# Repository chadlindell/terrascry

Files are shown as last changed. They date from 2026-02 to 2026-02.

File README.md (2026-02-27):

# TERRASCRY

**Multi-sensor geophysical survey platform** (*terra* + *scry* — "seeing what the earth hides")

TERRASCRY unifies three open-source geophysical instruments into a single platform for rapid site characterization: walk a field with Pathfinder, flag anomalies, deploy HIRT for 3D imaging, and validate with GeoSim physics simulations.

## Instruments

### Pathfinder — Handheld Multi-Sensor Gradiometer

Rapid reconnaissance instrument carried by a single operator. Seven sensor modalities in one pass: magnetic gradiometry (8x FG-3+ fluxgates), frequency-domain EMI conductivity, RTK GPS (ZED-F9P), 9-axis IMU (BNO055), IR thermal mapping, LiDAR micro-topography, and georeferenced camera. Covers >3,000 m²/hour at walking speed.

- **Path:** [`pathfinder/`](pathfinder/)
- **Firmware:** ESP32 + PlatformIO
- **BOM:** $1,052-1,262 **(Target)**

### HIRT — Crosshole Subsurface Tomography

Detailed 3D imaging of specific targets flagged by Pathfinder. Dual-channel system: MIT-3D (magnetic induction tomography, 2-50 kHz) for metal detection including aluminum, and ERT-Lite (electrical resistivity) for soil disturbance mapping. Probes inserted into boreholes for true crosshole geometry.

- **Path:** [`hirt/`](hirt/)
- **Documentation:** Quarto technical manual (30 sections)
- **BOM:** <$4,000 **(Target)**

### GeoSim — Physics Simulation Engine

Physics-realistic simulation engine for both instruments. Magnetic dipole forward modeling, FDEM analytical, ERT stubs, noise models, and a real-time MQTT streaming pipeline. Physics accuracy is non-negotiable. Includes Godot 4 interactive visualization frontend and ZeroMQ server for external clients.

- **Path:** [`geosim/`](geosim/)
- **Language:** Python 3.10+
- **Visualization:** PyVista + Godot 4

### Shared Components

Cross-instrument libraries, protocols, and hardware designs shared between Pathfinder and HIRT.

- **Path:** [`shared/`](shared/)
- **Contents:** Sensor pod firmware/hardware, MQTT protocol definitions, CSV schemas, edge deployment configs, field workflow documentation

## Architecture

```
Pathfinder (surface survey, 10 Hz)
     │ MQTT over WiFi
     ▼
NVIDIA Jetson (edge compute)  ◄── HIRT (crosshole, per-sequence)
     │ tilt correction, anomaly detection, data logging
     ▼
Workstation / HPC
     │ SimPEG joint inversion (magnetics + EMI + MIT + ERT)
     ▼
3D multi-physics subsurface model
```

**Shared sensor pod** (ZED-F9P + BNO055 + BMP390 + DS3231) moves between instruments, ensuring both operate in the same coordinate frame — no coordinate transformation errors.

**Joint inversion:** Pathfinder surface data provides boundary conditions for HIRT 3D inversion via cross-gradient regularization (Gallardo & Meju 2003).

## Quick Start

```bash
# Pathfinder firmware
cd pathfinder/firmware && pio run -e esp32dev

# HIRT documentation
cd hirt/docs && quarto render

# GeoSim simulation
cd geosim && pip install -e ".[dev]" && pytest tests/
```

## Licenses

- **Software/Firmware:** [MIT License](LICENSE-SOFTWARE.md)
- **Hardware Designs:** [CERN-OHL-S v2.0](LICENSE-HARDWARE.md)

## Repository Structure

```
terrascry/
├── pathfinder/          # Handheld multi-sensor gradiometer
├── hirt/                # Crosshole subsurface tomography
├── geosim/              # Physics simulation engine
├── shared/              # Cross-instrument shared components
│   ├── firmware/        # Sensor pod, MQTT, SD logger libraries
│   ├── protocols/       # MQTT topics, CSV schemas
│   ├── hardware/        # Sensor pod schematics, BOM, connectors
│   ├── edge/            # Jetson Docker deployment
│   └── workflow/        # Field handoff procedures
└── .github/workflows/   # Path-filtered CI/CD
```

## Links

- **Domain:** [terrascry.com](https://terrascry.com)
- **GitHub:** [chadlindell/terrascry](https://github.com/chadlindell/terrascry)

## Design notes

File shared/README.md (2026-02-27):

# TERRASCRY Shared Components

Cross-instrument libraries, protocols, hardware designs, and deployment configurations shared between Pathfinder and HIRT.

## Directory Structure

```
shared/
├── firmware/
│   ├── sensor_pod/     # I2C drivers for ZED-F9P, BNO055, BMP390, DS3231
│   ├── mqtt/           # MQTT client helpers, message schemas
│   └── sd_logger/      # Common SD card CSV logging
├── protocols/
│   ├── mqtt_topics.md  # Topic hierarchy: terrascry/{instrument}/{channel}
│   ├── csv_schemas.md  # Shared CSV column definitions
│   └── protobuf/       # Binary message definitions (future)
├── hardware/
│   ├── sensor_pod/     # Pod schematics, BOM, PCB files
│   └── connectors/     # M8 8-pin connector specs, pinouts
├── edge/
│   ├── docker-compose.yml  # Jetson edge deployment
│   ├── mosquitto.conf      # MQTT broker config
│   └── containers/         # Per-instrument processing containers
└── workflow/
    └── field_handoff.md    # Pathfinder → HIRT handoff procedure
```

## Sensor Pod

The sensor pod is the key shared hardware between Pathfinder and HIRT. It contains positioning and environmental sensors in an IP67 enclosure:

| Sensor | I2C Address | Function |
|---|---|---|
| ZED-F9P | 0x42 | RTK GPS (cm-accuracy positioning) |
| BNO055 | 0x29 | 9-axis IMU (orientation, tilt correction) |
| BMP390 | 0x77 | Barometric pressure (altitude) |
| DS3231 | 0x68 | Real-time clock (timestamp sync) |

**Connection:** M8 8-pin connector → PCA9615 differential I2C → Cat5 STP cable (1-2m) → instrument I2C Bus 1.

Both instruments use the same GPS receiver, eliminating coordinate transformation errors and enabling seamless data fusion in joint inversion.

## PlatformIO Integration

Both Pathfinder and HIRT firmware projects reference shared libraries:

```ini
# In pathfinder/firmware/platformio.ini or hirt/firmware/platformio.ini
lib_extra_dirs = ../../shared/firmware
```

## MQTT Topic Hierarchy

All instruments publish under `terrascry/`:

```
terrascry/pathfinder/data/raw          — 10 Hz raw sensor data
terrascry/pathfinder/data/corrected    — Tilt-corrected readings
terrascry/pathfinder/anomaly/detected  — Anomaly alerts
terrascry/hirt/data/mit/raw            — MIT measurements
terrascry/hirt/data/ert/raw            — ERT measurements
terrascry/hirt/model/update            — Inversion results
terrascry/status/{instrument}          — Health heartbeat (1 Hz)
```

See `protocols/mqtt_topics.md` for full specification.

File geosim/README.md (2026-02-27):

# GeoSim

Physics-realistic geophysical simulation engine for [HIRT](../HIRT/) (subsurface tomography) and [Pathfinder](../Pathfinder/) (magnetic gradiometry) instruments.

## Quick Start

```bash
# Install
python3 -m venv .venv
source .venv/bin/activate
pip install -e ".[dev]"

# Run tests
pytest tests/

# Run ZeroMQ server
geosim-server --scenario scenarios/single-ferrous-target.json
```

## What It Does

GeoSim simulates the complete data acquisition pipeline:

1. **Define a scenario** (JSON): terrain, buried objects, soil properties
2. **Run the physics engine**: magnetic dipole fields, EM induction, resistivity
3. **Simulate an instrument**: walk path, sensor geometry, noise
4. **Export sensor data**: CSV files matching real firmware formats

The exported CSV files can be loaded directly by existing tools like Pathfinder's `visualize_data.py`.

## Project Structure

```
geosim/              # Python physics engine
├── magnetics/       # Dipole models, gradiometer simulation
├── em/              # EM induction forward modeling (Phase 2)
├── resistivity/     # ERT forward modeling (Phase 2)
├── sensors/         # Instrument models (Pathfinder, HIRT)
├── scenarios/       # Scenario loader
├── noise/           # Realistic noise models
└── server.py        # ZeroMQ server for external clients

scenarios/           # JSON scenario files
notebooks/           # Jupyter notebooks (education + validation)
tests/               # Physics validation tests
godot/               # Godot 4 interactive frontend (Phase 3)
```

## Dependencies

**Core (Phase 1):** numpy, scipy, pyzmq

**Visualization:** pyvista, jupyter, matplotlib

**HIRT Physics (Phase 2):** SimPEG, pyGIMLi

## License

MIT

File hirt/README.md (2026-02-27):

# HIRT - Hybrid Inductive-Resistivity Tomography

A dual-channel subsurface imaging system combining electromagnetic induction (MIT-3D) and electrical resistivity (ERT-Lite) for true 3D tomographic imaging in archaeological and forensic investigations.

## What is HIRT?

HIRT uses insertable probes in crosshole geometry to image the subsurface with two complementary methods:

- **MIT-3D** (Magneto-Inductive Tomography): Detects metallic objects including aluminum at depths to 3m
- **ERT-Lite** (Electrical Resistivity): Maps soil disturbance patterns indicating burial or excavation

## Key Features

| Feature | Specification |
|---|---|
| Depth | 2-6 m investigation depth |
| Resolution | 0.5-1.5 m lateral resolution |
| Cost | $1,800-3,900 complete system |
| Probes | 16-24 modular 16mm OD probes |
| Output | 3D conductivity and resistivity models |

## Primary Applications

- Filled bomb crater investigation (UXO, human remains)
- Woodland burial detection (clandestine graves)
- Swamp/marsh crash site recovery

## Getting Started

### Read the Technical Manual
```bash
cd docs && quarto preview
```
The Technical Manual is the single source of truth for all technical documentation.

### Quick Links

| Resource | Location |
|---|---|
| Technical Manual | `docs/` |
| Bill of Materials | `hardware/bom/` |
| CAD Files (OpenSCAD) | `hardware/cad/` |
| Circuit Schematics | `hardware/schematics/` |
| Research Documents | `research/` |

## Project Structure

```
HIRT/
├── VISION.md          # Project goals and constraints
├── STATUS.md          # Current state and active work
├── OUTLINE.md         # Documentation section status
├── CLAUDE.md          # Style guide for documentation
│
├── docs/              # Technical Manual (Quarto)
│   ├── index.qmd              # Task map landing page
│   ├── getting-started/       # Onboarding (overview, quick-start, safety)
│   ├── field-guide/           # Operations (deployment, data, troubleshooting)
│   ├── build-guide/           # Construction (BOM, mechanical, electronics)
│   ├── theory/                # Technical depth (physics, inversion, sensors)
│   ├── developer/             # Contributors (firmware, data-formats, roadmap)
│   ├── appendices/            # Reference (glossary, checklists, regulations)
│   └── diagrams/              # Python diagram generators
│
├── research/          # Research by topic
│   ├── deployment/    # Probe insertion methods
│   ├── electronics/   # Modernization research
│   ├── regulatory/    # Legal/compliance
│   └── literature/    # Prior art and comparable projects
│
├── hardware/          # Hardware documentation
│   ├── bom/          # Bills of materials
│   ├── cad/          # OpenSCAD sources and STLs
│   ├── drawings/     # Assembly drawings
│   └── schematics/   # Circuit documentation
│
└── _archive/          # Legacy files (preserved)
```

## Building the Documentation

Requires [Quarto](https://quarto.org/) and Python 3.

```bash
# Install Python dependencies
pip install matplotlib numpy pillow

# Render Technical Manual to HTML and PDF
cd docs && quarto render

# Preview with live reload
cd docs && quarto preview

# Render HTML only
cd docs && quarto render --to html

# Render PDF only
cd docs && quarto render --to pdf
```

## Warnings

**UXO Risk:** WWII sites may contain live ordnance. Do not deploy until cleared by qualified EOD/UXO professionals.

**Legal Requirements:** Obtain all permits and permissions. Follow jurisdictional requirements for archaeological and forensic work.

**Human Remains:** Follow proper forensic/archaeological protocols when remains may be present.

## Project Status

| Component | Status |
|---|---|
| Technical Manual | Complete (30 sections, HTML + PDF) |
| Hardware Design | Complete (schematics, CAD, BOM) |
| Research | Ongoing (see `research/`) |
| Software | Future development |

## License

Open source - license to be determined.

## Contributing

Contributions, improvements, and field testing results are welcome. See `docs/developer/contributing.qmd` for contribution guidelines and `CLAUDE.md` for documentation style guide.

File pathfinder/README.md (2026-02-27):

# Pathfinder

**Handheld multi-sensor fluxgate gradiometer for rapid geophysical reconnaissance**

Pathfinder is an open-source, harness-supported magnetic gradiometer array designed for rapid pre-screening of survey areas before detailed investigation. Named for the WWII pathfinder aircraft that marked targets for following bomber formations, this tool identifies anomalies so that detailed systems like [HIRT](https://github.com/hirt-project/hirt) can be deployed efficiently.

## Purpose

Walking a site with Pathfinder in 5-10 minutes can identify magnetic anomalies that would take hours to find with detailed tomographic methods. This two-stage workflow (rapid screening → targeted investigation) dramatically reduces total survey time.

## Key Features

- **Harness-supported**: Weight carried on shoulders, hands only guide
- **Multi-channel**: 2-4 gradiometer pairs for wide swath coverage
- **Lightweight**: Target <1.5 kg total system weight
- **GPS-tagged**: Automatic position logging for anomaly mapping
- **Open hardware**: Full schematics, BOM, and firmware available
- **DIY-friendly**: ~$600-900 total build cost

## Applications

- Archaeological site reconnaissance
- UXO survey pre-screening
- Forensic search area prioritization
- Environmental assessment
- Geological mapping

## Status

**Early development** - Design phase, capturing requirements and prototyping.

## Related Projects

- [HIRT](https://github.com/hirt-project/hirt) - Hybrid Inductive-Resistivity Tomography (detailed follow-up imaging)
- [OhmPi](https://ohmpi.org/) - Open-source resistivity meter
- [FG Sensors](https://www.fgsensors.com/) - DIY fluxgate gradiometer kits

## Historical Note

The name "Pathfinder" honors the 15th Air Force crews who flew missions over Blechhammer (now Blachownia, Poland) during WWII. Pathfinder aircraft marked targets for the bomber formations that followed. This tool serves a similar purpose: marking targets for the detailed investigation systems that follow.

## License

Hardware: [CERN-OHL-S v2.0](https://ohwr.org/cern_ohl_s_v2.txt) | Firmware/Software: [MIT](LICENSE)

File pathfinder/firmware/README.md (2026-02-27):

# Pathfinder Gradiometer Firmware

Arduino firmware for the Pathfinder 4-pair fluxgate gradiometer system.

## Overview

This firmware runs on an Arduino Nano and manages:
- 8 fluxgate sensors (4 pairs) via 2x ADS1115 ADCs
- GPS positioning via NEO-6M module
- SD card data logging
- Pace beeper for walking cadence
- Status LED for system health

## Hardware Requirements

### Electronics
- **Microcontroller**: Arduino Nano (ATmega328P)
- **ADCs**: 2x ADS1115 16-bit I2C modules
- **GPS**: NEO-6M or compatible UART GPS module
- **Storage**: SD card module (SPI interface)
- **Audio**: Piezo buzzer or small speaker
- **Power**: 7.4V LiPo battery with 5V regulator for Arduino

### Sensors
- 8x Fluxgate sensors (e.g., FG Sensors DIY kit)
- Configured as 4 gradiometer pairs (top/bottom)

## Pin Connections

### Arduino Nano Pin Assignments

| Pin | Function | Connection |
|-----|---|---|
| **I2C Bus** |
| A4 | SDA | ADS1115 modules (both) |
| A5 | SCL | ADS1115 modules (both) |
| **SPI Bus (SD Card)** |
| 10 | CS | SD card module CS |
| 11 | MOSI | SD card module DI |
| 12 | MISO | SD card module DO |
| 13 | SCK | SD card module CLK |
| **GPS (Software Serial)** |
| 4 | RX | GPS TX pin |
| 3 | TX | GPS RX pin (not used) |
| **User Interface** |
| 9 | Beeper | Piezo buzzer (+) |
| 2 | Status LED | LED anode (+ resistor) |
| GND | Ground | Common ground for all modules |
| 5V | Power | Power for GPS, SD card, ADCs |

### ADS1115 ADC Connections

**Module 1 (Address 0x48)**: Gradiometer Pairs 1 and 2

| Channel | Sensor Connection |
|---|---|
| A0 | Pair 1 Top sensor output |
| A1 | Pair 1 Bottom sensor output |
| A2 | Pair 2 Top sensor output |
| A3 | Pair 2 Bottom sensor output |

**Module 2 (Address 0x49)**: Gradiometer Pairs 3 and 4

| Channel | Sensor Connection |
|---|---|
| A0 | Pair 3 Top sensor output |
| A1 | Pair 3 Bottom sensor output |
| A2 | Pair 4 Top sensor output |
| A3 | Pair 4 Bottom sensor output |

**I2C Address Configuration:**
- Module 1: Connect ADDR pin to GND (address 0x48)
- Module 2: Connect ADDR pin to VDD (address 0x49)

## Building and Uploading

### Prerequisites

1. **Install PlatformIO**
   - [Visual Studio Code](https://code.visualstudio.com/) with PlatformIO extension, OR
   - [PlatformIO Core CLI](https://docs.platformio.org/en/latest/core/installation.html)

2. **Required Libraries** (auto-installed by PlatformIO):
   - `Adafruit ADS1X15` - ADS1115 ADC driver
   - `TinyGPSPlus` - GPS NMEA parsing
   - `SdFat` - Fast SD card library

### Build and Upload

#### Using VS Code + PlatformIO Extension

1. Open the `firmware/` folder in VS Code
2. PlatformIO will detect the project automatically
3. Click the "Upload" button (→) in the bottom toolbar
4. Monitor serial output with the "Serial Monitor" button

#### Using PlatformIO CLI

```bash
# Navigate to firmware directory
cd /development/projects/active/Pathfinder/firmware/

# Build firmware
pio run

# Upload to Arduino Nano
pio run --target upload

# Open serial monitor
pio device monitor
```

### First-Time Upload

If upload fails with "programmer not responding":
1. Check USB connection
2. Verify correct port in `platformio.ini` (update `upload_port`)
3. Try holding RESET button while uploading
4. Some clones need `upload_speed = 57600` instead of 115200

## Configuration

All user-configurable parameters are in `include/config.h`:

### Key Settings

```cpp
// Sample rate (Hz)
#define SAMPLE_RATE_HZ  10      // Change to 20 for faster acquisition

// Pace beeper interval (ms)
#define BEEP_INTERVAL_MS 1000   // 1 beep per second = 1 m/s pace

// GPS baud rate
#define GPS_BAUD 9600           // NEO-6M default

// ADC gain setting
#define ADC_GAIN GAIN_ONE       // +/- 4.096V range

// Enable debug output
#define SERIAL_DEBUG 1          // Set to 0 to disable for battery savings
```

Edit these values and re-upload to customize behavior.

## Operation

### Startup Sequence

1. Power on system
2. **Status LED blinks rapidly** during initialization
3. Two quick beeps indicate startup complete
4. **Status LED pattern** indicates system state:
   - **Fast blink (100ms)**: Error (SD card failure)
   - **Medium blink (500ms)**: No GPS fix
   - **Slow blink (2s)**: Logging normally

### In the Field

1. Wait for **slow blink** (GPS locked)
2. Walk at steady pace (1 beep per second ≈ 1 m/s)
3. Maintain level orientation
4. Data logs automatically to SD card as `PATHXXXX.CSV`

### Data Retrieval

1. Power off system
2. Remove SD card
3. Copy CSV files to computer
4. Files increment automatically: `PATH0001.CSV`, `PATH0002.CSV`, etc.

## Data Format

### CSV Structure

```csv
timestamp,lat,lon,g1_top,g1_bot,g1_grad,g2_top,g2_bot,g2_grad,g3_top,g3_bot,g3_grad,g4_top,g4_bot,g4_grad
1234567,51.2345678,18.3456789,12450,12678,228,12401,12623,222,12389,12598,209,12434,12656,222
```

### Column Definitions

- **timestamp**: Milliseconds since Arduino boot
- **lat/lon**: GPS coordinates (decimal degrees, WGS84)
- **gN_top**: Top sensor raw ADC value (16-bit signed)
- **gN_bot**: Bottom sensor raw ADC value
- **gN_grad**: Gradient (bottom - top)

### Converting to Physical Units

Raw ADC values → Voltage:
```
voltage = (ADC_value / 32768) × 4.096V
```

Voltage → Magnetic field depends on your fluxgate sensor specifications.
Consult sensor datasheet for mV/µT conversion factor.

## Troubleshooting

### No SD Card Detected

- Check wiring to SD module (SPI pins)
- Verify SD card is formatted as FAT32
- Ensure CS pin is correct (`SD_CS_PIN = 10`)
- Try different SD card (some old cards not compatible)

### GPS Not Locking

- Ensure clear view of sky (no metal/trees blocking)
- Wait 30-60 seconds for cold start
- Check GPS RX pin connection (Arduino D4 → GPS TX)
- Verify GPS baud rate (default 9600)

### ADS1115 Not Found

- Check I2C wiring (SDA=A4, SCL=A5)
- Verify I2C addresses:
  - Module 1: ADDR pin → GND (0x48)
  - Module 2: ADDR pin → VDD (0x49)
- Run I2C scanner to detect devices
- Ensure 5V power to ADS1115

### Erratic Readings

- Check sensor power supply stability
- Ensure proper grounding (all grounds connected)
- Move sensors away from electronics noise
- Shield cables with grounded braid
- Lower ADC data rate for less noise (`ADC_DATA_RATE = 64`)

### Serial Monitor Shows Garbage

- Set baud rate to 115200 in monitor
- Check `SERIAL_BAUD` in `config.h` matches monitor

## Advanced Modifications

### Adding Calibration

Insert calibration coefficients in `readGradiometers()`:

```cpp
// After reading raw values
reading.g1_top = (reading.g1_top - offset1_top) * scale1_top;
reading.g1_bot = (reading.g1_bot - offset1_bot) * scale1_bot;
```

### Changing Sample Rate Dynamically

Add button to cycle through rates:

```cpp
const uint8_t rates[] = {10, 20, 50};
uint8_t currentRate = 0;

// In button interrupt:
currentRate = (currentRate + 1) % 3;
SAMPLE_RATE_HZ = rates[currentRate];
```

### Adding Real-Time Clock

Replace `millis()` timestamps with DS3231 RTC for absolute time:

```cpp
#include <RTClib.h>
RTC_DS3231 rtc;

// In setup():
rtc.begin();

// In logReading():
DateTime now = rtc.now();
logFile.print(now.timestamp());
```

## Performance Notes

### Memory Usage

- **Flash**: ~18 KB / 32 KB (56% used)
- **RAM**: ~1.2 KB / 2 KB (60% used)

Remaining RAM is tight. Avoid large arrays or String objects.

### Sample Rate Limits

- **10 Hz**: Rock solid, recommended
- **20 Hz**: Stable for most sensors
- **50 Hz**: Maximum practical (depends on ADC data rate)

Higher rates reduce per-sample noise averaging. Balance speed vs. quality.

### Battery Life Estimate

At 10 Hz sample rate (Modeled, MCU + peripherals only — excludes fluxgate sensors):
- Arduino Nano: ~60 mA
- ADS1115 (2x): ~2 mA
- GPS module: ~40 mA
- SD writes: ~20 mA average
- **MCU + peripherals**: ~120 mA
- **Full system with 8 fluxgates**: ~305 mA typical (see `hardware/schematics/main-board.md`)

With 2000 mAh LiPo @ 7.4V (80% regulator efficiency):
- MCU + peripherals only: ~13 hours
- Full system: ~5.2 hours

## License

MIT License. See [LICENSE](../LICENSE) in the project root.

## Contributing

Improvements welcome! Please document changes and test thoroughly before submitting.

## References

- [ADS1115 Datasheet](https://www.ti.com/lit/ds/symlink/ads1115.pdf)
- [NEO-6M GPS Manual](https://www.u-blox.com/sites/default/files/products/documents/NEO-6_DataSheet_(GPS.G6-HW-09005).pdf)
- [TinyGPS++ Documentation](http://arduiniana.org/libraries/tinygpsplus/)
- [SdFat Library](https://github.com/greiman/SdFat)

## Support

For hardware questions, see `/hardware/` directory.
For design rationale, see `/docs/design-concept.md`.

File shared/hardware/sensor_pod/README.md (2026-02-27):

# Shared Sensor Pod — Hardware Specification

The sensor pod is the primary shared hardware between Pathfinder and HIRT. It provides positioning, orientation, and environmental sensing in a ruggedized enclosure.

## Sensors

| Component | I2C Address | Function | Current Draw |
|---|---|---|---|
| u-blox ZED-F9P | 0x42 | RTK GPS (cm-accuracy) | ~70 mA (tracking) |
| Bosch BNO055 | 0x29 | 9-axis IMU (IMUPLUS mode) | ~12 mA |
| Bosch BMP390 | 0x77 | Barometric pressure + temperature | ~3 mA |
| Maxim DS3231 | 0x68 | Temperature-compensated RTC | ~0.2 mA |
| **Total** | | | **~85 mA typical** |

Peak draw (GPS acquisition): ~150-200 mA.

## Enclosure

- **Type:** IP67 ABS enclosure, approximately 60 x 60 x 25 mm
- **Connector:** M8 8-pin panel-mount (NOT 4-pin — PCA9615 requires 6 conductors minimum)
- **Antenna:** SMA panel-mount for external GPS antenna (patch or helix)
- **Vent:** IP67 membrane vent for BMP390 barometric accuracy

## M8 8-Pin Connector Pinout

| Pin | Signal | Color (Cat5) | Description |
|-----|---|---|---|
| 1 | VCC | Orange/White | 3.3V supply |
| 2 | GND | Orange | Ground |
| 3 | SDA_D+ | Green/White | PCA9615 differential SDA+ |
| 4 | SDA_D- | Green | PCA9615 differential SDA- |
| 5 | SCL_D+ | Blue/White | PCA9615 differential SCL+ |
| 6 | SCL_D- | Blue | PCA9615 differential SCL- |
| 7 | VBUS | Brown/White | 5V input (before pod's 3.3V LDO) |
| 8 | SHIELD | Brown | Cable shield / drain wire |

## PCA9615 Differential I2C

The PCA9615 converts standard I2C to differential signaling for reliable communication over 1-2m Cat5 STP cable. This eliminates I2C bus capacitance and noise issues at cable lengths beyond ~30 cm.

**Critical:** Both the pod side and instrument side need a PCA9615. The instrument-side PCA9615 connects to ESP32 I2C Bus 1 (GPIO 16 SDA, GPIO 17 SCL).

## ESD Protection

- TVS diodes (PESD5V0S2BT) on all I2C lines at the M8 connector
- ESD protection is critical for hot-plug scenarios (pod moved between instruments during field use)

## Power Architecture

- Input: 5V via VBUS (pin 7) from instrument
- LDO: AP2112K-3.3 (NOT LM78L05 — no 5V→3.3V dropout issue at this voltage)
- All sensors operate at 3.3V
- Cable voltage drop: ~0.05V at 200 mA over 2m Cat5 (negligible at 5V input)

## PCB Design Notes

- 4-layer PCB recommended (signal, ground, power, signal)
- ZED-F9P placed closest to SMA connector, ground plane unbroken beneath RF traces
- BNO055 placed away from GPS and PCA9615 (magnetic interference)
- Keep PCA9615 within 5 cm of M8 connector
- IP67 vent membrane directly above BMP390

See `pathfinder/research/multi-sensor-architecture/sensor-pod-pcb-requirements.md` for full consensus-validated PCB design requirements.

## BOM

| Component | Part Number | Qty | Est. Cost |
|---|---|-----|---|
| ZED-F9P RTK GPS module | u-blox ZED-F9P | 1 | $180 |
| BNO055 9-axis IMU | Bosch BNO055 | 1 | $10 |
| BMP390 barometer | Bosch BMP390 | 1 | $5 |
| DS3231 RTC | Maxim DS3231SN | 1 | $8 |
| PCA9615 diff I2C (pod side) | NXP PCA9615 | 1 | $3 |
| PCA9615 diff I2C (instrument side) | NXP PCA9615 | 1 | $3 |
| AP2112K-3.3 LDO | Diodes Inc | 1 | $0.50 |
| PESD5V0S2BT TVS diodes | Nexperia | 2 | $1 |
| TPD4E05U06 ESD protection | TI | 1 | $0.50 |
| M8 8-pin connector (panel) | Various | 1 | $8 |
| M8 8-pin connector (cable) | Various | 1 | $6 |
| Cat5 STP cable (2m) | Various | 1 | $3 |
| IP67 ABS enclosure | Hammond 1554B | 1 | $12 |
| IP67 vent membrane | Amphenol | 1 | $3 |
| SMA panel-mount connector | Various | 1 | $3 |
| GPS antenna (patch or helix) | Various | 1 | $30 |
| 4-layer PCB | JLCPCB | 1 | $15 |
| Passive components | Various | — | $5 |
| **Total** | | | **~$296** |

## Design References

- Sensor pod design: `pathfinder/research/multi-sensor-architecture/sensor-pod-design.md`
- PCB requirements: `pathfinder/research/multi-sensor-architecture/sensor-pod-pcb-requirements.md`
- Firmware consensus: `pathfinder/research/multi-sensor-architecture/sensor-pod-firmware-consensus.md`
- HIRT integration: `hirt/research/electronics/sensor-pod-integration.md`
- HIRT consensus: `hirt/research/electronics/sensor-pod-consensus.md`

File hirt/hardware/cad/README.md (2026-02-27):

# CAD Files for HIRT Micro-Probe System

## Overview

This directory contains CAD files for manufacturing HIRT **micro-probe** components (12mm OD design). Files are provided in multiple formats for different manufacturing methods:

**Design Philosophy:** Minimal intrusion, archaeology-friendly. Rod diameter: 10-16mm (target: 12mm).

- **OpenSCAD** (`.scad`) - Parametric CAD source files
- **STL** (`.stl`) - 3D printing format
- **STEP** (`.step`) - CNC machining format (to be exported from OpenSCAD)
- **Docs** (`docs/`) - Manufacturing guides, including `base-hub-breakout.md` for the centralized harness/backplane

## Directory Structure

```
cad/
├── openscad/          # OpenSCAD source files (.scad)
├── stl/              # 3D printable STL files
├── step/             # CNC-ready STEP files
└── docs/             # Manufacturing documentation
```

## Parts Available

### 1. Probe Tip (Nose Cone) - BOTTOM
- **File:** `openscad/micro_probe_tip.scad`
- **Output:** `stl/micro_probe_tip.stl`
- **Manufacturing:** 3D Print (PETG) or CNC (Delrin)
- **Dimensions:** 25mm long, 12mm base, 4mm point
- **Threading:** Internal M12×1.5 (screws onto rod bottom)
- **Features:** Tapered for easy insertion, points DOWN
- **Assembly:** Screws onto rod bottom (external M12×1.5 thread)

### 2. Micro-Rod Coupler - MIDDLE
- **File:** `openscad/micro_rod_coupler.scad`
- **Output:** `stl/micro_rod_coupler.stl`
- **Manufacturing:** CNC (Nylon/Delrin) preferred, or 3D Print + tap
- **Dimensions:** 45mm long × 18mm OD
- **Threading:** Internal M12×1.5 both ends (screws onto rod sections)
- **Features:** O-ring grooves, smooth center for grip
- **Assembly:** Joins rod sections (modular design)

### 3. ERT Ring Collar - MIDDLE
- **File:** `openscad/micro_ert_ring_collar.scad`
- **Output:** `stl/micro_ert_ring_collar.stl`
- **Manufacturing:** 3D Print (PETG)
- **Dimensions:** 5mm wide × 12mm ID
- **Threading:** None (slides onto rod, bonds with epoxy)
- **Features:** Narrow band for 3-5mm ERT rings, wire channel
- **Assembly:** Slides onto rod at 0.5m, 1.5m, 2.5m positions

### 4. Surface Junction Box - TOP
- **File:** `openscad/micro_probe_head.scad`
- **Output:** `stl/micro_probe_head.stl`
- **Manufacturing:** 3D Print (PETG) preferred
- **Dimensions:** Ø25mm × 35mm
- **Threading:** Internal M12×1.5 (screws onto rod top)
- **Features:** Terminal block mount, cable strain relief, weatherproof
- **Assembly:** Screws onto rod TOP (surface, not inserted)
- **Note:** Electronics stay at surface, probe is passive

### 5. Complete Assembly View
- **File:** `openscad/micro_probe_assembly.scad`
- **Purpose:** Visualization of complete modular assembly
- **Note:** Export individual parts separately for manufacturing

### Legacy Parts (25mm Design - Deprecated)
- `probe_head.scad` - Old 30mm design (not recommended)
- `rod_coupler.scad` - Old 30mm design (not recommended)
- `ert_ring_collar.scad` - Old design (not recommended)

## Manufacturing Methods

### 3D Printing

**Recommended Settings:**
- **Layer Height:** 0.2 mm for structural parts (0.15 mm for threaded features)
- **Infill:** 100% solid infill (critical for skinny load-bearing parts)
- **Wall Count:** 3-4 perimeters
- **Support:** Minimal (parts designed to print without supports)
- **Material:** PETG (preferred) or ABS
- **Bed Adhesion:** 6-10 mm brim or small sacrificial raft + glue stick/hairspray on PEI
- **Stabilization:** Enable Z-hop and slow first layers (15-20 mm/s) so tall slender sections stay anchored

**Post-Processing:**
- Remove support material
- Clean threads with tap if needed
- Test fit before final assembly
- Flood threads/tips with thin epoxy if additional abrasion resistance is needed

See `docs/manufacturing-notes.md` for part-by-part print/tap/epoxy instructions tailored to home printers.

### CNC Machining

**For couplers and precision parts:**
- Export STEP files from OpenSCAD
- Use CAM software to generate toolpaths
- Material: Nylon, Delrin, or aluminum
- Threads: Cut with appropriate tap/die

## Using OpenSCAD Files

1. **Install OpenSCAD:**
   - Download from: https://openscad.org/
   - Available for Windows, Mac, Linux

2. **Open File:**
   - Launch OpenSCAD
   - Open `.scad` file from `openscad/` directory

3. **Customize (if needed):**
   - Adjust parameters at top of file
   - Modify dimensions as needed

4. **Render:**
   - Press F5 (Preview) or F6 (Render)
   - Wait for rendering to complete

5. **Export:**
   - **STL:** File → Export → Export as STL
   - **STEP:** Requires additional plugin or FreeCAD conversion

## Converting to STEP (for CNC)

### Method 1: Using FreeCAD
1. Open FreeCAD
2. Import STL file
3. Convert mesh to solid
4. Export as STEP

### Method 2: Using OpenSCAD with STEP export plugin
1. Install STEP export plugin
2. Use `export_stl()` or export menu

## Dummy Prototype Parts

For testing and prototyping, simplified versions are available:
- `probe_head_dummy.scad` - Simplified probe head for fit testing
- `coupler_dummy.scad` - Basic coupler for thread testing

## Thread Specifications

**All Threads: M12×1.5 Metric**
- **Type:** Standard metric thread (M12×1.5)
- **Pitch:** 1.5mm
- **Engagement:** 12-15mm
- **Rod:** External threads on both ends (cut with M12×1.5 die)
- **Tip:** Internal thread (tapped M12×1.5)
- **Junction Box:** Internal thread (tapped M12×1.5)
- **Coupler:** Internal threads both ends (tapped M12×1.5)

**Note:** Threads must be precise for reliable connection. Use appropriate taps/dies. Test fit before production.

## Quality Control

Before using manufactured parts:
- [ ] Verify dimensions with calipers
- [ ] Test thread fit with actual rod
- [ ] Check O-ring groove dimensions
- [ ] Verify wall thickness
- [ ] Test waterproofing (for probe head)

## Modular Assembly

**Assembly Order (bottom to top):**
1. **Tip** - Screws onto rod bottom (pointing down for insertion)
2. **Rod Section 1** - 1.5m section with external threads
3. **ERT Collar + Ring** - Slides onto rod at 0.5m position
4. **Coupler** - Screws onto rod sections (if multi-section)
5. **Rod Section 2** - Additional 1.5m section
6. **ERT Collar + Ring** - At 1.5m from tip
7. **Junction Box** - Screws onto rod top (at surface)

**Key Points:**
- All parts screw together (modular design)
- Tip points DOWN for insertion
- Junction box at TOP (surface, not inserted)
- Rod sections join with couplers
- ERT collars slide on and bond with epoxy

## Manufacturing Methods

See [Manufacturing Notes](docs/manufacturing-notes.md) for detailed recommendations:
- **Tip:** 3D Print (PETG) or CNC (Delrin)
- **Coupler:** CNC (Nylon) preferred for precision threads
- **Junction Box:** 3D Print (PETG) for weatherproof enclosure
- **ERT Collar:** 3D Print (PETG) - simple part

## Notes

- All dimensions are in millimeters
- Threads are simplified in models - use taps/dies for actual threads
- Rod requires external M12×1.5 threads on both ends
- All threaded connections should use thread sealant
- Test print small parts first before full production
- See manufacturing notes for method recommendations

## Support

For issues or questions:
- Check OpenSCAD file comments for parameter descriptions
- Review manufacturing documentation in `docs/` directory
- Test with dummy parts first

---

*Last Updated: 2024-12-19*

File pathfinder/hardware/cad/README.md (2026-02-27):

# Pathfinder CAD Files

3D models and rendering tools for the Pathfinder gradiometer frame and harness system.

## Directory Structure

```
cad/
├── openscad/
│   └── pathfinder_frame.scad    # Parametric 3D model
├── scripts/
│   └── render_views.sh          # Batch PNG rendering
├── stl/                         # Generated STL files
└── frame-design.md              # Design specifications
```

## OpenSCAD Model

The parametric model in `openscad/pathfinder_frame.scad` includes:

- Carbon fiber crossbar (2000mm x 25mm)
- 4 PVC drop tubes (500mm x 21.3mm)
- 8 FG-3+ fluxgate sensors (4 pairs)
- Center mount D-ring for harness attachment

### Render Modes

Set the `part` variable to select a view:

| Mode | Description |
|---|---|
| `assembled` | Complete trapeze system |
| `exploded` | Components separated with gaps |
| `cross_section` | Half-section showing tube interiors |
| `deployment` | With operator silhouette for scale |
| `single_tube` | Single sensor pair detail |

### Parametric Variables

Key dimensions can be adjusted:

```scad
CROSSBAR_LENGTH = 2000;        // mm
CROSSBAR_OD = 25;              // mm
DROP_TUBE_LENGTH = 500;        // mm
BOTTOM_SENSOR_HEIGHT = 175;    // mm from ground
SENSOR_POSITIONS = [250, 750, 1250, 1750];  // mm from left
```

## Rendering

### Prerequisites

- OpenSCAD 2021.01+
- `xvfb-run` for headless rendering (Linux)

### Generate PNG Images

```bash
# Render all views
./scripts/render_views.sh all

# Render single view
./scripts/render_views.sh assembled
./scripts/render_views.sh exploded

# Export STL file
./scripts/render_views.sh --stl
```

Output files are saved to `docs/assets/images/assembly/`.

### Manual Rendering

```bash
# Open in OpenSCAD GUI
openscad openscad/pathfinder_frame.scad

# Command-line rendering
openscad -D 'part="assembled"' \
  --imgsize=1200,900 \
  --camera=0,0,0,55,25,25,4000 \
  -o pathfinder_assembled.png \
  openscad/pathfinder_frame.scad
```

## Python Diagrams

Annotated assembly diagrams using matplotlib are in `docs/diagrams/`:

```python
from docs.diagrams.assembly import create_exploded_view

fig = create_exploded_view()
fig.savefig('exploded.png', dpi=150)
```

Or render all diagrams:

```bash
python -m docs.diagrams.assembly
```

## Design Specifications

See `frame-design.md` for complete specifications including:

- Component selection (crossbar, tubes, harness)
- Parts list with costs
- Assembly instructions
- Safety notes

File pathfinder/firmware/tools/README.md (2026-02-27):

# Pathfinder Data Tools

Python utilities for processing and visualizing Pathfinder gradiometer data.

## Installation

Install required Python packages:

```bash
pip install pandas matplotlib
```

Or use the provided requirements file:

```bash
pip install -r requirements.txt
```

## Tools

### visualize_data.py

Quick field visualization of survey data. Useful for checking data quality immediately after collection.

**Basic usage:**

```bash
# View all pairs as time series
python visualize_data.py PATH0001.CSV

# View specific pair
python visualize_data.py PATH0001.CSV --pair 1

# Generate spatial map (requires GPS data)
python visualize_data.py PATH0001.CSV --map

# Show gradient distributions
python visualize_data.py PATH0001.CSV --hist

# Print statistics only (no plots)
python visualize_data.py PATH0001.CSV --stats-only
```

**Example output:**

```
Loaded 1234 samples from PATH0001.CSV

============================================================
PATHFINDER DATA STATISTICS
============================================================

GPS Lock: 1150/1234 samples (93.2%)
  Lat range: 51.234567 to 51.235678
  Lon range: 18.345678 to 18.346789

Gradient Statistics (ADC counts):
Pair     Mean       Std Dev    Min        Max
------------------------------------------------
1        225.3      45.2       -120       850
2        218.7      42.8       -105       780
3        210.5      40.1       -98        720
4        223.1      44.5       -115       810

Survey Duration: 15.2 minutes (912 seconds)
Sample Rate: 10.1 Hz (average)
============================================================
```

## Example Data

The `example_data.csv` file contains synthetic data for testing the visualization tools. Use it to verify your Python environment is set up correctly:

```bash
python visualize_data.py example_data.csv
```

## Custom Processing

For more advanced processing (filtering, calibration, export to GIS formats), see the templates in the `processing/` directory (coming soon).

### Basic Python Processing Example

```python
import pandas as pd

# Load data
df = pd.read_csv('PATH0001.CSV')

# Filter to GPS-locked samples only
df_gps = df[(df['lat'] != 0) & (df['lon'] != 0)]

# Apply calibration offset (example)
df_gps['g1_grad_cal'] = df_gps['g1_grad'] - df_gps['g1_grad'].mean()

# Export to GeoJSON for QGIS
import json
features = []
for _, row in df_gps.iterrows():
    features.append({
        'type': 'Feature',
        'geometry': {
            'type': 'Point',
            'coordinates': [row['lon'], row['lat']]
        },
        'properties': {
            'gradient': row['g1_grad_cal']
        }
    })

with open('survey.geojson', 'w') as f:
    json.dump({'type': 'FeatureCollection', 'features': features}, f)
```

## Contributing

Improvements and additional tools welcome! Submit pull requests or open issues on the project repository.

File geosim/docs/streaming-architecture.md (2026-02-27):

# GeoSim Real-Time Streaming Architecture

## Overview

This document describes the real-time data streaming and continuous analysis
pipeline for HIRT and Pathfinder geophysical instruments. The architecture
enables live sensor data to flow from instruments through edge processing to
cloud-based inversion, with sub-second anomaly detection at the edge.

---

## System Architecture

```
Instrument Hardware          Edge Compute              Cloud / Base Station
+------------------+      +-------------------+      +--------------------+
| Pathfinder       |      | NVIDIA Jetson     |      | Workstation / HPC  |
|  8x FG-3+       |      | AGX Orin 64GB     |      | Full inversion     |
|  EMI coil (FDEM) | WiFi |                   | Star |  SimPEG / pyGIMLi  |
|  ZED-F9P RTK GPS | MQTT | - TDM data ingest | link |  Joint inversion   |
|  BNO055 IMU      |----->| - Tilt correction |----->|  3D model update   |
|  MLX90614 IR     |      | - Anomaly detect  |      |  Visualization     |
|  RPLiDAR C1      | USB  | - MQTT broker     |      +--------------------+
|  ESP32-CAM       |----->| - LiDAR→DEM       |
+------------------+      | - Data logging    |      +--------------------+
                           |                   |      | MQTT Cloud Bridge  |
+------------------+      | Docker containers |      | AWS IoT Core or    |
| HIRT             |      | per instrument    |----->| self-hosted         |
|  MIT transmitter |----->|                   |      +--------------------+
|  ERT electrodes  | SPI  | Shared sensor pod |
|  Inclinometers   |      | provides GPS      |
+------------------+      | registration      |
                           +-------------------+
```

### Data Flow

1. **Pathfinder ESP32** produces TDM-synchronized sensor readings at 10 Hz:
   magnetic gradients (4 channels), EMI conductivity (I/Q), RTK GPS, orientation,
   IR temperature. Published via MQTT over WiFi to Jetson.
2. **RPLiDAR C1** streams 360° point clouds at 10 Hz directly to Jetson via USB
   (not through ESP32 — avoids bandwidth bottleneck and EMI).
3. **Edge compute** (Jetson) receives all data, applies tilt correction,
   runs anomaly detection (multi-physics: magnetics + conductivity + thermal),
   publishes corrected data to local MQTT broker.
4. **Local subscribers** (field laptop, tablet) receive corrected data and
   anomaly alerts via MQTT for live visualization.
5. **Cloud bridge** (when Starlink available) forwards data to cloud for
   full-physics inversion and long-term storage.

### TDM Timing and Data Flow

The ESP32 firmware uses a 100 ms Time-Division Multiplexed cycle to prevent
cross-sensor electromagnetic interference:

```
0 ms              50 ms           80 ms    100 ms
├── Phase 1 ──────┤── Phase 2 ────┤─ P3 ───┤
│ FLUXGATE READ   │  EMI TX/RX    │ SETTLE │
│                 │               │        │
│ 8× fluxgate ADC│  AD9833 DDS   │ WiFi TX│
│ BNO055 IMU     │  AD630 I/Q    │ MQTT   │
│ MLX90614 IR    │  Conductivity │ SD card│
│ GPS RX (pass.) │  calculation  │ NTRIP  │
│                 │               │        │
│ EMI TX: OFF    │  WiFi TX: OFF │ EMI:OFF│
│ WiFi TX: OFF   │               │        │
└─────────────────┴───────────────┴────────┘
```

Each MQTT message contains the complete TDM cycle result: gradients, conductivity,
position, orientation, temperature, and timestamp. See
`../Pathfinder/research/multi-sensor-architecture/tdm-firmware-design.md`.

### Updated Sensor Data Rates

| Sensor | Data Rate | Transport |
|---|---|---|
| Fluxgate gradients (4 ch) | 160 B/s | MQTT (ESP32 → Jetson) |
| EMI conductivity (I, Q, σ) | 120 B/s | MQTT |
| RTK GPS position | 240 B/s | MQTT |
| BNO055 orientation | 160 B/s | MQTT |
| MLX90614 IR temperature | 80 B/s | MQTT |
| **MQTT subtotal** | **~1 KB/s** | WiFi |
| RPLiDAR C1 point clouds | ~400 KB/s | USB direct to Jetson |
| ESP32-CAM images | ~50 KB/s | WiFi/SD |
| **Total** | **~451 KB/s** | |
| **Per hour** | **~1.6 GB** | ~180M data points |

See `docs/research/data-rates-analysis.md` for full breakdown.

---

## MQTT Topic Hierarchy

All topics are rooted under `geosim/`.

| Topic Pattern | Description | Rate |
|---|---|---|
| `geosim/pathfinder/data/raw` | Raw gradiometer + EMI + IMU + GPS + IR | 10 Hz |
| `geosim/pathfinder/data/corrected` | After tilt correction | 10 Hz |
| `geosim/pathfinder/data/emi` | EMI conductivity (I, Q, σ_a) | 10 Hz |
| `geosim/pathfinder/data/thermal` | IR temperature (object + ambient) | 10 Hz |
| `geosim/pathfinder/anomaly/detected` | Anomaly alerts (multi-physics) | Event-driven |
| `geosim/hirt/data/mit/raw` | MIT quadrature measurements | Per sequence |
| `geosim/hirt/data/ert/raw` | ERT four-electrode readings | Per sequence |
| `geosim/hirt/model/update` | Latest inversion result | ~1/min |
| `geosim/hirt/probe/orientation` | Inclinometer readings | 1 Hz |
| `geosim/hirt/probe/position` | GPS position of probe insertion points | Event-driven |
| `geosim/status/{instrument}` | System health / heartbeat | 1 Hz |

### Message Format

All messages are JSON-serialized Python dataclasses (see `geosim.streaming.messages`).
Timestamps are ISO 8601 UTC. Numeric values use SI-compatible units:
nanotesla (nT) for gradients, degrees for angles, meters for positions.

### QoS Levels

- **Raw data**: QoS 0 (at most once) -- high rate, loss tolerable
- **Corrected data**: QoS 1 (at least once) -- logged to disk
- **Anomaly alerts**: QoS 2 (exactly once) -- critical notifications
- **Status/health**: QoS 1

---

## Hardware Requirements

### Recommended Edge Platform: NVIDIA Jetson AGX Orin 64GB

| Spec | Value | Justification |
|---|---|---|
| GPU | 2048 CUDA cores, 64 Tensor cores | CuPy acceleration for inversion |
| CPU | 12-core Arm Cortex-A78AE | Concurrent MQTT + processing |
| RAM | 64 GB LPDDR5 | Full inversion mesh in memory |
| Storage | 64 GB eMMC + NVMe SSD (1 TB) | Survey data logging |
| Power | 15-60 W configurable | Battery/solar operation |
| I/O | USB 3.2, SPI, I2C, UART, Ethernet | Direct instrument connection |
| Size | 100 x 87 mm module | Field-deployable enclosure |

### Minimum Viable: Jetson Orin Nano 8GB

Suitable for Pathfinder-only deployment (tilt correction + anomaly detection).
Not sufficient for on-device HIRT inversion.

### Hardware Additions BOM

| Item | Qty | Est. Cost | Purpose |
|---|---|---|---|
| Jetson AGX Orin 64GB Developer Kit | 1 | $1,999 | Edge compute |
| Samsung 980 PRO 1TB NVMe SSD | 1 | $110 | Survey data logging |
| Starlink Mini | 1 | $599 + $50/mo | Cloud connectivity |
| Pelican 1150 case | 1 | $40 | Weatherproof enclosure |
| USB-C hub (industrial) | 1 | $60 | Instrument connections |
| LiPo battery pack 24V 20Ah | 1 | $300 | 8+ hr field operation |
| DC-DC converter (24V to 19V) | 1 | $25 | Jetson power supply |
| BNO055 IMU breakout (spare) | 2 | $30 ea | Pathfinder tilt sensing |
| Panel-mount Ethernet connector | 2 | $15 ea | Weatherproof I/O |
| **Total** | | **~$3,250** | |

---

## Software Stack

### Edge (Jetson)

| Component | Version | Purpose |
|---|---|---|
| JetPack | 6.0+ | Base OS with CUDA |
| Python | 3.10+ | Application runtime |
| Eclipse Mosquitto | 2.x | Local MQTT broker |
| NumPy | 1.24+ | Numeric computation |
| CuPy | 13.x | GPU-accelerated NumPy |
| ONNX Runtime | 1.17+ | Surrogate model inference |
| paho-mqtt | 2.x | MQTT client library |
| Docker | 24.x | Container isolation |

### Cloud / Base Station

| Component | Version | Purpose |
|---|---|---|
| SimPEG | 0.20+ | EM/ERT forward modeling and inversion |
| pyGIMLi | 1.4+ | ERT inversion (alternative) |
| PyVista | 0.42+ | 3D visualization |
| PostgreSQL + TimescaleDB | 16+ | Time-series data storage |
| Grafana | 10+ | Real-time dashboards |

---

## Two-Tier Compute Strategy

### Tier 1: Edge (Always Available)

Runs on the Jetson regardless of connectivity. Sub-second latency.

| Task | Latency Target | Method |
|---|---|---|
| Pathfinder tilt correction | < 1 ms | NumPy vectorized |
| Anomaly detection (running stats) | < 1 ms | Rolling mean/std |
| Anomaly detection (ONNX surrogate) | < 10 ms | ONNX Runtime on GPU |
| Data logging to NVMe | < 1 ms | Append-only Parquet |
| MQTT publish | < 2 ms | Local broker |

### Tier 2: Cloud (When Connected)

Full-physics inversion when Starlink is available.

| Task | Latency Target | Method |
|---|---|---|
| HIRT progressive inversion | 30-120 s | SimPEG on GPU workstation |
| Full survey reprocessing | 5-30 min | Batch on HPC |
| Model archival | async | TimescaleDB + S3 |

### Graceful Degradation

- **Full connectivity**: Edge correction + cloud inversion in real time.
- **Intermittent**: Edge queues data, cloud processes when link available.
- **No connectivity**: Full edge pipeline runs independently. Data syncs later.

---

## Deployment: Docker Containers on Jetson

```yaml
# docker-compose.yml (simplified)
version: "3.8"

services:
  mosquitto:
    image: eclipse-mosquitto:2
    ports:
      - "1883:1883"
    volumes:
      - ./mosquitto.conf:/mosquitto/config/mosquitto.conf
      - mosquitto-data:/mosquitto/data

  pathfinder-pipeline:
    build: ./containers/pathfinder
    depends_on: [mosquitto]
    devices:
      - /dev/ttyUSB0:/dev/ttyUSB0   # GPS
      - /dev/i2c-1:/dev/i2c-1       # IMU
    environment:
      MQTT_BROKER: mosquitto
      MQTT_PORT: 1883
    volumes:
      - survey-data:/data

  hirt-pipeline:
    build: ./containers/hirt
    depends_on: [mosquitto]
    runtime: nvidia                   # GPU access for CuPy
    environment:
      MQTT_BROKER: mosquitto
    volumes:
      - survey-data:/data

  cloud-bridge:
    build: ./containers/bridge
    depends_on: [mosquitto]
    environment:
      MQTT_LOCAL: mosquitto:1883
      MQTT_CLOUD: ${CLOUD_MQTT_ENDPOINT}

volumes:
  mosquitto-data:
  survey-data:
```

Each container is independently restartable. The MQTT broker provides
decoupling between producers and consumers.

---

## Performance Benchmarks

Target benchmarks for edge compute on Jetson AGX Orin:

| Operation | Target | Measured | Status |
|---|---|---|---|
| Tilt correction (single sample) | < 1 ms | -- | Pending |
| Tilt correction (batch, 1000 samples) | < 5 ms | -- | Pending |
| Anomaly detection (single sample) | < 1 ms | -- | Pending |
| MQTT publish latency | < 2 ms | -- | Pending |
| MQTT end-to-end (pub to sub) | < 5 ms | -- | Pending |
| Pathfinder full pipeline (raw to corrected) | < 10 ms | -- | Pending |
| HIRT progressive inversion (100 cells) | < 30 s | -- | Pending |
| ONNX surrogate inference | < 10 ms | -- | Pending |
| Data logging (Parquet append) | < 1 ms | -- | Pending |
| Memory usage (idle) | < 2 GB | -- | Pending |

---

## Progressive Inversion Strategy for HIRT

HIRT collects data sequentially (one electrode combination at a time).
Rather than waiting for a complete survey, we use progressive inversion:

1. **Bootstrap phase** (first 20 measurements): Use a homogeneous
   half-space starting model. Inversion is underdetermined but provides
   a first approximation.

2. **Incremental update** (each new measurement): Add the new datum to the
   existing dataset and re-invert using the previous model as starting model.
   This converges faster than starting from scratch.

3. **Periodic full re-inversion** (every 50 measurements or on demand):
   Full inversion from scratch to prevent error accumulation from
   incremental updates.

4. **Model publication**: After each update, publish the current model to
   `geosim/hirt/model/update` as a serialized mesh with resistivity values.

### Probe Tilt Compensation

HIRT probes in boreholes may not be perfectly vertical. Inclinometer
readings from each probe are published to `geosim/hirt/probe/orientation`
and used to correct the geometric factor in ERT apparent resistivity
calculations:

```
K_corrected = K_geometric * cos(tilt_magnitude)
```

This ensures that the inversion uses accurate electrode positions even
when probes deflect from vertical.

---

## Surrogate Model / PINN Future Roadmap

For Phase 2, we plan to replace or supplement physics-based inversion with
learned models for faster edge inference:

### ONNX Surrogate Models

1. **Training**: Run thousands of SimPEG forward models with varied
   subsurface configurations. Train a neural network to predict the
   forward response (or its Jacobian) from a resistivity model.

2. **Export**: Convert trained PyTorch/TensorFlow model to ONNX format.

3. **Inference**: Run on Jetson using ONNX Runtime with CUDA execution
   provider. Target < 10 ms per forward evaluation (vs. seconds for
   full physics).

4. **Use case**: Real-time "what-if" visualization in the field.
   Operator adjusts model, sees predicted data response instantly.

### Physics-Informed Neural Networks (PINNs)

Embed Maxwell's equations as loss terms during training so the network
respects physics even in regions with sparse data:

- **Advantage**: Generalizes better than pure data-driven surrogates.
- **Challenge**: Training is slower; inference speed is similar to standard NN.
- **Timeline**: Phase 3, after surrogate model validation.

### Hybrid Approach

Use surrogate for rapid approximate inversion at the edge, then refine
with full SimPEG inversion in the cloud. The surrogate provides an
excellent starting model, reducing cloud inversion iterations by 3-5x.

---

---

## Fiber Optic Alternative

WiFi (ESP32 built-in) is the primary data link between Pathfinder and the Jetson.
However, for applications requiring absolute minimum RF interference with fluxgate
measurements, a fiber optic alternative has been evaluated.

### Decision Framework

| WiFi Interference (after TDM) | Recommendation |
|---|---|
| < 0.1 nT | WiFi sufficient (current design) |
| 0.1 - 1.0 nT | Fiber recommended for high-precision |
| > 1.0 nT | Fiber required |

**Current estimate**: < 0.01 nT with TDM + shielding **(Modeled)**. WiFi is sufficient.

### Fiber Options (If Needed)

| Option | Cost | Data Rate | Cable |
|---|---|---|---|
| USB-to-fiber media converter | $80-150/pair | 480 Mbps | Glass multimode |
| SFP on Jetson Ethernet | $50-70 | 1 Gbps | Glass single-mode |
| Plastic Optical Fiber (POF) | $40-60 | 100 Mbps | PMMA 1mm (flexible) |

POF is recommended for field use: cheap, flexible, easy to terminate, adequate bandwidth.

### Hybrid Approach

Fiber for data, WiFi disabled entirely during survey. ESP32 sends all data over
fiber-to-USB converter. NTRIP corrections flow from Jetson via fiber to ESP32.
Zero RF emission from instrument.

**Operational downside**: Trailing 10-100m fiber cable requires reel, limits terrain flexibility.

See `docs/research/fiber-vs-wifi-analysis.md` for full analysis.

---

## EMI Conductivity Channel Data Flow

The EMI (FDEM) conductivity channel adds below-ground electrical conductivity
to the streaming pipeline. Data flow:

```
AD9833 DDS (15 kHz) → OPA549 → TX Coil
                                    ↓ (ground eddy currents)
                              RX Coil → AD8421 → AD630 → ADS1115
                                                   ↓
                                        I (in-phase) → susceptibility
                                        Q (quadrature) → conductivity
                                                   ↓
                        σ_a = (4/(ωμ₀s²)) × Q/primary
                                                   ↓
                        MQTT: geosim/pathfinder/data/emi
                                                   ↓
                        Jetson: conductivity map overlay
                                                   ↓
                        SimPEG: FDEM forward model validation
```

The conductivity data enables:
- Real-time conductivity mapping alongside magnetics
- Detection of soil disturbance invisible to magnetics (e.g., clay-filled features)
- Boundary condition for HIRT ERT inversion (surface conductivity constrains top layers)

---

## References

- Eclipse Mosquitto: https://mosquitto.org/
- NVIDIA Jetson AGX Orin: https://developer.nvidia.com/embedded/jetson-agx-orin
- SimPEG: https://simpeg.xyz/
- pyGIMLi: https://www.pygimli.org/
- ONNX Runtime: https://onnxruntime.ai/
- Paho MQTT: https://eclipse.dev/paho/
- CuPy: https://cupy.dev/
- Pathfinder TDM design: `../Pathfinder/research/multi-sensor-architecture/tdm-firmware-design.md`
- Data rates analysis: `docs/research/data-rates-analysis.md`
- Fiber vs WiFi: `docs/research/fiber-vs-wifi-analysis.md`

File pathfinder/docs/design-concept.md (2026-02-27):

# Pathfinder Design Concept

## Overview

Pathfinder is a harness-supported multi-channel fluxgate gradiometer for rapid magnetic reconnaissance. The design follows the proven "trapeze" configuration used by commercial systems like the Bartington Grad601, but extends it to 4 sensor pairs for wider swath coverage.

## Physical Configuration

```
                    PADDED HARNESS
                   (backpack straps)
                          |
              +-----------+-----------+
              |     bungee/elastic    |
              |      suspension       |
              +-----------+-----------+
                          |
    ======================+=======================
              CARBON FIBER OR ALUMINUM TUBE
                    (1.5 - 2.0 m)
        |         |         |         |
       +-+       +-+       +-+       +-+
       |T|       |T|       |T|       |T|    <- TOP sensors (reference)
       | |       | |       | |       | |       mounted on crossbar
       | |       | |       | |       | |    <- PVC drop tubes (50cm)
       |B|       |B|       |B|       |B|    <- BOTTOM sensors (signal)
       +-+       +-+       +-+       +-+       ~15-20 cm above ground

       <--50cm--><--50cm--><--50cm-->
                 1.5 m swath
```

## Gradiometer Principle

Each gradiometer pair consists of two vertically-separated fluxgate sensors:

- **Top sensor (reference)**: Measures background magnetic field (~50 cm above ground)
- **Bottom sensor (signal)**: Measures field including near-surface anomalies (~15-20 cm above ground)
- **Gradient**: Difference between sensors cancels regional field, isolates local anomalies

This configuration is insensitive to:
- Diurnal magnetic field variations
- Regional geological gradients
- Operator movement through Earth's field

## Why Multiple Pairs Work

Fluxgate sensors are **passive receivers** - they don't emit fields that could interfere with neighbors. Commercial systems routinely operate 8-10 pairs simultaneously:

| System | Channels | Spacing | Reference |
|---|---|---|---|
| Foerster 10-channel | 9-10 pairs | 25 cm | [ResearchGate](https://www.researchgate.net/figure/Magnetic-survey-with-motorized-10-channel-Foerster-gradiometer-array-mounted-with-25-cm_fig1_261061128) |
| tMag (Bartington) | 8 pairs | 50 cm | [Geoscientific Instrumentation](https://gi.copernicus.org/articles/10/313/2021/) |
| Bartington Grad601-2 | 2 pairs | 100 cm | [Bartington](https://www.bartington.com/products/grad601/) |

Crosstalk only becomes significant at <2 cm spacing (medical MEG applications). At 50 cm spacing, it's negligible.

## Harness System

Based on the [Bartington Grad601 trapeze design](https://arf.berkeley.edu/files/attachments/books/Bartington_Grad601_2_Setup_And_Operation_1.pdf):

### Key Features

1. **Shoulder straps**: Padded backpack-style straps distribute weight
2. **Waist belt**: Stabilizes load, prevents swinging
3. **Elastic suspension**: Bungee cords isolate sensor vibration from walking motion
4. **Quick-release**: Carabiners allow rapid don/doff
5. **Height adjustment**: Straps set sensor height to 15-20 cm above ground

### Ergonomics

- Operator walks at steady pace (~1 m/s)
- Hands rest lightly on crossbar for guidance only
- Arms never bear weight
- Audio beeper marks pace (one beep per meter)

## Multi-Sensor Electronics Architecture

The Pathfinder electronics architecture has been expanded from a single-modality magnetic gradiometer to a multi-sensor platform controlled by an ESP32 dual-core MCU with time-division multiplexed (TDM) measurement cycles.

```
                                    ┌─────────────────────┐
SENSOR POD (shared w/ HIRT)         │                     │
┌────────────────────┐   Cat5 STP   │      ESP32          │
│ ZED-F9P RTK GPS    │◄────────────►│   (Dual Core)       │
│ BNO055 IMU         │  PCA9615     │                     │
│ BMP390 Baro        │  diff I2C    │ Core 0: WiFi/MQTT   │
│ DS3231 RTC         │  (Bus 1)     │   NTRIP, SD, GPS    │
└────────────────────┘              │                     │
                                    │ Core 1: TDM engine  │
Fluxgate Pairs 1-4  ──► LM2917 ──► │   ADC, EMI, tilt    │
(8× FG-3+ sensors)      (F-to-V)   │                     │
                                    │ I2C Bus 0:          │
ADS1115 ×2 (0x48,0x49) ◄───────────│   Local sensors     │
MLX90614 IR (0x5A)  ◄──────────────│                     │
                                    └──────┬──────────────┘
                                           │
EMI TX Coil ◄── OPA549 ◄── AD9833 DDS     │ WiFi / MQTT
EMI RX Coil ──► AD8421 ──► AD630 (I/Q) ──►│
                                           ▼
RPLiDAR C1 ──── USB ──────────────► Jetson (edge compute)
ESP32-CAM  ──── GPIO trigger        MQTT broker + storage
                                    Anomaly detection
LiPo Battery 7.4V 2000mAh          LiDAR → DEM
├── LM2596 buck (5.5V)
│   ├── Ferrite+LC filter
│   │   ├── TPS7A49 LDO (5.0V analog rail)
│   │   └── AP2112K-5.0 ×8 (individual per FG-3+)
│   └── 3.3V LDO (ESP32, digital)
└── Direct to OPA549 (EMI TX power)
```

### Time-Division Multiplexing (TDM)

The TDM firmware prevents electromagnetic interference between sensors by ensuring only compatible sensors operate simultaneously. Each 100 ms cycle:

| Phase | Duration | Active Sensors | Disabled |
|---|---|---|---|
| Fluxgate | 50 ms | Fluxgates, ADC, IMU, IR, GPS RX | EMI TX, WiFi TX, SD card |
| EMI TX/RX | 30 ms | EMI coils, ADC (I/Q), lock-in | WiFi TX |
| Settling | 20 ms | WiFi TX, MQTT, SD write, NTRIP | EMI TX |

See `research/multi-sensor-architecture/tdm-firmware-design.md` for full implementation details.

### EMI Conductivity Channel

The EMI channel adds subsurface electrical conductivity mapping using the FDEM method:

- **TX**: AD9833 DDS generates 15 kHz sine → OPA549 drives TX coil (30 turns, 12 cm dia)
- **RX**: AD8421 preamp (gain 100) → AD630 phase detector → I and Q channels → ADS1115
- **Bucking coil**: Cancels primary field at RX location (>99% cancellation)
- **Output**: Apparent conductivity σ_a = (4/(ωμ₀s²)) × Q/primary

See `research/multi-sensor-architecture/emi-coil-design.md` for signal chain details.

### Physical Layout (Crossbar)

Sensor placement is optimized to minimize electromagnetic interference:

```
-100cm    -50cm     0cm      +15cm  +25cm +50cm +75cm +100cm
  │         │        │         │      │     │     │      │
LiDAR    EMI TX  Electronics  IR   FG-1  FG-2  FG-3   FG-4
              EMI RX (-10cm)  CAM
              GPS mast (above)
              Sensor pod
```

See `research/multi-sensor-architecture/crossbar-physical-layout.md` for detailed layout.

### Interference Mitigation

15 source-victim interference paths have been analyzed and mitigated:

- **CRITICAL**: EMI TX → fluxgate (2100 nT at 1m) → TDM + physical separation
- **CRITICAL**: LiDAR motor → fluxgate (100-300 nT) → 1.25-2.0m separation + gradiometer subtraction
- **HIGH**: Buck converter → ADC → 3-stage power supply (95-110 dB PSRR **(Modeled)**)
- See `research/multi-sensor-architecture/interference-matrix.md` for complete analysis.

### Consensus-Validated Design Corrections

Multi-model consensus validation (GPT-5.2, GPT-5.2-Pro, Grok 4.1 Fast) identified the following critical corrections to the initial design:

| Issue | Severity | Correction |
|---|---|---|
| LM78L05 dropout at 5.5V input (needs 6.7V+) | **CRITICAL** | Replace with AP2112K-5.0 (250mV dropout) — feeds from 5.5V post-LC rail |
| ADS1115 "DMA" claim over I2C impossible | **CRITICAL** | Use ALERT/RDY pin interrupt-driven continuous mode; 860 SPS for EMI phase |
| WiFi `esp_wifi_stop/start` too slow for 100ms TDM | **HIGH** | Use `esp_wifi_set_max_tx_power(0)` + application-level send blocking |
| M8 4-pin connector insufficient for PCA9615 | **CRITICAL** | Upgrade to M8 8-pin (PCA9615 needs 6 conductors: 2×SDA, 2×SCL, VCC, GND) |
| Solenoid inductance formula wrong for short coils | **HIGH** | Wheeler's approximation: L_TX = 150-180 μH (not 710 μH) |
| Single AD630 cannot produce simultaneous I/Q | **HIGH** | Need two AD630s or digital lock-in approach |
| 20ms settling insufficient (26% LM2917 residual) | **MODERATE** | Increase to 45ms (3τ) or use active discharge/discard strategy |
| GPIO 16/17 conflict (I2C Bus 1 vs UART2) | **HIGH** | Reassign GPS UART2 to GPIO 32/33 |
| BMP390 in sealed IP67 enclosure invalid | **HIGH** | Add IP67 vent membrane (Gore PolyVent or Amphenol) |

See `research/multi-sensor-architecture/` consensus files for detailed analysis and recommendations.

### ADC Requirements

- 8 channels for fluxgates (4 pairs × 2 sensors) via 2× ADS1115
- 2 additional channels for EMI I/Q (shared ADS1115 MUX or dedicated 3rd unit)
- 16-bit resolution adequate for gradiometry
- Sample rate: 10 Hz (TDM-limited, 128 SPS raw ADC rate)

## Bill of Materials (Estimated)

The multi-sensor upgrade adds 7× sensing capability for approximately 60% more cost. Full BOM details in `research/multi-sensor-architecture/updated-bom.md`.

| Category | Est. Cost | Key Components |
|---|---|---|
| **Fluxgate sensors** | $480-640 | 8× FG-3+ (4 gradiometer pairs) |
| **Frame + harness** | $85-115 | Carbon fiber tube, PVC drops, harness, bungee |
| **ESP32 + original electronics** | $57 | ESP32, 2× ADS1115, 8× LM2917, SD card, battery |
| **Power supply upgrade** | $18 | LM2596 + ferrite+LC + TPS7A49 + 8× AP2112K-5.0 |
| **EMI conductivity channel** | $71 | AD9833 + OPA549 + AD8421 + AD630 + coils |
| **IR temperature** | $15 | MLX90614xAC |
| **Camera** | $15 | ESP32-CAM standalone |
| **LiDAR** | $73-93 | RPLiDAR C1 |
| **Sensor pod (50% shared)** | $182 | ZED-F9P + BNO055 + BMP390 + DS3231 + PCA9615 |
| **EMI mitigation** | $22 | M8 8-pin connectors, shielded cable, bypass caps, vent membrane |
| **Total** | **$1,052-1,262** | |

## Weight Budget

| Component | Weight |
|---|---|
| 8 fluxgate sensors | ~400g |
| Carbon tube + PVC drops | ~300g |
| Electronics + battery | ~250g |
| Harness + suspension | ~200g |
| Cables | ~100g |
| **Total** | **~1.25 kg** |

Commercial comparison:
- Bartington Grad601: 1.6 kg (2 sensors)
- SENSYS MagWalk: 1.6 kg (2 sensors)

Pathfinder achieves **4x the sensors at similar weight**.

## Performance Estimates

### Coverage Rate

| Configuration | Swath | Speed | Area/Hour |
|---|---|---|---|
| 2-pair (1.0 m) | 0.5 m | 3.6 km/h | ~1,800 m² |
| 4-pair (1.5 m) | 1.5 m | 3.6 km/h | ~5,400 m² |

### Detection Capability

Based on fluxgate gradiometer physics:

| Target | Estimated Detection Depth |
|---|---|
| Small ferrous (nail, shell casing) | 20-40 cm |
| Medium ferrous (helmet, tool) | 50-100 cm |
| Large ferrous (engine block, UXO) | 1-2 m |
| Fired clay (kiln, hearth) | 30-60 cm |
| Disturbed soil (burial, pit) | 20-50 cm |

**Note**: These are estimates based on similar commercial systems. Actual performance requires field validation.

## Data Format

CSV output with columns:

```
timestamp,lat,lon,g1_top,g1_bot,g1_grad,g2_top,g2_bot,g2_grad,g3_top,g3_bot,g3_grad,g4_top,g4_bot,g4_grad
2024-01-15T10:23:45.123,51.234567,18.345678,48234,48456,222,48189,48401,212,...
```

- Timestamp: ISO 8601 with milliseconds
- Position: Decimal degrees (WGS84)
- Readings: Raw ADC counts (calibration applied in post-processing)
- Gradient: Bottom minus top (computed on-device for quick review)

## Post-Processing Workflow

1. **Download**: Transfer CSV from SD card
2. **Import**: Load into QGIS, Google Earth, or custom Python script
3. **Grid**: Interpolate point data to regular grid
4. **Visualize**: Generate gradient magnitude map
5. **Identify**: Mark anomalies for HIRT follow-up

## Joint Inversion with HIRT

Pathfinder's surface measurements serve as boundary conditions for HIRT's subsurface 3D tomographic inversion. The operational workflow:

1. **Pathfinder survey** (30-60 min): Walk site, collect magnetics + EMI + IR + LiDAR
2. **Anomaly flagging**: Jetson detects anomalies in real-time
3. **HIRT deployment** (2-4 hr per anomaly): Insert probes around flagged targets
4. **Joint inversion**: Combine Pathfinder surface data + HIRT crosshole data in SimPEG

The shared sensor pod ensures GPS coordinate registration between instruments. Cross-gradient regularization couples the magnetic susceptibility and conductivity models. See `GeoSim/docs/research/joint-inversion-concept.md`.

## Open Questions

1. ~~**Sensor selection**: FG Sensors fluxgates vs. alternatives~~ → Resolved: FG-3+ selected
2. **ADC noise floor**: Is ADS1115 adequate, or need 24-bit ADS1256? (see noise-analysis.md)
3. **Crossbar material**: Carbon fiber for fluxgate section, fiberglass elsewhere (aluminum causes eddy currents for EMI)
4. ~~**LM78L05 dropout**: 5.5V input marginal~~ → Resolved: Replace with AP2112K-5.0 (250mV dropout, feeds from 5.5V post-LC rail) (R5 consensus)
5. ~~**WiFi vs fiber**: TDM + shielding estimated < 0.01 nT interference~~ → Resolved: WiFi+TDM sufficient; realistic estimate 0.01-0.1 nT; fiber as optional upgrade (R1 consensus)
6. ~~**EMI coil bucking**: Precise turns/position calculation needed~~ → Resolved: Wheeler L_TX=150-180 μH, resonant C=625-750 nF, need two AD630s for I/Q (R3 consensus)
7. **LiDAR TDM gating**: Motor DC field at fluxgate — need bench characterization
8. **ADS1115 timing**: Cannot achieve 5 cycles/50ms at 128 SPS — need ALERT/RDY interrupt mode (R2 consensus)
9. **M8 connector upgrade**: 4-pin → 8-pin for PCA9615 differential I2C (R4 consensus)

## References

- [Bartington Grad601 Manual](https://www.bartingtondownloads.com/wp-content/uploads/OM1800.pdf)
- [Berkeley Grad601 Field Guide](https://arf.berkeley.edu/files/attachments/books/Bartington_Grad601_2_Setup_And_Operation_1.pdf)
- [tMag Array Paper](https://gi.copernicus.org/articles/10/313/2021/)
- [FG Sensors DIY Kit](https://www.fgsensors.com/diy-gradiometer-kit)
- [SENSYS MagWalk](https://sensysmagnetometer.com/products/magwalk-magnetometer-survey-kit/)

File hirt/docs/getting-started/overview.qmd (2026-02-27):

---
title: "Overview"
---

## What is HIRT? {#sec-what-is-hirt}

HIRT (Hybrid Inductive-Resistivity Tomography) is a **dual-channel subsurface imaging system** designed for archaeological and forensic investigations. By placing sensors inside the ground and measuring through the volume using **crosshole geometry**, HIRT obtains true tomographic coverage for 3D reconstruction of subsurface features.

```{python}
#| label: fig-system-overview
#| fig-cap: "HIRT dual-channel system overview. The system combines MIT-3D (Magneto-Inductive Tomography) for metal detection with ERT-Lite (Electrical Resistivity) for soil disturbance mapping. Probes are inserted into pre-drilled 18-20mm holes (Target), with ray paths traversing the target volume for true 3D tomographic imaging."
#| fig-width: 9
#| fig-height: 5

import sys; sys.path.insert(0, '..') if '..' not in sys.path else None
from diagrams.executive_summary import create_system_overview
import matplotlib.pyplot as plt
from PIL import Image

buf = create_system_overview()
img = Image.open(buf)
plt.figure(figsize=(9, 5))
plt.imshow(img)
plt.axis('off')
plt.tight_layout()
plt.show()
```

## Why the Name {#sec-why-the-name}

HIRT was created in a landscape shaped by war and unfinished consequences.

The Silesian basin of modern-day Poland was the target of one of the most intensive Allied bombing campaigns of World War II, centered on the Blechhammer industrial complex. Tens of thousands of bombs fell here. Many exploded. Thousands did not. Today, an estimated 4,000--6,000 unexploded bombs remain buried beneath forests, wetlands, and towns, still capable of detonation decades later. These UXOs continue to shape land use, infrastructure planning, and public safety across the region.

This same ground holds other histories. POW camps and forced labor sites. Jewish victims of the industrial death system tied to Blechhammer. Aircrews lost in the bombing campaigns. Civilians---families and children---killed not as targets, but by proximity. After the war came displacement, silence, and redevelopment layered over danger that was never fully removed.

My great-uncle, 1st Lt. Arthur Lindell, was shot down here. He and his crew are still missing, believed to lie in a filled bomb crater at the crash site. That search is personal---but it exists within a much larger, unresolved problem shared by communities across Europe and beyond.

HIRT takes its name from this history of hurt and pain, and from a commitment to address what remains beneath the surface. It was designed to see without excavation, to reduce risk where danger still exists, and to help bring clarity---whether the goal is safety, remembrance, or recovery.

## Dual-Channel Approach {#sec-dual-channel}

HIRT employs two complementary sensing modalities that together provide comprehensive subsurface characterization:

- **MIT-3D (Magneto-Inductive Tomography):** Low-frequency TX/RX coils (2-50 kHz) (Target) measure amplitude and phase changes caused by eddy currents. Maps conductive metal masses including aluminum, which magnetometry cannot detect.
- **ERT-Lite (Electrical Resistivity):** Small ring electrodes inject tiny currents (0.5-2 mA) (Target) and measure voltage distribution. Maps soil resistivity variations from moisture, disturbance patterns, voids, and grave shafts.

::: {.callout-note}
## Design Philosophy

- Make each probe dual-role (TX & RX for MIT) plus ERT pickup
- Identical probes simplify logistics and improve data quality
- Modular, interchangeable components for field serviceability
- Minimal site disturbance (~10x less than traditional methods)
:::

## Primary Use Cases {#sec-use-cases}

HIRT is optimized for three primary application scenarios, each with specific configuration recommendations:

| Use Case | Typical Parameters | Key Method | Target Types |
|---|---|---|---|
| Filled Bomb Crater | 10-15m dia, 0-4m depth; 3m probes, 1.5m spacing (Target) | MIT + ERT combined | Metal parts + remains |
| Woods Burials | 0.6-1.5m depth; 1.5m probes, 1m spacing (Target) | ERT patterns + MIT | Grave shafts, artifacts |
| Swamp/Marsh Crash | 5-8+m depth; 3.5m probes, 2-3m spacing (Target) | Low-freq MIT | Deep-buried aircraft |

: Primary HIRT use cases and configurations {#tbl-use-cases}

## System Capabilities {#sec-capabilities}

```{python}
#| label: fig-capabilities
#| fig-cap: "Key HIRT capabilities infographic. The crosshole geometry provides true 3D tomographic imaging with 2-5x better resolution than surface methods at investigation depths of 2-6 m (Modeled; see @sec-depth-investigation for configuration-specific depth claims). Cost savings of 95%+ (Target) make professional-grade subsurface imaging accessible to research institutions and humanitarian organizations."
#| fig-width: 10
#| fig-height: 4.5

import sys; sys.path.insert(0, '..') if '..' not in sys.path else None
from diagrams.executive_summary import create_capabilities_infographic

buf = create_capabilities_infographic()
img = Image.open(buf)
plt.figure(figsize=(10, 4.5))
plt.imshow(img)
plt.axis('off')
plt.tight_layout()
plt.show()
```

Surface GPR and magnetometry are excellent screening tools but can yield ambiguous results in complex conditions. HIRT's crosshole geometry provides superior performance through direct measurement paths:

- **True tomographic coverage** through the target volume (not surface extrapolation)
- **2-5x better resolution** than surface methods at depths of 2-6 m **(Modeled)**---see [Uncertainty: Depth of Investigation](../theory/uncertainty.qmd#sec-depth-investigation) for configuration-specific claims
- **Superior depth discrimination** - targets at 3m vs 4m are clearly distinguishable (Target)
- **Non-ferrous detection** - aluminum aircraft parts that magnetometry cannot sense
- **3D localization** with measured positions rather than estimated pseudo-depth

```{python}
#| label: fig-depth-investigation
#| fig-cap: "Depth of investigation ranges by HIRT configuration: 2-4 m typical with 1.5-3.0 m probes, up to 5-6 m in low-conductivity soils with 3.0 m probes and wide spacing (Modeled). The typical surface method limit (~1.5 m) is shown for comparison. See @tbl-depth-investigation for authoritative depth claims by configuration and confidence level."
#| fig-width: 9
#| fig-height: 4

import sys; sys.path.insert(0, '..') if '..' not in sys.path else None
from diagrams.executive_summary import create_depth_investigation

buf = create_depth_investigation()
img = Image.open(buf)
plt.figure(figsize=(9, 4))
plt.imshow(img)
plt.axis('off')
plt.tight_layout()
plt.show()
```

## Limitations and Non-Goals {#sec-limitations}

::: {.callout-warning}
## Non-Goals

- Producing final 3D visuals (software pipeline is a separate development phase)
- Replacing standard ethical/excavation practices or permits
- Replacing professional archaeological/forensic protocols
:::

**When Surface Methods Remain Superior:** Rapid large-area screening (10x faster) (Modeled), shallow targets (<1m) where GPR resolution excels, purely ferrous targets (magnetometry), and initial site characterization before targeted investigation.

**Technical Limitations:** Smaller coil area results in ~19 dB SNR loss compared to commercial systems (Modeled; compensated by longer integration times). Survey time increases 5-10x compared to commercial systems (Modeled). Requires post-processing software for 3D reconstruction. Limited depth performance in highly conductive soils.

## Optimal Workflow {#sec-workflow}

```{python}
#| label: fig-workflow
#| fig-cap: "Two-stage optimal workflow combining surface screening methods with HIRT crosshole follow-up. This approach leverages the speed of surface methods for initial anomaly identification, then applies HIRT's superior resolution for detailed characterization of identified targets."
#| fig-width: 10
#| fig-height: 3.5

import sys; sys.path.insert(0, '..') if '..' not in sys.path else None
from diagrams.executive_summary import create_workflow_diagram

buf = create_workflow_diagram()
img = Image.open(buf)
plt.figure(figsize=(10, 3.5))
plt.imshow(img)
plt.axis('off')
plt.tight_layout()
plt.show()
```

The physics supports a **two-stage approach** that leverages the strengths of both surface and crosshole methods:

1. **Surface screening** (magnetometry, GPR, EM31): Identify anomalies quickly over large areas with rapid coverage rates.
2. **HIRT crosshole follow-up**: Characterize identified anomalies with superior 3D resolution and depth discrimination.

## Target Audience {#sec-audience}

This documentation and the HIRT system are designed for:

- **Archaeologists** investigating WWII sites, burial locations, or crash sites
- **Forensic investigators** requiring non-destructive subsurface imaging
- **Geophysicists** interested in low-cost tomographic methods
- **DIY builders** seeking to construct field-deployable systems
- **Researchers** exploring crosshole electromagnetic/resistivity techniques

## Cost Overview {#sec-cost}

```{python}
#| label: fig-cost-comparison
#| fig-cap: "Cost comparison between HIRT and commercial crosshole systems. A complete HIRT starter kit costs $1,800-3,900 (Target) depending on component selection, representing 95%+ savings (Target) compared to commercial systems ($50,000-200,000+) (Manufacturer spec). The primary cost driver is the number of probes (20-24 for standard deployment at $70-150 each) (Target)."
#| fig-width: 10
#| fig-height: 4

import sys; sys.path.insert(0, '..') if '..' not in sys.path else None
from diagrams.executive_summary import create_cost_comparison

buf = create_cost_comparison()
img = Image.open(buf)
plt.figure(figsize=(10, 4))
plt.imshow(img)
plt.axis('off')
plt.tight_layout()
plt.show()
```

| Component | Low-End | High-End | Notes |
|---|---|---|---|
| Probes (20-24) | $1,400 (Target) | $3,600 (Target) | $70-150 per probe (Target) |
| Electronics Hub | $200 (Target) | $300 (Target) | DIY vs pre-built |
| Cables & Connectors | $50 (Target) | $50 (Target) | Standard components |
| Tools & Misc | $50 (Target) | $50 (Target) | Assembly tools |
| **Total** | **$1,800 (Target)** | **$3,900 (Target)** | **95%+ vs commercial (Target)** |

: HIRT system cost breakdown (2024 component pricing) {#tbl-cost-breakdown}

This cost structure places professional-grade subsurface imaging capabilities within reach of university research groups, non-profit humanitarian organizations, and archaeological teams that could not otherwise afford crosshole tomography.

## Related Work {#sec-related-work}

HIRT exists within a growing ecosystem of open-source geophysical instrumentation. While several excellent projects have democratized specific sensing modalities, HIRT fills a unique gap: no existing open-source project combines magneto-inductive tomography with electrical resistivity in an integrated crosshole system.

The table below positions HIRT relative to comparable open-hardware projects:

| Project | Modality | Open Hardware | Peer Review | Estimated Cost |
|---|---|---|---|---|
| **HIRT** | MIT + ERT crosshole | Yes | Target: HardwareX | <$3,000 (Target) |
| OhmPi | ERT (surface) | Yes | HardwareX 2020 | <$500 (Target) |
| OpenEIT | EIT (biomedical) | Yes | Partial | ~$300 (Target) |
| Cheap-G | Gravimetry | Yes | HardwareX 2021 | ~$1,000 (Target) |

: Comparison of open-source geophysical/tomographic hardware {#tbl-related-work}

HIRT's architecture and documentation structure draw inspiration from the OhmPi project, which demonstrated that rigorous open-source hardware documentation can meet peer-review standards while remaining accessible to diverse users. We acknowledge OhmPi's pioneering work in establishing patterns for open geophysical hardware that others can build upon.

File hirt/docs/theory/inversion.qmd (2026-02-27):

---
title: "Inversion and Reconstruction"
---

## Overview

This section covers the mathematical foundations and algorithms for tomographic reconstruction from HIRT measurements. For practical interpretation guidance, see [Field Guide: Interpretation](../field-guide/interpretation.qmd).

Tomographic inversion solves the "inverse problem": finding the subsurface property distribution that best explains the measured data.

## Data Processing Pipeline

HIRT data processing follows a systematic pipeline from raw field acquisition through final interpretation:

1. **Data Acquisition:** Raw ADC samples collected from probe pairs
2. **Filter and Average:** Noise reduction through digital filtering and stacking
3. **Background Removal:** Subtract homogeneous response to isolate anomalies
4. **Reciprocity Check:** Validate A-to-B equals B-to-A for quality assurance
5. **Tomographic Inversion:** Reconstruct 3D conductivity/resistivity distribution
6. **MIT/ERT Fusion:** Combine multi-modal data for comprehensive interpretation
7. **3D Model Generation:** Build voxel grid from inverted data
8. **Visualization:** Generate depth slices, isosurfaces, and reports

## Mathematical Basis of Reconstruction

### Forward Models

**MIT (Quasi-Static Maxwell's Equations):** The secondary magnetic field B_s generated by eddy currents in a conductive medium is governed by:

$$\nabla \times \mathbf{E} = -i \omega \mathbf{B}$$

$$\nabla \times \mathbf{H} = \sigma \mathbf{E} + \mathbf{J}_s$$

Where $\sigma$ is conductivity, $\omega$ is angular frequency, and $\mathbf{J}_s$ is the source current.

**ERT (Poisson's Equation):** The electric potential $\phi$ distribution due to a current source $I$ in a medium of conductivity $\sigma$ is governed by:

$$\nabla \cdot (\sigma \nabla \phi) = -I \delta(\mathbf{r} - \mathbf{r}_s)$$

### Inverse Problem Formulation

The reconstruction minimizes an objective function $\Phi$ comprising data mismatch and model roughness (regularization):

$$\Phi(\mathbf{m}) = \| \mathbf{d}_{obs} - F(\mathbf{m}) \|^2 + \lambda \| \mathbf{R} \mathbf{m} \|^2$$

Where $\mathbf{d}_{obs}$ is observed data, $F(\mathbf{m})$ is the forward model output for model $\mathbf{m}$, $\mathbf{R}$ is the roughness matrix, and $\lambda$ is the regularization parameter.

This is typically solved using a Gauss-Newton iterative update:

$$\mathbf{m}_{k+1} = \mathbf{m}_k - (\mathbf{J}^T \mathbf{J} + \lambda \mathbf{R}^T \mathbf{R})^{-1} \mathbf{J}^T (\mathbf{d}_{obs} - F(\mathbf{m}_k))$$

Where $\mathbf{J}$ is the Sensitivity Matrix (Jacobian) describing how data changes with model parameters.

## Inversion Best Practices

Based on established practices in SimPEG and pyGIMLi, the following guidelines optimize inversion results for HIRT data.

### Regularization Parameters

For crosshole/borehole geometries, anisotropic regularization improves results:

| Parameter | Surface Survey | Crosshole Survey | Notes |
|---|---|---|---|
| zWeight | 1.0 | 0.3-0.5 **(Modeled)** | Reduced vertical smoothing for crosshole |
| Lateral smoothing | Standard | Standard | Maintain lateral continuity |
| Alpha_s (smallness) | 0.001-0.01 **(Modeled)** | 0.001-0.01 **(Modeled)** | Model norm regularization |
| Alpha_x/y/z (smoothness) | 1.0 | 1.0/1.0/0.3 **(Modeled)** | Directional smoothness weights |

: Recommended regularization parameters (from SimPEG/pyGIMLi best practices) {#tbl-regularization}

The reduced zWeight (0.3-0.5) **(Modeled)** for crosshole surveys allows sharper vertical boundaries—appropriate when horizontal ray paths provide good vertical resolution.

### Starting Model Selection

The starting model significantly affects inversion convergence and final results:

- **Default starting model**: Use background resistivity estimate, typically ln(100 ohm·m) = ln(0.01 S/m) **(Modeled)**
- **Site-specific**: If prior information exists, use that as the starting model
- **Homogeneous half-space**: Appropriate when no prior information is available

::: {.callout-note}
## SimPEG Convention
SimPEG uses log-conductivity (ln σ) parameterization. A starting model of ln(0.01) corresponds to 100 ohm·m **(Modeled)** resistivity. This ensures positivity and improves numerical stability.
:::

### Mesh Design Guidelines

| Element | Guideline | Rationale |
|---|---|---|
| Cell size at electrodes | ~10% of electrode spacing **(Modeled)** | Resolves current injection |
| Cell size in target zone | ~25% of expected feature size **(Modeled)** | Adequate resolution |
| Padding cells | 3-5 layers, expanding **(Modeled)** | Boundary condition stability |
| Mesh type (ERT) | Tetrahedral or OcTree | Handles topography and refinement |

: Mesh design guidelines (from finite element best practices) {#tbl-mesh-guidelines}

For HIRT's ~0.5 m ring electrode spacing, cells near electrodes should be ~5 cm **(Modeled)**. For the target zone between probes, 10-25 cm cells **(Modeled)** typically provide adequate resolution.

## Data Uncertainty and Error Propagation

### Sources of Measurement Error

| Error Source | MIT Typical | ERT Typical | Mitigation |
|---|---|---|---|
| Instrument noise | 2-5% **(Target)** | 1-3% **(Target)** | Averaging, filtering |
| Electrode contact | N/A | 2-10% **(Modeled)** | Contact resistance check |
| Position uncertainty | 1-3% **(Modeled)** | 1-3% **(Modeled)** | Careful surveying |
| Temperature drift | 1-2% **(Modeled)** | 1-2% **(Modeled)** | Reference measurements |
| Reciprocity error | 2-5% **(Target)** | 2-5% **(Target)** | QC during acquisition |
| **Combined (RSS)** | **3-8% (Target)** | **3-12% (Target)** | All above measures |

: Typical measurement error sources {#tbl-error-sources}

### Assigning Data Weights

Data weights $w_i$ in the inversion are typically set as the inverse of estimated standard deviation:

$$w_i = \frac{1}{\sigma_i} = \frac{1}{\epsilon_r \cdot |d_i|}$$

Where $\epsilon_r$ is the relative error (typically 3-5% **(Target)** for HIRT) and $d_i$ is the measured datum.

### Model Resolution and Covariance

The relationship between data uncertainty and model uncertainty is governed by the model resolution matrix:

$$\mathbf{R} = (\mathbf{J}^T \mathbf{W} \mathbf{J} + \lambda \mathbf{R}_m^T \mathbf{R}_m)^{-1} \mathbf{J}^T \mathbf{W} \mathbf{J}$$

The diagonal elements indicate how well each model parameter is resolved by the data.

The model parameter covariance matrix is:

$$\mathbf{C}_m = (\mathbf{J}^T \mathbf{W} \mathbf{J} + \lambda \mathbf{R}_m^T \mathbf{R}_m)^{-1} \sigma_d^2$$

### Practical Uncertainty Assessment

**Step 1: Assign Data Weights**

- Start with uniform 5% **(Target)** relative error assumption
- Increase weights for measurements with poor reciprocity (>5%)
- Decrease weights for repeated measurements that show consistency

**Step 2: Run Multiple Inversions (Ensemble Approach)**

1. Add Gaussian noise to measured data: $d_i^{(k)} = d_i + N(0, \sigma_i)$
2. Invert each perturbed dataset independently
3. Compute mean and standard deviation across ensemble

Minimum recommended: 20 realizations **(Modeled)**; robust estimate: 50-100 realizations **(Modeled)**.

**Step 3: Calculate DOI Index**

The Depth of Investigation (DOI) index identifies regions where inversion results are constrained by data vs. dominated by regularization:

1. Run inversion with two different reference models (e.g., 10× and 0.1× background)
2. DOI = (m_1 - m_2) / (m_ref1 - m_ref2)
3. DOI < 0.1 **(Modeled)**: Well-constrained by data
4. DOI > 0.3 **(Modeled)**: Poorly constrained, regularization-dominated

**Step 4: Report Uncertainty with Results**

- Estimated parameter uncertainty (from ensemble or covariance analysis)
- DOI map showing sensitivity coverage
- Confidence level assignment:
  - HIGH: Feature in >90% of realizations, DOI < 0.1 **(Modeled)**
  - MEDIUM: Feature in 70-90% of realizations, DOI < 0.2 **(Modeled)**
  - LOW: Feature in 50-70% of realizations, or DOI > 0.2 **(Modeled)**

::: {.callout-important}
## Reporting Uncertainty is Mandatory

Tomographic images without uncertainty estimates can be misleading. A sharp-looking anomaly in a region with poor sensitivity (high DOI) may be an artifact. Always report uncertainty alongside interpretation.
:::

## Irregular Array Handling

### Key Principle: Inversion Uses Actual Positions

Modern inversion algorithms (SimPEG, pyGIMLi, EIDORS) construct the sensitivity matrix from **actual electrode positions**, not idealized grid coordinates:

- A probe offset by 30 cm **(Modeled)** is correctly incorporated if its position is accurately recorded
- Irregular spacing does not inherently degrade inversion quality
- **Accurate position documentation** is more important than perfect grid geometry

### Impact of Array Irregularities

| Condition | Impact on Coverage | Impact on Resolution | Mitigation |
|---|---|---|---|
| Probe offset <0.5 m **(Modeled)** | Minimal | Negligible | Record actual position |
| Probe offset 0.5-1.0 m **(Modeled)** | Minor asymmetry | Slight reduction | Document reason |
| Missing probe | Reduced ray coverage | Lower resolution in gap | Report reduced confidence |
| Partial depth (>50%) | Upper sensors valid | Normal for shallow | Exclude below-tip sensors |
| Partial depth (<50%) | Limited value | Significantly reduced | Consider omitting |
| Surface topography >0.5 m **(Modeled)** | Requires mesh adjustment | Minor if accounted for | Use actual Z coordinates |

: Impact of array irregularities (from sensitivity analysis) {#tbl-irregularity-impact}

### Handling Missing Probes

**Coverage Effects:**
- Ray paths through gap have reduced density
- Anomalies within gap may be under-resolved
- Edge effects extend ~1 spacing distance **(Modeled)** into covered area

**Mitigation Strategies:**
1. Add extra probes on opposite side of gap if possible
2. Extend adjacent survey sections for overlap
3. Supplement with surface methods (GPR, magnetometry) over gap

### Partial-Depth Probe Processing

1. **Record actual tip depth** in survey geometry file
2. **Identify valid sensors:** Only electrodes above tip contribute
3. **Configure inversion:** Exclude positions below z_tip
4. **Adjust sensitivity weights:** Partial probe provides reduced coverage

## Resolution Limits

### Lateral Resolution

Lateral resolution depends on probe spacing and measurement density. HIRT can resolve features with dimensions approximately 0.5 to 1.5 times **(Modeled)** the probe spacing.

| Probe Spacing | Minimum Feature (Modeled) | Practical Resolution (Modeled) |
|---|---|---|
| 1.0 m | 0.5 m | 0.75-1.0 m |
| 1.5 m | 0.75 m | 1.0-1.5 m |
| 2.0 m | 1.0 m | 1.5-2.0 m |

: Lateral resolution limits {#tbl-lateral-resolution}

### Depth Resolution

**MIT Depth Resolution:** Controlled by frequency. Approximately:

$$\Delta z_{MIT} \approx 0.5 \sqrt{\frac{2}{\omega \mu_0 \sigma}}$$

For 5 kHz in 10 mS/m soil, this yields approximately 0.5-0.8 m **(Modeled)** vertical resolution.

**ERT Depth Resolution:** Depends on electrode spacing. With 0.5 m vertical spacing, features separated by less than 0.25-0.5 m **(Modeled)** vertically will blur.

### Resolution Degradation with Depth

Below the probe tips, sensitivity falls approximately exponentially:

- **0-0.5 m below tip:** Resolution degrades by ~30% **(Modeled)**
- **0.5-1.0 m below tip:** Resolution degrades by ~60% **(Modeled)**
- **>1.0 m below tip:** Detection unreliable **(Modeled)**

::: {.callout-warning}
## Do Not Extend Inversions Beyond Probe Depth

While mathematically possible, results below the probe tips are highly uncertain and often artifacts. Report survey depth as probe insertion depth, not inversion mesh extent.
:::

## The Non-Uniqueness Problem

Geophysical inversion suffers from a fundamental limitation: multiple different subsurface models can produce nearly identical measured data.

### Why Results Are "Most Likely" Not "Certain"

The inverse problem is underdetermined. The number of model parameters (thousands of mesh cells) greatly exceeds the number of independent measurements (hundreds of probe pairs). Regularization forces preference for smooth models, introducing bias.

**Practical Implication:** A tomogram showing a high-conductivity anomaly at 2.5 m **(Modeled)** depth could represent:

- A single large metallic object
- Multiple smaller objects distributed over depth
- A conductive soil layer combined with smaller metal
- Any combination producing the same integrated response

### Mitigating Non-Uniqueness

- **Site history:** Expected target types constrain interpretation
- **Geological context:** Soil type informs background model
- **Multi-modal fusion:** MIT and ERT together reduce ambiguity
- **Depth constraints:** Targets below probe depth are highly uncertain

## MIT+ERT Data Fusion

### Fusion Approaches

**1. Sequential Interpretation (Recommended)**

1. Invert MIT data --> conductivity tomogram
2. Invert ERT data --> resistivity tomogram
3. Identify anomalies independently
4. Cross-reference anomaly locations
5. Classify based on combined signature

**2. Joint Inversion (Advanced)**

- Simultaneous inversion with structural coupling
- Shared mesh encourages consistent boundaries
- Requires careful data weighting

**3. Probability Fusion (Decision Support)**

1. Generate probability maps for each modality
2. Combine using Bayesian framework
3. Output: unified probability map for prioritization

### Fusion Artifacts

**Registration Errors:** Verify grid alignment before fusion.

**Resolution Mismatch:** A small metal object may appear tight in MIT but smeared in ERT.

**Depth Discrepancy:** Same target may appear at slightly different depths. Allow ±0.5 m **(Modeled)** tolerance.

## Forward Modeling Examples {#sec-forward-examples}

The following synthetic examples demonstrate expected HIRT responses for the four primary validation scenarios. These provide baseline expectations for field data interpretation and serve as test cases for inversion software development.

### Scenario 1: Aluminum Bomb Body (MIT Response)

A 500 lb bomb casing (aluminum, 0.36 m diameter, 1.2 m length) buried at 3.0 m depth in moderately conductive soil (σ = 20 mS/m).

**MIT forward model parameters:**
- TX coil: 50-turn, 10 mm dia, driven at 10 kHz, 50 mA
- Probe configuration: 8 probes at 1.5 m spacing, 3.0 m insertion depth
- Target conductivity: σ_Al = 3.77 × 10⁷ S/m
- Induced eddy current moment scales with σ × volume × ω × B_primary **(Modeled)**

**Expected responses:**
- TX-RX pairs straddling the target: amplitude perturbation ~0.1-1% of primary field **(Modeled)**
- Phase shift: 5-15° from purely reactive (indicates conductive target) **(Modeled)**
- Spatial pattern: maximum response for ray paths passing through target center
- The aluminum casing produces strong eddy currents detectable by MIT but invisible to magnetometry

### Scenario 2: Grave Shaft (ERT Response)

A 0.6 × 2.0 m grave shaft, 0.3-1.5 m depth, backfilled with disturbed soil (ρ = 30 Ω·m in host soil of ρ = 100 Ω·m).

**ERT forward model parameters:**
- 12 probes at 1.0 m spacing, 1.5 m insertion depth
- Ring electrodes at 0.5 m intervals (3 per probe)
- Wenner-alpha and dipole-dipole measurement sequences

**Expected responses:**
- Resistivity anomaly: -70% contrast (30 Ω·m vs 100 Ω·m) **(Modeled)**
- Detectable with crosshole geometry to 1.5 m depth with 1.5 m probes **(Modeled)**
- Surface ERT would show diffuse, poorly resolved anomaly at this depth
- Crosshole ERT resolves shaft dimensions to ±0.3 m lateral, ±0.2 m vertical **(Modeled)**

### Scenario 3: Scattered Metallic Debris (Combined MIT + ERT)

Multiple small metal fragments (0.05-0.2 m) scattered in a 5 m diameter zone at 1-3 m depth, typical of a bomb crater with fragmentation.

**Expected responses:**
- MIT: Multiple small anomalies, individually weak but clustered spatially **(Modeled)**
- ERT: Disturbed soil zone visible as resistivity anomaly; individual fragments too small to resolve **(Modeled)**
- Combined interpretation: MIT locates metal, ERT maps disturbance extent — together they reconstruct the crater fill pattern **(Modeled)**

### Scenario 4: Heterogeneous Crater Fill

A 10 m diameter bomb crater filled with mixed rubble, soil, water-saturated zones, and void spaces. Host soil: 80 Ω·m. Fill: 15-200 Ω·m (heterogeneous).

**Expected responses:**
- ERT: Complex resistivity pattern reflecting fill heterogeneity **(Modeled)**
- MIT: Metal fragments produce discrete anomalies within the broader fill **(Modeled)**
- This is the most challenging scenario — requires 3D joint inversion to interpret correctly
- Minimum recommended configuration: 16 probes, 2.0 m spacing, 3.0 m depth **(Modeled)**

::: {.callout-note}
## Validation Status
All forward modeling examples above are **(Modeled)** based on analytical approximations and published results for comparable geometries. Full numerical forward modeling using SimPEG or pyGIMLi is planned for Phase 2 development and will upgrade these claims to **(Modeled — Numerical)** with quantitative response values.
:::

## Software Compatibility

HIRT data can be processed with standard open-source inversion frameworks:

- **SimPEG (Python):** MIT and ERT inversion with flexible mesh handling
- **pyGIMLi (Python):** Excellent crosshole ERT support, joint inversion
- **EIDORS (Matlab/Octave):** MIT reconstruction, biomedical heritage
- **ResIPy (Python):** User-friendly ERT inversion wrapper
- **bh_tomo (MATLAB, GNU license):** Specifically designed for borehole/crosshole tomography. Provides ray-path computation (straight and curved), crosshole geometry handling, and constrained inversion with anisotropy support. Directly applicable to HIRT's crosshole ERT channel. [GitHub](https://github.com/groupeLIAMG/bh_tomo)

### Crosshole-Specific Software

For HIRT's crosshole geometry, **bh_tomo** from the LIAMG group (Ecole Polytechnique de Montreal) deserves special mention. Unlike general-purpose inversion packages that were designed primarily for surface arrays, bh_tomo was built from the ground up for borehole/crosshole tomography. Key features relevant to HIRT:

- **Ray-path computation:** Handles both straight-ray and curved-ray (refraction) geometries
- **Crosshole geometry:** Native support for the source-receiver configurations used in crosshole surveys
- **Tomographic inversion:** SIRT, LSQR, and constrained inversion methods
- **Anisotropy support:** Can model directional property variations
- **Data types:** Supports both traveltime (seismic/radar) and amplitude datasets

While bh_tomo was originally developed for georadar and seismic crosshole tomography, its algorithms for handling crosshole geometry and ray-based inversion are directly transferable to ERT data processing.

See [Developer: Data Formats](../developer/data-formats.qmd) for file format specifications.

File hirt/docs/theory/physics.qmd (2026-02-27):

---
title: "Physics Theory"
---

## Overview {#sec-physics-overview}

The HIRT system combines two complementary geophysical sensing modalities: Magneto-Inductive Tomography (MIT-3D) and Electrical Resistivity Tomography (ERT-Lite). Understanding the physics underlying each method is essential for proper system deployment, frequency selection, and data interpretation. This section provides a practical, field-level treatment of the relevant physics principles.

## MIT-3D (Low-Frequency Electromagnetic) {#sec-mit-physics}

### Operating Principle {#sec-mit-principle}

MIT-3D uses oscillating magnetic fields to detect conductive anomalies in the subsurface. A transmit (TX) coil drives a stable sinusoidal current at frequencies between 2-50 kHz, generating a primary magnetic field. When this field encounters conductive material---such as metal objects or high-conductivity soil zones---it induces eddy currents within the conductor.

These eddy currents generate a secondary magnetic field that opposes the primary field. Receive (RX) coils positioned at known distances from the TX coil measure the combined field. The presence of conductive targets manifests as measurable changes in both the **amplitude** and **phase** of the received signal relative to the transmitted waveform.

```{python}
#| label: fig-tx-rx-waveforms
#| fig-cap: "TX and RX waveform comparison at 10 kHz. The transmitted signal (top) induces a received signal (bottom) that is both attenuated and phase-shifted. The amplitude ratio and phase lag encode information about the conductivity and geometry of subsurface targets along the TX-RX path."
#| fig-width: 9
#| fig-height: 5

import sys; sys.path.insert(0, '..') if '..' not in sys.path else None
from diagrams.physics import create_tx_rx_waveforms
import matplotlib.pyplot as plt
from PIL import Image

buf = create_tx_rx_waveforms()
img = Image.open(buf)
plt.figure(figsize=(9, 5))
plt.imshow(img)
plt.axis('off')
plt.tight_layout()
plt.show()
```

### Frequency Selection {#sec-frequency-selection}

Operating frequency determines the trade-off between depth penetration and near-surface sensitivity:

- **Lower frequency (2-10 kHz)**: Deeper penetration, better for targets at 2.5-4+ meters
- **Higher frequency (20-50 kHz)**: Sharper sensitivity near probes, better for 0.5-1.5 meter targets
- **Multi-frequency sweep**: Recommended for unknown target depths; provides spectral discrimination

| Target Depth | Recommended Frequencies | Integration Time |
|---|---|---|
| 0.5-1.5 m (shallow) | 20-50 kHz | 1-3 sec |
| 1.5-2.5 m (mid-range) | 10-20 kHz | 3-5 sec |
| 2.5-4 m (deep) | 2-10 kHz | 5-15 sec |
| >4 m (very deep) | 2-5 kHz | 10-30 sec |

: Target-dependent frequency selection guidelines **(Target)**. Higher frequencies provide sharper near-surface resolution while lower frequencies enable deeper penetration. Integration times are design targets for achieving adequate SNR. {#tbl-frequency-selection}
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

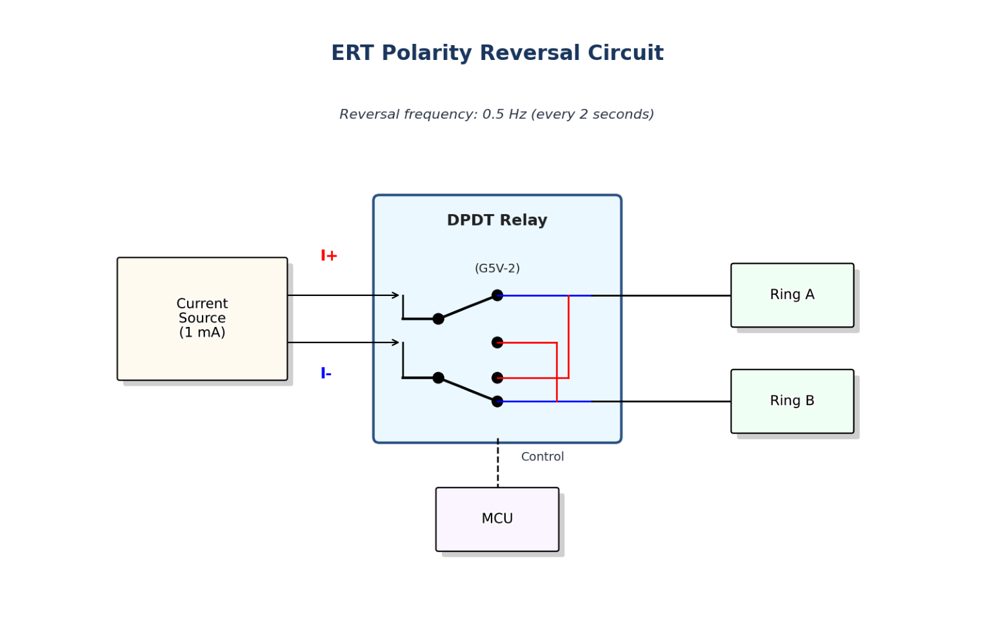
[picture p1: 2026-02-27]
hirt/docs/_freeze/build-guide/electronics/figure-pdf/fig-polarity-reversal-output-1.png

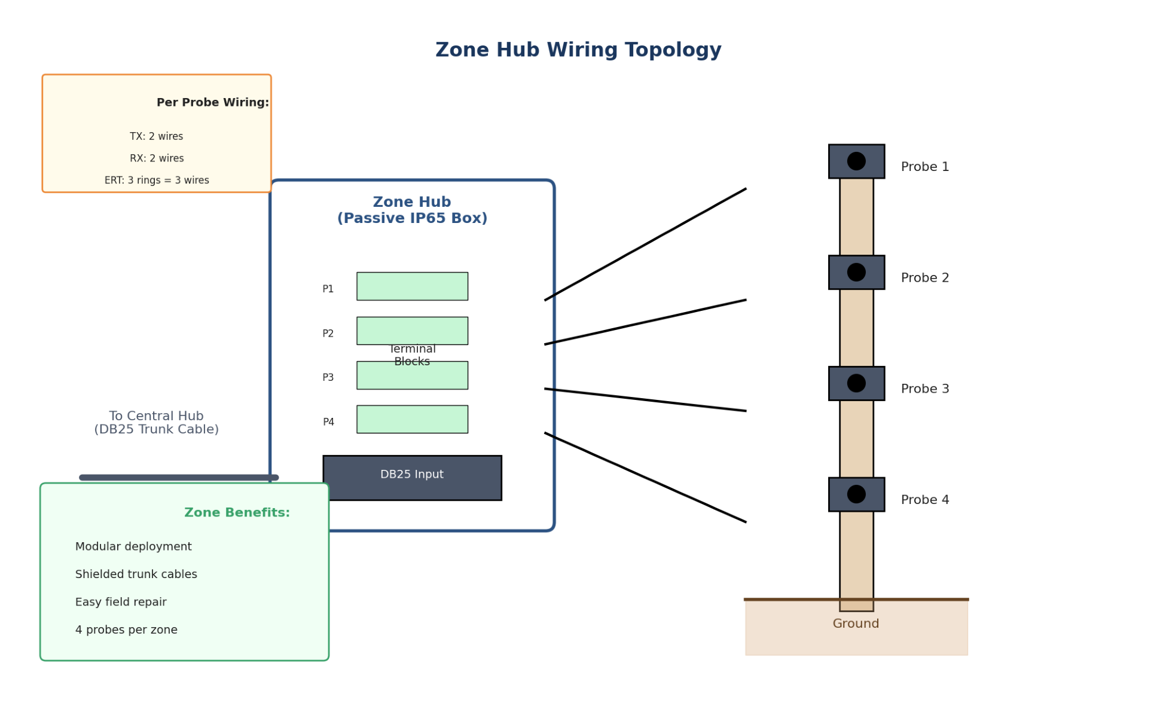
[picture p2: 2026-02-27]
hirt/docs/_freeze/theory/architecture/figure-pdf/fig-zone-topology-output-1.png

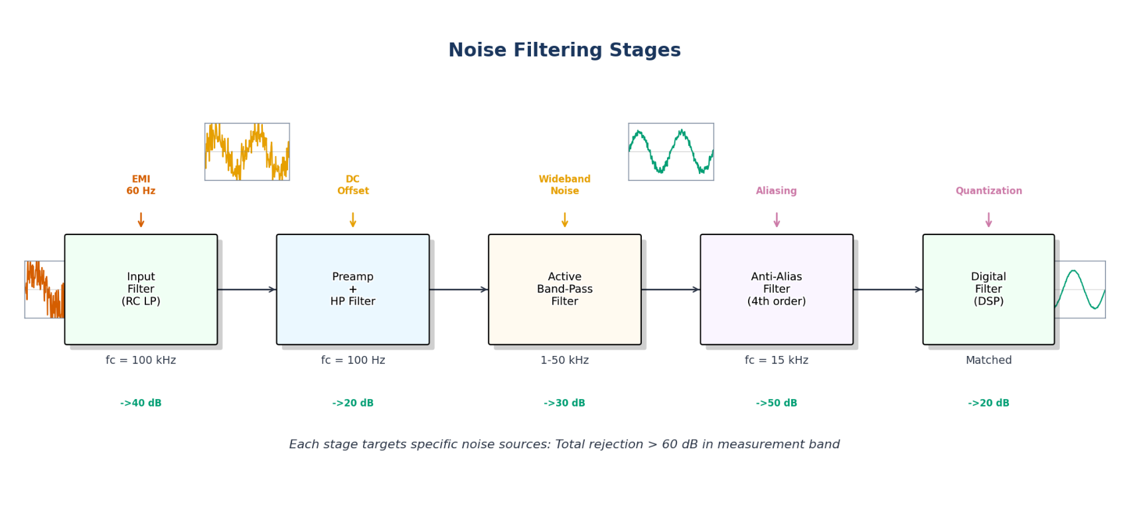
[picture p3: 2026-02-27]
hirt/docs/_freeze/build-guide/electronics/figure-html/fig-noise-filtering-output-1.png

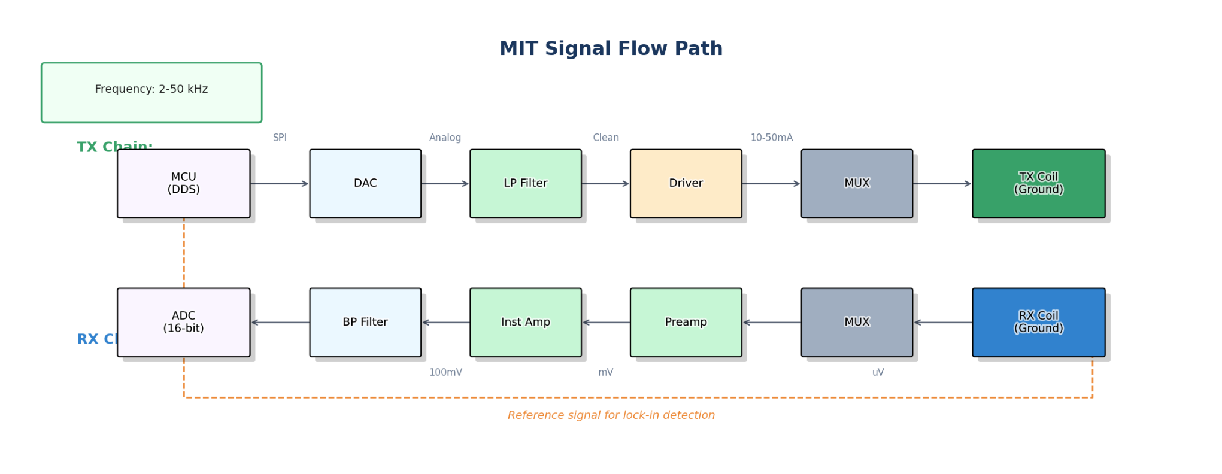
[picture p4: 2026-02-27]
hirt/docs/_freeze/theory/architecture/figure-html/fig-mit-signal-flow-output-1.png

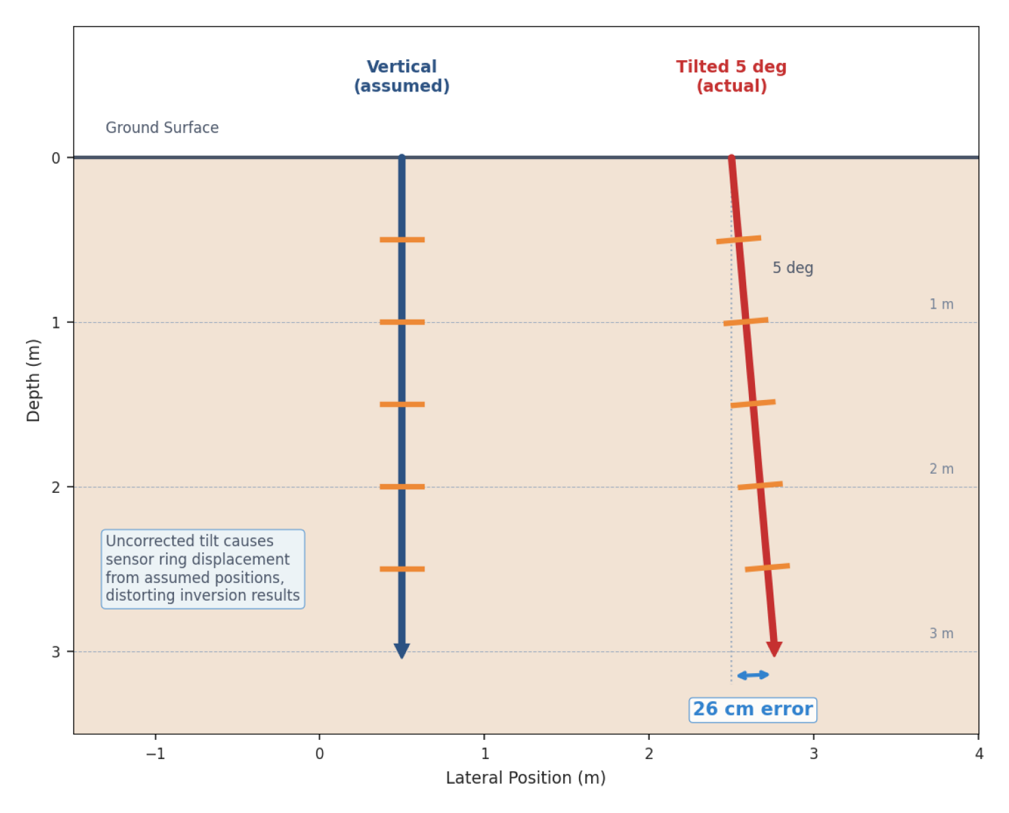
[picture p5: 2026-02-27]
hirt/docs/_freeze/theory/sensor-modalities/figure-html/fig-tilt-error-output-1.png

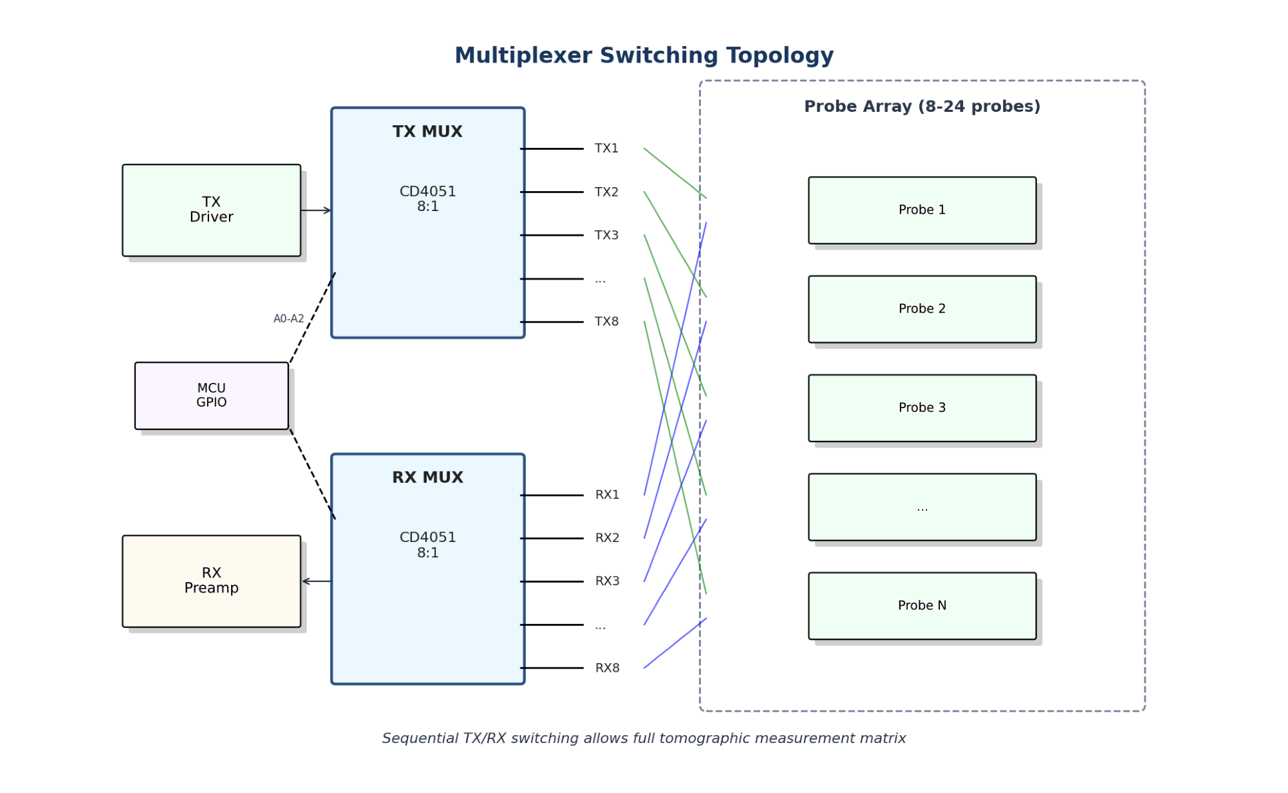
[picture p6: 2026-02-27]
hirt/docs/_freeze/build-guide/electronics/figure-html/fig-mux-switching-output-1.png

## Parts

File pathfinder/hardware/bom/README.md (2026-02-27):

# Pathfinder Bill of Materials

Complete parts list for building the Pathfinder 4-pair fluxgate gradiometer.
**Estimated total cost: $622 - $818**

*Generated from `pathfinder-bom.csv` by `generate_bom.py`.*

## Sensors ($436 - $464)

| Item | Spec | Qty | Unit Cost | Ext. Cost | Supplier | Notes |
|---|---|----:|---:|---:|---|---|
| Fluxgate sensor | FG Sensors FG-3+ (frequency output) | 8 | $52.00-54.00 | $416.00-432.00 | FG Sensors, SparkFun | Primary recommendation; requires LM2917 F-to-V conversion |
| LM2917 F-to-V converter | LM2917N-8 frequency-to-voltage IC | 8 | $2.00-3.00 | $16.00-24.00 | Mouser, DigiKey | Signal conditioning for FG-3+ frequency output |
| F-to-V support components | Resistors, capacitors per LM2917 datasheet | 8 | $0.50-1.00 | $4.00-8.00 | Mouser, DigiKey | Per-channel: timing R/C + output filter |

## Electronics ($33 - $76)

| Item | Spec | Qty | Unit Cost | Ext. Cost | Supplier | Notes |
|---|---|----:|---:|---:|---|---|
| Arduino Nano | ATmega328P 5V/16MHz | 1 | $5.00-25.00 | $5.00-25.00 | Arduino Store, AliExpress | Clone ~$5; genuine ~$25 |
| ADS1115 ADC module | 16-bit I2C ADC breakout | 2 | $4.00-6.00 | $8.00-12.00 | Adafruit, AliExpress | 4 channels each; 0x48 and 0x49 |
| NEO-6M GPS module | UART GPS with antenna | 1 | $10.00-18.00 | $10.00-18.00 | AliExpress, Amazon | Includes ceramic patch antenna |
| SD card module | SPI microSD breakout | 1 | $3.00-6.00 | $3.00-6.00 | Adafruit, AliExpress | FAT32 formatted card required |
| microSD card | Class 10 8-32 GB FAT32 | 1 | $5.00-10.00 | $5.00-10.00 | Any retailer |  |
| Piezo buzzer | Passive 5V piezo or magnetic buzzer | 1 | $1.00-3.00 | $1.00-3.00 | Mouser, AliExpress | Pace beeper |
| Status LED | 5mm red LED | 1 | $0.10-0.50 | $0.10-0.50 | Mouser, AliExpress |  |
| 220 ohm resistor | 1/4W through-hole | 1 | $0.05-0.10 | $0.05-0.10 | Mouser, DigiKey | LED current limiter |
| 2N7000 MOSFET | N-channel TO-92 | 1 | $0.30-0.60 | $0.30-0.60 | Mouser, DigiKey | Buzzer driver |
| 10k ohm resistor | 1/4W through-hole | 2 | $0.05-0.10 | $0.10-0.20 | Mouser, DigiKey | MOSFET gate pulldown + bias |
| 4.7k ohm resistor | 1/4W through-hole | 2 | $0.05-0.10 | $0.10-0.20 | Mouser, DigiKey | I2C pullups (if not on ADS1115 modules) |
| 0.1uF ceramic capacitor | Bypass caps | 4 | $0.05-0.10 | $0.20-0.40 | Mouser, DigiKey | One per ADS1115 + one per sensor power rail |

## Power ($20 - $43)

| Item | Spec | Qty | Unit Cost | Ext. Cost | Supplier | Notes |
|---|---|----:|---:|---:|---|---|
| LiPo battery | 7.4V 2S 2000-3000 mAh | 1 | $15.00-30.00 | $15.00-30.00 | HobbyKing, Amazon | Belt-mounted; use LiPo-safe bag |
| 5V buck converter | LM2596-based module >600mA | 1 | $3.00-8.00 | $3.00-8.00 | AliExpress, Amazon | Preferred over linear 7805 for efficiency |
| Power switch | SPST toggle or rocker | 1 | $1.00-3.00 | $1.00-3.00 | Hardware store | Panel-mount |
| XT60 or JST connector | Battery connector pair | 1 | $1.00-2.00 | $1.00-2.00 | HobbyKing, Amazon | Match battery connector |

## Frame ($67 - $109)

| Item | Spec | Qty | Unit Cost | Ext. Cost | Supplier | Notes |
|---|---|----:|---:|---:|---|---|
| Carbon fiber tube | 25mm OD x 2mm wall x 2m | 1 | $35.00-45.00 | $35.00-45.00 | DragonPlate, RockWest | Primary crossbar; aluminum EMT 1.25in is $15 budget alt |
| PVC conduit | 3/4in Schedule 40 x 50cm | 4 | $1.50-2.50 | $6.00-10.00 | Hardware store | Sensor drop tubes |
| 3D-printed sensor clips | PLA/PETG clip mounts | 8 | $1.50-3.00 | $12.00-24.00 | Self-printed or Shapeways | Top + bottom sensor mounts |
| End caps | 3D-printed crossbar end caps | 4 | $0.50-1.50 | $2.00-6.00 | Self-printed |  |
| M5 x 60mm bolts + locknuts | Stainless steel | 4 | $0.75-1.25 | $3.00-5.00 | Hardware store | Drop tube attachment |
| Nylon spacers | M5 ID x 10mm | 4 | $0.50-1.00 | $2.00-4.00 | Hardware store |  |
| Center mount D-ring | 25mm stainless | 1 | $2.00-4.00 | $2.00-4.00 | Hardware store | Harness attachment point |
| Pipe clamp collar | 25mm | 1 | $2.00-5.00 | $2.00-5.00 | Hardware store | Center reinforcement |
| Foam padding sheet | Self-adhesive 5mm EVA | 1 | $3.00-6.00 | $3.00-6.00 | Hardware store | Sensor cushioning |

## Harness ($12 - $36)

| Item | Spec | Qty | Unit Cost | Ext. Cost | Supplier | Notes |
|---|---|----:|---:|---:|---|---|
| Shoulder straps | Padded 50mm wide (salvaged from backpack) | 1 | $0.00-10.00 | $0.00-10.00 | Salvaged or outdoor store |  |
| Bungee cord | 6mm diameter x 1m | 1 | $2.00-4.00 | $2.00-4.00 | Hardware store | Vibration isolation |
| Carabiners | 5kN rated spring-gate | 4 | $2.00-4.00 | $8.00-16.00 | Hardware store | Quick-release connections |
| D-rings | 25mm stainless | 2 | $0.75-1.50 | $1.50-3.00 | Hardware store | Harness attachment |
| Spreader bar | 20cm aluminum rod | 1 | $1.00-3.00 | $1.00-3.00 | Hardware store |  |

## Enclosure ($21 - $36)

| Item | Spec | Qty | Unit Cost | Ext. Cost | Supplier | Notes |
|---|---|----:|---:|---:|---|---|
| IP65 enclosure | Hammond 1554K or equivalent ~150x100x50mm | 1 | $12.00-18.00 | $12.00-18.00 | Mouser, Amazon | Electronics housing |
| PG7 cable glands | Waterproof cable entry | 2 | $1.50-3.00 | $3.00-6.00 | Mouser, Amazon | Sensor cable + power entry |
| Gore-Tex vent | Pressure equalization | 1 | $2.00-4.00 | $2.00-4.00 | Mouser, Amazon | Prevents condensation |
| Velcro straps | 25mm x 30cm | 2 | $1.50-3.00 | $3.00-6.00 | Hardware store | Belt mounting |
| M3 standoffs | 10mm nylon M3 | 8 | $0.15-0.30 | $1.20-2.40 | Mouser, Amazon | PCB mounting |

## Cables ($32 - $54)

| Item | Spec | Qty | Unit Cost | Ext. Cost | Supplier | Notes |
|---|---|----:|---:|---:|---|---|
| 4-conductor shielded cable | 22-24 AWG shielded | 15 | $0.80-1.20 | $12.00-18.00 | Mouser (per meter) | Sensor connections |
| JST-XH 4-pin connector sets | Male + female pairs | 10 | $0.50-1.00 | $5.00-10.00 | Mouser, AliExpress | Sensor cable connectors |
| Spiral cable wrap | 10mm diameter | 2 | $2.00-3.00 | $4.00-6.00 | Hardware store | Per meter; cable management |
| Heat shrink tubing kit | Assorted sizes | 1 | $4.00-6.00 | $4.00-6.00 | Mouser, Amazon |  |
| Cable ties UV-resistant | 200mm nylon | 50 | $0.04-0.08 | $2.00-4.00 | Hardware store |  |
| Label tape | Self-laminating wire labels | 1 | $5.00-10.00 | $5.00-10.00 | Brady, Amazon | Sensor identification |

## Cost Summary

| Category | Low | High |
|---|----:|-----:|
| Sensors | $436 | $464 |
| Electronics | $33 | $76 |
| Power | $20 | $43 |
| Frame | $67 | $109 |
| Harness | $12 | $36 |
| Enclosure | $21 | $36 |
| Cables | $32 | $54 |
| **Total** | **$622** | **$818** |

## Substitution Notes

- **Crossbar**: Aluminum EMT conduit 1.25" (~$15) is a viable budget substitute for carbon fiber (~$40)
- **Arduino Nano**: Clones from AliExpress (~$5) work identically to genuine (~$25)
- **Shoulder straps**: Salvaging from an old backpack saves $10-15
- **3D-printed parts**: Can be ordered from Shapeways/JLCPCB if no printer available
- **Fluxgate sensors**: The FG-3+ is recommended; Magnetometer-Kit.com FGM-3 PRO is a compatible alternative at ~20% higher cost

## Source Data

This file was generated from `pathfinder-bom.csv`. To regenerate after editing the CSV:
```bash
python generate_bom.py -o README.md
```

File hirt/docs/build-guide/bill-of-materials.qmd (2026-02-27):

---
title: "Bill of Materials"
---

## Overview {#sec-bom-overview}

This section provides comprehensive bills of materials (BOMs) for building the HIRT system, including per-probe components, base hub components, and shared equipment. The micro-probe design (16mm OD, passive probes) minimizes cost while maintaining measurement quality.

The modular architecture allows builders to scale the system from a minimal single-probe test setup to full 25+ probe arrays. Component selection prioritizes availability, cost-effectiveness, and ease of assembly while meeting performance specifications.

::: {.callout-tip}
## Hardware Documentation Reference

Detailed, up-to-date BOMs with specific part numbers are maintained in the hardware documentation:

- **Probe BOM:** `/hardware/bom/probe-bom.md` - Per-probe components, costs, and procurement tips
- **Base Hub BOM:** `/hardware/bom/base-hub-bom.md` - Central electronics components with detailed specifications
- **Shared Components:** `/hardware/bom/shared-components-bom.md` - Common components used across multiple assemblies
- **Procurement Guide:** `/hardware/bom/PROCUREMENT.md` - Supplier recommendations and ordering strategies

The tables in this section summarize the BOMs; refer to the hardware documentation for exact part numbers and current pricing.
:::

## Cost Summary {#sec-cost-summary}

## System Cost Estimate (20-Probe Array)

The following table presents the estimated cost ranges for a complete 20-probe HIRT system based on 2026 manufacturing projections.

| Category | Cost Range | Notes |
|---|---|---|
| Probes (20 units) | $840-1,100 | CNC Delrin/Nylon mechanics |
| Electronics (Hubs) | $450-600 | 3x Hubs (active architecture) |
| Cabling | $300-400 | Trunk + Extensions |
| Assembly Labor | $600-800 | In-house @ $30/hr |
| Contingency | $300-400 | Buffer for price hikes |
| **Total** | **$2,150-2,850** | **~$125 per probe** |

: 20-Probe HIRT System Cost Estimate **(Target, 2026 projection)** {#tbl-system-cost}

::: {.callout-warning}
## 2026 Supply Chain Alert: Semiconductor Price Hike

**Critical:** Analog Devices (ADI) has announced a **10-30% price increase** effective February 1, 2026. This affects key components including the AD8421, AD9837, and AD7124. Builders are strongly advised to procure these silicon components immediately to lock in current pricing.
:::

```{python}
#| label: fig-cost-breakdown
#| fig-cap: "Cost distribution for a 25-probe HIRT system showing the relative investment in each component category. Probes represent the largest expense due to quantity."
#| code-fold: true

import matplotlib.pyplot as plt
import numpy as np

# Cost categories with mid-range estimates
categories = ['Probes\n(25 units)', 'Base Hub', 'Cables/\nConnectors',
              'Tools/\nEquipment', 'Consumables']
costs = [2000, 375, 500, 750, 150]
total = sum(costs)

# Colors
colors = ['#3182ce', '#38a169', '#ed8936', '#63b3ed', '#805ad5']

fig, ax = plt.subplots(figsize=(8, 5))

# Explode the largest segment slightly
explode = (0.05, 0, 0, 0, 0)

# Create pie chart
wedges, texts, autotexts = ax.pie(
    costs,
    explode=explode,
    labels=categories,
    colors=colors,
    autopct=lambda pct: f'${int(pct/100*total):,}\n({pct:.1f}%)',
    startangle=90,
    pctdistance=0.65,
    labeldistance=1.15
)

# Style the text
for text in texts:
    text.set_fontsize(9)
    text.set_fontweight('bold')
for autotext in autotexts:
    autotext.set_fontsize(8)
    autotext.set_color('white')
    autotext.set_fontweight('bold')

# Add center circle for donut effect
center_circle = plt.Circle((0, 0), 0.35, fc='white')
ax.add_patch(center_circle)

# Add total in center
ax.text(0, 0.05, 'Total', ha='center', va='center', fontsize=10, fontweight='bold')
ax.text(0, -0.12, '~$3,775', ha='center', va='center', fontsize=12, fontweight='bold')

ax.set_title('25-Probe HIRT System Cost Distribution', fontsize=12, fontweight='bold', pad=15)

plt.tight_layout()
plt.show()
```

## Cost Per Probe Breakdown

Each passive probe consists of mechanical, sensing, and interconnection components. The following breakdown shows typical costs for a single probe unit.

| Component | Cost |
|---|---|
| Mechanical (rod, tip, coupler) | $35-55 |
| ERT (rings, collars) | $5-10 |
| Coils (ferrite, wire) | $10-15 |
| Short Cable (1m) | $10-15 |
| Hardware (epoxy, o-rings) | $5-10 |
| **Total per probe** | **$70-120** |

: Per-Probe Cost Breakdown (Passive Design) **(Target)** {#tbl-probe-cost}

## Cost Reduction Options

- **Bulk ordering:** 20%+ savings on quantities >50 units
- **Local sourcing:** Reduce shipping costs for common components
- **Simpler design:** Passive probes vs active for significant savings
- **DIY coils:** Wind your own coils vs purchasing pre-wound
- **Generic parts:** Use non-branded components where precision is not critical

## Manufacturing Cost Analysis {#sec-manufacturing-costs}

Detailed cost modeling for a 20-probe system reveals that electronics and probe mechanics represent the primary cost drivers. Per-board PCBA costs for the Base Hub run $145-185 per board in low-volume (5-unit) production runs **(Target, 2026 projection)**, driven largely by high-value Analog Devices silicon (AD8421, AD7124-8, AD9837) which is subject to a 10-30% price increase announced for February 2026.

CNC-machined probe components (Delrin tips and Nylon couplers) cost $3.80-6.00 per unit at 100-unit quantities **(Target)**, with costs dominated by machine time rather than material. Increasing batch sizes to 500 units could reduce mechanical costs by 30-40% through better setup amortization.

::: {.callout-tip}
## Cost Optimization Opportunity

Shrinking the Base Hub PCB from 150x100mm to 100x100mm would qualify for promotional fabrication rates at services like JLCPCB, potentially reducing bare board costs from ~$12 to ~$2 per unit. This optimization is recommended for Rev C if layout constraints permit.
:::

```{python}
#| label: fig-component-categories
#| fig-cap: "HIRT component categories showing the relationship between per-probe components, base hub electronics, shared equipment, and optional active probe upgrades."
#| code-fold: true

import matplotlib.pyplot as plt
from matplotlib.patches import FancyBboxPatch, Rectangle

fig, ax = plt.subplots(figsize=(10, 6))
ax.set_xlim(0, 10)
ax.set_ylim(0, 8)
ax.set_aspect('equal')
ax.axis('off')

# Title
ax.text(5, 7.5, 'HIRT Component Categories', ha='center', va='center',
        fontsize=14, fontweight='bold', color='#2c5282')

# Define category boxes
categories = [
    {
        'name': 'Per-Probe\nComponents',
        'x': 1.5, 'y': 5.5, 'width': 3, 'height': 1.8,
        'color': '#3182ce',
        'items': ['Mechanical (rod, tip)', 'Coils (ferrite, wire)',
                 'ERT rings/collars', 'Cable/connector']
    },
    {
        'name': 'Base Hub\nComponents',
        'x': 5.5, 'y': 5.5, 'width': 3, 'height': 1.8,
        'color': '#38a169',
        'items': ['Power system', 'ERT current source',
                 'Sync/clock', 'Control MCU']
    },
    {
        'name': 'Shared\nEquipment',
        'x': 1.5, 'y': 2.5, 'width': 3, 'height': 1.8,
        'color': '#63b3ed',
        'items': ['Test equipment', 'Tools',
                 'Consumables', 'Bulk cables']
    },
    {
        'name': 'Optional\nActive Electronics',
        'x': 5.5, 'y': 2.5, 'width': 3, 'height': 1.8,
        'color': '#ed8936',
        'items': ['MCU (ESP32)', 'DDS signal gen',
                 'Preamp/ADC', 'Custom PCB']
    }
]

for cat in categories:
    box = FancyBboxPatch(
        (cat['x'], cat['y'] - cat['height']/2),
        cat['width'], cat['height'],
        boxstyle="round,pad=0.05,rounding_size=0.15",
        facecolor=cat['color'],
        edgecolor='white',
        linewidth=2,
        alpha=0.9
    )
    ax.add_patch(box)

    ax.text(cat['x'] + cat['width']/2, cat['y'] + 0.5,
            cat['name'], ha='center', va='center',
            fontsize=10, fontweight='bold', color='white')

    item_text = '\n'.join([f'  {item}' for item in cat['items']])
    ax.text(cat['x'] + 0.15, cat['y'] - 0.1, item_text,
            ha='left', va='top', fontsize=7, color='white',
            linespacing=1.3)

# Cost annotations
cost_info = [
    (1.5, 4.7, '$60-100\nper probe'),
    (5.5, 4.7, '$300-450\ntotal'),
    (1.5, 1.7, '$500-1,000\none-time'),
    (5.5, 1.7, '+$50-80\nper probe')
]

for x, y, text in cost_info:
    ax.text(x + 1.5, y, text, ha='center', va='top',
            fontsize=8, fontweight='bold', color='#2c5282',
            bbox=dict(boxstyle='round,pad=0.3', facecolor='white',
                     edgecolor='#a0aec0', alpha=0.9))

# Connection arrows
ax.annotate('', xy=(5.5, 5.5), xytext=(4.5, 5.5),
            arrowprops=dict(arrowstyle='<->', color='#4a5568', lw=2))
ax.text(5, 5.9, 'Connects via\ncables', ha='center', va='bottom', fontsize=7,
        color='#4a5568')

# Legend
ax.text(5, 0.5,
        'Passive probes: Lower cost, simpler assembly, recommended for most applications\n'
        'Active probes: Higher performance, more complex, for demanding applications',
        ha='center', va='center', fontsize=8, style='italic', color='#718096',
        bbox=dict(boxstyle='round,pad=0.5', facecolor='#f7fafc', edgecolor='none'))

plt.tight_layout()
plt.show()
```

## Per-Probe Bill of Materials {#sec-per-probe-bom}

## Mechanical Components

| Ref | Component | Description | Qty | Unit Cost (100 qty) |
|-----|---|---|-----|---|
| ROD1 | Fiberglass Tube | 16mm OD x 12mm ID x 1.5m | 1.5 | $10.00 |
| TIP1 | Probe Tip | CNC Delrin (Acetal) | 1 | $3.80-5.50 |
| CPL1 | Rod Coupler | CNC Nylon 6/6 | 1 | $4.20-6.00 |
| JB1 | Junction Box | 3D printed PETG / CNC | 1 | $3-5 |

: Per-Probe Mechanical Components. CNC unit costs reflect 100-unit production runs via on-demand services (Xometry/Protolabs). Probe tips: $3.80-5.50/unit **(Target)**; Couplers: $4.20-6.00/unit **(Target)**. Setup costs (~$100) amortized across the batch. {#tbl-mechanical}

## Coil Components

| Ref | Component | Description | Qty | Unit Cost |
|-----|---|---|-----|---|
| L1 | Ferrite Rod | 6-8mm x 40-80mm MnZn | 1-2 | $2-5 |
| W1 | Magnet Wire | 34-38 AWG, 50m | 1 | $3-5 |

: Per-Probe Coil Components {#tbl-coils}

## ERT Components

| Ref | Component | Description | Qty | Unit Cost |
|-----|---|---|-----|---|
| R1-R3 | ERT Rings | Stainless steel 3-5mm bands | 2-3 | $1-2 ea |
| C1-C3 | Ring Collars | 3D printed PETG | 2-3 | $0.50 ea |

: Per-Probe ERT Components {#tbl-ert}

## Hardware

| Ref | Component | Description | Qty | Unit Cost |
|-----|---|---|-----|---|
| HW1 | O-Rings | M12 size, nitrile | 4 | $0.50 ea |
| HW2 | Epoxy | 2-part structural | - | $5/probe |

: Per-Probe Hardware {#tbl-hardware}

## Cable and Connectors

| Ref | Component | Description | Qty | Unit Cost |
|-----|---|---|-----|---|
| CBL1 | Shielded Cable | 6-conductor, 3-5m | 1 | $10-15 |
| CON1 | Connector | 12-pin Phoenix | 1 | $5-8 |

: Per-Probe Cable and Connectors {#tbl-cables}

::: {.callout-note}
## Total Per Passive Probe

- Estimated cost: ~$60-100 per passive probe
- Assembly time: 2-4 hours per probe
- Required skills: Basic soldering, 3D printing, mechanical assembly
:::

## Active Probe Electronics (Optional)

For applications requiring higher performance, active probes with in-probe electronics can be built. These include signal generation, amplification, and digitization circuitry.

| Ref | Component | Part Number | Qty | Unit Cost |
|-----|---|---|-----|---|
| U1 | MCU | ESP32-WROOM-32 | 1 | $5-8 |
| U2 | DDS | AD9833BRMZ | 1 | $8-12 |
| U3 | TX Op-Amp | OPA454AIDDAR | 1 | $6-10 |
| U4 | RX Preamp | AD620ARZ | 1 | $6-10 |
| U5 | Inst Amp | INA128PAG4 | 1 | $6-10 |
| U6 | ADC | ADS1256IDBR | 1 | $10-15 |
| U7 | Mux | CD4051BE | 1 | $1-2 |
| U8 | LDO | AMS1117-3.3 | 1 | $0.50 |
| PCB | Custom PCB | - | 1 | $5-10 |
| - | Passives | Resistors, caps | - | $5 |

: Active Probe Electronics (Optional Add-on) {#tbl-active}

::: {.callout-note}
Additional cost per active probe: ~$50-80. Active probes provide improved signal-to-noise ratio and reduced cable effects but require more complex assembly.
:::

## Base Hub Bill of Materials {#sec-hub-bom}

The base hub provides power distribution, synchronization, and data collection for all connected probes. One hub supports up to 25 probes.

## Power System

| Ref | Component | Part Number | Qty | Unit Cost |
|-----|---|---|-----|---|
| BAT1 | Battery | 12V 12Ah LiFePO4 | 1 | $60-100 |
| F1 | Fuse Holder | 0287005.PXCN | 1 | $3 |
| F2 | Fuse | 5A fast-blow | 5 | $1 ea |
| REG1 | 5V Regulator | LM2596 Module | 1 | $3-5 |
| REG2 | 3.3V Regulator | AMS1117-3.3 | 1 | $0.50 |
| SW1 | Power Switch | DPST 10A | 1 | $3-5 |
| TB1 | Terminal Block | Multi-position | 1 | $10-15 |

: Base Hub Power System Components {#tbl-power}

## ERT Current Source

| Ref | Component | Part Number | Qty | Unit Cost |
|-----|---|---|-----|---|
| U1 | Voltage Ref | REF5025AIDGKR | 1 | $4-6 |
| U2 | Op-Amp | OPA277PAG4 | 1 | $4-6 |
| U3 | Inst Amp | INA128PAG4 | 1 | $6-10 |
| K1 | Relay | G5V-2-H1 | 1 | $3-5 |
| R1-R4 | Precision R | 0.1% various | 10 | $0.50 ea |
| R5 | Sense R | 10 ohm 0.1% | 1 | $1 |

: ERT Current Source Components {#tbl-ert-source}

## Sync/Clock Distribution

| Ref | Component | Part Number | Qty | Unit Cost |
|-----|---|---|-----|---|
| Y1 | Oscillator | ECS-100-10-30B-TR | 1 | $3-5 |
| U1-U3 | Buffer | SN74HC244N | 3 | $1 ea |

: Sync/Clock Distribution Components {#tbl-sync}

## Communication

| Ref | Component | Part Number | Qty | Unit Cost |
|-----|---|---|-----|---|
| U1 | RS485 | MAX485ESA+ | 1 | $2-4 |
| U2 | USB-Serial | CP2102 Module | 1 | $3-5 |
| J1 | RJ45 Jack | - | 1 | $2 |

: Communication Interface Components {#tbl-comm}

## Control

| Ref | Component | Part Number | Qty | Unit Cost | Rev |
|-----|---|---|-----|---|-----|
| U1 | MCU | ESP32 DevKit | 1 | $8-12 | A/B |
| U2 | ADC | **AD7124-8BRUZ** | 1 | $12-18 | **B** |
| U2 | ADC (Legacy) | ADS1256IDBR | 1 | $10-15 | A |
| SD1 | SD Card | Micro SD module | 1 | $3-5 | A/B |

: Control System Components (Rev B uses AD7124-8) {#tbl-control}

## Enclosure and Connectors

| Ref | Component | Description | Qty | Unit Cost | Rev |
|-----|---|---|-----|---|-----|
| ENC1 | Enclosure | IP65 200x150x100mm | 1 | $30-50 | A/B |
| PG1-PG20 | Cable Glands | PG11 or M20 | 20 | $1 ea | A/B |
| CON1-CON20 | Probe Connectors | 12-pin Phoenix | 20 | $5 ea | A/B |
| CON-HUB | Hub Connector | **Weipu SP29 (26-pin)** | 2 | $15-25 ea | **B** |
| CON-HUB | Hub Connector (Legacy) | DB25 | 2 | $5 ea | A |

: Enclosure and Connector Components (Rev B uses Weipu SP29 IP68) {#tbl-enclosure}

::: {.callout-note}
## Total Base Hub Cost (2026 Estimate)

- **PCBA:** ~$145-185 per board in 5-unit runs **(Target, 2026 projection)**
  - Bare PCB: ~$12
  - Active components (ADI silicon): ~$45
  - Passive components: ~$25
  - Assembly labor: ~$20
  - Component sourcing overhead: ~$15
- **Total Unit Cost:** ~$200-250 including enclosure
- **Note:** Boards larger than 100x100mm lose promotional pricing at many fabrication services
:::

## Shared Equipment Bill of Materials {#sec-shared-bom}

## Connectors and Cables

| Ref | Component | Description | Qty | Unit Cost |
|-----|---|---|-----|---|
| CBL1 | Probe Cable | Belden 3066A 12-pair, 5m | 20 | $15 ea |
| CBL2 | Power Cable | 14 AWG 2-conductor | 10m | $10 |
| CON1 | Phoenix Headers | 12-pos pluggable | 20 | $5 ea |
| CON2 | DC Jack | 5.5x2.1mm panel | 1 | $2 |

: Shared Cables and Connectors {#tbl-shared-cables}

## Test Equipment (Recommended)

| Item | Description | Est. Cost | Notes |
|---|---|---|---|
| DMM | Digital Multimeter | $50-100 | Fluke or equivalent |
| LCR | LCR Meter | $100-300 | For coil testing |
| Scope | Oscilloscope | $300-500 | 2-ch, 50MHz min |
| PS | Bench Power Supply | $50-100 | Adjustable, current limit |

: Recommended Test Equipment {#tbl-test-equip}

## Tools

| Item | Description | Est. Cost |
|---|---|---|
| Soldering | Iron + solder | $50-100 |
| Tap/Die | M12x1.75 set | $30-50 |
| Crimpers | For connectors | $30-50 |
| Heat Gun | For shrink tubing | $30-50 |
| Hand Tools | Screwdrivers, pliers | $50 |

: Required Tools {#tbl-tools}

## Consumables

| Item | Description | Est. Cost |
|---|---|---|
| Solder | 60/40 or lead-free | $15 |
| Flux | Rosin flux | $10 |
| Heat Shrink | Assorted sizes | $15 |
| Epoxy | 2-part structural | $20 |
| Cable Ties | Assorted | $10 |
| IPA | Isopropyl alcohol | $10 |

: Consumables {#tbl-consumables}

## Procurement Guide {#sec-procurement}

## Recommended Suppliers

### Electronics

- **DigiKey** (www.digikey.com) - Wide selection, fast shipping
- **Mouser** (www.mouser.com) - Good for precision components
- **Newark** (www.newark.com) - Alternative source

### Mechanical

- **McMaster-Carr** (www.mcmaster.com) - Hardware, tubing
- **Grainger** (www.grainger.com) - Industrial supplies
- **Amazon** - General supplies

### 3D Printing

- Local print shop
- **Shapeways** (www.shapeways.com) - Online service
- **JLCPCB** (www.jlcpcb.com) - Also offers 3D printing

### PCB Fabrication

- **JLCPCB** (www.jlcpcb.com) - Low cost, fast
- **PCBWay** (www.pcbway.com) - Good quality
- **OSH Park** (oshpark.com) - US-based, quality

## Key Part Numbers Reference

### Rev B Components (Recommended)

| Component | DigiKey PN | Mouser PN | Notes |
|---|---|---|---|
| AD9833BRMZ | AD9833BRMZ-REEL | 584-AD9833BRMZ | DDS |
| **AD7124-8BRUZ** | AD7124-8BRUZ-ND | 584-AD7124-8BRUZ | **Primary ADC (Rev B)** |
| AD8421BRZ | AD8421BRZ-ND | 584-AD8421BRZ | RX preamp |
| INA188ID | INA188ID-ND | 595-INA188ID | Zero-drift preamp (optional) |
| INA128PAG4 | INA128PAG4-ND | 595-INA128PAG4 | Gain stage |
| OPA454AIDDAR | OPA454AIDDAR-ND | 595-OPA454AIDDAR | TX driver |
| REF5025AIDGKR | REF5025AIDGKR-ND | 595-REF5025AIDGKR | Voltage reference |
| ESP32-WROOM-32 | 1904-1009-1-ND | 356-ESP32-WROOM-32 | MCU |
| Weipu SP29-26 | N/A | N/A | Order direct from Weipu or AliExpress |

: Key Part Numbers for Rev B Build {#tbl-part-numbers}

### Legacy Components (Rev A)

| Component | DigiKey PN | Mouser PN | Notes |
|---|---|---|---|
| ADS1256IDBR | ADS1256IDBR-ND | 595-ADS1256IDBR | Legacy ADC (Rev A) |
| AD620ARZ | AD620ARZ-ND | 584-AD620ARZ | Legacy preamp (Rev A) |
| DB25 Connector | Various | Various | Legacy hub connector |

: Legacy Part Numbers (Rev A - Not Recommended for New Builds) {#tbl-part-numbers-legacy}

::: {.callout-warning}
## Component Revision Notice

**New builds should use Rev B components.** The AD7124-8 and Weipu SP29 provide significant improvements in power efficiency, integration, and field reliability. Legacy components are documented for maintenance of existing systems only.
:::

## Procurement Tips

1. **Order extras:** Add 10-20% for spares and mistakes
2. **Check MOQ:** Some parts have minimum order quantities
3. **Lead times:** Check availability before ordering
4. **Substitutes:** Have backup part numbers identified
5. **Consolidate:** Combine orders to reduce shipping costs

## Alternative Components {#sec-alternatives}

The following tables provide alternative component options for situations where primary components are unavailable or when different performance characteristics are desired.

## Coil Alternatives

| Original | Alternative | Notes |
|---|---|---|
| 6-8mm ferrite rod | 10mm rod | Larger = more signal, larger diameter |
| 30 AWG magnet wire | 28-34 AWG | Trade-off: turns vs resistance |

: Coil Component Alternatives {#tbl-coil-alt}

## ERT Ring Alternatives

| Original | Alternative | Notes |
|---|---|---|
| Stainless steel band | Copper tape | Lower cost, easier to work with |
| 3D printed collar | Heat shrink tube | Simpler mounting |

: ERT Ring Alternatives {#tbl-ert-alt}

## Electronics Alternatives

| Original (Rev B) | Alternative | Notes |
|---|---|---|
| AD7124-8 ADC | ADS1261 | TI ecosystem, similar integration |
| AD7124-8 ADC | ADS1256 | Legacy option, requires more external components |
| AD8421 preamp | INA188 | Zero-drift, better DC stability, higher broadband noise |
| AD9833 DDS | AD9837 | Smaller footprint (LFCSP), lower power (8.5 mW) |
| AD9833 DDS | Si5351 | More outputs, different interface |
| Weipu SP29 | CNLINKO LP-24 | Snap-lock (faster), 24 pins only |

: Electronics Alternatives {#tbl-elec-alt}

::: {.callout-note}
For assembly procedures, see @sec-assembly-overview. For mechanical specifications, see @sec-mech-overview. For electronics schematics, see @sec-electronics-overview.
:::

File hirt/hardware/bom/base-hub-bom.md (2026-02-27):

# Base Hub BOM (Bill of Materials) - Central Electronics Hub

**Central Electronics Hub** - Estimated cost: $300–600 (serves all probes)

## Design Note

**Centralized Electronics:** All electronics are at surface in central hub. Probes are passive (see [Probe BOM](probe-bom.md)). One hub serves all probes (20–24 typical).

## MIT Driver/Receiver System (2026 Modernized)

| Component | Description | Quantity | Part Number | Supplier | Unit Cost | Total Cost | Notes |
|---|---|---|---|---|---|---|---|
| DDS generator | Low-power DDS | 1 | AD9837BCPZ-REEL7 | Digi-Key | $8.00 | $8.00 | 8.5mW low-power upgrade (LFCSP) |
| TX driver | Precision Op-amp | 1 | OPA2186 | Digi-Key | $2.50 | $2.50 | Zero-drift, 90uA power (90% reduction) |
| RX preamp | Low-noise In-Amp | 1 | AD8421ARZ | Digi-Key | $9.50 | $9.50 | 3 nV/sqrt(Hz) noise floor (3x better) |
| Instrumentation amp | INA128 | 1 | INA128PAG4 | Digi-Key | $7.50 | $7.50 | Precision instrumentation amp |
| Lock-in / ADC | Integrated 24-bit AFE | 1 | AD7124-8 | Digi-Key | $12.50 | $12.50 | Integrated PGA + Ref + ADC (low power) |
| Lock-in (Legacy) | Analog multiplier AD630 | 0 | AD630ANZ | Digi-Key | $12.00 | $0.00 | Deprecated in favor of digital lock-in |
| TX multiplexer | Analog mux for TX selection | 1 | CD4051BE | Digi-Key | $1.50 | $1.50 | Select which probe TX to drive |
| RX multiplexer | Analog mux for RX selection | 1 | CD4051BE | Digi-Key | $1.50 | $1.50 | Select which probe RX to read |
| Probe Connectors | IP68 Circular 26-pin | 20 | Weipu SP29-26 | AliExpress | $8.00 | $160.00 | Waterproof replacement for DB25 |
| **Subtotal MIT System** | | | | | | **$203.00** | Includes ruggedized connectors |

## ERT System

| Component | Description | Quantity | Part Number | Supplier | Unit Cost | Total Cost | Notes |
|---|---|---|---|---|---|---|---|
| Current source op-amp | Precision op-amp OPA177 | 1 | OPA177GP | Digi-Key | $4.50 | $4.50 | Current source amplifier |
| Voltage reference | REF5025 2.5V | 1 | REF5025AIDGKT | Digi-Key | $3.50 | $3.50 | Precision 2.5V reference |
| Current sense resistor | 1.25kΩ 0.1% precision | 1 | RN73R2BTTD1251B10 | Digi-Key | $1.50 | $1.50 | For 2mA full scale |
| Polarity switch | DPDT relay 5V | 1 | G5V-2-5DC | Digi-Key | $3.50 | $3.50 | Polarity reversal |
| Relay driver | Transistor/MOSFET | 1 | 2N7002 | Digi-Key | $0.25 | $0.25 | Drive relay coil |
| Differential voltmeter | INA128 precision | 1 | INA128PAG4 | Digi-Key | $7.50 | $7.50 | High-precision diff amp |
| ERT ADC | 24-bit ADS1256 | 1 | ADS1256IDBR | Digi-Key | $18.50 | $18.50 | High resolution ADC |
| ERT multiplexer | CD4051 8-channel | 2–3 | CD4051BE | Digi-Key | $1.50 | $3–4.50 | Channel selection (ring pairs) |
| **Subtotal ERT System** | | | | | | **$43.25–45.75** | |

## Control and Data Acquisition

| Component | Description | Quantity | Part Number | Supplier | Unit Cost | Total Cost | Notes |
|---|---|---|---|---|---|---|---|
| MCU | ESP32 DevKit | 1 | ESP32-DEVKITC-32E | Adafruit/SparkFun | $10.00 | $10.00 | WiFi/Bluetooth, or ESP32-WROOM-32 |
| Voltage regulator | 3.3V LDO AMS1117 | 2 | AMS1117-3.3 | Digi-Key | $0.50 | $1.00 | 3.3V regulator |
| Voltage regulator | 5V LDO AMS1117 | 2 | AMS1117-5.0 | Digi-Key | $0.50 | $1.00 | 5V regulator |
| PCB | Perfboard or custom | 1 | — | Custom | $5–15 | $5–15 | Larger board for all electronics |
| Connectors | Headers, sockets | 1 set | Various | Digi-Key | $5–10 | $5–10 | 2.54mm pitch headers |
| **Subtotal Control** | | | | | | **$22–36** | |

## Sync/Clock Distribution

| Component | Description | Quantity | Part Number | Supplier | Unit Cost | Total Cost | Notes |
|---|---|---|---|---|---|---|---|
| Crystal oscillator | 10 MHz oscillator | 1 | ECS-100-10-30B-TR | Digi-Key | $2.50 | $2.50 | Reference clock (or use DDS) |
| Clock buffer | 74HC244 octal buffer | 1–2 | SN74HC244N | Digi-Key | $1.50 | $1.50–3 | Drive multiple outputs |
| Sync cables | Thin shielded cable | 20–24 | Custom | Digi-Key/Mouser | $1–2 | $20–48 | Sync distribution to probes |
| Connectors | Small connectors | 20–24 | Various | Digi-Key | $0.50 | $10–12 | For sync cables |
| **Subtotal Sync** | | | | | | **$34–65.50** | |

## Power System

| Component | Description | Quantity | Part Number | Supplier | Unit Cost | Total Cost | Notes |
|---|---|---|---|---|---|---|---|
| Battery | 12V 12Ah SLA | 1 | UB12120 | Digi-Key/Amazon | $25–35 | $25–35 | Sealed lead-acid, or LiFePO4 |
| Battery charger | 12V SLA charger | 1 | Various | Amazon/Digi-Key | $15–25 | $15–25 | Automatic charger |
| Fuse holder | Panel mount fuse holder | 1 | 0287005.PXCN | Digi-Key | $2.00 | $2.00 | 5A fuse holder |
| Fuses | 5A fast-blow fuses | 5 | 0034.5002 | Digi-Key | $0.50 | $2.50 | Spare fuses |
| Distribution block | Terminal block | 1 | Various | Digi-Key | $3–5 | $3–5 | Power distribution |
| Voltage regulator | 12V to 5V buck | 1 | LM2596 module | Amazon | $3–5 | $3–5 | 5V regulator module |
| **Subtotal Power** | | | | | | **$50.50–74.50** | |

## Communications/Data Logging

| Component | Description | Quantity | Part Number | Supplier | Unit Cost | Total Cost | Notes |
|---|---|---|---|---|---|---|---|
| Data logger | Raspberry Pi 4 or tablet | 1 | Various | Various | $50–200 | $50–200 | RPi4 + SD card, or Android tablet |
| RS485 transceiver | MAX485 module | 1 | MAX485ESA+ | Digi-Key | $2.50 | $2.50 | RS485 interface (if used) |
| Data cables | CAT5 or custom cable | 20–24 | Custom | Digi-Key/Mouser | $2–4 | $40–96 | Data/power cables to probes |
| Connectors | RJ45 or custom | 20–24 | Various | Digi-Key | $0.50 | $10–12 | For data cables |
| Power connectors | DC power jacks | 20–24 | PJ-002A | Digi-Key | $0.50 | $10–12 | Power connectors |
| Wireless option | LoRa module (optional) | 1 | SX1278 module | Amazon | $8–12 | $8–12 | Optional LoRa |
| **Subtotal Comms** | | | | | | **$120.50–332.50** | |

## Enclosure and Mounting

| Component | Description | Quantity | Part Number | Supplier | Unit Cost | Total Cost | Notes |
|---|---|---|---|---|---|---|---|
| Enclosure | Weatherproof box | 1 | Various | Digi-Key/Amazon | $30–60 | $30–60 | IP65 rated, ~300×200×150mm (larger for all electronics) |
| Mounting hardware | Screws, brackets | 1 set | Various | McMaster/Digi-Key | $5–10 | $5–10 | M3 screws, brackets |
| Cable management | Strain reliefs, glands | 1 set | Various | Digi-Key | $10–15 | $10–15 | PG glands, strain reliefs (more needed) |
| Terminal blocks | For probe connections | 2–3 | Various | Digi-Key | $5–10 | $10–30 | Terminal blocks for probe wiring |
| **Subtotal Enclosure** | | | | | | **$55–115** | |

## Total Base Hub Cost

| Category | Cost Range |
|---|---|
| MIT System | $56.50–66.50 |
| ERT System | $43.25–45.75 |
| Control | $22–36 |
| Sync/Clock | $34–65.50 |
| Power System | $50.50–74.50 |
| Communications/Data Logging | $120.50–332.50 |
| Enclosure and Mounting | $55–115 |
| **Total** | **$381.75–736.75** |

**Typical cost:** ~$400–600 (depending on data logger choice - RPi4 vs tablet)

## Cost Comparison

**Old Design:** $250–450 per base hub (simpler, fewer functions)
**New Design:** $400–600 per base hub (includes all probe electronics)

**Note:** While hub cost is higher, total system cost is lower because:
- Old: $130–180 per probe × 20 = $2,600–3,600 + $250–450 hub = $2,850–4,050
- New: $40–60 per probe × 20 = $800–1,200 + $400–600 hub = $1,200–1,800

**Total System Savings:** ~$1,650–2,250 (significant reduction)

## Notes

- Data logger cost varies widely (tablet vs. dedicated logger)
- Wireless option adds cost but increases flexibility
- Power system can be simplified if using USB power banks
- Some components can be integrated into single PCB (recommended)
- Consider modular design for easier upgrades
- Larger enclosure needed for all electronics

## Simplified Option

For lower cost, consider:
- Use existing laptop/tablet instead of dedicated logger: **-$100–200**
- Use USB power banks instead of large battery: **-$20–50**
- Simplified sync (wired only): **-$10–20**
- **Reduced total:** ~$270–480

## Integration Notes

- All electronics in one location (easier maintenance)
- Can use single PCB for all electronics (recommended)
- Modular design allows upgrades
- Easier troubleshooting (all electronics accessible)
- Better power management (centralized)

---

*For passive probe components, see [Probe BOM](probe-bom.md)*

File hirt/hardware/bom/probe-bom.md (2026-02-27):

# Probe BOM (Bill of Materials) - Modular Micro-Probe Design

**Per-Probe Components** - Estimated cost: $30–55 per probe (passive design)

## Design Note

**Micro-Probe Architecture:** Probes are **passive** - no electronics downhole. Electronics are centralized at surface (see [Base Hub BOM](base-hub-bom.md)). This reduces per-probe cost and complexity.
**Modular Design:** Probes are assembled from 16mm OD fiberglass segments and 3D-printed sensor modules.

## Mechanical Components

| Component | Description | Quantity | Part Number | Supplier | Example Source (real-world) | Unit Cost | Total Cost | Notes |
|---|---|---|---|---|---|---|---|---|
| Rod sections | Fiberglass tube 0.5–1.0 m, Ø16 mm OD / 12 mm ID | 2–3 | Custom | Local/McMaster | McMaster 5/8" OD fiberglass tube (or similar 16mm metric) | $6–10 | $12–30 | Cut to 0.5m or 1.0m lengths |
| Male Insert Plugs | 3D printed threaded plug | 2–3 | Custom | 3D print | Printed per `hardware/cad/openscad/modular_flush_connector.scad` | $0.50 | $1.50 | Epoxied into rod ends. **Print with 100% Infill** |
| Sensor Modules | 3D printed sensor housing (Female thread) | 2–3 | Custom | 3D print | Printed per `hardware/cad/openscad/modular_flush_connector.scad` | $1–2 | $2–6 | Houses coils/electrodes. **Print with 100% Infill** |
| Probe tip | 3D-printed nose cone (Threaded) | 1 | Custom | 3D print | Custom SCAD | $1 | $1 | Screws into bottom rod |
| O-rings | Seals for threaded joints | 2–4 | AS568-014 | McMaster | Buna-N O-ring for 12mm thread seal | $0.10 | $0.40 | Weatherproofing joints |
| Epoxy | 2-part structural epoxy | 1 | Various | Hardware store | Loctite Marine Epoxy | $5 | $5 | For bonding inserts to rods |
| **Subtotal Mechanical** | | | | | | | **$21.90–43.90** | |

## Manufacturing Tools (One-time purchase)

| Tool | Description | Quantity | Supplier | Cost | Notes |
|---|---|---|---|---|---|
| Tap | M12×1.75 Plug Tap | 1 | Amazon/McMaster | $10–15 | **Recommended** to cut threads in female "Blanks" |
| Die | M12×1.75 Round Die | 1 | Amazon/McMaster | $10–15 | **Recommended** to cut threads on male "Blanks" |
| Die Stock / Tap Handle | Handle for tools | 1 set | Amazon | $15–20 | |

## MIT-3D Components (Integrated into Modules)

| Component | Description | Quantity | Part Number | Supplier | Unit Cost | Total Cost | Notes |
|---|---|---|---|---|---|---|---|
| Ferrite cores | NiZn Ø8 mm × 100 mm | 2 | 5961001801 | Fair-Rite/Mouser | $3 | $6 | Fair-Rite 61 material (μᵣ=125) for 2-50 kHz broadband |
| Magnet wire | 34 AWG enameled | 1 spool | 8081 | Remington Industries | $8 | $8 | ~300 turns per coil, single-layer bank wound |
| **Subtotal MIT** | | | | | | **$14** | |

**MIT Coil Specifications:**
- Inductance target: 1.5 mH ±10%
- Q Factor: ≥30 @ 10 kHz, ≥20 across 2-50 kHz
- DC Resistance: <8 Ω
- Self-Resonant Frequency: >200 kHz
- See `docs/field-guide/coil-winding-recipe.md` for complete winding procedure

## ERT Components (Integrated into Modules)

| Component | Description | Quantity | Part Number | Supplier | Unit Cost | Total Cost | Notes |
|---|---|---|---|---|---|---|---|
| Electrodes | Copper/SS tape or wire | 2–3 | Custom | McMaster | $1 | $2–3 | Wrapped in grooves on sensor module |
| Wire | Thin twisted pair | 3–5m | Custom | Digi-Key | $2 | $2 | Runs through center of rod |
| **Subtotal ERT** | | | | | | **$4–5** | |

## Total per Probe

| Category | Cost Range |
|---|---|
| Mechanical | $22–44 |
| MIT Components | $14 |
| ERT Components | $4–5 |
| **Total** | **$40–63** |

**Typical cost:** ~$50 per probe

## Procurement Tips
- **Rod Stock:** Buy standard 5/8" or 16mm fiberglass tubing in bulk lengths (e.g., 8ft or 2m) and cut to size.
- **3D Printing:** This design relies heavily on printed parts. Use PETG or ASA for strength and outdoor durability. **Set slicer to 100% Infill.**
- **O-rings:** Don't skip these. They keep groundwater out of the wiring channel.
- **Threads:** **STRONGLY RECOMMENDED:** Print the "Blanks" version (`modular_mixed_array_4x_BLANKS.stl`) and cut threads with Tap/Die for superior strength and fit.

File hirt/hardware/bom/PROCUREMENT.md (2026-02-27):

# Procurement Workflow Guide

## Overview

This guide provides step-by-step instructions for ordering components for the HIRT system using the BOM files and CSV order sheets.

## Prerequisites

- Review [Probe BOM](probe-bom.md) and [Base Hub BOM](base-hub-bom.md)
- Determine quantity needed (typically 20 probes + base hub)
- Set procurement budget
- Identify preferred suppliers

## Step 1: Review BOM Files

### 1.1 Understand Component Requirements

- **Probe Components:** See [probe-bom.md](probe-bom.md)
  - Mechanical: Rods, capsules, seals, etc.
  - MIT Electronics: DDS, amplifiers, ADC, MCU
  - ERT Components: Electrodes, mux, amplifiers

- **Base Hub Components:** See [base-hub-bom.md](base-hub-bom.md)
  - ERT current source
  - Differential voltmeter
  - Sync/clock distribution
  - Power system
  - Communications/data logging
  - Enclosure

### 1.2 Check for Alternatives

- Some components have alternatives listed in notes
- Consider cost vs. performance trade-offs
- Verify compatibility if substituting parts

## Step 2: Prepare Order Lists

### 2.1 Use CSV Order Sheets

The CSV files in [order-sheets/](order-sheets/) are ready for import:

- **probe-order-sheet.csv** - Components for probes
- **base-hub-order-sheet.csv** - Base hub components
- **complete-kit-order-sheet.csv** - Summary of all components

### 2.2 Calculate Quantities

**For 20 probes:**
- Multiply "Quantity per Probe" by 20
- Add 10-20% spares for critical components
- Order wire, connectors, etc. in bulk

**Example:**
- AD9833 DDS: 1 per probe × 20 = 20 units
- Add 2 spares = **22 total**
- ESP32: 1 per probe × 20 = 20 units
- Add 2 spares = **22 total**

### 2.3 Create Supplier-Specific Lists

Group components by supplier:
- **Digi-Key:** Most electronic components
- **Mouser:** Alternative for electronics
- **McMaster-Carr:** Mechanical components
- **Amazon:** Batteries, enclosures, common items
- **Local/3D Print:** Custom parts (capsules, couplers)

## Step 3: Supplier Selection

### 3.1 Major Distributors

**Digi-Key Electronics**
- **Website:** digikey.com
- **Best for:** ICs, passives, connectors, wire
- **Shipping:** Fast, reliable
- **Minimum order:** Usually none
- **Bulk discounts:** Available for large quantities

**Mouser Electronics**
- **Website:** mouser.com
- **Best for:** ICs, passives (alternative to Digi-Key)
- **Shipping:** Fast, reliable
- **Price comparison:** Compare with Digi-Key

**McMaster-Carr**
- **Website:** mcmaster.com
- **Best for:** Mechanical components, rods, hardware
- **Shipping:** Fast, reliable
- **No minimum:** Usually none

**Amazon**
- **Best for:** Batteries, enclosures, common items
- **Convenience:** Fast shipping, easy returns
- **Caution:** Verify part numbers match

### 3.2 Specialty Suppliers

- **Adafruit/SparkFun:** ESP32 modules, breakout boards
- **Local suppliers:** Fiberglass rods, custom machining
- **3D printing services:** Probe capsules, couplers

## Step 4: Ordering Process

### 4.1 Create Shopping Carts

**Digi-Key Process:**
1. Go to digikey.com
2. Search for part number (e.g., "AD9833BRMZ-REEL7")
3. Add to cart with correct quantity
4. Repeat for all components
5. Review cart for accuracy
6. Apply quantity discounts if available
7. Check shipping options and costs

**Mouser Process:**
1. Similar to Digi-Key
2. Compare prices if ordering from both
3. Consider consolidating to one supplier for simplicity

**McMaster-Carr Process:**
1. Search by part number or description
2. Select appropriate size/material
3. Add to cart
4. Note: May need to call for custom items

### 4.2 Verify Part Numbers

**Before ordering, verify:**
- Part number matches BOM exactly
- Package type (SOIC, DIP, etc.) is correct
- Quantity matches requirements
- Lead time is acceptable
- Stock availability

### 4.3 Check Alternatives

If a part is out of stock or expensive:
- Check notes in BOM for alternatives
- Search distributor websites for equivalents
- Verify pin compatibility
- Update BOM if substituting

## Step 5: Bulk Ordering Tips

### 5.1 Quantity Discounts

- Order all probes' components at once (20× quantities)
- Many distributors offer 10-20% discount at quantity breaks
- Check pricing tiers before ordering

### 5.2 Spare Components

**Recommended spares (10-20% extra):**
- Critical ICs (DDS, ADC, MCU): 2-4 spares
- Connectors, headers: 10-20% extra
- Fuses, small components: 20-30% extra
- Wire, cable: Order extra (useful for repairs)

### 5.3 Common Components

Order in larger quantities:
- Headers, sockets: Used throughout
- Resistors, capacitors: Common values
- Wire, cable: Useful for prototyping and repairs

## Step 6: Cost Tracking

### 6.1 Create Spreadsheet

Track orders with columns:
- Component name
- Part number
- Supplier
- Quantity ordered
- Unit cost
- Total cost
- Order date
- Expected delivery
- Actual delivery
- Notes

### 6.2 Budget Management

- Set budget limits for each category
- Track actual vs. estimated costs
- Note any significant cost differences
- Update BOM with actual costs for future reference

## Step 7: Ordering Checklist

### Pre-Order Checklist

- [ ] BOM files reviewed
- [ ] Quantities calculated (including spares)
- [ ] Part numbers verified
- [ ] Suppliers selected
- [ ] Budget approved
- [ ] Shopping carts prepared
- [ ] Shipping addresses confirmed
- [ ] Payment method ready

### Order Verification

- [ ] All part numbers correct
- [ ] Quantities match requirements
- [ ] Shipping addresses correct
- [ ] Payment processed
- [ ] Order confirmations received
- [ ] Expected delivery dates noted

### Post-Order

- [ ] Track shipments
- [ ] Verify received items match orders
- [ ] Check for damaged items
- [ ] Update inventory spreadsheet
- [ ] Store components properly
- [ ] Note any backorders or delays

## Step 8: Handling Issues

### 8.1 Out of Stock Items

- Check alternative suppliers
- Look for equivalent parts
- Consider backorder if acceptable
- Update BOM with substitutions

### 8.2 Wrong Parts Received

- Contact supplier immediately
- Request return/replacement
- Verify correct part number
- Update records

### 8.3 Cost Overruns

- Review actual vs. estimated costs
- Identify high-cost items
- Consider alternatives for future orders
- Update BOM with actual costs

## Step 9: Component Storage

### 9.1 Organization

- Organize by component type
- Use labeled bins/containers
- Keep ESD-sensitive parts in anti-static bags
- Store in dry, temperature-controlled area

### 9.2 Inventory Management

- Track what's been used
- Keep spares organized
- Label probe-specific components
- Maintain inventory spreadsheet

## Step 10: Future Orders

### 10.1 Learn from Experience

- Note which suppliers were best
- Record actual costs vs. estimates
- Identify components that needed alternatives
- Update BOM files with lessons learned

### 10.2 Refinement

- Update BOMs with verified part numbers
- Add notes about alternatives that worked
- Document any issues encountered
- Share updates with team

## Cost Tracking Template

```csv
Component,Part Number,Supplier,Quantity,Unit Cost,Total Cost,Order Date,Delivery Date,Status,Notes
AD9833 DDS,AD9833BRMZ-REEL7,Digi-Key,22,$8.50,$187.00,2024-03-15,2024-03-20,Received,
ESP32 DevKit,ESP32-DEVKITC-32E,Adafruit,22,$10.00,$220.00,2024-03-15,2024-03-18,Received,
...
```

## Supplier Contact Information

### Digi-Key Electronics
- **Website:** www.digikey.com
- **Phone:** 1-800-344-4539
- **Email:** support@digikey.com
- **Hours:** 24/7 online ordering

### Mouser Electronics
- **Website:** www.mouser.com
- **Phone:** 1-800-346-6873
- **Email:** support@mouser.com
- **Hours:** 24/7 online ordering

### McMaster-Carr
- **Website:** www.mcmaster.com
- **Phone:** 1-630-833-0300
- **Email:** Contact via website
- **Hours:** Business hours
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

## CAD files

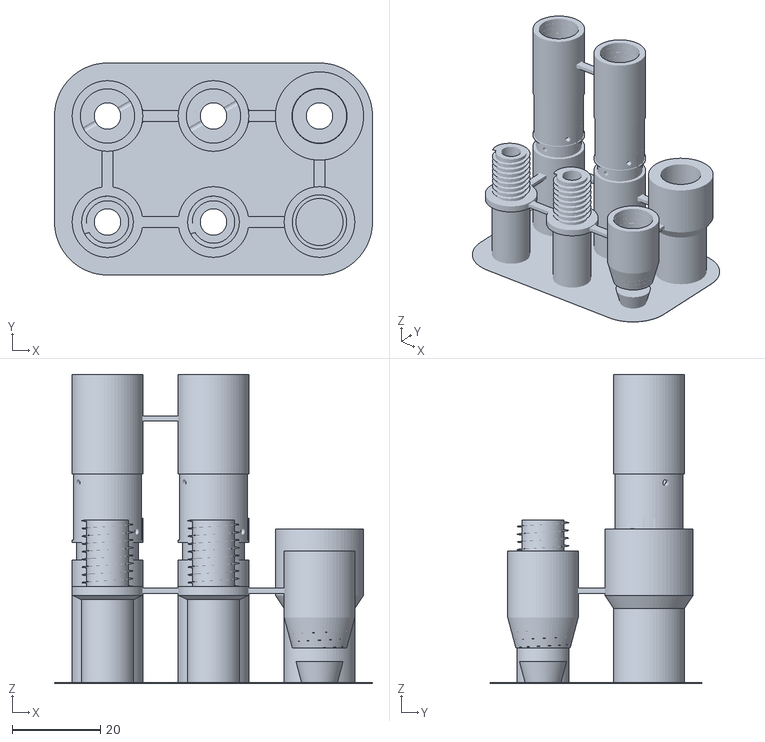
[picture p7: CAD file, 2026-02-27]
hirt/hardware/cad/stl/probe_system_complete.stl
72.0 x 48.0 x 70.0

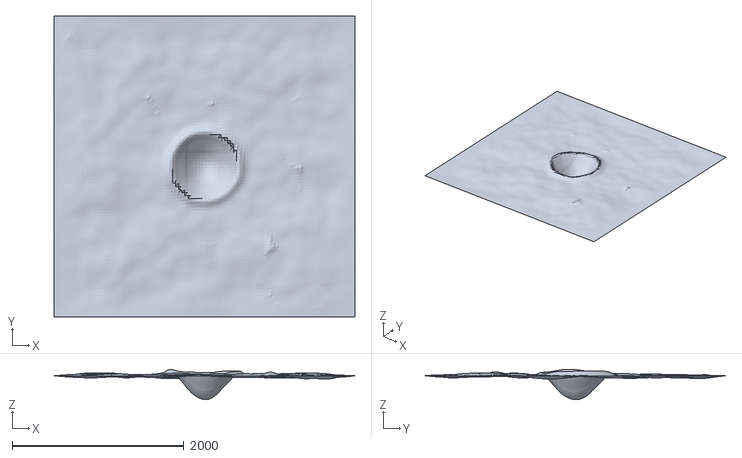
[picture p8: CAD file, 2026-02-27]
geosim/scenarios/bomb-crater-heterogeneous.obj
3500.0 x 3500.0 x 353.6

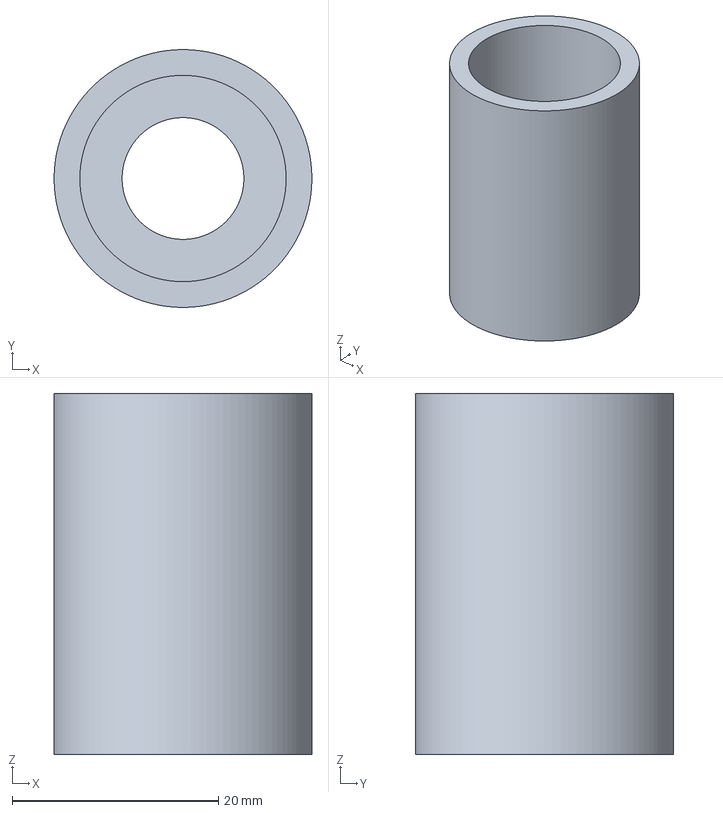
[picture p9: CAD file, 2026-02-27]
hirt/hardware/cad/openscad/micro_probe_head.3mf
25.0 x 25.0 x 35.0 mm

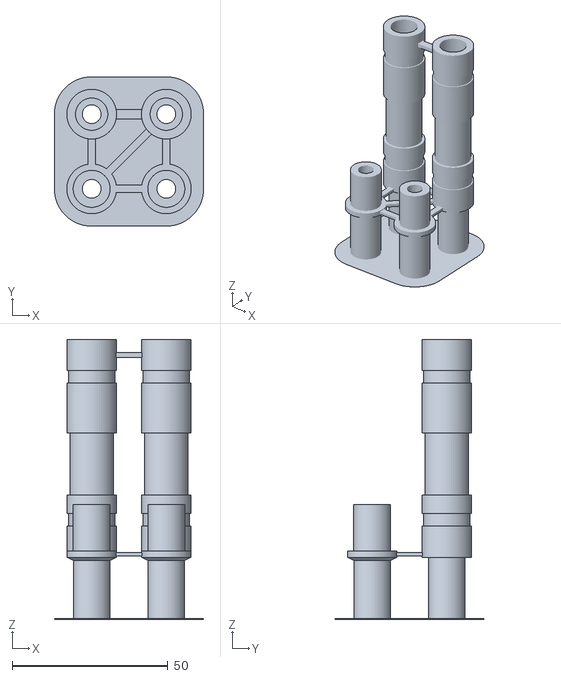
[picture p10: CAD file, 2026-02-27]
hirt/hardware/cad/stl/modular_mixed_array_4x_BLANKS.stl
48.0 x 48.0 x 90.0

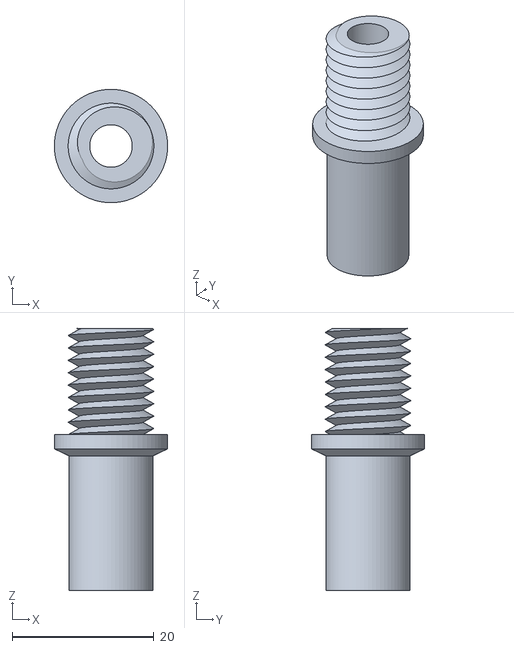
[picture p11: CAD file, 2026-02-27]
hirt/hardware/cad/openscad/male_rod_cap_threads_test.stl
16.0 x 16.0 x 37.0

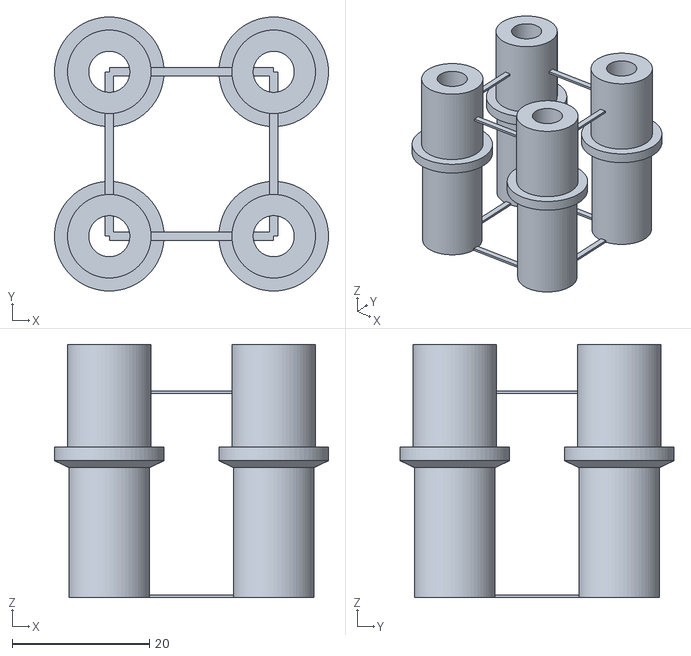
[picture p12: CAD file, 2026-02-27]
hirt/hardware/cad/stl/modular_male_insert_4x.stl
40.0 x 40.0 x 37.0

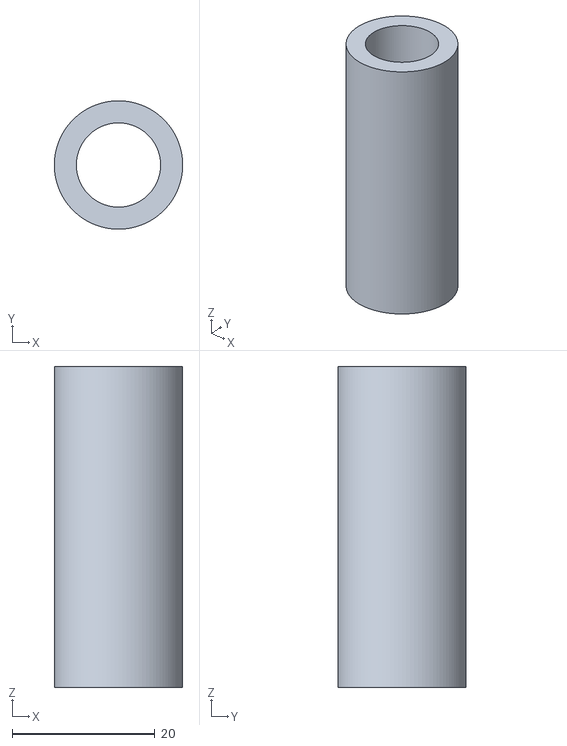
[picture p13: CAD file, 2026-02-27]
hirt/hardware/cad/stl/micro_rod_coupler.stl
18.0 x 18.0 x 45.0

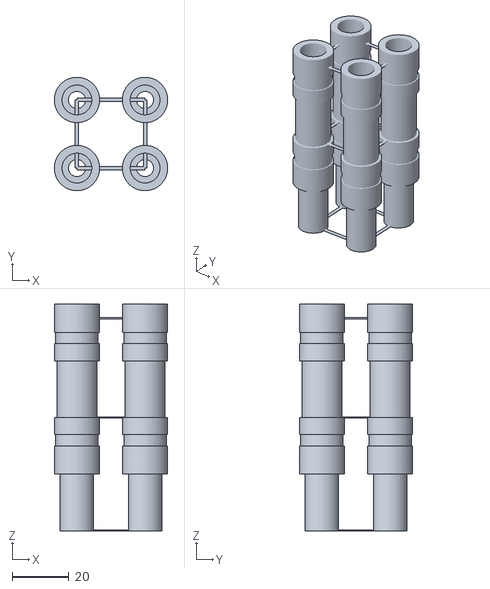
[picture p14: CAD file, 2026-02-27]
hirt/hardware/cad/stl/modular_female_sensor_4x.stl
40.0 x 40.0 x 80.0

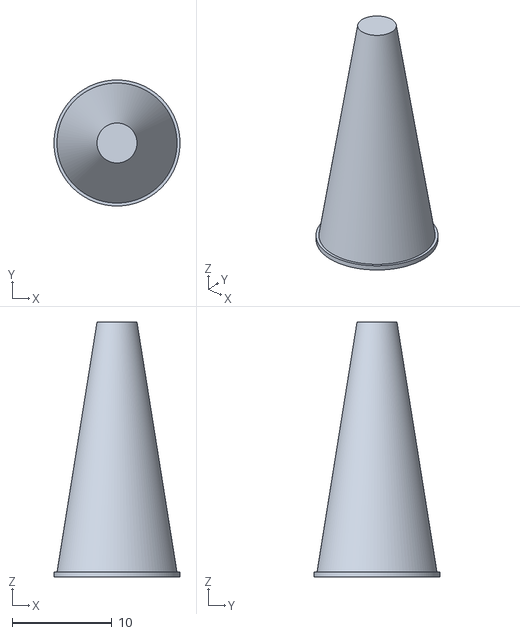
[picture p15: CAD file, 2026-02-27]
hirt/hardware/cad/stl/micro_probe_tip.stl
12.6 x 12.6 x 25.5

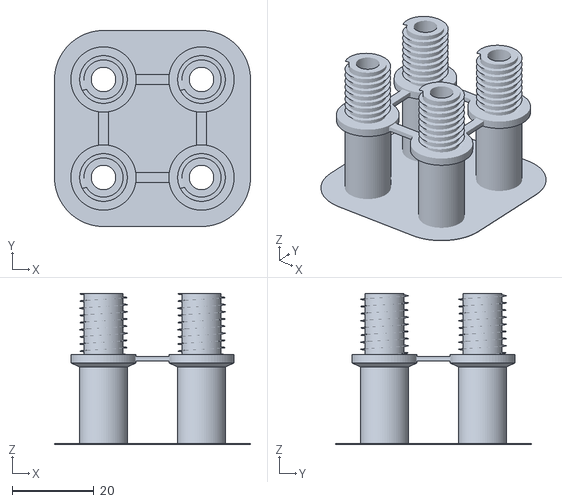
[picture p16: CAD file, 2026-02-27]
hirt/hardware/cad/stl/male_rod_cap_4x.stl
48.0 x 48.0 x 37.0

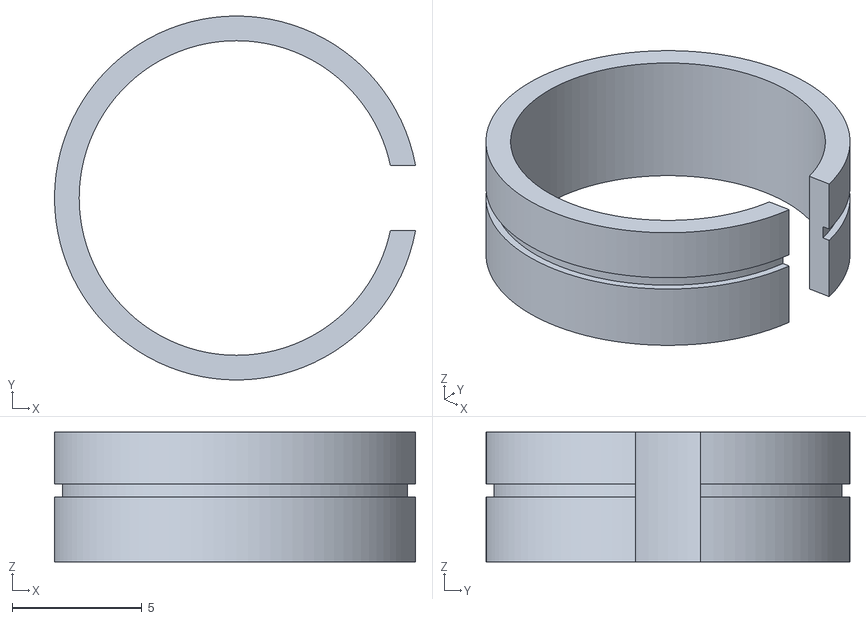
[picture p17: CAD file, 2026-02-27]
hirt/hardware/cad/stl/micro_ert_ring_collar.stl
13.9 x 14.0 x 5.00

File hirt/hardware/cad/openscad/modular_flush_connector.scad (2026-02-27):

/*
 * HIRT Modular Flush Connector System v2.0
 * Target Rod: 16mm OD x 12mm ID Fiberglass Tube
 *
 * Thread Library: Uses threads-scad by rcolyer for robust polyhedron mesh
 * https://github.com/rcolyer/threads-scad
 *
 * =============================================================================
 * ARCHITECTURE: Independent Sensor Bodies
 * =============================================================================
 *
 * This system separates sensors from fiberglass rod connectors for true modularity.
 *
 * Fiberglass Section:
 *     [Male Cap] ======== Fiberglass Tube ======== [Male Cap]
 *     (epoxied)           (50cm or 100cm)          (epoxied)
 *
 * Independent Sensor Body:
 *     [Female Socket] ==== Sensor Body ==== [Female Socket]
 *     (threaded)          (70mm, 16mm OD)    (threaded)
 *
 * Assembly Example (1.5m probe):
 *     [Junction Cap]
 *          |
 *     [Male Cap]----[50cm Fiberglass]----[Male Cap]
 *          |                                  |
 *     [Sensor Body - Dual Female]
 *          |                                  |
 *     [Male Cap]----[100cm Fiberglass]---[Male Cap]
 *          |
 *     [Sensor Body - Dual Female]
 *          |
 *     [Probe Tip]
 *
 * =============================================================================
 * COMPONENTS
 * =============================================================================
 *
 * | Component          | Description                    | Threads              |
 * |--------------------|--------------------------------|----------------------|
 * | male_rod_cap       | Epoxies into fiberglass end    | External M12 male    |
 * | sensor_body_dual   | Independent sensor unit        | Internal M12 (BOTH)  |
 * | probe_tip          | Bottom terminator              | Internal M12 (top)   |
 * | junction_cap       | Top terminator, cable exit     | Internal M12 (bottom)|
 *
 * =============================================================================
 * FEATURES
 * =============================================================================
 * - Flush 16mm OD match to fiberglass tube
 * - M12 threads (FULLY PRINTED) - "Chunky" Trapezoidal Profile
 * - Center 6mm pass-through for wiring
 * - O-ring seal grooves
 * - ERT ring groove and MIT coil zone on sensor bodies
 * - Radial wire entry holes for sensor connections
 * - Printing Optimizations: SUPER BRIM and rigid scaffolding
 */

// =============================================================================
// EXTERNAL LIBRARIES
// =============================================================================
use <threads/threads.scad>

// =============================================================================
// PARAMETERS
// =============================================================================

// --- Rod Dimensions ---
ROD_OD = 16.0;           // Fiberglass tube outer diameter
ROD_ID = 12.0;           // Fiberglass tube inner diameter
ROD_INSERT_DEPTH = 20.0; // How far male cap glues into tube

// --- Thread Parameters ---
THREAD_DIA_MAJOR = 11.8; // Slight undersize for male fit (clearance)
THREAD_DIA_MINOR = 10.4; // Female hole size (for blanks/tapping)
THREAD_PITCH = 1.75;     // M12 thread pitch
THREAD_LEN = 15.0;       // External thread length
THREAD_HOLE_DEPTH = 25.0; // Female socket depth

// --- General Dimensions ---
WIRE_HOLE_DIA = 6.0;     // Center wiring channel
FLANGE_THICKNESS = 2.0;  // Stop flange thickness

// --- Sensor Body Parameters ---
SENSOR_BODY_LEN = 70.0;      // Total sensor body length
SENSOR_WALL_THICK = 2.0;     // Minimum wall at thread area

// --- Sensor Feature Parameters ---
ERT_GROOVE_WIDTH = 4.0;      // Width of ERT ring groove
ERT_GROOVE_DEPTH = 1.0;      // Depth of ERT ring groove (into 16mm OD)
MIT_COIL_ZONE = 15.0;        // Length of coil winding area
WIRE_ENTRY_DIA = 1.5;        // Radial holes for coil/ring wires

// --- Probe Tip Parameters ---
TIP_LENGTH = 30.0;           // Total probe tip length
TIP_POINT_DIA = 8.0;         // Diameter at tip point
TIP_TAPER_LEN = 15.0;        // Length of tapered section

// --- Junction Cap Parameters ---
JUNCTION_CAP_LEN = 35.0;     // Total junction cap length
CABLE_GLAND_BOSS_DIA = 20.0; // Boss diameter for cable gland
CABLE_GLAND_THREAD_DIA = 12.5; // M12 or PG7 gland thread hole
CABLE_GLAND_BOSS_LEN = 15.0; // Length of cable gland boss

// --- Render Control ---
// Options: "all", "male_cap_array", "sensor_body_array", "mixed_system_array",
//          "male_cap_single", "sensor_body_single", "probe_tip_single",
//          "junction_cap_single", "complete_system", "blanks_array"
//          Add "_oversize" suffix for die/tap chasing version (e.g., "mixed_system_array_oversize")
//
// Visualization options (for documentation renders):
//          "exploded_view"      - Parts separated with 20mm gaps
//          "cross_section"      - Half-section showing internal wire channel
//          "isometric_assembled" - Tight assembly for "what you're building"
//          "deployment_array"   - 4 probes with ground plane and hub
//          "component_callout"  - Single sensor body with annotation markers
part = "all";

// Thread oversize for die/tap chasing (0 = print-ready, 0.3 = chase with die/tap)
THREAD_OVERSIZE = 0;

$fn = 64; // Resolution

// =============================================================================
// THREAD MODULES
// =============================================================================

module simple_thread(od, len, pitch, internal=false, oversize=0) {
    // Uses threads-scad library for robust polyhedron mesh generation
    // This avoids degenerate triangles that occur with linear_extrude + twist
    // oversize: extra material for tap/die chasing (use 0.3-0.5 for chase-ready)
    //
    // The threads-scad library generates threads as a single polyhedron using
    // list comprehensions, producing valid, smooth meshes for FDM slicers.

    // Base tolerance for threads-scad
    base_tolerance = 0.4;

    if (internal) {
        // Female thread (for subtraction via difference())
        // ScrewThread creates geometry to subtract - leaves internal threads in the part
        // Uses same approach as threads-scad ScrewHole: slightly oversized thread
        extra = 0.5;  // Extra length to extend beyond body surfaces

        // For print-ready: use standard clearance for FDM fit
        // For tap-ready (oversize>0): subtract less material, leaving more for tap
        thread_dia = 1.01*od + 1.25*base_tolerance - oversize;

        // Just the thread geometry - no core cylinder (would fill in thread valleys)
        translate([0, 0, -extra/2])
            ScrewThread(thread_dia, len + extra, pitch, tolerance=base_tolerance);
    } else {
        // Male thread (external)
        // For die-ready: ADD material (larger diameter) so die can cut to final size
        tolerance = base_tolerance - oversize;
        ScrewThread(od + oversize, len, pitch, tolerance=tolerance);
    }
}

module iso_thread_12(len, internal=false, oversize=0) {
    // M12x1.75 Optimized
    // oversize: 0 for print-ready, 0.3 for die/tap chasing
    simple_thread(12.0, len, 1.75, internal, oversize);
}


// =============================================================================
// UTILITY MODULES
// =============================================================================

module chamfer_cylinder(d, h, chamfer=1.0) {
    union() {
        translate([0,0,chamfer]) cylinder(d=d, h=h-2*chamfer);
        cylinder(d1=d-2*chamfer, d2=d, h=chamfer);
        translate([0,0,h-chamfer]) cylinder(d1=d, d2=d-2*chamfer, h=chamfer);
    }
}

module o_ring_groove(inner_dia, groove_width=2.0, groove_depth=1.5) {
    // O-ring groove for sealing
    difference() {
        cylinder(d=inner_dia + groove_depth*2, h=groove_width);
        translate([0,0,-0.1])
            cylinder(d=inner_dia, h=groove_width + 0.2);
    }
}


// =============================================================================
// MAIN COMPONENTS
// =============================================================================

// -----------------------------------------------------------------------------
// MALE ROD CAP (formerly male_insert)
// Epoxies into fiberglass tube end, external M12 male thread
// -----------------------------------------------------------------------------
module male_rod_cap() {
    difference() {
        union() {
            // 1. Insert Section (Goes inside fiberglass tube)
            cylinder(d=ROD_ID - 0.2, h=ROD_INSERT_DEPTH - 1);
            translate([0,0,ROD_INSERT_DEPTH-1])
                cylinder(d1=ROD_ID-0.2, d2=ROD_OD, h=1);

            // 2. Stop Flange (butts against tube end)
            translate([0,0,ROD_INSERT_DEPTH])
                cylinder(d=ROD_OD, h=FLANGE_THICKNESS);
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

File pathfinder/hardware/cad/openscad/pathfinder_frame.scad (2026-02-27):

// Pathfinder Gradiometer Frame - Parametric Model
// Trapeze-style 4-channel fluxgate gradiometer frame
//
// Usage:
//   openscad -D 'part="assembled"' pathfinder_frame.scad -o pathfinder.stl
//
// Render modes (set 'part' variable):
//   "assembled"     - Complete trapeze system
//   "exploded"      - Components separated with gaps
//   "cross_section" - Half-section showing tube interiors
//   "deployment"    - With operator silhouette
//   "single_tube"   - Single sensor pair detail

/* [Render Mode] */
part = "assembled"; // ["assembled", "exploded", "cross_section", "deployment", "single_tube"]

/* [Crossbar Parameters] */
CROSSBAR_LENGTH = 2000;        // mm - Total length
CROSSBAR_OD = 25;              // mm - Outer diameter (carbon fiber tube)
CROSSBAR_WALL = 2;             // mm - Wall thickness
CROSSBAR_ID = CROSSBAR_OD - 2 * CROSSBAR_WALL;  // Inner diameter

/* [Sensor Positions] */
// Positions from left end (50cm spacing)
SENSOR_POSITIONS = [250, 750, 1250, 1750];  // mm
CENTER_MOUNT = 1000;           // mm - Center harness attachment point

/* [Drop Tube Parameters] */
DROP_TUBE_LENGTH = 500;        // mm - PVC tube length
DROP_TUBE_OD = 21.3;           // mm - 3/4" Schedule 40 PVC
DROP_TUBE_WALL = 2.7;          // mm - Schedule 40 wall
DROP_TUBE_ID = DROP_TUBE_OD - 2 * DROP_TUBE_WALL;

/* [Sensor Parameters] */
BOTTOM_SENSOR_HEIGHT = 175;    // mm from ground (15-20cm range)
SENSOR_DIAMETER = 16;          // mm - FG-3+ approximate diameter
SENSOR_LENGTH = 80;            // mm - FG-3+ approximate length

/* [Harness Parameters] */
D_RING_OD = 30;                // mm
D_RING_THICKNESS = 4;          // mm
BUNGEE_LENGTH = 400;           // mm - Approximate bungee length
SPREADER_BAR_LENGTH = 200;     // mm

/* [Visualization] */
EXPLODE_GAP = 100;             // mm - Gap between exploded parts
$fn = 32;                      // Circle resolution

// Colors
COLOR_CARBON = [0.15, 0.15, 0.15];   // Dark gray for carbon fiber
COLOR_PVC = [0.9, 0.9, 0.9];         // Light gray for PVC
COLOR_SENSOR = [0.2, 0.4, 0.6];      // Steel blue for sensors
COLOR_HARNESS = [0.6, 0.3, 0.1];     // Brown for straps
COLOR_METAL = [0.7, 0.7, 0.75];      // Silver for hardware

// ============================================================
// COMPONENT MODULES
// ============================================================

// Carbon fiber crossbar with mounting holes
module crossbar() {
    color(COLOR_CARBON)
    difference() {
        // Main tube
        rotate([0, 90, 0])
        cylinder(d=CROSSBAR_OD, h=CROSSBAR_LENGTH, center=true);

        // Hollow interior
        rotate([0, 90, 0])
        cylinder(d=CROSSBAR_ID, h=CROSSBAR_LENGTH + 2, center=true);

        // Mounting holes for drop tubes
        for (pos = SENSOR_POSITIONS) {
            translate([pos - CROSSBAR_LENGTH/2, 0, 0])
            rotate([0, 0, 0])
            cylinder(d=5, h=CROSSBAR_OD + 2, center=true);
        }

        // Center mount hole
        translate([CENTER_MOUNT - CROSSBAR_LENGTH/2, 0, CROSSBAR_OD/2])
        cylinder(d=8, h=10, center=true);
    }
}

// End cap for crossbar
module end_cap() {
    color(COLOR_CARBON)
    difference() {
        union() {
            // Outer cap
            cylinder(d=CROSSBAR_OD, h=10);
            // Insert portion
            translate([0, 0, -15])
            cylinder(d=CROSSBAR_ID - 0.5, h=15);
        }
        // Hollow for lighter weight
        translate([0, 0, 3])
        cylinder(d=CROSSBAR_ID - 4, h=10);
    }
}

// PVC drop tube with sensor mounts
module drop_tube() {
    color(COLOR_PVC)
    difference() {
        // Main tube
        cylinder(d=DROP_TUBE_OD, h=DROP_TUBE_LENGTH, center=true);

        // Hollow interior
        cylinder(d=DROP_TUBE_ID, h=DROP_TUBE_LENGTH + 2, center=true);

        // Top mounting hole
        translate([0, 0, DROP_TUBE_LENGTH/2 - 20])
        rotate([90, 0, 0])
        cylinder(d=5, h=DROP_TUBE_OD + 2, center=true);

        // Bottom sensor slot
        translate([0, 0, -DROP_TUBE_LENGTH/2 + 20])
        cube([DROP_TUBE_ID + 2, 5, 40], center=true);
    }
}

// Simplified FG-3+ fluxgate sensor representation
module fluxgate_sensor() {
    color(COLOR_SENSOR)
    union() {
        // Main sensor body
        cylinder(d=SENSOR_DIAMETER, h=SENSOR_LENGTH, center=true);

        // End caps
        translate([0, 0, SENSOR_LENGTH/2])
        cylinder(d=SENSOR_DIAMETER + 2, h=5, center=true);
        translate([0, 0, -SENSOR_LENGTH/2])
        cylinder(d=SENSOR_DIAMETER + 2, h=5, center=true);

        // Cable exit
        translate([0, 0, -SENSOR_LENGTH/2 - 10])
        cylinder(d=4, h=20, center=true);
    }
}

// Single sensor pair (top + bottom with drop tube)
module sensor_pair(exploded=false) {
    explode_offset = exploded ? EXPLODE_GAP : 0;

    // Drop tube
    translate([0, 0, -DROP_TUBE_LENGTH/2 - CROSSBAR_OD/2 - explode_offset])
    drop_tube();

    // Top sensor (on crossbar)
    translate([0, 0, CROSSBAR_OD/2 + SENSOR_LENGTH/2 + (exploded ? EXPLODE_GAP : 5)])
    rotate([0, 0, 0])
    fluxgate_sensor();

    // Bottom sensor (at tube end)
    translate([0, 0, -DROP_TUBE_LENGTH - CROSSBAR_OD/2 + SENSOR_LENGTH/2 - (exploded ? EXPLODE_GAP*2 : 0)])
    fluxgate_sensor();
}

// Center mount D-ring for harness attachment
module center_mount() {
    color(COLOR_METAL) {
        // Base plate
        translate([0, 0, CROSSBAR_OD/2])
        difference() {
            cylinder(d=40, h=3);
            translate([0, 0, -1])
            cylinder(d=8, h=5);
        }

        // D-ring
        translate([0, 0, CROSSBAR_OD/2 + 3]) {
            difference() {
                union() {
                    // Straight part
                    translate([0, -D_RING_OD/2 + D_RING_THICKNESS, D_RING_OD/2])
                    rotate([0, 90, 0])
                    cylinder(d=D_RING_THICKNESS, h=D_RING_OD - D_RING_THICKNESS, center=true);

                    // Curved part
                    translate([0, D_RING_THICKNESS/2, D_RING_OD/2])
                    rotate([0, 90, 0])
                    rotate_extrude(angle=180)
                    translate([D_RING_OD/2 - D_RING_THICKNESS/2, 0, 0])
                    circle(d=D_RING_THICKNESS);
                }
            }
        }
    }
}

// Spreader bar for harness
module spreader_bar() {
    color(COLOR_METAL)
    rotate([0, 90, 0])
    cylinder(d=10, h=SPREADER_BAR_LENGTH, center=true);
}

// Bungee cord segment
module bungee_cord(length) {
    color([0.2, 0.2, 0.2])
    cylinder(d=6, h=length, center=true);
}

// Simplified harness shoulder straps
module harness_straps() {
    color(COLOR_HARNESS) {
        // Left strap
        translate([-100, 0, 0])
        cube([50, 5, 300], center=true);

        // Right strap
        translate([100, 0, 0])
        cube([50, 5, 300], center=true);

        // Back panel
        translate([0, 0, 100])
        cube([250, 5, 150], center=true);
    }
}

// Human operator silhouette for scale
module operator_silhouette() {
    color([0.3, 0.3, 0.3, 0.5]) {
        // Torso
        translate([0, 0, 1200])
        cylinder(d1=400, d2=350, h=500);

        // Head
        translate([0, 0, 1750])
        sphere(d=200);

        // Legs
        for (x = [-100, 100]) {
            translate([x, 0, 0])
            cylinder(d=150, h=900);
        }
    }
}

// Mounting bolt
module mounting_bolt() {
    color(COLOR_METAL) {
        // Head
        cylinder(d=10, h=4);
        // Shaft
        translate([0, 0, -56])
        cylinder(d=5, h=60);
    }
}

// Sensor clip (3D printed part)
module sensor_clip() {
    color([0.2, 0.6, 0.2])
    difference() {
        cube([25, 20, 15], center=true);
        // Sensor hole
        rotate([90, 0, 0])
        cylinder(d=SENSOR_DIAMETER + 1, h=25, center=true);
        // Mounting hole
        cylinder(d=5, h=20, center=true);
    }
}

// ============================================================
// ASSEMBLY MODULES
// ============================================================

// Complete assembled frame
module assembled_frame() {
    // Crossbar
    crossbar();

    // End caps
    translate([-CROSSBAR_LENGTH/2 - 5, 0, 0])
    rotate([0, -90, 0])
    end_cap();

    translate([CROSSBAR_LENGTH/2 + 5, 0, 0])
    rotate([0, 90, 0])
    end_cap();

    // Sensor pairs at each position
    for (pos = SENSOR_POSITIONS) {
        translate([pos - CROSSBAR_LENGTH/2, 0, 0])
        sensor_pair(exploded=false);
    }

    // Center mount
    translate([CENTER_MOUNT - CROSSBAR_LENGTH/2, 0, 0])
    center_mount();
}

// Exploded view with gaps between components
module exploded_frame() {
    // Crossbar (raised)
    translate([0, 0, EXPLODE_GAP * 2])
    crossbar();

    // End caps (offset further)
    translate([-CROSSBAR_LENGTH/2 - EXPLODE_GAP - 5, 0, EXPLODE_GAP * 2])
    rotate([0, -90, 0])
    end_cap();

    translate([CROSSBAR_LENGTH/2 + EXPLODE_GAP + 5, 0, EXPLODE_GAP * 2])
    rotate([0, 90, 0])
    end_cap();
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

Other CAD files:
hirt/hardware/cad/stl/micro_probe_head.stl

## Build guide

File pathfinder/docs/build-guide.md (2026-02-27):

# Pathfinder Build Guide

Complete step-by-step instructions for building the Pathfinder 4-pair fluxgate gradiometer from scratch. This guide consolidates information from the wiring guide, BOM, frame design, and schematics into a single build sequence.

**Document version**: 1.0 (2026-02-18)

---

## Overview

The Pathfinder is a harness-supported, multi-channel fluxgate gradiometer for rapid magnetic reconnaissance. It carries 4 gradiometer pairs (8 sensors total) on a horizontal crossbar, suspended from padded shoulder straps with bungee isolation. The electronics fit inside a belt-mounted IP65 enclosure and log georeferenced magnetic gradient data to an SD card.

### Build Summary

| Parameter | Value |
|---|---|
| **Total build time** | 6-10 hours (first build) |
| **Skill level** | Intermediate (basic soldering, 3D printing helpful but not required) |
| **Total cost** | $620-$820 (see BOM); up to $1,050 if purchasing premium components |
| **Tools needed** | Soldering iron, multimeter, wire strippers, heat gun, 3D printer (optional) |
| **Firmware** | PlatformIO on Arduino Nano (ATmega328P, 5V/16MHz) |

### What You Will Build

```
                    PADDED HARNESS
                   (backpack straps)
                          |
              +-----------+-----------+
              |   bungee suspension   |
              +-----------+-----------+
                          |
    ======================+=======================
         CARBON FIBER CROSSBAR (2.0m x 25mm)
        |         |         |         |
       +-+       +-+       +-+       +-+
       |T|       |T|       |T|       |T|    <- TOP sensors (reference)
       | |       | |       | |       | |
       | |       | |       | |       | |    <- PVC drop tubes (50cm)
       |B|       |B|       |B|       |B|    <- BOTTOM sensors (signal)
       +-+       +-+       +-+       +-+       15-20cm above ground

       <--50cm--><--50cm--><--50cm-->
                 1.5m swath
```

### Build Phases at a Glance

| Phase | Description | Time Estimate |
|---|---|---|
| 1. Procurement | Order components, print parts | 1-2 weeks |
| 2. Electronics Assembly | Solder and wire all modules | 3-4 hours |
| 3. Sensor Preparation | Test sensors, build F-to-V boards, make cables | 1-2 hours |
| 4. Frame Assembly | Cut crossbar, attach drop tubes, mount enclosure | 1-2 hours |
| 5. Harness System | Straps, bungees, fitting adjustments | 30-60 minutes |
| 6. Initial Testing | Flash firmware, bench test, first field walk | 30-60 minutes |

---

## Phase 1: Procurement (1-2 weeks)

### Full Bill of Materials

The complete BOM with pricing is maintained in `hardware/bom/pathfinder-bom.csv` and the formatted version in `hardware/bom/README.md`. The cost summary is:

| Category | Low Estimate | High Estimate |
|---|---|---|
| Sensors (FG-3+ x8 + LM2917 x8) | $436 | $464 |
| Electronics (Arduino, ADCs, GPS, SD, passives) | $33 | $76 |
| Power (LiPo, regulator, switch) | $20 | $43 |
| Frame (crossbar, PVC, mounts) | $67 | $109 |
| Harness (straps, bungees, carabiners) | $12 | $36 |
| Enclosure (IP65 box, glands, standoffs) | $21 | $36 |
| Cables (shielded wire, connectors, labels) | $32 | $54 |
| **Total** | **$622** | **$818** |

### Long Lead-Time Components

Order these first, as they may take 1-3 weeks to arrive:

1. **Fluxgate sensors (FG-3+)**: Order from FG Sensors directly. These are specialty items and typically ship in 5-10 business days. Quantity: 8.
2. **LM2917N-8 frequency-to-voltage ICs**: Available from Mouser or DigiKey. Usually in stock, but verify before ordering. Quantity: 8.
3. **Carbon fiber tube (25mm OD x 2mm wall x 2m)**: Order from DragonPlate or RockWest Composites. These are cut-to-order and may take 1-2 weeks. Quantity: 1.
4. **3D-printed sensor clips and end caps**: If you do not have a 3D printer, order from Shapeways or JLCPCB 3D printing service. STL files are in `hardware/cad/`. Allow 1-2 weeks for printing and shipping.

### Readily Available Components

These are available from common retailers (Amazon, AliExpress, hardware stores) and typically arrive in 2-5 days:

- Arduino Nano (clone or genuine)
- ADS1115 ADC breakout modules (x2)
- NEO-6M GPS module with antenna
- SD card module and microSD card
- LiPo battery (7.4V 2S, 2000-3000 mAh)
- LM2596 buck converter module
- PVC conduit from any hardware store
- All resistors, capacitors, connectors
- Hammond 1554K enclosure (or equivalent)

### Substitute Components

If specific parts are unavailable, these substitutes work:

| Original | Substitute | Trade-off |
|---|---|---|
| Carbon fiber tube 25mm OD | Aluminum EMT conduit 1.25" | Heavier (+130g), cheaper ($15 vs $40) |
| Genuine Arduino Nano | Clone Arduino Nano (CH340) | Same functionality, $5 vs $25 |
| FG-3+ sensors | Magnetometer-Kit.com FGM-3 PRO | ~20% higher cost, compatible pinout |
| 3D-printed clips | Cable ties + foam padding | Less secure, but functional |
| Hammond 1554K enclosure | Any IP65 box ~150x100x50mm | Verify internal dimensions fit components |
| 2N7000 MOSFET (buzzer driver) | BS170 N-channel MOSFET | Pin-compatible, equivalent specs |

### Tools Required

Gather these before starting assembly:

**Essential tools:**
- Soldering iron (temperature-controlled, chisel tip recommended)
- Solder (60/40 or 63/37 leaded, 0.8mm diameter for through-hole work)
- Multimeter (for voltage, continuity, and resistance checks)
- Wire strippers (22-24 AWG range)
- Flush cutters (for trimming leads)
- Heat gun or lighter (for heat shrink tubing)
- Small Phillips and flathead screwdrivers
- Hacksaw or pipe cutter (for PVC tubes)
- Drill with 5mm bit (for crossbar mounting holes)

**Helpful but not essential:**
- Third-hand or PCB holder
- Solder wick and/or solder sucker (for mistakes)
- 3D printer (PLA or PETG filament)
- Label maker or self-laminating wire labels
- Hot glue gun (for strain relief)

### Pre-Build Preparation

Before starting assembly:

1. **Verify all components received.** Check against BOM. Test that each module powers up if possible.
2. **Format the microSD card.** Use FAT32 format, card must be 32 GB or smaller. Class 10 recommended.
3. **Install PlatformIO.** Follow instructions at https://platformio.org/install. You will need this to flash firmware.
4. **Print 3D parts** (if printing yourself). Use PETG for outdoor durability or PLA for prototyping. See STL files in `hardware/cad/`.

---

## Phase 2: Electronics Assembly (3-4 hours)

This phase covers all electronics: from preparing individual modules to wiring the complete system inside the enclosure. Work through each step in order. Each step lists the components you need, the connections to make, and a verification test to confirm the step succeeded before moving on.

### Exploded Electronics Layout

When fully assembled, the electronics sit inside the Hammond enclosure in this arrangement:

```
+------------------------------------------+
|  [Power Switch]  [Battery Connector]     |
|                                          |
|  [Buck Converter]    [Arduino Nano]      |
|                                          |
|  [ADS1115 #1]        [ADS1115 #2]       |
|                                          |
|  [GPS Module]        [SD Card Module]    |
|                                          |
|  [Screw Terminals / JST Headers for     |
|   8 Sensor Cables]                       |
+------------------------------------------+

Approximate PCB/perfboard size: 100mm x 150mm
Mount on M3 nylon standoffs (10mm) inside enclosure.
```

All modules mount on a single perfboard or directly on standoffs within the enclosure. Wiring runs underneath or along the edges.

### Step 2.1: Arduino Nano Preparation

**Components needed:**
- 1x Arduino Nano (ATmega328P, 5V/16MHz)
- Header pins (if bare board -- most modules come with headers pre-soldered)
- USB Mini-B cable

**Procedure:**

1. If the Arduino Nano came without headers soldered, solder male header pins to both rows. Use a breadboard as a jig to keep the pins aligned while soldering.
2. Connect the Nano to your computer via USB.
3. Open a serial terminal (PlatformIO Serial Monitor or Arduino IDE Serial Monitor) at 115200 baud.
4. Upload the I2C scanner sketch to verify the board is working:
   ```cpp
   #include <Wire.h>
   void setup() {
     Wire.begin();
     Serial.begin(115200);
     Serial.println("I2C Scanner Ready");
   }
   void loop() {
     for (byte addr = 1; addr < 127; addr++) {
       Wire.beginTransmission(addr);
       if (Wire.endTransmission() == 0) {
         Serial.print("Found device at 0x");
         Serial.println(addr, HEX);
       }
     }
     Serial.println("Scan complete.");
     delay(5000);
   }
   ```
5. The scanner should report no devices found (nothing connected yet). This confirms the board programs and communicates correctly.

**Verification:** Serial output shows "I2C Scanner Ready" and "Scan complete." with no errors.

**Soldering tips for headers:**
- Apply flux to pads before soldering if your solder does not contain flux.
- Heat the pad and pin simultaneously for 2-3 seconds, then touch solder to the junction (not the iron tip).
- A good joint is shiny and concave (volcano-shaped). A cold joint is dull and blobby.
- If you bridge two pins, use solder wick to remove the excess.

### Step 2.2: ADS1115 ADC Modules

**Components needed:**
- 2x ADS1115 16-bit ADC breakout modules
- Header pins (if not pre-soldered)
- 2x 4.7k ohm resistors (if your ADS1115 modules lack onboard I2C pullups)
- 4x 0.1 uF ceramic capacitors (bypass caps)

**Procedure:**

1. Solder headers onto both ADS1115 modules if needed. The standard breakout has pins for VDD, GND, SCL, SDA, ADDR, ALRT, A0, A1, A2, A3.

2. **Set I2C addresses.** This is critical -- the two modules must have different addresses:
   - **Module 1 (0x48):** Connect the ADDR pin to GND. On most breakout boards, this is the default (ADDR is pulled to GND via onboard resistor). Verify with your multimeter: ADDR pin should read 0V.
   - **Module 2 (0x49):** Connect the ADDR pin to VDD (5V). Solder a wire jumper from ADDR to VDD, or bridge the address solder jumper if your board has one.

3. **Check for onboard pullups.** Most ADS1115 breakout boards from Adafruit and similar include 10k pullup resistors on SDA and SCL. Look for two small resistors near the I2C pins. If your boards do not have them, you will add external 4.7k pullups in Step 2.4.

4. Solder a 0.1 uF ceramic capacitor across the VDD and GND pins of each module, as close to the chip as possible. These bypass capacitors reduce noise.

**Verification:** Do not connect yet. Set aside. We will test after wiring the I2C bus in Step 2.4.

### Step 2.3: Power Distribution

**Components needed:**
- 1x 7.4V 2S LiPo battery (2000-3000 mAh)
- 1x 5V buck converter module (LM2596-based, rated >600 mA)
- 1x SPST power switch (toggle or rocker, panel-mount)
- 1x XT60 or JST battery connector pair (match your battery)
- 22 AWG stranded wire (red and black, ~50 cm each)

**Procedure:**

1. **Wire the battery connector.** Solder red wire to the positive terminal and black wire to the negative terminal of the female battery connector. Apply heat shrink tubing to each solder joint.

2. **Wire the power switch.** Connect the red (positive) wire from the battery connector to one terminal of the SPST switch. Solder a second red wire from the other terminal of the switch to the input positive (VIN+) of the buck converter.

3. **Wire the buck converter input.** Connect the black (negative) wire from the battery connector directly to the input negative (VIN-) of the buck converter.

4. **Adjust the buck converter output.** Before connecting any loads:
   - Connect the battery.
   - Turn the power switch on.
   - Measure the output voltage with your multimeter on the VOUT+ and VOUT- terminals.
   - Turn the adjustment potentiometer on the buck converter until the output reads **5.0V** (acceptable range: 4.9V-5.1V).
   - Turn the power switch off.

5. **Create a power bus.** You need to distribute 5V and GND to all modules. Options:
   - **Perfboard approach:** Solder two copper bus strips on your perfboard -- one for 5V, one for GND. Connect the buck converter output to these buses.
   - **Terminal block approach:** Use 5mm screw terminal blocks. One row for 5V distribution, one for GND.

   The following modules will connect to the 5V/GND bus:
   - Arduino Nano (5V pin and GND pin)
   - ADS1115 Module 1 (VDD and GND)
   - ADS1115 Module 2 (VDD and GND)
   - GPS module (VCC and GND)
   - SD card module (VCC and GND)
   - Sensor power (8x fluxgate sensors)

6. **Add a power indicator (optional but recommended).** Wire a spare LED with a 1k ohm resistor between the 5V bus and GND. This gives you a quick visual check that power is reaching the bus.

**Power distribution wiring diagram:**

```
[7.4V LiPo Battery]
       |
   [XT60 Connector]
       |
       +--[Power Switch]--[Buck Converter IN+]
       |                        |
       +--[Buck Converter IN-]  [Buck Converter OUT+]---+--- 5V BUS
                                |                       |
                        [Buck Converter OUT-]---+--- GND BUS
```

**Verification:**
- Turn on the power switch. Measure 5.0V (+/- 0.1V) on the 5V bus with your multimeter.
- Measure continuity between all GND points on the bus.
- Turn off the switch. Voltage should drop to 0V.
- Current draw with no modules connected should be near zero (just the buck converter quiescent current, typically <5 mA).

### Step 2.4: I2C Bus Wiring

**Components needed:**
- Arduino Nano (from Step 2.1)
- 2x ADS1115 modules (from Step 2.2, with addresses configured)
- 2x 4.7k ohm resistors (if modules lack onboard pullups)
- 24 AWG stranded wire (2 colors: e.g., blue for SDA, yellow for SCL)

**Procedure:**

1. **Connect power to all three boards.** Wire VDD/5V and GND from the power bus (Step 2.3) to:
   - Arduino Nano 5V pin and GND pin
   - ADS1115 Module 1 VDD and GND
   - ADS1115 Module 2 VDD and GND

2. **Wire SDA (data line).** Connect:
   - Arduino Nano pin A4 (SDA) --> ADS1115 Module 1 SDA --> ADS1115 Module 2 SDA
   - This is a bus topology: all three SDA pins share a single wire.

3. **Wire SCL (clock line).** Connect:
   - Arduino Nano pin A5 (SCL) --> ADS1115 Module 1 SCL --> ADS1115 Module 2 SCL
   - Same bus topology as SDA.

4. **Add pullup resistors (if needed).** If neither ADS1115 module has onboard pullup resistors:
   - Solder a 4.7k ohm resistor from SDA to 5V.
   - Solder a 4.7k ohm resistor from SCL to 5V.
   - If both modules already have 10k onboard pullups, the effective parallel resistance is 5k, which is fine. Do NOT add external pullups in this case (too-strong pullups waste power and can cause signal issues).

5. **Verify ADDR pins:**
   - Module 1: ADDR pin connected to GND (address 0x48).
   - Module 2: ADDR pin connected to VDD (address 0x49).

**I2C bus wiring diagram:**

```
                    5V
                    |
              [4.7k] [4.7k]     <-- only if no onboard pullups
                |       |
Arduino A4 ----+--------)---------- ADS1 SDA -------- ADS2 SDA
               |        |
Arduino A5 ----+--------+---------- ADS1 SCL -------- ADS2 SCL
```

**Keep I2C wires short** -- under 30 cm total bus length. Use twisted pair if possible (twist SDA and SCL together) to reduce noise pickup.

**Verification:**
1. Power on the system.
2. Upload the I2C scanner sketch from Step 2.1 to the Arduino Nano.
3. Open the serial monitor at 115200 baud.
4. You should see two devices reported:
   ```
   Found device at 0x48
   Found device at 0x49
   Scan complete.
   ```
5. If only one device appears, check the ADDR pin wiring on the missing module. If neither appears, check SDA/SCL wiring and power connections.

### Step 2.5: GPS Module

**Components needed:**
- 1x NEO-6M GPS module (with ceramic patch antenna)
- 24 AWG stranded wire

**Procedure:**

1. **Check voltage compatibility.** Most NEO-6M breakout modules accept 5V on the VCC pin (they have an onboard 3.3V regulator). Verify with your module's documentation. If your module requires 3.3V, use the Arduino Nano 3V3 pin instead of 5V -- but note the 3V3 pin has limited current (50 mA).

2. **Wire power:** Connect GPS VCC to the 5V bus and GPS GND to the GND bus.

3. **Wire serial data:**
   - GPS TX pin --> Arduino Nano D4 (this is the Arduino's receive line in software serial)
   - GPS RX pin --> Arduino Nano D3 (not used by default firmware, but wire it for future use)

   **Important: cross-connect.** The GPS TX goes to the Arduino RX pin, and vice versa. This is the most common wiring mistake with serial connections.

4. **Mount the GPS antenna.** The ceramic patch antenna should face upward with clear sky view. If the antenna is attached via a u.FL connector, keep the coaxial cable short and avoid sharp bends.

5. **GPS placement considerations:**
   - Mount the GPS module or its antenna on the outside of the enclosure lid if possible, or near a window/opening.
   - Keep the antenna at least 10 cm from metal objects and electronics.
   - The antenna can be mounted on the crossbar for better sky view, with a cable running to the enclosure.

**Verification:**
1. Power on the system.
2. Upload a simple GPS test sketch or use the serial monitor to observe raw data:
   ```cpp
   #include <SoftwareSerial.h>
   SoftwareSerial gpsSerial(4, 3); // RX=D4, TX=D3
   void setup() {
     Serial.begin(115200);
     gpsSerial.begin(9600);
     Serial.println("GPS Test");
   }
   void loop() {
     while (gpsSerial.available()) {
       Serial.write(gpsSerial.read());
     }
   }
   ```
3. You should see NMEA sentences scrolling on the serial monitor. They look like:
   ```
   $GPGGA,123519,4807.038,N,01131.000,E,1,08,0.9,545.4,M,47.0,M,,*47
   $GPRMC,123519,A,4807.038,N,01131.000,E,022.4,084.4,230394,003.1,W*6A
   ```
4. **Indoors, the GPS will not get a fix** (latitude/longitude will be 0 or empty). That is normal. If you see NMEA sentences at all, the wiring is correct.
5. If no data appears: check that TX goes to D4 (not D3), verify baud rate is 9600, and confirm power is reaching the GPS module.

### Step 2.6: SD Card Module

**Components needed:**
- 1x SPI microSD breakout module
- 1x microSD card (Class 10, 8-32 GB, formatted FAT32)
- 24 AWG stranded wire

**Procedure:**

1. **Wire power:** Connect SD module VCC to the 5V bus and GND to the GND bus.

2. **Wire SPI connections.** These use hardware SPI pins on the Arduino Nano, which are fixed:

   | SD Module Pin | Arduino Nano Pin | SPI Signal |
   |---------------|------------------|------------|
   | CS | D10 | Chip Select |
   | MOSI (DI) | D11 | Master Out Slave In |
   | MISO (DO) | D12 | Master In Slave Out |
   | SCK (CLK) | D13 | Serial Clock |

3. **Insert the microSD card.** Ensure it is formatted as FAT32.

**Voltage note:** Some SD card modules are 3.3V only and do not have onboard level shifters. If your module has both a 3.3V regulator and level shifters (most common breakout boards do), then 5V is fine. If the module has only a raw SD card socket with no regulator, you must power it from 3.3V and add level shifters. The Adafruit MicroSD breakout and most AliExpress modules include the necessary circuitry for 5V operation.

**Verification:**
1. Upload an SD card test sketch:
   ```cpp
   #include <SPI.h>
   #include <SD.h>
   void setup() {
     Serial.begin(115200);
     Serial.print("Initializing SD card...");
     if (!SD.begin(10)) { // CS on pin 10
       Serial.println("FAILED!");
       return;
     }
     Serial.println("OK");
     File f = SD.open("TEST.TXT", FILE_WRITE);
     if (f) {
       f.println("Hello from Pathfinder");
       f.close();
       Serial.println("Write successful");
     }
   }
   void loop() {}
   ```
2. The serial monitor should show "Initializing SD card...OK" and "Write successful".
3. Remove the SD card, insert it in a computer, and verify `TEST.TXT` exists and contains "Hello from Pathfinder".
4. If initialization fails: try a different SD card, verify CS is on D10, check SPI wiring, and ensure the card is FAT32.

### Step 2.7: Beeper and Status LED

**Components needed:**
- 1x Piezo buzzer (passive) or magnetic buzzer
- 1x 2N7000 N-channel MOSFET (TO-92 package)
- 2x 10k ohm resistors
- 1x 5mm red LED
- 1x 220 ohm resistor
- 24 AWG stranded wire

**Procedure:**

#### Status LED

1. Connect the LED anode (longer leg, +) to Arduino pin D2 through a 220 ohm resistor.
2. Connect the LED cathode (shorter leg, flat side, -) to GND.

```
Arduino D2 ----[220 ohm]---->(+LED-)---->GND
```

Current calculation: (5V - 2V forward drop) / 220 ohm = 13.6 mA. This is within safe limits for both the LED and the Arduino pin.

#### Pace Beeper

For a louder buzzer (recommended for field use), use the MOSFET driver circuit:

1. Connect Arduino pin D9 to a 10k ohm resistor. Connect the other end of this resistor to the gate of the 2N7000 MOSFET.
2. Connect a second 10k ohm resistor from the MOSFET gate to GND (this is a pulldown to ensure the MOSFET stays off when the Arduino pin is floating during boot).
3. Connect the MOSFET drain to the buzzer negative terminal.
4. Connect the buzzer positive terminal to 5V.
5. Connect the MOSFET source to GND.

```
           5V
            |
        [Buzzer+]
        [Buzzer-]
            |
    MOSFET Drain
            |
    MOSFET Source --- GND
            |
    MOSFET Gate ----[10k]---- Arduino D9
            |
          [10k]
            |
           GND
```

**MOSFET pin identification (2N7000, TO-92 package, flat side facing you, pins down):**
- Left pin: Source
- Center pin: Gate
- Right pin: Drain

**Alternative for passive buzzer (simpler, quieter):** Connect the buzzer directly between D9 and GND, without the MOSFET. This works but produces a quieter sound since the Arduino pin can only source ~20 mA.

**Verification:**
1. Upload a quick test:
   ```cpp
   void setup() {
     pinMode(2, OUTPUT);
     pinMode(9, OUTPUT);
   }
   void loop() {
     digitalWrite(2, HIGH); // LED on
     tone(9, 2000, 50);    // 2kHz beep for 50ms
     delay(1000);
     digitalWrite(2, LOW);  // LED off
     delay(1000);
   }
   ```
2. The LED should blink on/off every second. The buzzer should beep once per second.
3. If the LED does not light: check polarity (swap the legs). If the buzzer does not sound: verify MOSFET pinout and gate resistor wiring.

### Step 2.8: Sensor Cable Connectors

**Components needed:**
- 10x JST-XH 4-pin connector sets (male + female pairs; 8 needed, 2 spares)
- 24 AWG stranded wire

**Procedure:**

1. **Install JST-XH male headers on the perfboard/enclosure.** These are the connectors where sensor cables plug in. Install 8 headers -- one per sensor. Label them clearly:
   - P1_TOP, P1_BOT (Pair 1 top and bottom)
   - P2_TOP, P2_BOT (Pair 2)
   - P3_TOP, P3_BOT (Pair 3)
   - P4_TOP, P4_BOT (Pair 4)

2. **Wire each JST header to the corresponding ADS1115 input and power:**

   **Standard sensor cable pinout (JST-XH 4-pin):**

   | Pin | Signal | Wire Color | Connection |
   |-----|--------|------------|------------|
   | 1 | +5V | Red | 5V bus |
   | 2 | GND | Black | GND bus |
   | 3 | Signal | White/Yellow | ADS1115 analog input |
   | 4 | Shield | Bare/Green | GND bus (controller end only) |

3. **Wire the signal pins to the correct ADS1115 analog inputs:**

   | Sensor | ADS Module | Channel | Notes |
   |--------|------------|---------|-------|
   | P1_TOP | ADS1 (0x48) | A0 | Left-most pair, reference |
   | P1_BOT | ADS1 (0x48) | A1 | Left-most pair, signal |
   | P2_TOP | ADS1 (0x48) | A2 | Center-left pair, reference |
   | P2_BOT | ADS1 (0x48) | A3 | Center-left pair, signal |
   | P3_TOP | ADS2 (0x49) | A0 | Center-right pair, reference |
   | P3_BOT | ADS2 (0x49) | A1 | Center-right pair, signal |
   | P4_TOP | ADS2 (0x49) | A2 | Right-most pair, reference |
   | P4_BOT | ADS2 (0x49) | A3 | Right-most pair, signal |

4. **Double-check every connection.** A miswired sensor channel produces incorrect gradient data that may not be obvious until you try to interpret survey results.

**Verification:**
1. With no sensors connected, power on and read ADC values via a test sketch. Each channel should read near 0V (floating input will show some random noise).
2. Touch a wire from the 5V bus to each analog input pin, one at a time. The ADC reading should jump to near full-scale (~32767 at GAIN_ONE). This confirms each channel is wired correctly.

### Complete Wiring Reference

After completing all steps above, your wiring should match this diagram:

```
                           +5V BUS
                              |
        +---------------------+---------------------+
        |          |          |          |          |
    [Arduino]  [ADS1]    [ADS2]     [GPS]       [SD]
        |          |          |          |          |
        +---------------------+---------------------+
                          GND BUS

ARDUINO NANO PIN ASSIGNMENTS:
  A4 (SDA) ---------- ADS1 SDA -------- ADS2 SDA
  A5 (SCL) ---------- ADS1 SCL -------- ADS2 SCL
  D4 (GPS RX) ------- GPS TX
  D3 (GPS TX) ------- GPS RX
  D9 (Beeper) ------- MOSFET Gate (via 10k)
  D2 (LED) ---------- LED Anode (via 220 ohm)
  D10 (SD CS) ------- SD Card CS
  D11 (MOSI) -------- SD Card MOSI
  D12 (MISO) -------- SD Card MISO
  D13 (SCK) --------- SD Card SCK

ADS1115 #1 (ADDR=GND, address 0x48):
  A0 <-- Sensor P1_TOP
  A1 <-- Sensor P1_BOT
  A2 <-- Sensor P2_TOP
  A3 <-- Sensor P2_BOT

ADS1115 #2 (ADDR=VDD, address 0x49):
  A0 <-- Sensor P3_TOP
  A1 <-- Sensor P3_BOT
  A2 <-- Sensor P4_TOP
  A3 <-- Sensor P4_BOT
```

### Electronics Assembly Checklist

Before moving on, verify:

- [ ] 5V bus reads 5.0V +/- 0.1V with multimeter
- [ ] I2C scanner finds both ADS1115 modules (0x48 and 0x49)
- [ ] GPS outputs NMEA sentences on serial monitor
- [ ] SD card initializes and writes a test file successfully
- [ ] Status LED lights on D2
- [ ] Beeper sounds on D9
- [ ] All sensor JST headers wired to correct ADS1115 channels
- [ ] All solder joints inspected (no cold joints, no bridges)
- [ ] Total current draw with no sensors: ~120-150 mA (Modeled)

---

## Phase 3: Sensor Preparation (1-2 hours)

This phase covers preparing the FG-3+ fluxgate sensors and their signal conditioning circuitry. Each sensor outputs a frequency proportional to the magnetic field; the LM2917 converts this frequency to a voltage that the ADS1115 can read.

### Step 3.1: Fluxgate Sensor Testing

**Components needed:**
- 8x FG-3+ fluxgate sensors
- Power supply (5V regulated -- use the buck converter from Phase 2)
- Multimeter with frequency measurement, or oscilloscope

**Procedure:**

1. **Test each sensor individually** before building the full system. Power one sensor at a time.
2. Connect the sensor to 5V and GND.
3. The FG-3+ outputs a frequency signal (typically 49-120 kHz range depending on the ambient magnetic field).
4. Measure the output frequency with an oscilloscope or frequency counter. If using a multimeter with frequency mode, verify it can measure frequencies in the 50-120 kHz range.
5. The exact frequency does not matter at this point -- you are confirming that each sensor produces a stable frequency output when powered.
6. **Label each sensor** with a unique identifier (1T, 1B, 2T, 2B, 3T, 3B, 4T, 4B). Use the self-laminating wire labels.
7. **Check for defective sensors.** A sensor is defective if:
   - It draws no current (open circuit internally)
   - It draws excessive current (>40 mA)
   - Its output is stuck at 0V or 5V (no frequency output)
   - Its output frequency is unstable or jittery (>1% variation in a static field)

**Verification:** All 8 sensors produce a stable frequency output when individually powered.

### Step 3.2: LM2917 Frequency-to-Voltage Boards

**Components needed (per channel, x8 total):**
- 1x LM2917N-8 IC (8-pin DIP)
- Timing resistor and capacitor (values per LM2917 datasheet, chosen for the FG-3+ frequency range)
- Output filter capacitor
- 8-pin DIP socket (recommended -- do not solder the IC directly)

The LM2917 converts the frequency output of each FG-3+ sensor into a proportional DC voltage that the ADS1115 ADC can read.

**Procedure:**

1. **Determine component values.** The LM2917 output voltage is: V_out = f_in x C_t x R_t x V_cc, where:
   - f_in = sensor output frequency
   - C_t = timing capacitor
   - R_t = timing resistor
   - V_cc = supply voltage

   Choose R_t and C_t so that the output voltage spans 0.5V-4.0V over the expected frequency range. Consult the LM2917 datasheet application notes for recommended values for your specific FG-3+ frequency range.

2. **Build 8 identical frequency-to-voltage circuits.** You can build these on small perfboard sections, or order a simple PCB if building multiples. Each circuit is small (about 20mm x 15mm).

3. **If using pre-built F-to-V modules**, verify that the timing components are appropriate for the FG-3+ frequency range. Generic modules may need component swaps.

4. **Install DIP sockets first**, then insert the LM2917 ICs. This protects the ICs from soldering heat and allows easy replacement.

5. **Wire each F-to-V circuit:**
   - Input: from the FG-3+ frequency output
   - Output: to the corresponding JST connector / ADS1115 input
   - Power: from the 5V/GND bus

**Verification:**
1. Power one F-to-V circuit with a sensor connected.
2. Measure the DC output voltage with your multimeter. It should be a stable voltage in the 0.5-4.0V range.
3. Move a magnet near the sensor. The output voltage should change smoothly.
4. Repeat for all 8 channels.

### Step 3.3: Sensor Cable Fabrication

**Components needed:**
- 15 meters of 4-conductor shielded cable (22-24 AWG)
- 8x JST-XH 4-pin female connectors (with crimp terminals)
- JST crimp tool or small needle-nose pliers
- Heat shrink tubing
- Self-laminating wire labels

**Procedure:**

1. **Cut cables to length.** Each sensor cable runs from the sensor position on the frame to the electronics enclosure. Measure based on your frame layout:
   - For sensors near the center of the crossbar: ~60 cm
   - For sensors at the ends of the crossbar: ~120 cm
   - Add 15 cm of slack to each cable for strain relief and routing

   Typical cable lengths for a 2m crossbar with belt-mounted enclosure:
   | Sensor | Cable Length |
   |--------|-------------|
   | P1_TOP, P1_BOT (left end) | 120 cm |
   | P2_TOP, P2_BOT (center-left) | 80 cm |
   | P3_TOP, P3_BOT (center-right) | 80 cm |
   | P4_TOP, P4_BOT (right end) | 120 cm |

2. **Strip and terminate each cable.**
   - Strip the outer jacket back 25 mm at each end.
   - Separate the 4 conductors and the shield braid.
   - Strip each conductor 3 mm.
   - Crimp JST-XH female terminals onto each conductor.
   - Insert terminals into the JST-XH 4-pin housing in the correct order (Pin 1: 5V red, Pin 2: GND black, Pin 3: Signal white/yellow, Pin 4: Shield bare/green).

3. **Shield grounding (critical for noise performance):**
   - At the **enclosure end**: connect the cable shield to the GND bus.
   - At the **sensor end**: leave the shield wire disconnected (floating). Fold it back and cover with heat shrink.
   - Grounding the shield at only one end prevents ground loop currents that cause noise.

4. **Label both ends of each cable** with the sensor identifier (P1_TOP, P1_BOT, etc.).

5. **Continuity test every cable.** Use your multimeter on continuity mode to verify:
   - Pin 1 at one end connects to Pin 1 at the other end (not to any other pin).
   - No shorts between any pair of pins.
   - Shield is continuous from end to end.

**Verification:** All 8 cables pass continuity test with no shorts and correct pin-to-pin mapping.

### Step 3.4: Sensor Mounting Hardware

**Components needed:**
- 8x 3D-printed sensor clips (or cable ties + foam padding)
- EVA foam padding sheet (5mm, self-adhesive)

**Procedure:**

1. **If using 3D-printed clips:** Print from STL files in `hardware/cad/`. Use PETG filament for outdoor durability. Each clip friction-fits around the sensor body and snaps onto the PVC drop tube or crossbar.

2. **If using cable ties:** Wrap each sensor in a small piece of EVA foam padding (to prevent rattling and protect the sensor body), then secure to the drop tube or crossbar with two UV-resistant cable ties per sensor.

3. **Sensor orientation.** All sensors in a pair must be oriented the same way (same axis aligned with Earth's field). Mark the sensing axis on each sensor housing. When mounting, ensure all 8 sensors point in the same direction.

**Verification:** Each sensor sits snugly in its mount with no wobble. Mounts grip the drop tube securely without cracking.

---

## Phase 4: Frame Assembly (1-2 hours)

### Step 4.1: Carbon Fiber Crossbar Preparation

**Components needed:**
- 1x Carbon fiber tube (25mm OD x 2mm wall x 2m) or aluminum EMT conduit (1.25" x 2m)
- Drill with 5mm bit
- Tape measure
- Marker or pencil
- Fine-grit sandpaper (220 grit)
- Masking tape

**Procedure:**

1. **Measure and mark sensor positions.** From the left end of the crossbar, mark the following positions for the 4 sensor pairs:

   | Position | Distance from Left End | Pair |
   |----------|------------------------|------|
   | Pair 1 center | 25 cm | Left-most |
   | Pair 2 center | 75 cm | Center-left |
   | Pair 3 center | 125 cm | Center-right |
   | Pair 4 center | 175 cm | Right-most |
   | Center (D-ring) | 100 cm | Harness attachment |

   This produces 50 cm center-to-center spacing between pairs, with the total sensor span being 1.5 m.

2. **Drill mounting holes.** At each of the 4 sensor positions, drill a 5mm hole through both walls of the tube (the bolt will pass through the tube and the drop tube clamp).

   **Carbon fiber drilling tips:**
   - Wrap the tube with masking tape at the drill location to prevent splintering.
   - Use a sharp 5mm bit. Drill slowly with moderate pressure.
   - Support the tube from below to prevent cracking.
   - Clean up any fraying with fine sandpaper.

   **Aluminum drilling tips:**
   - Use a center punch to mark the hole before drilling.
   - Deburr the holes with a countersink or round file.

3. **Sand the ends** of the crossbar lightly with 220-grit sandpaper to remove sharp edges. If carbon fiber, seal the cut ends with CA glue (superglue) or clear nail polish to prevent fiber fraying.

4. **Install end caps.** Press-fit the 3D-printed end caps onto both ends of the crossbar. If they are loose, apply a drop of CA glue. End caps prevent water and debris from entering the tube.

5. **Install the center D-ring.** At the 100 cm mark (center of crossbar):
   - Place the pipe clamp collar around the tube and tighten.
   - Attach the 25mm D-ring to the clamp collar.
   - This is the main harness attachment point.

**Safety note:** Carbon fiber dust is an irritant. Wear a dust mask and eye protection when cutting or drilling carbon fiber. Work outdoors or in a well-ventilated area.

**Verification:**
- Crossbar is 2.0 m long with clean, capped ends.
- 4 mounting holes drilled at 25, 75, 125, and 175 cm from the left end.
- Center D-ring installed securely at 100 cm.
- No cracks, splits, or excessive fraying.

### Step 4.2: Sensor Drop Tubes

**Components needed:**
- 4x PVC conduit (3/4" Schedule 40, cut to 50 cm each)
- 4x M5 x 60mm stainless steel bolts with locknuts
- 4x Nylon spacers (M5 ID x 10mm)
- Pipe cutter or hacksaw
- Sandpaper (to deburr)

**Procedure:**

1. **Cut 4 PVC tubes to 50 cm length.** Deburr the cut ends with sandpaper.

2. **Drill a 5mm mounting hole** in each tube, centered 2 cm from the top end. This hole aligns with the crossbar mounting hole.

3. **Attach each drop tube to the crossbar.**
   - Insert the M5 bolt through: the crossbar hole, a nylon spacer, the PVC tube hole, a second nylon spacer (if needed for alignment), and secure with a locknut.
   - The nylon spacers prevent metal-on-composite contact and allow slight angular adjustment.
   - Tighten until snug but not so tight that the PVC tube cracks.

4. **Install sensor mounts.** For each drop tube:
   - **Bottom sensor:** Mount the bottom sensor at the bottom end of the PVC tube using a 3D-printed clip or cable tie. The sensor should be recessed about 2 cm inside the tube end, with the sensing element pointing downward.
   - **Top sensor:** Mount the top sensor on the crossbar, directly above the drop tube, using a 3D-printed clip or cable tie. The sensor sits at crossbar height.
   - The vertical separation between top and bottom sensors is approximately 48 cm (crossbar to bottom of drop tube minus sensor recesses).

5. **Route sensor cables.** Run each bottom sensor's cable up through the inside of the PVC drop tube, then along the crossbar toward the center. Top sensor cables route directly along the crossbar.

**Exploded view of a single drop tube assembly:**

```
                [Crossbar]
                    |
    [Top sensor]----+----[3D clip or cable tie]
                    |
         [M5 bolt + nylon spacer]
                    |
              [PVC tube 50cm]
                    |
                    |    <-- sensor cable routed inside tube
                    |
    [Bottom sensor]-+----[3D clip or cable tie]
                    |
              ~15-20 cm above ground (when worn)
```

**Verification:**
- All 4 drop tubes are securely bolted to the crossbar with no wobble.
- Sensors mount firmly in clips at top and bottom positions.
- Cables route cleanly through the tubes without pinching or kinking.
- The assembly is symmetric: all drop tubes hang vertically when the crossbar is held level.

### Step 4.3: Electronics Enclosure Mounting

**Components needed:**
- 1x Hammond 1554K IP65 enclosure (or equivalent, ~150x100x50mm)
- 2x PG7 cable glands
- 1x Gore-Tex pressure vent
- 8x M3 nylon standoffs (10mm)
- 2x Velcro straps (25mm x 30cm)
- Drill with step bit or appropriate hole saw

**Procedure:**

1. **Drill cable entry holes** in the enclosure:
   - Drill 2 holes for PG7 cable glands (12mm diameter each) on the bottom face of the enclosure.
   - One gland is for sensor cables (bundle all 8 through one gland, or use two glands -- one per side of the crossbar).
   - One gland is for the battery power cable.

2. **Drill the vent hole.** Drill one small hole (per vent specs) on the side of the enclosure for the Gore-Tex pressure vent. This prevents condensation buildup inside the sealed box.

3. **Install the cable glands and vent.** Thread them into the drilled holes and tighten the lockrings from inside.

4. **Mount nylon standoffs inside the enclosure.** Use M3 screws to secure 4-8 standoffs to the base of the enclosure. These support the perfboard or directly mount the Arduino Nano and modules.

5. **Install the electronics assembly** (from Phase 2) inside the enclosure:
   - Secure the perfboard to the standoffs with M3 screws.
   - Route sensor cables through the cable glands, leaving enough slack inside to reach the JST connectors.
   - Route the battery power cable through its cable gland.
   - Tighten the cable glands to create a water-resistant seal around the cables.

6. **Verify enclosure fit.** Close the lid and confirm:
   - The lid closes fully without pinching any wires.
   - All cables exit cleanly through cable glands.
   - The SD card can be accessed. Ideally, position the SD card module near the enclosure edge so you can swap cards without full disassembly. Alternatively, cut a small slot in the enclosure wall for card access (seal with tape during operation).
   - The status LED is visible through the enclosure wall. If not, drill a small hole and insert a clear LED light pipe, or mount the LED externally.

7. **Mount the enclosure for carrying.** Two options:
   - **Belt mount (recommended):** Use the Velcro straps to attach the enclosure to a belt or waist strap. This keeps weight on the hips and allows easy access.
   - **Crossbar mount:** Attach the enclosure to the center of the crossbar using Velcro straps or cable ties. This simplifies cable routing but adds weight to the crossbar.

**Verification:**
- Enclosure lid closes and seals properly.
- Cable glands grip all cables firmly.
- All connectors are accessible for plugging/unplugging sensors.
- SD card is accessible for data retrieval.
- Status LED visible from outside.
- Enclosure mounts securely in the chosen carry position.

### Step 4.4: Cable Routing and Management

**Components needed:**
- 2 meters of 10mm spiral cable wrap
- 50x UV-resistant cable ties (200mm)
- Self-laminating wire labels

**Procedure:**

1. **Bundle sensor cables along the crossbar.** Route all cables from the sensor positions toward the enclosure. Use spiral cable wrap or cable ties every 15-20 cm to keep cables neat and prevent snagging.

2. **Create a drip loop.** Where cables enter the enclosure (through the cable glands), form a small downward loop in each cable before it enters the gland. This prevents water from running along the cable and into the enclosure.

3. **Separate sensor cables from power cables.** Keep signal-carrying sensor cables at least 5 cm from power wires (battery leads, 5V bus wires) to minimize electrical noise pickup.

4. **Verify cable labels.** Each cable should be labeled at both the sensor end and the enclosure end with its identifier (P1_TOP, P1_BOT, etc.). This is essential for troubleshooting in the field.

5. **Secure cables to prevent mechanical stress on solder joints.** Use cable ties or hot glue to create strain relief points where cables connect to the enclosure and at each sensor mount.

**Verification:**
- All cables neatly routed and secured.
- No cables hanging loose that could snag on vegetation.
- All cables labeled at both ends.
- Drip loops formed at enclosure entry points.

---

## Phase 5: Harness System (30-60 minutes)

### Step 5.1: Shoulder Straps

**Components needed:**
- 1 set of padded shoulder straps (50mm wide -- salvaged from an old backpack is ideal)
- Alternatively, purchase padded camera strap or backpack replacement straps

**Procedure:**

1. **If salvaging from a backpack:** Remove the shoulder straps, keeping the upper attachment points and lower adjustment buckles intact. You need straps that can be adjusted for length and have some form of upper attachment loop or ring.

2. **If purchasing new:** Look for padded replacement backpack straps or dual camera straps with adjustable length. They should have D-ring or loop attachment points at the top.

3. **Attach the straps** to a common point at the back (a triangular plate, a webbing junction, or a salvaged backpack frame clip). The straps should meet at a point approximately at shoulder-blade height on the operator's back.

### Step 5.2: Bungee Isolation System

**Components needed:**
- 1m of 6mm bungee cord
- 4x spring-gate carabiners (5kN rated)
- 2x 25mm stainless steel D-rings
- 1x 20cm aluminum rod (spreader bar)

**Procedure:**

The bungee isolation system absorbs the vertical motion of walking so that sensor vibrations are damped rather than transmitted directly into the data. This is one of the most important features of the Pathfinder design.

1. **Attach D-rings to the bottom of the shoulder straps.** Sew or bolt a D-ring to each strap, at approximately waist level on the operator. These are the upper attachment points for the bungee system.

2. **Cut two bungee cord sections.** Each should be approximately 40 cm long (adjust based on operator height -- see fitting guide below).

3. **Attach the spreader bar.** The aluminum rod acts as a spreader to prevent the bungee cords from converging to a single point, which would allow the crossbar to swing side-to-side:
   - Drill a small hole near each end of the 20cm rod.
   - Thread a carabiner through each hole.
   - Clip the top carabiners to the D-rings on the shoulder straps.

4. **Connect the bungees.**
   - Tie one end of each bungee cord to the ends of the spreader bar (or to the carabiners).
   - Tie the other ends of the bungee cords to a central carabiner.
   - Clip the central carabiner to the D-ring on the center of the crossbar.

5. **Assembly order (top to bottom):**
   ```
   Shoulder straps
        |
   D-rings (sewn to straps)
        |
   Carabiners
        |
   Spreader bar (20cm aluminum rod)
        |
   Bungee cords (40cm each, one per side)
        |
   Central carabiner
        |
   Crossbar center D-ring
   ```

### Step 5.3: Fitting Guide

Proper harness fit is critical for data quality. If the sensors bounce excessively or drag on the ground, the data will be degraded.

**Target:** Bottom sensors 15-20 cm above ground during normal walking.

#### Fitting Procedure

1. **Don the harness** with the crossbar attached via the bungee system.
2. Stand upright on flat, level ground.
3. Have an assistant measure the height of the bottom sensors above the ground.
4. Adjust the shoulder strap length:
   - **Tighten straps** to raise the crossbar (increase ground clearance).
   - **Loosen straps** to lower the crossbar (decrease ground clearance).
5. Walk 10 paces at survey speed (~1 m/s). The sensors should gently bob up and down no more than 5 cm. If they bounce more than that, shorten the bungee cords.
6. Mark the final strap position with a permanent marker so you can reproduce the setting.

#### Height Adjustments by Operator

| Operator Height | Bungee Length | Strap Setting | Expected Ground Clearance |
|---|---|---|---|
| 160-170 cm | 35 cm | Shorter (tighter) | 15-20 cm |
| 170-180 cm | 40 cm | Medium | 15-20 cm |
| 180-190 cm | 45 cm | Medium-long | 15-20 cm |
| 190-200 cm | 50 cm | Longer (looser) | 15-20 cm |

The target is the same for all operators (15-20 cm). Taller operators need longer bungee cords and more strap length to achieve the same sensor height.

#### Terrain Adaptation

- **Tall grass or rough ground:** Raise sensors to 25-30 cm to prevent snagging. This reduces near-surface sensitivity slightly but prevents damage.
- **Smooth, mown ground:** Lower sensors to 10-15 cm for maximum sensitivity.
- **Slopes:** Walk across-slope (contour lines) rather than up/down when possible. The bungee system compensates for moderate slopes.

#### Fit Verification Checklist

- [ ] Weight is on shoulders and hips, not on arms
- [ ] Hands rest lightly on crossbar for guidance only (no gripping)
- [ ] Bottom sensors 15-20 cm above ground on level surface
- [ ] Walking at 1 m/s, sensor bounce is less than 5 cm
- [ ] Crossbar is level (not tilted left or right)
- [ ] Operator can don and doff the harness in under 30 seconds using carabiners

---

## Phase 6: Initial Testing (30-60 minutes)

### Step 6.1: Flash Firmware

**Prerequisites:**
- PlatformIO installed (VS Code with PlatformIO extension, or PlatformIO CLI)
- Arduino Nano connected via USB
- All wiring from Phase 2 complete

**Procedure:**

1. Connect the Arduino Nano to your computer via USB.
2. Navigate to the firmware directory and build/upload:
   ```bash
   cd firmware && pio run -t upload
   ```
3. Wait for the upload to complete. PlatformIO will auto-detect the serial port in most cases.
4. If the upload fails with a serial port error, specify the port manually:
   ```bash
   pio run -t upload --upload-port /dev/ttyUSB0   # Linux
   pio run -t upload --upload-port COM3            # Windows
   ```

### Step 6.2: Power-On Verification

1. Disconnect USB (you will now run on battery power).
2. Connect the LiPo battery.
3. Turn on the power switch.
4. **Observe the status LED sequence:**

   | LED Pattern | Meaning | Duration |
   |-------------|---------|----------|
   | Fast blink (100ms) | Startup / initialization | 2-3 seconds |
   | Medium blink (500ms) | Waiting for GPS lock | Until GPS locks (may be minutes) |
   | Slow blink (2000ms) | Normal logging | Continuous during operation |
   | Fast blink (100ms) | Error condition | Continuous until resolved |

5. If the LED shows fast blink after startup and does not transition to medium blink, there is an initialization error. Connect via USB and check the serial debug output.

### Step 6.3: Serial Debug Output

1. Connect the Arduino Nano via USB (you can run on USB power or battery simultaneously).
2. Open a serial monitor at **115200 baud**.
3. You should see initialization messages:
   ```
   Pathfinder Gradiometer v1.4.0
   Initializing...
   ADS1115 #1 (0x48): OK
   ADS1115 #2 (0x49): OK
   SD card: OK
   GPS: Waiting for fix...
   Logging to PATH0001.CSV
   ```
4. Verify all modules report OK. Any module that reports FAIL needs its wiring checked (refer to Troubleshooting section).

### Step 6.4: Sensor Readings Check

1. With all 8 sensors connected and the system powered on, observe the serial debug output.
2. Every 10 samples (approximately once per second at 10 Hz), the firmware prints current readings:
   ```
   P1: T=16234 B=16890 G=656
   P2: T=16180 B=16802 G=622
   P3: T=16301 B=16945 G=644
   P4: T=16155 B=16778 G=623
   ```
   - T = top sensor raw ADC value
   - B = bottom sensor raw ADC value
   - G = gradient (bottom minus top)

3. **What to look for:**
   - All 8 channels should show non-zero readings.
   - Gradient values should be roughly similar across all 4 pairs (within ~20% of each other in a uniform field).
   - Readings should be stable (not jumping wildly between samples).
   - No channel should be at 0 or 32767 (saturation).

4. **Move a ferrous object (screwdriver, key) near one sensor pair.** The gradient for that pair should change noticeably while the others remain stable. This confirms the channels are independent and correctly mapped.

### Step 6.5: First Field Walk

1. Take the fully assembled Pathfinder outdoors to an open area with GPS sky view.
2. Power on and wait for GPS lock (LED transitions from medium to slow blink). This may take 1-2 minutes for a cold start.
3. Walk a short test line (20-30 meters) at a steady pace (~1 m/s). The beeper should sound once per second to help maintain pace.
4. After the walk, turn off the system.
5. Remove the SD card and insert it in your computer.
6. Look for the CSV data file (e.g., `PATH0001.CSV`).
7. Visualize the test data:
   ```bash
   python firmware/tools/visualize_data.py PATH0001.CSV
   ```
   This produces a time-series plot of all 4 gradients. You should see smooth traces with some variation where you walked over buried objects or changes in soil.

8. For a spatial map (requires GPS fix):
   ```bash
   python firmware/tools/visualize_data.py PATH0001.CSV --map
   ```

### Step 6.6: Calibration

After verifying that the system collects data correctly, perform the calibration procedure. Calibration ensures that all 4 sensor pairs produce consistent gradient readings for the same magnetic anomaly.

**Note:** A dedicated calibration document is under development. In the meantime, the basic calibration procedure is:

1. Find a location with known or no magnetic anomalies (open field, away from buildings and metal fences).
2. Collect data while walking a straight line at constant pace.
3. Compute the mean and standard deviation of each pair's gradient in the quiet zone.
4. Apply offset corrections so all pairs read approximately zero gradient in the quiet zone.
5. Walk over a known ferrous target (e.g., a buried nail at 20 cm depth) and verify all pairs produce similar gradient magnitudes when passing directly over it.

---

## Troubleshooting Build Issues

### ADS1115 ADC Not Found on I2C Bus

**Symptom:** I2C scanner does not find 0x48 or 0x49. Serial output shows "ADS1115 not found."

**Solutions (check in order):**
1. Verify power: measure 5V on the ADS1115 VDD pin with a multimeter.
2. Verify ground: confirm continuity between ADS1115 GND and Arduino GND.
3. Check SDA/SCL wiring: confirm A4 connects to all SDA pins and A5 connects to all SCL pins.
4. Verify ADDR pin: Module 1 ADDR should measure 0V (GND). Module 2 ADDR should measure 5V (VDD).
5. Check for solder bridges on the ADS1115 module.
6. Try each ADS1115 module individually (disconnect one, scan for the other).
7. Upload the I2C scanner sketch and check all detected addresses. If the module appears at an unexpected address, the ADDR wiring is wrong.

### GPS Not Receiving Data

**Symptom:** No NMEA sentences on serial monitor. GPS power LED may or may not be lit.

**Solutions:**
1. Verify power: GPS VCC should measure 5V (or 3.3V if using the 3V3 pin).
2. Check TX/RX wiring: GPS TX must connect to Arduino D4 (RX). This is the most common mistake -- people connect TX to TX.
3. Verify baud rate: the NEO-6M default is 9600. The firmware uses `GPS_BAUD` defined in `config.h` (default 9600). If your GPS module uses a different baud rate, update the config.
4. Try powering the GPS module on its own with just VCC and GND, and probe the TX pin with an oscilloscope or multimeter on AC mode. You should see activity.
5. Ensure the GPS antenna has a clear view of the sky. It will not get a fix indoors, and the first cold-start fix can take 1-2 minutes.

### SD Card Not Initializing

**Symptom:** Serial output shows "SD card failed" or similar.

**Solutions:**
1. Verify the CS pin is connected to D10 (not another pin).
2. Check all SPI wiring: MOSI (D11), MISO (D12), SCK (D13).
3. Verify power to the SD module.
4. Try a different SD card. Some cards are incompatible with certain modules.
5. Ensure the card is formatted as FAT32. Cards larger than 32 GB often come formatted as exFAT, which the Arduino SD library cannot read. Use a formatting tool to reformat as FAT32.
6. Check that the card is fully seated in the module's socket.
7. Try a Class 10 card if you are using a slower card.

### No Gradient Readings (All Zeros or Static Values)

**Symptom:** ADC values are stuck at 0, 32767, or a constant value that does not change when moving a magnet near the sensors.

**Solutions:**
1. Check sensor power: each fluxgate sensor should be receiving 5V and GND.
2. Verify the LM2917 frequency-to-voltage converter is working: measure the DC output voltage with a multimeter. It should be between 0.5V and 4.0V and should change when you move a magnet near the sensor.
3. Check the signal path from the LM2917 output through the cable to the ADS1115 analog input.
4. If the ADC reads 32767 (full scale), the input voltage is above the ADC range. Check the LM2917 output voltage and adjust timing components if needed.
5. If the ADC reads 0, the signal wire may be disconnected or shorted to GND.
6. Check the channel mapping: verify that each sensor cable goes to the correct ADS1115 input (see the table in Step 2.8).

### Inconsistent Readings Between Pairs

**Symptom:** One or two pairs show much noisier or offset readings compared to others, even in a uniform magnetic field.

**Solutions:**
1. **Cable routing:** If a sensor cable runs close to the power cable or buck converter, it will pick up switching noise. Re-route sensor cables at least 5 cm from power wires.
2. **Sensor alignment:** Verify that all sensors in a pair are oriented with the same axis. A rotated sensor will read a different component of the magnetic field.
3. **Loose connections:** Wiggle each connector and cable while observing serial output. If readings jump when you move a cable, there is a bad connection.
4. **Shield grounding:** Verify that each cable shield is grounded at the enclosure end only, not at the sensor end.
5. **Bypass capacitors:** Ensure 0.1 uF caps are installed on each ADS1115 VDD pin and on the sensor power rail.
6. **LM2917 component variation:** If using hand-selected timing components, slight differences in resistor/capacitor values between channels will produce offset differences. This is corrected during calibration.

### Beeper Not Sounding

**Symptom:** No audible tone during operation.

**Solutions:**
1. Check that `ENABLE_BEEPER` is set to 1 in `config.h`.
2. Verify the MOSFET is correctly oriented (check pinout: Source, Gate, Drain for TO-92).
3. Measure the gate voltage with a multimeter while the beeper should be active. It should pulse between 0V and ~5V.
4. Check the buzzer polarity (positive terminal to 5V, negative to MOSFET drain).
5. Try connecting the buzzer directly between D9 and GND temporarily to rule out MOSFET issues.

### Status LED Not Working

**Symptom:** LED never illuminates.

**Solutions:**
1. Check LED polarity (anode to D2 via resistor, cathode to GND).
2. Verify the 220 ohm resistor is correct (red-red-brown-gold).
3. Measure voltage on D2 with a multimeter when the LED should be on. It should read ~5V.
4. Try a different LED.

### System Resets or Freezes

**Symptom:** The system restarts unexpectedly or stops logging data.

**Solutions:**
1. **Insufficient power:** The buck converter may not supply enough current when all sensors are active. Measure the 5V rail under full load. If it droops below 4.5V, you need a higher-rated regulator (>600 mA output).
2. **Loose battery connection:** Vibration during walking can cause intermittent power drops. Secure the battery connector with tape or a cable tie.
3. **SD card write failures:** If the SD card is slow or failing, the system may stall. Try a different Class 10 card.
4. **Memory issues:** The Arduino Nano has only 2 KB of SRAM. If the firmware is modified with large strings or arrays, it may run out of memory. Check the build output for SRAM usage -- it should be below 75%.

---

## Safety Notes

### Battery Safety

- Use a proper LiPo balance charger (not a generic power adapter).
- Never charge the battery unattended.
- Store the battery in a LiPo-safe bag when not in use.
- Inspect the battery before each use: do not use if swollen, dented, or showing damaged insulation.
- Disconnect the battery from the system when not in use.
- Operating temperature range: 0 to 45 degrees C. Do not charge below 0 degrees C.

### Electrical Safety

- Double-check polarity before connecting the battery for the first time. Reverse polarity will destroy the buck converter and potentially other modules.
- Use a fuse or polyfuse on the battery positive lead (1A recommended) to protect against short circuits.
- Cover all exposed connections with heat shrink tubing or electrical tape.
- Work on a non-conductive surface when soldering or wiring.

### Field Safety

- Use quick-release carabiners so the operator can doff the harness quickly in an emergency.
- Do not survey during thunderstorms. The carbon fiber crossbar can attract lightning.
- Take 10-minute rest breaks every hour to prevent back and shoulder fatigue.
- Verify proper harness fit before each survey session to prevent strain injuries.
- Stay aware of terrain hazards (holes, roots, fences) since your attention will be partly on the instrument.

### Carbon Fiber Safety

- Wear a dust mask and safety glasses when cutting or drilling carbon fiber.
- Carbon fiber splinters are extremely fine and difficult to remove from skin. Handle cut edges carefully.
- Work in a well-ventilated area or outdoors.
- Clean up all carbon fiber dust and debris after cutting.

---

## Pre-Survey Checklist

Run through this list before every survey session:

### Hardware Checks
- [ ] All crossbar bolts tight (drop tubes do not wobble)
- [ ] Bungee cords show no fraying or wear
- [ ] All carabiners close and lock properly
- [ ] Power switch functions (LED responds)
- [ ] Battery charged (>7.0V measured at connector)
- [ ] SD card inserted with free space (>100 MB)
- [ ] All sensor cables securely connected
- [ ] All sensor cables labeled correctly
- [ ] Sensors aligned (same orientation)
- [ ] Cable glands tight on enclosure

### Software Checks
- [ ] GPS acquires fix (LED slow blink)
- [ ] Serial debug shows all modules OK
- [ ] ADC readings from all 8 channels are reasonable
- [ ] Beeper sounds at correct interval
- [ ] New log file created on SD card

### Fit Checks
- [ ] Harness adjusted for operator
- [ ] Bottom sensors at 15-20 cm height
- [ ] Crossbar level
- [ ] Can walk at 1 m/s without sensors dragging

---

## Field Repair Kit

Carry these items in a belt pouch during surveys:

| Item | Quantity | Purpose |
|---|---|---|
| Multi-tool | 1 | General repairs |
| Spare carabiners | 2 | Replace failed clip |
| Cable ties (200mm) | 10 | Emergency cable/sensor mounting |
| Duct tape | 1 small roll | Temporary fixes |
| Spare bungee cord (1m) | 1 | Replace snapped bungee |
| Spare JST connectors | 2 sets | Replace damaged sensor cables |
| Electrical tape | 1 small roll | Insulate exposed wires |
| Spare SD card (formatted FAT32) | 1 | Replace failed card |
| Spare LiPo battery | 1 | Extended survey sessions |
| Spare fuse (1A) | 2 | Replace blown fuse |
| Small screwdriver set | 1 | Tighten terminal blocks |

---

## Appendix A: Firmware Configuration Reference

Key settings in `firmware/include/config.h` that you may want to adjust:

| Setting | Default | Description |
|---|---|---|
| `NUM_SENSOR_PAIRS` | 4 | Number of active sensor pairs (1-4) |
| `SAMPLE_RATE_HZ` | 10 | Readings per second |
| `GPS_BAUD` | 9600 | GPS module baud rate |
| `ADC_GAIN` | GAIN_ONE | ADS1115 gain (+/- 4.096V range) |
| `ADC_DATA_RATE` | 128 | ADS1115 samples per second per channel |
| `ENABLE_BEEPER` | 1 | Enable/disable pace beeper |
| `BEEP_INTERVAL_MS` | 1000 | Milliseconds between beeps |
| `SERIAL_DEBUG` | 1 | Enable serial debug output (disable to save power) |
| `SD_FLUSH_INTERVAL` | 10 | Flush SD buffer every N samples |
| `ENABLE_WATCHDOG` | 0 | Hardware watchdog timer (test before enabling) |
| `ENABLE_RTC` | 0 | DS3231 real-time clock for absolute timestamps |

---

## Appendix B: Pin Reference Card

Print this and tape it inside the enclosure lid for field reference.

```
PATHFINDER PIN REFERENCE - Arduino Nano
=======================================
DIGITAL PINS:
  D2  = Status LED (via 220R)
  D3  = GPS TX (to GPS RX, unused by default)
  D4  = GPS RX (from GPS TX)
  D9  = Beeper (via MOSFET)
  D10 = SD Card CS
  D11 = SD Card MOSI (fixed HW SPI)
  D12 = SD Card MISO (fixed HW SPI)
  D13 = SD Card SCK  (fixed HW SPI)

ANALOG PINS:
  A4  = I2C SDA (to both ADS1115)
  A5  = I2C SCL (to both ADS1115)

I2C ADDRESSES:
  0x48 = ADS1115 #1 (ADDR=GND) - Pairs 1-2
  0x49 = ADS1115 #2 (ADDR=VDD) - Pairs 3-4

ADC CHANNEL MAP:
  ADS1 A0 = Pair 1 Top    ADS2 A0 = Pair 3 Top
  ADS1 A1 = Pair 1 Bot    ADS2 A1 = Pair 3 Bot
  ADS1 A2 = Pair 2 Top    ADS2 A2 = Pair 4 Top
  ADS1 A3 = Pair 2 Bot    ADS2 A3 = Pair 4 Bot

POWER:
  7.4V LiPo -> Switch -> Buck -> 5V bus
  Serial Debug: 115200 baud
```

---

## Appendix C: Related Documentation

| Document | Location | Contents |
|---|---|---|
| Wiring Guide | `firmware/WIRING.md` | Detailed pin-by-pin wiring reference |
| Bill of Materials | `hardware/bom/README.md` | Full priced BOM with suppliers |
| BOM Source Data | `hardware/bom/pathfinder-bom.csv` | Raw BOM data (CSV) |
| Frame Design | `hardware/cad/frame-design.md` | Frame dimensions, materials, parts |
| Main Board Schematic | `hardware/schematics/main-board.md` | Circuit diagrams, power budget |
| Design Concept | `docs/design-concept.md` | System architecture, performance targets |
| Firmware Config | `firmware/include/config.h` | All configurable parameters |
| Data Visualization | `firmware/tools/visualize_data.py` | Python tool for plotting survey data |
| Platform Variants | `docs/platform-variants.md` | Backpack and drone configurations |

---

## Revision History

| Version | Date | Changes |
|---|---|---|
| 1.0 | 2026-02-18 | Initial comprehensive build guide |

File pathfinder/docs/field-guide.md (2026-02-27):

# Pathfinder Field Operations Guide

A comprehensive guide for planning, executing, and interpreting magnetic gradiometer surveys with the Pathfinder system. Read this before your first field deployment. Print the Survey Log Template (Section 7) and the Troubleshooting table (Section 6) as pocket references.

---

## 1. Pre-Survey Planning

A successful survey starts the day before you go to the field. Rushing setup leads to missed anomalies, wasted time, and data that cannot be interpreted.

### 1.1 Site Assessment

Visit the site or study it on satellite imagery before survey day. Evaluate:

- **Terrain**: Flat, sloped, wooded, overgrown? Pathfinder works on any walkable terrain, but dense brush slows traverse pace and may snag the crossbar.
- **Access**: Where will you park? How far is the walk-in? Plan your route to avoid carrying the assembled trapeze through narrow gates or dense vegetation.
- **Known hazards**: Livestock, unstable ground, live utilities, restricted areas. Obtain landowner permission and any required permits before arrival.
- **Expected targets**: What are you looking for? The answer determines traverse spacing, coverage area, and how aggressively you interpret weak anomalies.
  - Ferrous debris (nails, shell casings): Strong signal, small footprint -- tight spacing helps.
  - Archaeological features (kilns, hearths): Moderate signal, broader footprint -- standard spacing works.
  - Disturbed soil (graves, pits): Very weak signal at Pathfinder's detection limit -- consider whether HIRT or a commercial gradiometer is more appropriate for this target class.
- **Magnetic environment**: Note proximity to power lines, fences, buildings with steel frames, railway lines, or buried utilities. These produce interference that can mask real targets or generate false positives.

### 1.2 Coverage Planning

Pathfinder's coverage rate depends on three factors: swath width, walking pace, and traverse spacing.

**Key numbers for the standard 4-pair configuration:**

| Parameter | Value | Notes |
|---|---|---|
| Sensor pairs | 4 | 50 cm horizontal spacing |
| Swath width | 2.0 m | Outer sensor to outer sensor |
| Effective swath | ~1.5 m | With recommended overlap |
| Walking pace | ~1 m/s | Beeper at 1 Hz guides cadence |
| Sample spacing | ~1 m along-track | At 10 Hz sample rate and 1 m/s pace |
| GPS sample rate | 1 Hz | NEO-6M default |

**Estimating survey time for a rectangular area:**

1. Determine the number of traverse lines: divide the cross-track dimension by the line spacing (typically 1.0 m for 50% swath overlap, or 1.5 m for minimal overlap).
2. Multiply the number of lines by the along-track length to get total traverse distance.
3. Divide total distance by walking speed (1 m/s) and add ~15 seconds per line for turns.
4. Add setup time (10-15 minutes) and a buffer for GPS issues or re-walks.

**Example: 50 x 50 m area with 50% overlap (1.0 m line spacing)**

| Step | Calculation | Result |
|---|---|---|
| Traverse lines | 50 m / 1.0 m | 50 lines |
| Total distance | 50 lines x 50 m | 2,500 m |
| Walking time | 2,500 m / 1 m/s | ~42 minutes |
| Turns | 50 x 15 s | ~12 minutes |
| Setup | -- | ~15 minutes |
| **Total** | | **~70 minutes** |

For initial reconnaissance where you want to cover ground quickly, increase line spacing to 2.0 m (no overlap). This cuts survey time roughly in half at the cost of leaving gaps between swaths. Any anomaly detected during the fast pass can be re-surveyed at tighter spacing.

### 1.3 Equipment Checklist

Pack the following before leaving for the field:

**Essential:**

- [ ] Pathfinder instrument (crossbar, drop tubes, sensors, electronics enclosure)
- [ ] Harness with bungee suspension
- [ ] Charged battery (check voltage >7.0 V)
- [ ] Spare battery
- [ ] SD card (FAT32 formatted, Class 10, capacity verified)
- [ ] Spare SD card
- [ ] Field notebook and pencil (not pen -- pens fail in rain and cold)
- [ ] Measuring tape (30 m minimum)
- [ ] Survey stakes or flags (for marking traverse start/end)

**Recommended:**

- [ ] Handheld GPS or phone with GPS for recording site reference point
- [ ] Multi-tool or small screwdriver set
- [ ] Spare carabiners (2x)
- [ ] Zip ties (10x)
- [ ] Duct tape
- [ ] Electrical tape
- [ ] Spare bungee cord (1 m)
- [ ] Laptop with Python and `visualize_data.py` (for on-site data QC)
- [ ] USB SD card reader
- [ ] Sunscreen, water, snacks

**Optional (for extended or high-precision surveys):**

- [ ] RTK GPS module (ZED-F9P) for sub-centimeter positioning
- [ ] Serial/USB cable for real-time debug monitoring
- [ ] Weather station or thermometer
- [ ] Camera for site documentation

### 1.4 Weather Considerations

Pathfinder is designed for all-weather operation (IP65 electronics enclosure), but environmental conditions affect both the operator and the data.

| Condition | Effect | Mitigation |
|---|---|---|
| Rain | Water ingress risk at cable glands; wet sensor cables can introduce noise | Verify cable gland seals before survey; use drip loops; dry equipment after survey |
| Cold (<5 C) | Battery capacity drops 20-40%; GPS may be slower to lock; fluxgate sensor offset drifts | Keep battery warm (insulate or body-heat pocket); allow extra warm-up time; take baseline reading at field temperature |
| Heat (>35 C) | Electronics may overheat in direct sun; operator fatigue increases | Shade the electronics enclosure; take frequent breaks; carry extra water |
| Wind | Crossbar sways, introducing tilt error; bungee suspension amplifies oscillation | Brace crossbar lightly with hands; shorten bungee cords; avoid survey in strong gusts |
| Thunderstorms | **Do not survey.** The carbon fiber crossbar and open terrain create a lightning risk. | Abort and seek shelter immediately. |

---

## 2. Site Setup

### 2.1 Establish the Site Grid

Even though GPS provides absolute coordinates, a physical grid on the ground keeps traverse lines parallel, ensures complete coverage, and provides a backup reference if GPS data has gaps.

1. **Choose a reference point.** Pick a permanent or semi-permanent feature (fence post, large rock, building corner) and record its GPS coordinates and a written description in your field notebook.
2. **Lay out the baseline.** Stretch a measuring tape along one edge of the survey area. This becomes your primary axis. Secure both ends with stakes.
3. **Mark traverse start and end points.** Place stakes or flags at your chosen line spacing (1.0 m or 2.0 m) along the baseline. If the area is large, mark every 5th stake with a different color for easy counting.
4. **Establish the cross-axis** at each end of the baseline so you know where to turn. A second tape or line of stakes perpendicular to the baseline defines the survey boundary.

For rough reconnaissance on open ground, you may skip the full grid and rely on GPS track logging alone. In this case, walk parallel lines by sighting on a distant landmark, and accept that line spacing will be approximate.

### 2.2 Power-On Sequence

Follow this sequence every time. Rushing past GPS lock is the most common cause of data without position.

1. **Insert the SD card** (FAT32, confirmed space available).
2. **Power on.** The status LED starts fast blinking (100 ms) during initialization.
3. **Watch the LED transition:**
   - Fast blink (100 ms) = Error. Check SD card. If the LED stays fast, the SD card is not detected. Remove, reinsert, try a different card.
   - Medium blink (500 ms) = Waiting for GPS lock. Normal on cold start; wait up to 2 minutes.
   - **Slow blink (2 s) = GPS locked and logging.** The system is ready.
4. **Listen for the beeper.** One beep per second confirms the pace timer is running (handheld/backpack platforms only; the drone platform disables the beeper).
5. **Check serial debug output** (optional). Connect a laptop via USB and open a serial terminal at 115200 baud. You should see:
   ```
   Pathfinder Gradiometer v1.4.0 (2026-02-18)
   Platform: HANDHELD
   Sensor pairs: 4
   ADS1115 #1 (0x48) OK
   ADS1115 #2 (0x49) OK
   GPS initialized at 9600 baud
   SD card ready
   Created log file: PATH0001.CSV
   Initialization complete. Starting acquisition...
   Sample rate: 10 Hz
   ```
   Verify both ADCs report OK and the log file was created.

### 2.3 Test Sample Acquisition

Before committing to the full survey, walk a short test line (20-30 m) and verify that data is being collected:

1. Walk a straight line at beeper pace.
2. Stop. Power off. Remove SD card.
3. Insert card into laptop. Open the newest `PATHXXXX.CSV` file.
4. Verify it contains data rows (not just the header).
5. Check that `lat` and `lon` columns contain non-zero values (GPS was locked).
6. Optionally, run `python visualize_data.py PATHXXXX.CSV --stats-only` for a quick summary.
7. Reinsert the SD card, power on, wait for slow blink, and begin the survey.

This takes 5 minutes and can save an entire day of surveying with a bad SD card or loose cable.

---

## 3. Survey Execution

### 3.1 Walking Technique

Data quality depends more on consistent operator technique than on instrument specifications. Practice these habits until they become automatic.

**Pace:** Match the beeper cadence. One beep per second produces approximately one meter per stride. Resist the urge to walk faster -- rushing creates irregular sample spacing and increases crossbar tilt.

**Crossbar level:** Tilt introduces error proportional to Earth's field multiplied by sin(tilt angle). At typical mid-latitude field strengths (~50,000 nT), a 5-degree tilt produces ~4,400 nT of apparent field change, which is enormous relative to the anomalies we are trying to detect. The gradiometer configuration cancels most of this (both sensors tilt together), but any difference in the sensors' orientation sensitivity creates a residual. Keep the crossbar as level as possible. The bungee suspension helps, but you must avoid sudden lateral movements.

**Consistent height:** The harness sets the bottom sensors at 15-20 cm above ground (Target). Adjust the shoulder straps on level ground before beginning. If terrain varies significantly (e.g., crossing a ditch), note the location in your field notebook rather than trying to adjust mid-traverse.

**Avoid metal on the operator:** Before your first traverse, remove or relocate:

- Belt buckles (move to pocket or use a plastic buckle)
- Keys (leave in vehicle or bag at edge of survey area)
- Mobile phone (leave at baseline or carry in a rear pocket, not hip pocket near sensors)
- Watch (especially steel case or band)
- Steel-toe boots (if possible, wear non-ferrous footwear)

Test by standing still and rotating slowly. If the gradient values on the serial debug output shift as you rotate, you are carrying something magnetic. Remove items until the values stabilize.

**Walking direction:** Walk in a consistent direction (all lines north-to-south, for example) for simplest data processing. Bidirectional (zigzag) surveying is more time-efficient because you eliminate the walk-back between lines, but you must record which lines were walked in which direction so that heading-dependent errors can be corrected in post-processing. Note direction changes in your field notebook or mark them with flags.

### 3.2 Traverse Patterns

Choose a pattern based on survey objectives and site geometry.

**Parallel lines (standard)**

The default pattern for systematic area coverage. Walk parallel lines with consistent spacing.

```
Start -->-->-->-->-->-->-->--> End
       |
       v  (step over by line spacing)
       |
      <--<--<--<--<--<--<--<-- Turn
       |
       v
       |
      -->-->-->-->-->-->-->--> Continue
```

- **50% swath overlap (1.0 m line spacing):** Every point on the ground is covered by at least one sensor pair. Provides redundancy and the best spatial resolution. Use for detailed surveys.
- **Minimal overlap (1.5-2.0 m line spacing):** Faster coverage. Some narrow gaps between swaths. Acceptable for initial reconnaissance where you plan to re-survey anomalies.

**Zigzag (bidirectional)**

Walk alternating directions to eliminate the dead walk-back. More efficient for large areas. Record direction changes in field notes or toggle a flag at each turn.

**Radial pattern**

For investigating a known point anomaly (e.g., a feature detected during reconnaissance). Walk lines radiating outward from the anomaly center, like spokes of a wheel. This gives high sample density near the target and sparser coverage at the edges.

### 3.3 Data Quality Monitoring

Check data quality periodically during the survey rather than discovering problems after you leave the site.

**Serial debug output** (if connected): Every 10 samples, the firmware prints a summary line:

```
S:1230 GPS:51.234567,18.345678 G1:225 G2:218 G3:210 G4:223
```

Watch for:

| Indicator | Normal | Problem | Action |
|---|---|---|---|
| GPS coordinates | Non-zero, changing as you walk | `GPS:--` or coordinates stuck | Wait for lock; check sky view |
| Gradient values (G1-G4) | Baseline near zero (after calibration), spikes at anomalies | All near zero constantly | Check sensor cables; verify ADC addresses |
| Gradient values | Reasonable range (-500 to +500 typical) | Values hitting 32000 or -32000 | ADC saturated -- too close to large metal; move away |
| `SD_ERR:` | Absent | Count increasing | SD card issue; finish current line, then swap card |
| `SAT:` | Absent or low | Count climbing rapidly | Near large ferrous source; note location and move on |

**Beeper cadence:** If the beeper stops or becomes erratic, the system may have frozen. Power cycle and check the SD card.

**Physical checks:** Every 10-15 lines, verify that sensor cables have not snagged or pulled loose from the crossbar, that the SD card LED (if visible) blinks during writes, and that the battery voltage remains above 7.0 V.

---

## 4. Data Download and Verification

Do not leave the site until you have verified that usable data was collected. An extra 10 minutes of checking in the field can save a return trip.

### 4.1 Download Procedure

1. Power off the Pathfinder.
2. Remove the SD card carefully (do not force -- it uses a push-to-release mechanism on most modules).
3. Insert into a laptop via USB card reader.
4. Copy **all** `PATHXXXX.CSV` files from the card to your laptop. Each power cycle creates a new file (PATH0001, PATH0002, etc.).
5. Do not delete files from the SD card until you have verified the copies.

### 4.2 Quick Verification

Run the visualization tool on each file:

```bash
python visualize_data.py PATH0001.CSV
```

This produces three plots. Check each one:

**Time series plot:**
- Gradient traces should show a stable baseline with distinct spikes at anomaly locations.
- Look for large gaps in the timeline (= missed samples, possible SD write stalls).
- Look for sudden jumps in all channels simultaneously (= operator bumped the system or walked past a large metal object like a fence).

**GPS track plot (requires `--map` flag):**
- The track should match the pattern you walked (parallel lines, zigzag, etc.).
- Missing track segments indicate GPS dropouts.
- If the entire track is at (0, 0), GPS was never locked.

**Statistics output:**
- GPS lock percentage should be >90%. Below 80% means significant position data is missing.
- Gradient mean should be near zero for each pair (if your calibration offsets are applied).
- Gradient standard deviation indicates the noise level and signal strength.

### 4.3 Backup

Before leaving the site:

1. Verify the laptop copy opens and contains data.
2. Copy to a second medium (USB drive, cloud upload via phone hotspot, or email a compressed archive to yourself).
3. Reinsert the SD card into the Pathfinder (or store separately in a labeled bag).
4. Record in your field notebook which files correspond to which survey areas.

---

## 5. Data Interpretation Guide

This section provides practical guidance for interpreting Pathfinder gradient data. Pathfinder is a screening tool -- it identifies areas of interest for follow-up with detailed systems like HIRT, GPR, or commercial gradiometers. Interpretation at the screening stage is about classification and prioritization, not definitive identification.

### 5.1 What Gradient Anomalies Look Like

The gradiometer measures the vertical gradient of the magnetic field -- the difference between the bottom sensor (closer to the ground and the target) and the top sensor (farther away, measuring background). Anomalies appear as departures from the baseline gradient.

| Target Type | Gradient Strength | Signature Shape | Detection Depth (Modeled) |
|---|---|---|---|
| **Ferrous metal** (iron, steel -- nails, tools, ordnance, pipes) | Strong: 100-1,000+ nT | Sharp, dipolar (positive and negative lobes) | 20-100 cm for small objects; 1-2 m for large objects |
| **Fired clay** (kilns, hearths, brick) | Moderate: 20-100 nT | Broader anomaly, less sharp than metal | 30-60 cm |
| **Disturbed soil** (graves, pits, ditches) | Very weak: 5-20 nT | Broad, diffuse | 20-50 cm; **at Pathfinder's detection limit** |
| **Geological features** (igneous intrusions, mineralisation) | Variable: 10-500 nT | Very broad, regional trends across multiple traverse lines | Extends to depth |
| **Modern interference** (fences, utilities, vehicles) | Strong: 100-10,000+ nT | Linear (fences, pipes) or very strong point (vehicles, manholes) | Surface or shallow |

**Note:** Gradient strength values above are approximate and depend on target size, depth, magnetic susceptibility, and soil conditions. All detection depths are **(Modeled)** based on published fluxgate gradiometer performance for similar sensor configurations.

### 5.2 Anomaly Classification Quick Reference

Use this table to make initial field classifications. These are starting points for prioritization, not definitive identifications.

| Gradient (nT) | Spatial Extent | Shape | Likely Source | Priority |
|---|---|---|---|---|
| >500 | Point-like (<2 m) | Sharp dipole | Ferrous metal near surface | HIGH -- investigate or avoid (UXO context) |
| 100-500 | Point to small area | Dipolar | Buried metal, fired feature | HIGH -- mark for follow-up |
| 20-100 | Small area (2-5 m) | Broad, asymmetric | Fired clay, large pit fill, deep metal | MEDIUM -- characterize with detailed survey |
| 5-20 | Area (>3 m) | Diffuse | Disturbed soil, subtle archaeology | LOW -- may be at detection limit; consider confirmation with HIRT or GPR |
| <5 | Regional | Gradual trend | Geological variation, instrument drift | BACKGROUND -- usually not actionable |

### 5.3 Depth Estimation

For isolated dipole sources (small metal objects, discrete archaeological features), a rough depth estimate can be made from the anomaly width:

**Rule of thumb: Anomaly half-width is approximately equal to source depth.**

The "half-width" is the horizontal distance from the anomaly peak to the point where the signal drops to half its peak value. For a compact magnetic dipole source, this distance roughly equals the depth below the sensor. Since the bottom sensor is 15-20 cm above ground (Target), add the sensor height to get depth below the ground surface.

**Example:** An anomaly peaks at traverse position 25.0 m and drops to half its peak value at positions 24.5 m and 25.5 m. The half-width is 0.5 m. Estimated depth below sensor: ~0.5 m. Estimated depth below ground: ~0.5 m + 0.15 m (sensor height) = ~0.65 m.

**Limitations:**
- This rule applies only to compact, isolated dipole sources. Extended features (ditches, walls) do not follow this relationship.
- Multiple overlapping anomalies invalidate the half-width measurement.
- The rule provides order-of-magnitude guidance, not precision. Expect errors of 30-50%.
- For precise depth estimation, use HIRT or another system with tomographic capability.

### 5.4 False Positives

Not every anomaly indicates a buried target of interest. Common false positive sources:

| Source | How to Recognize | Prevention |
|---|---|---|
| Surface debris (nails, wire, cans) | Very strong, very narrow spike; only on one traverse line | Walk the survey area first and remove visible surface metal |
| Nearby vehicles | Extremely strong anomaly (>10,000 nT) that appears on multiple lines near the same location; decreases as you walk away | Park vehicles at least 20 m from survey area (farther for trucks) |
| Operator metal | Consistent offset or drift correlated with operator position; changes if operator rotates | Remove all metal before surveying; test by rotating in place |
| Fences | Linear anomaly aligned with known fence line; repeating pattern at post intervals | Map known fences on your site plan; exclude data within 3-5 m of fences |
| Underground utilities | Linear anomaly, often strong, following a straight line | Consult utility maps; mark known utility corridors on site plan |
| Geology | Broad, gentle gradients spanning the entire survey area | Usually removed by regional trend subtraction in post-processing |

---

## 6. Troubleshooting

### 6.1 Quick Reference Table

Consult this table first when something goes wrong in the field.

| Symptom | Likely Cause | Solution |
|---|---|---|
| LED stays fast blink (100 ms) after startup | SD card not detected | Remove SD card, reinsert firmly. Verify FAT32 format. Try a different card. |
| LED stays medium blink (500 ms) for >5 minutes | No GPS satellite lock | Move to open area with clear sky view. Check GPS antenna connection. Wait -- cold starts can take 2-3 minutes. If still no lock after 5 minutes, try a different location (buildings and trees block satellite signals). |
| No LED activity at all | No power | Check battery voltage (should be >7.0 V). Check power switch. Check regulator output (should be 5.0 V +/- 0.1 V). |
| SD write errors increasing (`SD_ERR:` in serial output) | SD card full, failing, or loose | Check remaining card space. Try a different card. Reseat the SD card connection. Power cycle. |
| All gradient values near zero | Sensor cables disconnected or ADC not communicating | Check all sensor cable connections at the crossbar and at the electronics enclosure. Verify both ADS1115 modules detected at startup (check serial output). Run an I2C scanner sketch if needed. |
| Gradient values very noisy (large random fluctuations) | Electromagnetic interference or poor shielding | Move away from power lines, vehicles, radio transmitters. Check that sensor cable shields are grounded at the enclosure end only. Verify battery voltage (low voltage increases ADC noise). |
| One pair reads differently from the others | Cable fault, sensor alignment, or ADC channel issue | Swap the suspect pair's cable with a known-good cable. Check that the sensor pair is vertically aligned (top and bottom sensors parallel). Check the ADC channel wiring. |
| Beeper not sounding | Beeper disabled in firmware, wiring issue, or buzzer failure | Verify `ENABLE_BEEPER` is set to 1 in `config.h`. Check buzzer wiring (pin D9 to buzzer positive, buzzer negative to GND). Test buzzer with a multimeter or direct 5 V. |
| Serial output garbled or unreadable | Baud rate mismatch | Set your terminal to 115200 baud, 8N1. Verify `SERIAL_BAUD` in `config.h` matches. |
| GPS coordinates present but track looks wrong | GPS multipath or position jumps | Common near buildings and under tree canopy. Filter in post-processing by removing samples with HDOP >5 (requires `GPS_LOG_QUALITY=1` in config). |
| Gradients spike at every step | Operator carrying magnetic material | Remove belt buckle, keys, phone, watch, steel-toe boots. Test by standing still. |
| Firmware version or pair count mismatch | Wrong build uploaded | Rebuild with correct `NUM_SENSOR_PAIRS` and platform flags. Verify with serial output at startup. |

### 6.2 Detailed Procedures

#### No GPS Lock After 5 Minutes

GPS modules require clear line-of-sight to at least 4 satellites. The NEO-6M typically acquires a fix in 30-60 seconds with good sky view (cold start), but can take longer in challenging conditions.

**Step-by-step diagnosis:**

1. Confirm the GPS module power LED is on (visible through the enclosure vent or cable gland window).
2. Move to the most open area available -- away from buildings, vehicles, dense tree canopy, and cliff faces.
3. Orient the GPS antenna toward the sky (it should face upward, not be shadowed by the crossbar or enclosure).
4. Wait 3 full minutes without moving.
5. If still no lock, check the serial debug output for NMEA sentences. If you see `$GPGGA` sentences with all zeros in the position fields, the GPS is receiving data but cannot compute a fix -- this is a sky-view problem. If you see no NMEA data at all, the GPS module is not communicating -- check wiring (GPS TX to Arduino pin D4) and baud rate (default 9600 for NEO-6M).
6. As a last resort, power cycle the entire system. Some GPS modules enter a bad state on rare occasions.

**Note:** Pathfinder logs data even without GPS lock -- timestamps and gradient values are still recorded. You can survey without GPS if you maintain a careful physical grid and record your position from field notes. The data will lack automatic georeferencing but remains scientifically usable.

#### SD Card Problems

The firmware automatically increments file numbers (PATH0001.CSV, PATH0002.CSV, etc.) and attempts to reopen the file after 5 consecutive write errors.

- **Card full:** The system creates files until the card runs out of space. A 2 GB card holds approximately 100 hours of survey data at 10 Hz with 4 pairs. Check free space before each survey day.
- **Card failing:** Repeated `SD_ERR` counts that do not reset after file reopen suggest a hardware fault. Swap to a new card immediately. Cheap SD cards have higher failure rates -- use name-brand Class 10 cards.
- **Card formatting:** Pathfinder requires FAT32. Cards larger than 32 GB are often pre-formatted as exFAT, which the SdFat library does not support. Reformat as FAT32 using your computer's disk utility.

#### High Noise

If gradient values fluctuate by more than 50 ADC counts when the system is stationary in a quiet location, investigate:

1. Battery voltage -- below 7.0 V, the regulator may drop out of regulation, increasing ADC noise.
2. Cable shielding -- sensor cable shields must be connected to ground at the electronics enclosure end only. Double-grounding creates a ground loop that injects 50/60 Hz noise.
3. I2C cable length -- keep the wires between the Arduino and the ADS1115 modules short (<30 cm). Long I2C runs pick up interference.
4. Nearby EMI sources -- power lines, cell towers, and running vehicle engines all generate magnetic noise. Survey at least 20 m from these sources.

---

## 7. Survey Log Template

Print this template and fill out one copy per survey session. Keep it with your SD card and field notebook.

```
================================================================================
PATHFINDER SURVEY LOG
================================================================================

Date: _______________     Operator: _________________________________

Site name: __________________________________________________________________

Site description / address: _________________________________________________

____________________________________________________________________________

GPS reference point:  Lat: _________________  Lon: _________________

Description of reference point: _____________________________________________

____________________________________________________________________________

Weather:  ☐ Clear  ☐ Overcast  ☐ Light rain  ☐ Windy  ☐ Cold (<5 C)  ☐ Hot (>35 C)

Temperature: _________ C (approx.)

================================================================================
EQUIPMENT
================================================================================

Instrument:    Pathfinder v_______     Platform: ☐ Handheld  ☐ Backpack  ☐ Drone

Sensor pairs:  _______                Sample rate: _______ Hz

GPS module:    ☐ NEO-6M (standard)    ☐ NEO-M9N    ☐ ZED-F9P (RTK)

Battery voltage at start: _______ V   Battery voltage at end: _______ V

SD card label/ID: _______________

================================================================================
SURVEY PARAMETERS
================================================================================

Survey area dimensions: _______ m x _______ m

Traverse direction: ☐ N-S  ☐ E-W  ☐ Other: ___________

Traverse line spacing: _______ m

Walking direction: ☐ Unidirectional  ☐ Bidirectional (zigzag)

Total number of traverse lines: _______

================================================================================
TIMING
================================================================================

Time start: _______________     Time end: _______________

GPS lock achieved at: _______________

Survey start time: _______________     Survey end time: _______________

SD files created: PATH________ to PATH________

================================================================================
CALIBRATION
================================================================================

Baseline reading taken:  ☐ Yes  ☐ No

Gradient baseline values (static, from test line or calibration):

  Pair 1: _______   Pair 2: _______   Pair 3: _______   Pair 4: _______

Last full calibration date: _______________

================================================================================
FIELD OBSERVATIONS
================================================================================

Known metal/interference near survey area:

____________________________________________________________________________

____________________________________________________________________________

Anomalies noted during survey (location, strength, description):

____________________________________________________________________________

____________________________________________________________________________

____________________________________________________________________________

____________________________________________________________________________

Equipment issues or unusual behavior:

____________________________________________________________________________

____________________________________________________________________________

General notes:

____________________________________________________________________________

____________________________________________________________________________

____________________________________________________________________________

____________________________________________________________________________

================================================================================
POST-SURVEY CHECKLIST
================================================================================

☐ Data downloaded from SD card
☐ Data verified (visualize_data.py or manual CSV check)
☐ Data backed up to second medium
☐ SD card relabeled and stored
☐ Equipment powered off and packed
☐ Site restored (stakes removed if required)
☐ This log form completed

Signature: __________________________     Date: _______________

================================================================================
```

---

## 8. Post-Processing Workflow Summary

This section provides a brief overview of what to do with your data after the survey. For detailed post-processing instructions, see the `firmware/tools/README.md` and `firmware/CALIBRATION.md` documents.

### 8.1 Basic Processing Steps

1. **Transfer** all CSV files from the SD card to your working directory.
2. **Visualize** each file:
   ```bash
   python visualize_data.py PATH0001.CSV          # Time series
   python visualize_data.py PATH0001.CSV --map     # Spatial map
   python visualize_data.py PATH0001.CSV --hist    # Gradient distributions
   python visualize_data.py PATH0001.CSV --stats-only  # Statistics only
   ```
3. **Apply calibration offsets** from your most recent calibration record (see `CALIBRATION.md`).
4. **Filter** GPS dropouts: remove rows where `lat` and `lon` are both zero.
5. **Grid** the point data to a regular grid using kriging or inverse-distance weighting. Standard GIS tools (QGIS, ArcGIS) and Python libraries (scipy, verde) can do this.
6. **Visualize** the gridded gradient map. Color-scale the gradient values to highlight anomalies.
7. **Mark anomalies** on a site plan with GPS coordinates and estimated gradient strength.
8. **Plan follow-up** using HIRT, GPR, or a commercial gradiometer for anomalies requiring detailed characterization.

### 8.2 Export to GIS

Pathfinder CSV data can be imported directly into QGIS or ArcGIS as delimited text with X=lon, Y=lat fields. For programmatic export, see the GeoJSON example in `firmware/tools/README.md`.

---

## 9. Reference Information

### 9.1 CSV Data Format

Each power cycle creates a new file: `PATH0001.CSV`, `PATH0002.CSV`, etc. The file begins with metadata comments and a header row.

**Standard format (4 pairs, no GPS quality logging):**

```csv
# Pathfinder v1.4.0 (2026-02-18) pairs=4
# epoch_offset=0 (relative ms, no RTC)
timestamp,lat,lon,g1_top,g1_bot,g1_grad,g2_top,g2_bot,g2_grad,g3_top,g3_bot,g3_grad,g4_top,g4_bot,g4_grad
12345,51.2345670,18.3456780,15234,15456,222,15189,15401,212,15150,15380,230,15210,15440,230
```

| Column | Description | Units |
|---|---|---|
| `timestamp` | Milliseconds since boot (or ISO 8601 UTC if RTC enabled) | ms or ISO string |
| `lat`, `lon` | GPS coordinates (0 if no fix) | Decimal degrees, WGS84 |
| `gN_top` | Top sensor raw ADC reading | 16-bit signed ADC counts |
| `gN_bot` | Bottom sensor raw ADC reading | 16-bit signed ADC counts |
| `gN_grad` | Gradient = bottom minus top | ADC counts |

With `GPS_LOG_QUALITY=1` (recommended for RTK or drone platforms), three additional columns appear after `lon`: `fix_quality`, `hdop`, and `altitude`.

### 9.2 Status LED Quick Reference

| LED Pattern | Meaning | System State |
|---|---|---|
| Very fast blink (50 ms) | Critical error: no ADCs found | ADC-only diagnostics |
| Fast blink (100 ms) | SD card error | Not logging; fix SD card |
| Medium blink (500 ms) | No GPS fix | Logging data without position |
| **Slow blink (2 s)** | **Normal operation** | **GPS locked, logging to SD** |

### 9.3 Firmware Configuration Quick Reference

Key parameters in `firmware/include/config.h`:

| Parameter | Default | Description |
|---|---|---|
| `NUM_SENSOR_PAIRS` | 4 (handheld), 2 (drone) | Number of gradiometer pairs |
| `SAMPLE_RATE_HZ` | 10 (handheld), 20 (drone) | Samples per second |
| `ENABLE_BEEPER` | 1 (handheld), 0 (drone) | Pace beeper on/off |
| `GPS_BAUD` | 9600 | GPS serial baud rate (115200 for ZED-F9P) |
| `GPS_LOG_QUALITY` | 0 (handheld), 1 (drone) | Log fix quality, HDOP, altitude |
| `SERIAL_DEBUG` | 1 | Serial debug output on/off |
| `SERIAL_BAUD` | 115200 | Debug serial baud rate |
| `SD_FLUSH_INTERVAL` | 10 | Flush SD every N samples |
| `ADC_SATURATION_THRESHOLD` | 32000 | ADC saturation warning level |
| `ENABLE_WATCHDOG` | 0 | Hardware watchdog (test first) |
| `ENABLE_RTC` | 0 | DS3231 real-time clock support |

### 9.4 Related Documentation

| Document | Location | Content |
|---|---|---|
| Quick Start | `firmware/QUICK_START.md` | Pre-flight checklist and basic operation |
| Calibration | `firmware/CALIBRATION.md` | 5-level calibration procedures |
| Wiring | `firmware/WIRING.md` | Complete hardware assembly guide |
| Firmware README | `firmware/README.md` | Build, upload, and library information |
| Design Concept | `docs/design-concept.md` | System architecture and physics |
| Platform Variants | `docs/platform-variants.md` | Handheld, backpack, and drone configurations |
| Frame Design | `hardware/cad/frame-design.md` | Physical harness and crossbar construction |
| Data Tools | `firmware/tools/README.md` | Python visualization and export utilities |

---

*Pathfinder Field Operations Guide -- v1.0*
*For firmware version 1.4.0 and later*
*All detection depths and coverage rates are **(Target)** or **(Modeled)** unless noted otherwise.*

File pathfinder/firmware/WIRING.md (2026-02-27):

# Pathfinder Wiring Guide

Complete wiring instructions for assembling the Pathfinder gradiometer electronics.

## Overview

The system consists of:
- 1x Arduino Nano (microcontroller)
- 2x ADS1115 ADC modules (16-bit, I2C)
- 1x NEO-6M GPS module (UART)
- 1x SD card module (SPI)
- 1x Piezo buzzer (pace beeper)
- 1x LED (status indicator)
- 8x Fluxgate sensors (gradiometer pairs)
- 1x 7.4V LiPo battery with 5V regulator

## Power Distribution

### Power Supply Requirements

- **System voltage**: 5V regulated
- **Total current**: ~150 mA typical, 200 mA peak (Modeled, electronics only — excludes fluxgate sensors)
- **Battery**: 7.4V 2S LiPo (2000+ mAh recommended)
- **Regulator**: 5V buck converter or 7805 linear regulator

### Power Wiring

```
[7.4V LiPo Battery]
       |
       +--[Power Switch]--[5V Regulator]--+
                                          |
          +-------------------------------+
          |               |               |               |
    [Arduino Nano]    [ADS1115 #1]   [ADS1115 #2]    [GPS Module]
          |               |               |               |
          +---------------+---------------+---------------+
                              |
                         [Common GND]
```

**Important**: All grounds must be connected together (common ground).

## I2C Bus (ADS1115 ADC Modules)

### ADS1115 Address Configuration

The two ADS1115 modules must have different I2C addresses:

**Module 1 (Address 0x48)**: ADDR pin → GND
**Module 2 (Address 0x49)**: ADDR pin → VDD

| Pin | Module 1 | Module 2 | Arduino Nano |
|-----|---|---|---|
| VDD | 5V | 5V | 5V |
| GND | GND | GND | GND |
| SCL | → | → | A5 (SCL) |
| SDA | → | → | A4 (SDA) |
| ADDR | GND | VDD | - |
| ALRT | (not used) | (not used) | - |

### I2C Bus Notes

- Add 4.7k pull-up resistors on SDA and SCL if not already on modules
- Keep I2C wires short (<30 cm) to reduce noise
- Use twisted pair for SDA/SCL if possible
- Maximum bus length: ~1 meter for reliable operation

## Sensor Connections (Fluxgate Channels)

### Gradiometer Pair Assignments

| Pair | Top Sensor | Bottom Sensor | ADS Module | Channels |
|---|---|---|---|---|
| 1 | Sensor 1T | Sensor 1B | ADS1 (0x48) | A0, A1 |
| 2 | Sensor 2T | Sensor 2B | ADS1 (0x48) | A2, A3 |
| 3 | Sensor 3T | Sensor 3B | ADS2 (0x49) | A0, A1 |
| 4 | Sensor 4T | Sensor 4B | ADS2 (0x49) | A2, A3 |

### ADS1115 Module 1 (0x48) - Pairs 1 and 2

```
ADS1115 Module 1
   A0 ← Pair 1 Top sensor output
   A1 ← Pair 1 Bottom sensor output
   A2 ← Pair 2 Top sensor output
   A3 ← Pair 2 Bottom sensor output
  GND ← Common ground to all sensors
```

### ADS1115 Module 2 (0x49) - Pairs 3 and 4

```
ADS1115 Module 2
   A0 ← Pair 3 Top sensor output
   A1 ← Pair 3 Bottom sensor output
   A2 ← Pair 4 Top sensor output
   A3 ← Pair 4 Bottom sensor output
  GND ← Common ground to all sensors
```

### Fluxgate Sensor Wiring

Each fluxgate sensor typically has 3 wires:

| Wire | Color (typical) | Connection |
|---|---|---|
| Signal Out | White/Yellow | ADS1115 analog input (A0-A3) |
| Power (+) | Red | 5V |
| Ground (-) | Black | Common GND |

**Check your sensor datasheet** - color coding varies by manufacturer.

### Sensor Cable Shielding

For best noise performance:
1. Use shielded cable for sensor connections
2. Connect shield to ground at electronics box end ONLY
3. Do not ground shield at sensor end (avoid ground loops)
4. Keep sensor cables away from power wires

## GPS Module (NEO-6M)

### GPS Connections

| NEO-6M Pin | Arduino Nano Pin | Notes |
|---|---|---|
| VCC | 5V | Power (check voltage - some need 3.3V!) |
| GND | GND | Common ground |
| TX | D4 (RX) | GPS transmit → Arduino receive |
| RX | D3 (TX) | GPS receive (not used for NEO-6M) |

**Voltage Warning**: Most NEO-6M modules accept 5V, but some require 3.3V. Check your module specs!

### GPS Antenna

- Use active GPS antenna with clear sky view
- Keep antenna away from metal objects
- Mount on non-conductive surface (plastic, fiberglass)
- Minimum 10 cm from electronics for best performance

## SD Card Module

### SD Card SPI Connections

| SD Module Pin | Arduino Nano Pin | SPI Signal |
|---|---|---|
| VCC | 5V | Power |
| GND | GND | Ground |
| CS | D10 | Chip Select |
| MOSI | D11 | Master Out Slave In |
| MISO | D12 | Master In Slave Out |
| SCK | D13 | Serial Clock |

**Voltage Warning**: Some SD modules need 3.3V! Use a level-shifter module or 3.3V-compatible SD module.

### SD Card Format

- Use SD card ≤32 GB
- Format as FAT32 (not exFAT)
- Class 10 recommended for fast writes

## User Interface

### Status LED

| Component | Arduino Pin | Connection |
|---|---|---|
| LED Anode (+) | D2 | Via 220Ω resistor |
| LED Cathode (-) | GND | Direct |

```
Arduino D2 ----[220Ω]---->(LED)---->GND
```

### Pace Beeper

| Component | Arduino Pin | Connection |
|---|---|---|
| Piezo (+) | D9 | Direct or via transistor |
| Piezo (-) | GND | Direct |

**For passive buzzer**:
```
Arduino D9 ---->(Piezo)---->GND
```

**For active buzzer or speaker (louder)**:
```
Arduino D9 ----[1kΩ]---->| NPN transistor (2N2222)
                         |
                    (Buzzer+)
                         |
                        GND
```

## Complete Wiring Diagram

```
                           +5V BUS
                              |
        +---------------------+---------------------+
        |          |          |          |          |
    [Arduino]  [ADS1]    [ADS2]     [GPS]       [SD]
        |          |          |          |          |
        +---------------------+---------------------+
                          GND BUS

ARDUINO NANO:
  A4 (SDA) ----+-------- ADS1 SDA -------- ADS2 SDA
               |
  A5 (SCL) ----+-------- ADS1 SCL -------- ADS2 SCL
               |
  D4 ---------|----------|----------|------ GPS TX
  D3 (unused)
  D9 ---------|----------|----------|------ Buzzer (+)
  D2 ---------|----------|----------|------ LED (+) via 220Ω
  D10 --------|----------|----------|------ SD CS
  D11 --------|----------|----------|------ SD MOSI
  D12 --------|----------|----------|------ SD MISO
  D13 --------|----------|----------|------ SD SCK

ADS1115 #1 (ADDR=GND → 0x48):
  A0 ← Sensor 1 Top
  A1 ← Sensor 1 Bottom
  A2 ← Sensor 2 Top
  A3 ← Sensor 2 Bottom

ADS1115 #2 (ADDR=VDD → 0x49):
  A0 ← Sensor 3 Top
  A1 ← Sensor 3 Bottom
  A2 ← Sensor 4 Top
  A3 ← Sensor 4 Bottom
```

## Assembly Steps

### 1. Prepare Components

- [ ] Test all modules individually before assembly
- [ ] Check voltage requirements (5V vs 3.3V)
- [ ] Verify I2C addresses with scanner sketch
- [ ] Label all wires with masking tape

### 2. Build Power Distribution

- [ ] Connect 5V regulator to battery
- [ ] Add power switch in series
- [ ] Create common 5V and GND buses (use breadboard or terminal block)
- [ ] Test voltage output with multimeter (should be 5.0V ± 0.1V)

### 3. Wire I2C Bus

- [ ] Connect ADS1 to Arduino (SDA, SCL)
- [ ] Connect ADS2 to Arduino (SDA, SCL)
- [ ] Configure ADDR pins (ADS1→GND, ADS2→VDD)
- [ ] Add pull-up resistors if needed (4.7kΩ)

### 4. Connect Peripherals

- [ ] Wire GPS module to D4
- [ ] Wire SD card module (SPI pins)
- [ ] Connect status LED to D2 with resistor
- [ ] Connect buzzer to D9

### 5. Connect Sensors

- [ ] Label each sensor cable (1T, 1B, 2T, 2B, etc.)
- [ ] Connect sensors to correct ADS channels
- [ ] Ensure common ground to all sensors
- [ ] Route sensor cables away from power wires

### 6. Test and Debug

- [ ] Upload firmware
- [ ] Open serial monitor (115200 baud)
- [ ] Check for initialization messages
- [ ] Verify all modules detected
- [ ] Test GPS lock outdoors
- [ ] Verify SD card writes

## Troubleshooting

### Module Not Detected

**Symptom**: "ADS1115 not found" or "SD card failed"

**Solutions**:
1. Check power connections (5V and GND)
2. Verify wiring to correct pins
3. Test with multimeter for continuity
4. Try different I2C address (swap ADDR wiring)
5. Upload I2C scanner sketch to find devices

### Erratic Sensor Readings

**Symptom**: Noisy or unstable ADC values

**Solutions**:
1. Check sensor power supply (should be stable 5V)
2. Ensure good ground connections
3. Shield sensor cables
4. Separate sensor cables from power/data cables
5. Add 0.1µF capacitors across sensor power pins
6. Lower ADC data rate in config.h

### GPS Won't Lock

**Symptom**: LED blinks medium speed, no coordinates

**Solutions**:
1. Move to open area with sky view
2. Wait 1-2 minutes for cold start
3. Check GPS TX → Arduino D4 connection
4. Verify GPS power LED is lit
5. Try different GPS baud rate (some modules use 115200)

## Safety Notes

⚠️ **Battery Safety**
- Use proper LiPo charger (not car battery charger!)
- Never charge unattended
- Store in fireproof bag
- Check for damage before use
- Disconnect when not in use

⚠️ **Electrical Safety**
- Double-check polarity before powering on
- Use fuse or current limiter on battery
- Avoid short circuits (cover exposed connections)
- Work on non-conductive surface

## Enclosure Recommendations

### Electronics Box
- IP65 rated for weather resistance
- Minimum size: 15 x 10 x 5 cm
- Ventilation holes for heat
- Cable glands for sensor/GPS wires
- Mounting brackets for belt/harness

### Component Layout
- Arduino and modules on DIN rail or standoffs
- SD card accessible without opening box
- Status LED visible through window
- Buzzer holes for sound output

## Bill of Materials (Wiring)

| Item | Quantity | Notes |
|---|---|---|
| 22 AWG stranded wire (red) | 2m | Power (+) |
| 22 AWG stranded wire (black) | 2m | Ground (-) |
| 24 AWG stranded wire (colors) | 10m | Signals |
| Shielded cable 2-conductor | 5m | Sensor connections |
| Heat shrink tubing | 1m | Assorted sizes |
| Dupont connectors | 50 | Male/female |
| Terminal blocks 5mm | 4 | Power distribution |
| 220Ω resistor | 1 | LED current limit |
| 4.7kΩ resistor | 2 | I2C pull-ups (if needed) |
| Electrical tape | 1 roll | Wire bundling |
| Cable ties | 20 | Wire management |

## Next Steps

After wiring is complete:
1. See `README.md` for firmware upload instructions
2. See `QUICK_START.md` for operation guide
3. Perform calibration procedure (in development)
4. Conduct field test survey

## Support

For wiring issues, check:
- [Arduino Nano pinout](https://docs.arduino.cc/hardware/nano)
- [ADS1115 datasheet](https://www.ti.com/lit/ds/symlink/ads1115.pdf)
- Project repository issues page

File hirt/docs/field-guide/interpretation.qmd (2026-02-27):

---
title: "Data Interpretation"
---

## Overview {#sec-interpretation-overview}

This section provides practical guidance on interpreting HIRT field data, including what each measurement method detects, how to classify anomalies, and how to prioritize investigation targets. For the mathematical foundations and inversion algorithms, see [Theory: Inversion](../theory/inversion.qmd).

Effective interpretation requires understanding both the physics of the measurements and the geological/archaeological context of the survey site.

## What HIRT Detects

### MIT (Magneto-Inductive Tomography) Detection

The MIT-3D channel responds to materials with electrical conductivity and/or magnetic permeability:

- **Metal objects:** Strong response to aluminum, steel, and iron
- **Conductive regions:** Moderate response to saline water, clay layers
- **Eddy current anomalies:** Metallic wreckage produces characteristic signatures
- Phase lag indicates conductivity; amplitude indicates size/distance
- Higher frequencies provide better near-surface sensitivity

### ERT (Electrical Resistivity) Detection

The ERT-Lite channel responds to variations in bulk electrical resistivity:

- **Disturbed fill:** Different compaction and moisture than native soil
- **Moisture variations:** Wet zones appear as low resistivity
- **Crater walls:** Clear boundaries between fill and native soil
- **Voids:** Air-filled spaces show very high resistivity
- Depth slices reveal layering and lateral extent of features

## Anomaly Classification

MIT and ERT respond differently to various subsurface features. Understanding these response characteristics enables accurate classification of detected anomalies.

| Target Type | MIT Response | ERT Response | Examples |
|---|---|---|---|
| Metal Objects | Strong | Weak/None | Engine parts, wreckage, artifacts |
| Conductive Soil | Moderate | Moderate | Wet clay, saline zones, contamination |
| Disturbed Fill | Weak | Strong | Crater fill, grave shafts, backfill |
| Voids/Air | None | Strong (high-R) | Cavities, collapsed zones, air pockets |
| Moisture Zones | Weak | Strong (low-R) | Water table, wet pockets, seepage |

: Anomaly classification by target type {#tbl-anomaly-classification}

**Key insight:** Combine MIT + ERT for complete picture. A metallic target in disturbed fill shows both strong MIT response AND ERT contrast—this is a high-priority combination.

## Combined Interpretation Strategy

Effective HIRT interpretation combines MIT and ERT results with site context and historical information.

### Decision Tree for Prioritization

1. **Verify data quality** - Check reciprocity, noise levels
2. **Identify MIT anomalies** - Strong, moderate, or absent?
3. **Identify ERT anomalies** - Resistivity higher or lower than background?
4. **Correlate locations** - Do MIT and ERT anomalies coincide?
5. **Classify target** - Metal, fill, void, or natural feature?
6. **Assign priority** - Based on combined evidence and site context

### Priority Levels

| Priority | Criteria | Action |
|---|---|---|
| **HIGH** | Metal + Disturbed fill (both channels) | Immediate investigation |
| **MEDIUM** | Metal OR fill only (one channel) | Further characterization |
| **LOW** | Minor anomalies, weak signals | Document for reference |
| **NATURAL** | ERT-only, no MIT, natural geometry | Likely root mass, clay lens |

: Investigation priority levels {#tbl-priority-levels}

## Example Interpretation Scenarios

### Scenario 1: Bomb Crater Investigation

- **MIT:** Metal parts detected near crater base (aluminum/steel fragments)
- **ERT:** Fill bowl geometry visible, wet pockets at base, clear crater walls
- **Interpretation:** Classic impact crater with retained metallic debris

### Scenario 2: Woods Burial Search

- **MIT:** Small metallic clusters (buckles, dog tags, buttons)
- **ERT:** Rectangular disturbed zone with different moisture profile
- **Interpretation:** Possible grave shaft requiring careful investigation

### Scenario 3: Aircraft Wreckage

- **MIT:** Large conductive masses (engine block, landing gear)
- **ERT:** Disturbed ground pattern, possible fuel contamination zones
- **Interpretation:** Significant wreckage concentration warranting excavation

## Target Signature Catalogue

### Metallic Object Signatures (MIT-3D)

**Ferrous Metal (Iron/Steel):** Aircraft engines, landing gear, bomb casings, and steel artifacts produce the strongest MIT responses. The combination of high electrical conductivity and magnetic permeability creates intense eddy currents and magnetic field distortion.

**Non-Ferrous Metal (Aluminum, Brass, Copper):** Aircraft structural components, ammunition casings, and decorative artifacts produce moderate MIT responses. These materials lack magnetic permeability but still support eddy currents.

**Size vs Depth Relationship:** Target detectability follows an approximate cube-law. A 10 cm artifact detectable at 1 m depth becomes nearly invisible at 2 m depth. For planning, assume minimum detectable size scales linearly with depth.

### Soil Disturbance Signatures (ERT-Lite)

**Backfilled Excavation:** Bomb craters, trenches, and excavations refilled with soil show characteristic resistivity patterns. The backfill is typically less compacted, creating larger pore spaces that retain more moisture. This produces a low-resistivity anomaly.

**Void/Cavity:** Air-filled spaces produce high-resistivity anomalies. Air has effectively infinite resistivity, so even a small void creates a distinct signature.

**Decomposition Products:** Organic decomposition releases conductive fluids that reduce resistivity. Burial sites often show a moderate low-resistivity zone with elongated geometry.

### Combined Signatures (Dual-Channel Fusion)

**Bomb Crater with Metallic Debris:** Clear bowl-shaped ERT disturbance with strong MIT responses concentrated near the crater base or scattered throughout the fill. Excavation priority is HIGH.

**Burial with Metal Artifacts:** Modest rectangular ERT disturbance (grave shaft geometry) with small, discrete MIT anomalies aligned with the shaft. The presence of metal increases identification confidence.

**Natural Features Mimicking Targets:** Tree root masses, clay lenses, and natural soil heterogeneity can produce ERT anomalies. The key discriminator is the MIT channel: natural features almost never produce metal responses.

## False Positives to Watch For

| False Positive | Distinguishing Features |
|---|---|
| Utility pipes | Linear geometry, often straight lines |
| Natural mineralization | Diffuse, regional trends (not localized) |
| Root masses | Branching/networked pattern in ERT, no MIT response |
| Perched water table | Laterally extensive, consistent depth across survey |

: Common false positive sources {#tbl-false-positives}

## Data Quality Indicators

### Good Data Characteristics

- Consistent reciprocity (A-to-B approximately equals B-to-A)
- Smooth spatial variations without erratic jumps
- Expected depth sensitivity matching configuration
- Stable baseline measurements over survey duration

::: {.callout-warning}
## Problematic Data Warning Signs

- Poor reciprocity indicates coupling problems or calibration drift
- Noisy/spiky readings suggest connection issues or EMI
- No depth sensitivity may indicate inadequate spacing or frequency
- Inconsistent repeats require checking timebase and connectors
:::

## Detection Limits

Understanding what HIRT *cannot* detect is as important as understanding what it can detect.

### Typical Anomaly Sizes

| Target Type | Typical Size | Expected Response |
|---|---|---|
| Large metal (engine) | 1-3 m | Strong MIT response |
| Small metal (artifacts) | 0.1-0.5 m | Weaker MIT, requires tight spacing |
| Grave shaft | 0.5-1.5 m wide | Clear ERT contrast |
| Crater fill | 10-15 m diameter | ERT shows boundaries clearly |

: Typical anomaly sizes and expected responses {#tbl-anomaly-sizes}

### Minimum Detectable Sizes

- **MIT:** Can detect ~0.1m metal at 1-2m depth (size dependent)
- **ERT:** Can resolve ~0.5m features at 1-2m depth
- **Depth:** 2-4 m typical investigation depth with 1.5-3.0 m probes in most soil conditions; up to 5-6 m in low-conductivity soils with 3.0 m probes and wide spacing **(Modeled)**---see [Uncertainty: Depth of Investigation](../theory/uncertainty.qmd#sec-depth-investigation) for detailed claims by configuration

::: {.callout-important}
## What "No Anomaly" Actually Means

A survey showing no anomalies indicates "no statistically significant deviation from background within detection limits"—NOT "definitely clear of targets." Small objects, deep targets, or low-contrast features may be present but undetectable.
:::

## Post-Survey Workflow

1. **QA/QC:** Verify data quality and reciprocity
2. **Inversion:** Reconstruct 3D models using appropriate algorithms
3. **Fusion:** Combine MIT and ERT results for complete picture
4. **Visualization:** Generate depth slices and 3D isosurfaces
5. **Interpretation:** Correlate anomalies with site context
6. **Reporting:** Document findings with confidence assessments
7. **Planning:** Recommend excavation priorities and methods

::: {.callout-note}
## Key Interpretation Principles

- Always combine MIT and ERT for complete subsurface picture
- Consider site history and expected target characteristics
- Use confidence levels to guide excavation prioritization
- Document interpretation rationale for future reference
:::

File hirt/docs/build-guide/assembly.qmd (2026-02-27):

---
title: "Assembly and Wiring"
---

## Overview {#sec-assembly-overview}

This section provides comprehensive step-by-step assembly instructions for the HIRT modular micro-probe system (16 mm **(Target)** diameter). The modular design allows probes to be built by stacking fiberglass rod segments and 3D-printed sensor modules. The assembly process is designed for field conditions with minimal tooling requirements.

::: {.callout-tip}
## Hardware Documentation Reference

Detailed assembly drawings and wiring diagrams are maintained in the hardware documentation:

- **Assembly Drawings:** `/hardware/drawings/assembly-drawings.md` - Visual assembly guides
- **Probe Head Drawing:** `/hardware/drawings/probe-head-drawing.md` - Detailed probe head construction
- **Probe Assembly:** `/hardware/schematics/mechanical/probe-assembly.md` - Step-by-step mechanical assembly
- **Manufacturing Notes:** `/hardware/cad/docs/manufacturing-notes.md` - 3D printing tips and troubleshooting

These hardware docs contain the most current assembly procedures and are updated as the design evolves.
:::

## Probe Assembly Overview {#sec-probe-assembly-overview}

The HIRT probe is a modular stack of 3D-printed components connected by M12x1.75 **(Manufacturer spec)** threads. The assembly comprises four main component types: probe tip, male rod caps, sensor bodies, and junction cap. Fiberglass rod segments (50 cm or 100 cm **(Target)**) bridge between sensor bodies to achieve the desired probe depth.

```{python}
#| label: fig-probe-exploded
#| fig-cap: "Exploded view of probe assembly showing component stacking order. Components connect via M12x1.75 threads with O-ring seals at each joint. Fiberglass rod segments bridge between sensor bodies. Assembly proceeds from bottom (tip) upward."
#| code-fold: true

import sys; sys.path.insert(0, '..') if '..' not in sys.path else None
from diagrams.assembly_3d import create_probe_assembly_exploded
from IPython.display import display, Image

buf = create_probe_assembly_exploded()
display(Image(data=buf.getvalue()))
```

::: {#fig-cad-views layout-ncol=2}

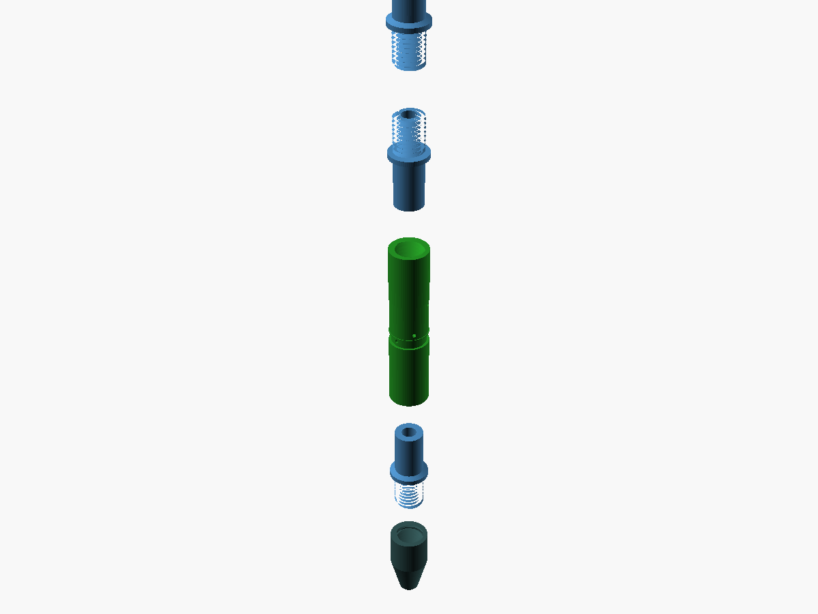
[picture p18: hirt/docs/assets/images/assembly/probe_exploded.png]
Exploded view from CAD


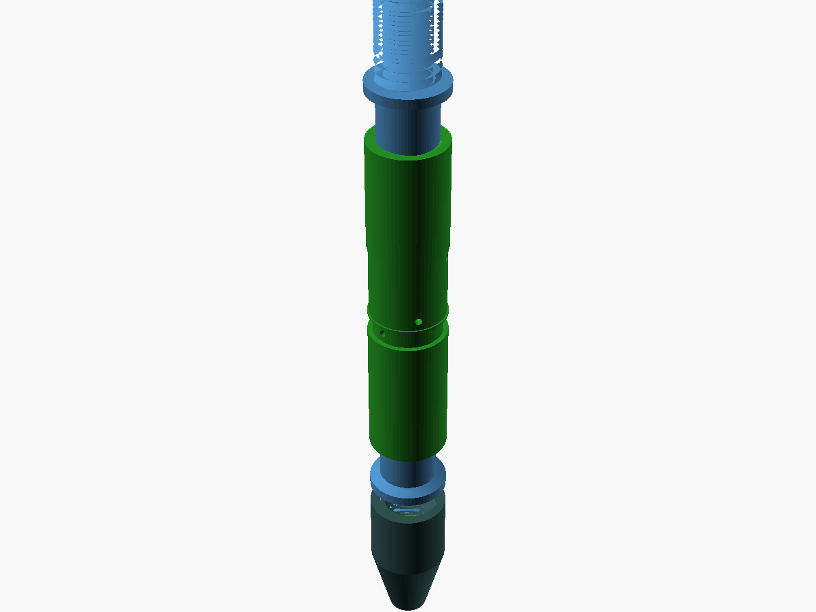
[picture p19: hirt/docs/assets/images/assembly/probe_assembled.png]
Assembled probe


3D CAD renders showing the probe in exploded and assembled configurations. Color coding: green = sensor bodies, blue = male rod caps, dark gray = probe tip and junction cap.
:::

The sensor body is the key component, housing both the MIT coil winding zone and ERT electrode groove. Each sensor body has female M12 sockets on both ends, allowing it to receive male rod caps from adjacent fiberglass segments.

```{python}
#| label: fig-sensor-detail
#| fig-cap: "Cross-section of sensor body showing internal features: dual female thread sockets (25 mm depth each **(Target)**), ERT ring groove at 1/4 position, MIT coil winding zone at 3/4 position, and 6 mm center wire channel **(Target)**."
#| code-fold: true

import sys; sys.path.insert(0, '..') if '..' not in sys.path else None
from diagrams.assembly_3d import create_sensor_body_detail
from IPython.display import display, Image

buf = create_sensor_body_detail()
display(Image(data=buf.getvalue()))
```

## Thread Engagement {#sec-thread-engagement}

Proper thread engagement is critical for both mechanical strength and waterproofing. The M12x1.75 **(Manufacturer spec)** ISO metric threads provide approximately 6 full threads of engagement at the minimum 10 mm depth **(Target)**.

```{python}
#| label: fig-thread-engagement
#| fig-cap: "Thread engagement detail showing male rod cap threading into sensor body socket. Minimum engagement of 10 mm **(Target)** (6 threads) required. O-ring seal compresses at thread shoulder."
#| code-fold: true

import sys; sys.path.insert(0, '..') if '..' not in sys.path else None
from diagrams.assembly_3d import create_thread_engagement_detail
from IPython.display import display, Image

buf = create_thread_engagement_detail()
display(Image(data=buf.getvalue()))
```

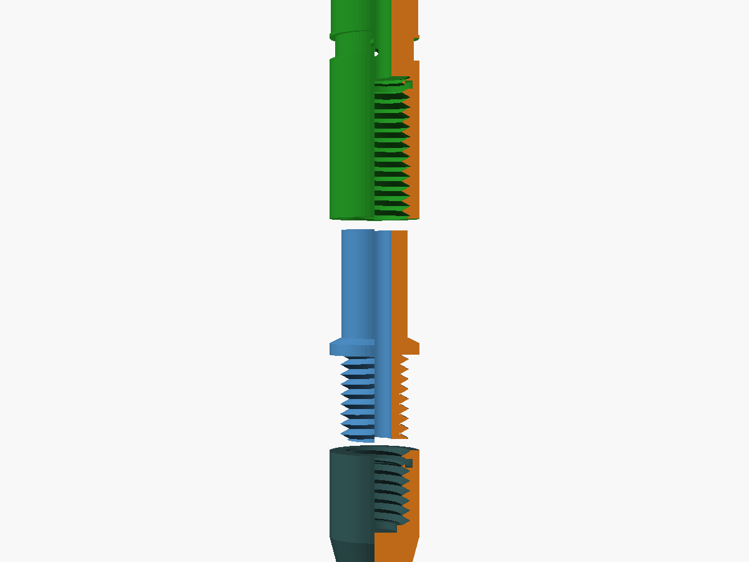
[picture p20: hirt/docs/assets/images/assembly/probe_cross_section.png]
Cross-section view from CAD showing internal thread engagement, wire channel, and component interfaces.


::: {.callout-important}
## Thread Assembly Guidelines

- **Hand-tighten only**: Finger-tight plus 1/4 turn maximum **(Target)**
- **O-ring required**: 10 mm ID x 1.5 mm cross-section **(Manufacturer spec)** at each joint
- **Thread sealant**: Apply Loctite 567 or equivalent to male threads
- **Verify engagement**: Minimum 10 mm **(Target)** (6 full threads) before sealing
:::

## Parts List {#sec-parts-list}

### Printed Parts (PETG/ASA)

| Part | Qty/Probe | Notes |
|---|---|---|
| Male Insert Plug | 2 | Threaded male screw end |
| Sensor Module (Female) | 2-3 | Sensor body with female threads |
| Probe Tip | 1 | Pointed nose cone |
| Top Cap | 1 | Cable exit/handle |

: 3D-printed probe components {#tbl-printed-parts}

### Hardware

| Part | Qty/Probe | Notes |
|---|---|---|
| Fiberglass Tube | 2-3 sections | 16 mm OD x 12 mm ID **(Manufacturer spec)** |
| Epoxy | As needed | 2-part structural (Loctite Marine, JB Weld) |
| O-rings | 4-6 | Size for M12 thread shoulder (10 mm ID x 1.5 mm **(Manufacturer spec)**) |
| Ferrite Cores | 1-2 | For MIT coils (6-8 mm x 40-80 mm **(Manufacturer spec)**) |
| Magnet Wire | 10-20 m | 30-34 AWG **(Manufacturer spec)** for coil winding |
| ERT Ring Material | 2-3 bands | Stainless steel or copper tape |
| Cable | 3-5 m | Multi-conductor shielded |

: Hardware and consumable materials {#tbl-hardware-parts}

## Tools Required {#sec-tools-required}

| Tool | Purpose |
|---|---|
| Hacksaw or Tube Cutter | Cutting fiberglass tubing |
| 400-grit Sandpaper | Surface preparation |
| M12x1.75 Tap | Threading female parts |
| M12x1.75 Die | Threading male parts |
| Tap Handle | For tap operation |
| Mixing Cups | For epoxy |
| Nitrile Gloves | Epoxy handling |
| Soldering Iron | Wire connections |
| Multimeter | Testing continuity |
| Calipers | Measuring dimensions |

: Essential tools for assembly {#tbl-tools}

::: {.callout-tip}
## Recommended Additional Tools

- Bench Vise - Holding parts during tapping
- Thread Cutting Oil - Lubrication for tap/die
- LCR Meter - Coil testing
- Heat Gun - Heat shrink tubing
- Wire Strippers - Cable preparation
:::

## Wiring Architecture {#sec-wiring-architecture}

The HIRT system uses a hierarchical wiring architecture designed to manage the complexity of connecting 20-50 passive probes. Rather than routing all probe cables directly to the main hub (which would require 600+ conductors **(Modeled)**), the system uses a **Zone Wiring Strategy** that aggregates signals through intermediate junction boxes.

```{python}
#| label: fig-zone-architecture
#| fig-cap: "Zone wiring architecture showing probe groupings, zone boxes, and trunk cable routing to the central hub. Each zone aggregates 4 probes through a passive junction box."
#| code-fold: true

import matplotlib.pyplot as plt
from matplotlib.patches import FancyBboxPatch, Circle, Rectangle
import numpy as np
from io import BytesIO
from IPython.display import display, Image as IPImage

# Color palette
COLORS = {
    'primary': '#1a365d',
    'secondary': '#2c5282',
    'accent': '#3182ce',
    'success': '#38a169',
    'warning': '#c53030',
    'gray_dark': '#4a5568',
    'gray_med': '#718096',
    'gray_light': '#a0aec0',
    'light_blue': '#ebf8ff',
}

fig, ax = plt.subplots(figsize=(10, 6))
ax.set_xlim(0, 10)
ax.set_ylim(0, 6)
ax.set_aspect('equal')
ax.axis('off')

# Central hub
ax.add_patch(FancyBboxPatch((0.5, 2), 2.0, 2.0, boxstyle="round,pad=0.05",
                            facecolor=COLORS['light_blue'], edgecolor=COLORS['secondary'],
                            linewidth=2))
ax.text(1.5, 3, 'Central\nHub', ha='center', va='center',
       fontsize=10, fontweight='bold')

# Trunk cables
trunk_y = [4.5, 3.0, 1.5]
for y in trunk_y:
    ax.plot([2.5, 4.0], [y, y], color=COLORS['gray_dark'], lw=4)

ax.text(3.25, 5.0, 'Trunk Cables\n(DB25)', ha='center', fontsize=8,
       color=COLORS['gray_dark'])

# Zone hubs
zone_positions = [(4.0, 4.0), (4.0, 2.5), (4.0, 1.0)]
for i, (x, y) in enumerate(zone_positions):
    ax.add_patch(FancyBboxPatch((x, y), 1.5, 1.0, boxstyle="round,pad=0.03",
                                facecolor='white', edgecolor=COLORS['gray_dark'],
                                linewidth=1.5))
    ax.text(x + 0.75, y + 0.5, f'Zone {i+1}\nHub', ha='center', va='center',
           fontsize=8)

# Probe cables from each zone
for zi, (zx, zy) in enumerate(zone_positions):
    for pi in range(4):
        px = 7.0 + (pi % 2) * 1.5
        py = zy + 0.2 + (pi // 2) * 0.4
        ax.plot([zx + 1.5, px], [zy + 0.5, py], color=COLORS['gray_light'], lw=1)
        ax.add_patch(Circle((px, py), 0.2, facecolor=COLORS['secondary'],
                           edgecolor='black', lw=0.5))

ax.text(7.75, 5.5, 'Probes\n(4 per zone)', ha='center', fontsize=8)

# Annotations
ax.annotate('High-density\nmultiplexing', xy=(1.5, 2), xytext=(0.5, 0.5),
           fontsize=7, ha='center',
           arrowprops=dict(arrowstyle='->', color=COLORS['accent']))

ax.annotate('Passive\njunction', xy=(4.75, 4.5), xytext=(4.75, 5.5),
           fontsize=7, ha='center',
           arrowprops=dict(arrowstyle='->', color=COLORS['gray_dark']))

# Title
ax.text(5, 0.2, 'Zone Wiring Architecture', ha='center',
       fontsize=11, fontweight='bold', color=COLORS['primary'])

plt.tight_layout()
buf = BytesIO()
fig.savefig(buf, format='png', dpi=200, bbox_inches='tight', facecolor='white', edgecolor='none')
buf.seek(0)
plt.close(fig)
display(IPImage(data=buf.getvalue()))
```

### System Topology

The zone architecture divides the probe array into manageable groups of 4 probes each. Each group connects to a Zone Box (small passive hub) via individual probe cables. The Zone Box then connects to the Main Hub via a single high-density Trunk Cable. This reduces the number of cables entering the main enclosure from 20+ to just 5-6 trunk cables.

- **Zone Box:** Small IP65 enclosure (100x100 mm **(Target)**) with 4 cable glands for probes and 1 DB25 connector for trunk output
- **Trunk Cable:** High-quality shielded 25-conductor cable, 10-20 meters **(Target)**, carrying signals for 4 probes
- **Advantages:** Modular expansion, clean installation, field-ready deployment

### Wiring Harness Layout

```{python}
#| label: fig-wiring-harness
#| fig-cap: "Wiring harness architecture from probe sensors through junction box and zone box to the main hub. The multi-conductor shielded cable (2-4 mm diameter **(Target)**) carries all sensor signals."
#| code-fold: true

from io import BytesIO
from IPython.display import display, Image as IPImage

fig, ax = plt.subplots(figsize=(10, 6))
ax.set_xlim(0, 10)
ax.set_ylim(0, 6)
ax.set_aspect('equal')
ax.axis('off')

# Title
ax.text(5, 5.7, 'Wiring Harness Architecture', fontsize=12,
        fontweight='bold', ha='center', color=COLORS['primary'])

# Probe (Left Side)
ax.add_patch(Rectangle((0.5, 1.0), 0.4, 3.5,
                       facecolor=COLORS['secondary'], edgecolor='black', lw=1.5))
ax.text(0.7, 4.7, 'Probe', ha='center', fontsize=9, fontweight='bold')

# Sensor positions on probe
sensor_info = [
    (4.0, 'TX Coil', COLORS['success']),
    (3.2, 'ERT Ring 1', '#ed8936'),
    (2.4, 'RX Coil', COLORS['accent']),
    (1.6, 'ERT Ring 2', '#ed8936'),
]

for y, label, color in sensor_info:
    ax.add_patch(Rectangle((0.45, y - 0.1), 0.5, 0.2,
                           facecolor=color, edgecolor='black', lw=0.5))

# Junction Box
ax.add_patch(FancyBboxPatch((1.2, 3.0), 1.5, 1.5, boxstyle="round,pad=0.05",
                            facecolor=COLORS['gray_dark'], edgecolor='black', lw=1.5))
ax.text(1.95, 4.3, 'Junction\nBox', ha='center', fontsize=8, color='white')

# Internal connections from probe to junction box
for y, label, color in sensor_info:
    ax.plot([0.9, 1.2], [y, 3.75], color=color, lw=1.5, alpha=0.7)

# Multi-conductor Cable
cable_x = np.linspace(2.7, 5.5, 50)
cable_y = 3.75 + 0.3 * np.sin(np.linspace(0, 2*np.pi, 50))
ax.plot(cable_x, cable_y, color=COLORS['gray_dark'], lw=6, solid_capstyle='round')
ax.plot(cable_x, cable_y, color=COLORS['gray_light'], lw=4, solid_capstyle='round')

ax.text(4.1, 4.4, 'Multi-conductor\nShielded Cable', ha='center', fontsize=8)
ax.annotate('2-4 mm dia', xy=(4.1, 3.4), fontsize=7, ha='center', color=COLORS['gray_dark'])

# Zone Box (Right Side)
ax.add_patch(FancyBboxPatch((5.8, 2.5), 1.8, 2.0, boxstyle="round,pad=0.05",
                            facecolor='white', edgecolor=COLORS['gray_dark'], lw=1.5))
ax.text(6.7, 4.3, 'Zone Box', ha='center', fontsize=9, fontweight='bold')

# Cable glands on Zone Box
for i in range(4):
    gy = 2.8 + i * 0.4
    ax.add_patch(Circle((5.8, gy), 0.12, facecolor=COLORS['gray_med'],
                       edgecolor='black', lw=0.5))
ax.text(5.3, 3.3, 'Cable\nGlands', ha='center', fontsize=6, va='center')

# Terminal strip inside Zone Box
ax.add_patch(Rectangle((6.2, 2.8), 0.8, 1.4, facecolor='#ebf8ff',
                       edgecolor=COLORS['accent'], lw=1))
ax.text(6.6, 3.5, 'Terminal\nStrip', ha='center', fontsize=6, va='center')

# Trunk Cable to Hub
ax.plot([7.6, 9.0], [3.5, 3.5], color=COLORS['gray_dark'], lw=8, solid_capstyle='round')
ax.plot([7.6, 9.0], [3.5, 3.5], color=COLORS['gray_light'], lw=5, solid_capstyle='round')
ax.text(8.3, 3.9, 'Trunk Cable\n(to Main Hub)', ha='center', fontsize=8)

# DB25 connector
ax.add_patch(FancyBboxPatch((7.2, 3.2), 0.6, 0.6, boxstyle="round,pad=0.02",
                            facecolor=COLORS['gray_med'], edgecolor='black', lw=1))
ax.text(7.5, 3.5, 'DB25', ha='center', fontsize=6, color='white', fontweight='bold')

# Legend
legend_y = 0.5
legend_items = [
    ('TX Signal', COLORS['success']),
    ('RX Signal', COLORS['accent']),
    ('ERT Electrodes', '#ed8936'),
    ('Shield/Ground', COLORS['gray_light']),
]

for i, (label, color) in enumerate(legend_items):
    lx = 1.5 + i * 2.3
    ax.add_patch(Rectangle((lx, legend_y), 0.3, 0.2, facecolor=color, edgecolor='black', lw=0.5))
    ax.text(lx + 0.4, legend_y + 0.1, label, fontsize=7, va='center')

plt.tight_layout()
buf = BytesIO()
fig.savefig(buf, format='png', dpi=200, bbox_inches='tight', facecolor='white', edgecolor='none')
buf.seek(0)
plt.close(fig)
display(IPImage(data=buf.getvalue()))
```

### Connector Pinout Reference

The system uses 12-pin Phoenix Contact connectors (part number 1757248) or equivalent for probe-side connections. The pinout is standardized across all probes to ensure interchangeability and simplify field maintenance.

```{python}
#| label: fig-connector-pinout
#| fig-cap: "12-pin Phoenix connector pinout showing signal assignments and recommended wire colors. Pins 1-4 carry MIT coil differential pairs, pins 6-8 carry ERT electrode signals."
#| code-fold: true

from io import BytesIO
from IPython.display import display, Image as IPImage

fig, ax = plt.subplots(figsize=(9, 6))
ax.set_xlim(0, 9)
ax.set_ylim(0, 6)
ax.set_aspect('equal')
ax.axis('off')

# Title
ax.text(4.5, 5.7, '12-Pin Phoenix Connector Pinout (1757248)', fontsize=12,
        fontweight='bold', ha='center', color=COLORS['primary'])

# Connector Body
conn_x, conn_y = 2.0, 2.0
conn_w, conn_h = 3.5, 2.5

# Outer housing
ax.add_patch(FancyBboxPatch((conn_x, conn_y), conn_w, conn_h,
                            boxstyle="round,pad=0.1",
                            facecolor=COLORS['gray_dark'], edgecolor='black', lw=2))

# Inner cavity
ax.add_patch(FancyBboxPatch((conn_x + 0.2, conn_y + 0.2), conn_w - 0.4, conn_h - 0.4,
                            boxstyle="round,pad=0.05",
                            facecolor=COLORS['gray_med'], edgecolor='black', lw=1))

# Pin arrangement (2 rows of 6)
pin_colors = {
    1: ('red', 'TX+'),
    2: ('black', 'TX-'),
    3: ('white', 'RX+'),
    4: ('green', 'RX-'),
    5: ('yellow', 'Guard'),
    6: ('blue', 'Ring A'),
    7: ('orange', 'Ring B'),
    8: ('#8B4513', 'Ring C'),
    9: ('purple', 'ID Sense'),
    10: ('gray', 'Spare+'),
    11: ('pink', 'Spare-'),
    12: (COLORS['gray_light'], 'Shield'),
}

pin_radius = 0.15
for pin in range(1, 13):
    row = (pin - 1) // 6
    col = (pin - 1) % 6
    px = conn_x + 0.5 + col * 0.5
    py = conn_y + conn_h - 0.7 - row * 0.6

    color, _ = pin_colors[pin]
    ax.add_patch(Circle((px, py), pin_radius, facecolor=color,
                       edgecolor='black', lw=1))

    # Pin number
    text_color = 'white' if color in ['black', 'purple', 'blue', '#8B4513'] else 'black'
    ax.text(px, py, str(pin), ha='center', va='center', fontsize=6,
            fontweight='bold', color=text_color)

# Row labels
ax.text(conn_x + 0.15, conn_y + conn_h - 0.7, '1-6', fontsize=6,
        va='center', color='white')
ax.text(conn_x + 0.15, conn_y + conn_h - 1.3, '7-12', fontsize=6,
        va='center', color='white')

# Pinout Table
table_x = 6.0
table_y = 4.8
row_height = 0.35

ax.text(table_x + 1.2, table_y + 0.3, 'Signal Assignment', fontsize=10,
        fontweight='bold', ha='center', color=COLORS['primary'])

# Table header
ax.add_patch(Rectangle((table_x, table_y - row_height), 2.4, row_height,
                       facecolor=COLORS['primary'], edgecolor='black', lw=0.5))
ax.text(table_x + 0.25, table_y - row_height/2, 'Pin', fontsize=7,
        color='white', va='center', fontweight='bold')
ax.text(table_x + 0.8, table_y - row_height/2, 'Signal', fontsize=7,
        color='white', va='center', fontweight='bold')
ax.text(table_x + 1.7, table_y - row_height/2, 'Color', fontsize=7,
        color='white', va='center', fontweight='bold')

# Table rows
for i, (pin, (color, signal)) in enumerate(pin_colors.items()):
    row_y = table_y - (i + 2) * row_height
    bg_color = '#ebf8ff' if i % 2 == 0 else 'white'

    ax.add_patch(Rectangle((table_x, row_y), 2.4, row_height,
                           facecolor=bg_color, edgecolor=COLORS['gray_light'], lw=0.5))

    ax.text(table_x + 0.25, row_y + row_height/2, str(pin), fontsize=6, va='center')
    ax.text(table_x + 0.8, row_y + row_height/2, signal, fontsize=6, va='center')

    # Color swatch
    ax.add_patch(Rectangle((table_x + 1.55, row_y + 0.08), 0.25, row_height - 0.16,
                           facecolor=color, edgecolor='black', lw=0.5))

# Notes
ax.text(0.3, 0.8, 'Notes:', fontsize=8, fontweight='bold', color=COLORS['primary'])
notes = [
    '- Pins 1-4: MIT coil differential pairs',
    '- Pins 5: Guard/reference electrode',
    '- Pins 6-8: ERT ring electrodes',
    '- Pin 9: Probe ID sense (optional)',
    '- Pins 10-11: Reserved for future use',
    '- Pin 12: Cable shield (drain wire)',
]
for i, note in enumerate(notes):
    ax.text(0.3, 0.5 - i * 0.25, note, fontsize=7, color=COLORS['gray_dark'])

plt.tight_layout()
buf = BytesIO()
fig.savefig(buf, format='png', dpi=200, bbox_inches='tight', facecolor='white', edgecolor='none')
buf.seek(0)
plt.close(fig)
display(IPImage(data=buf.getvalue()))
```

## Assembly Procedures {#sec-assembly-procedures}

### Preparation Steps

1. **Inspect All Parts:** Verify all printed parts are present and undamaged, no visible layer separation or cracks
2. **Prepare Workspace:** Clean, well-lit, well-ventilated area with protected work surface
3. **Test-Fit Parts (Dry Run):** Test thread engagement on all threaded parts, verify tube sections fit inserts, check O-ring sizing

### Rod Segment Preparation

Cut fiberglass tubing to desired lengths (50 cm or 100 cm **(Target)** segments are standard). Use steady, even strokes with the hacksaw and rotate the tube to keep the cut square. After cutting, deburr the ends by removing fiberglass fibers with a file and sanding smooth with 400-grit **(Manufacturer spec)** sandpaper.

::: {.callout-note}
## Rod Assembly Convention

- Rods have Male threads at bottom, Female at top
- Apply epoxy to flange of insert before installation
- Ensure shoulder sits flush against tube cut
- Allow 24 hours cure time before stressing threads
:::
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

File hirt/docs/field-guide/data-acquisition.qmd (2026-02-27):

---
title: "Data Acquisition"
---

## Overview {#sec-data-acquisition-overview}

This section covers practical data acquisition procedures for HIRT field measurements. For detailed data format specifications and software compatibility, see the [Data Formats](../developer/data-formats.qmd) section in the Developer Guide.

## The Measurement Matrix Concept

HIRT data acquisition is based on a **transmit-receive (TX-RX) matrix**. For an array of N probes:

- Each probe takes turns acting as the **transmitter** (TX)
- While transmitting, **all other probes** simultaneously act as receivers (RX)
- This produces N × (N-1) unique TX-RX measurements per frequency (MIT) or injection pattern (ERT)
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

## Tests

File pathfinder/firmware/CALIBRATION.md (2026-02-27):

# Pathfinder Calibration Guide

Procedures for calibrating and validating the Pathfinder gradiometer system.

## Overview

Calibration establishes baseline performance and corrects for:
1. **Sensor offset**: Each sensor's zero-field reading
2. **Gain variation**: Sensitivity differences between sensors
3. **Gradient baseline**: Top-bottom pair matching
4. **Temperature drift**: Environmental effects

## Pre-Calibration Checklist

- [ ] All sensors mechanically mounted and secure
- [ ] System powered and logging for 10+ minutes (thermal stabilization)
- [ ] Magnetically clean environment (no metal objects within 5m)
- [ ] GPS locked (for position logging)
- [ ] Notebook ready for recording values

## Level 1: Basic Offset Calibration

**Purpose**: Establish zero-field baseline for each sensor

**Location**: Magnetically quiet area (park, field, away from buildings/vehicles)

### Procedure

1. **Thermal Stabilization**
   - Power on system
   - Let run for 15 minutes before measurements
   - This allows electronics to reach stable temperature

2. **Static Measurement**
   - Place gradiometer on ground in level position
   - Ensure no metal objects nearby (>5m clear zone)
   - Record 60 seconds of data (600 samples at 10 Hz)
   - Do NOT move system during measurement

3. **Download and Analyze**
   ```bash
   python tools/visualize_data.py PATH_CALIB.CSV --stats-only
   ```

4. **Record Baseline Values**

   Note the **mean** value for each channel from statistics output:

   | Sensor | Mean ADC | Notes |
   |--------|----------|-------|
   | Pair 1 Top | _______ | |
   | Pair 1 Bot | _______ | |
   | Pair 2 Top | _______ | |
   | Pair 2 Bot | _______ | |
   | Pair 3 Top | _______ | |
   | Pair 3 Bot | _______ | |
   | Pair 4 Top | _______ | |
   | Pair 4 Bot | _______ | |

5. **Check Gradient Baseline**

   Each pair's gradient should be **near zero** (typically <50 ADC counts):

   | Pair | Gradient Mean | Status |
   |------|---------------|--------|
   | 1 | _______ | □ Pass (<50) |
   | 2 | _______ | □ Pass (<50) |
   | 3 | _______ | □ Pass (<50) |
   | 4 | _______ | □ Pass (<50) |

   **If gradient >100**: Sensors not properly balanced. Check:
   - Sensors at same height
   - Sensors parallel to ground
   - No metal near one sensor but not the other

## Level 2: Noise Floor Measurement

**Purpose**: Verify system meets target noise specifications

### Procedure

1. **Indoor Test** (electromagnetically shielded if possible)
   - Record 60 seconds stationary
   - Calculate standard deviation of gradient

2. **Noise Metrics**

   From statistics output, note **Std Dev** for gradients:

   | Pair | Gradient Std Dev | Target | Status |
   |------|------------------|--------|--------|
   | 1 | _______ | <20 | □ Pass |
   | 2 | _______ | <20 | □ Pass |
   | 3 | _______ | <20 | □ Pass |
   | 4 | _______ | <20 | □ Pass |

   **Target**: Gradient noise <20 ADC counts RMS

   **If noise >50**: Investigate:
   - Poor power supply filtering
   - Ground loops
   - Electromagnetic interference (RFI)
   - Loose sensor connections
   - Sensor cable shielding issues

## Level 3: Dynamic Response Test

**Purpose**: Verify system tracks magnetic changes correctly

### Test 1: Ferrous Object Response

1. **Baseline Measurement**
   - Record 10 seconds with no object present
   - Note mean gradient value

2. **Object Introduction**
   - Place small ferrous object (wrench, hammer) 50 cm below bottom sensor
   - Record 10 seconds
   - Note gradient change

3. **Object Removal**
   - Remove object
   - Record 10 seconds
   - Verify gradient returns to baseline

**Expected Results**:
- Clear gradient increase when object present (100-500 ADC counts)
- Return to baseline within ±10 counts after removal
- All pairs show similar sensitivity

### Test 2: Background Rejection

**Purpose**: Verify gradiometer cancels uniform fields

1. **Rotate System**
   - Hold gradiometer and slowly rotate 360° (one full turn over 60 seconds)
   - Record data throughout
   - Gradient should remain stable

**Expected Results**:
- Gradient variation <50 ADC counts during rotation
- No systematic drift with orientation

**If fails**:
- Sensors not vertically aligned
- Different sensor gains
- Sensor mounting not rigid

## Level 4: Inter-Pair Consistency

**Purpose**: Verify all 4 pairs respond similarly

### Procedure

1. **Controlled Anomaly**
   - Place calibrated ferrous target at known position
   - Record reading from all pairs
   - Compare response amplitude

2. **Consistency Check**

   | Pair | Gradient Response | Normalized |
   |------|------------------|------------|
   | 1 | _______ | 100% (reference) |
   | 2 | _______ | ____% |
   | 3 | _______ | ____% |
   | 4 | _______ | ____% |

   **Target**: All pairs within ±20% of reference

**If variation >30%**:
- Check sensor type/model consistency
- Verify sensor power supply voltage
- Inspect sensor mounting (different heights?)
- Check ADC wiring (swapped channels?)

## Level 5: GPS Positional Accuracy

**Purpose**: Verify GPS coordinates align with physical position

### Procedure

1. **Static Position Test**
   - Place system at known GPS coordinates (e.g., survey marker)
   - Record 5 minutes of data
   - Calculate GPS scatter

2. **GPS Metrics**

   From visualize_data.py output:
   - **Lat scatter**: ____________ degrees (target: <0.00001° = ~1m)
   - **Lon scatter**: ____________ degrees (target: <0.00001° = ~1m)
   - **Fix percentage**: _________% (target: >95%)

**If fix <90%**:
- Improve antenna placement (clear sky view)
- Check antenna connection
- Wait longer for satellite acquisition
- Consider external active antenna

## Calibration Data Recording

### Template

```
PATHFINDER CALIBRATION RECORD
Date: _______________
Location: _______________
Temperature: _______°C
Humidity: _______%

SENSOR BASELINES (ADC counts):
Pair 1: Top=______ Bot=______ Grad=______
Pair 2: Top=______ Bot=______ Grad=______
Pair 3: Top=______ Bot=______ Grad=______
Pair 4: Top=______ Bot=______ Grad=______

NOISE FLOOR (ADC counts RMS):
Pair 1: ______
Pair 2: ______
Pair 3: ______
Pair 4: ______

DYNAMIC TESTS:
Ferrous Response: □ Pass □ Fail
Rotation Test: □ Pass □ Fail
Inter-Pair Consistency: □ Pass □ Fail

GPS PERFORMANCE:
Fix Rate: ______%
Position Scatter: ______ meters

NOTES:
_________________________________
_________________________________
_________________________________

Calibrated by: _______________
```

## Applying Calibration in Post-Processing

After calibration, apply corrections to survey data:

### Python Example

```python
import pandas as pd

# Load survey data
df = pd.read_csv('PATH0001.CSV')

# Calibration offsets from Level 1
offsets = {
    'g1_grad': 25,   # Example values
    'g2_grad': 18,
    'g3_grad': -12,
    'g4_grad': 22,
}

# Apply offset correction
for col, offset in offsets.items():
    df[f'{col}_cal'] = df[col] - offset

# Now df['g1_grad_cal'] etc. are offset-corrected gradients
```

### Gain Correction (Advanced)

If sensors show different sensitivities (Level 4), apply gain correction:

```python
# Gain factors from Level 4 (normalized to pair 1)
gains = {
    'g1_grad': 1.00,
    'g2_grad': 0.95,  # 5% less sensitive
    'g3_grad': 1.08,  # 8% more sensitive
    'g4_grad': 1.02,
}

# Apply gain correction
for col, gain in gains.items():
    df[f'{col}_cal'] = df[f'{col}_cal'] / gain
```

## Recalibration Schedule

- **Daily**: Quick baseline check (5 min static measurement)
- **Weekly**: Full Level 1-2 calibration
- **Monthly**: Complete Level 1-5 validation
- **After repair**: Full calibration sequence
- **Season change**: Recheck offsets (temperature effects)

## Field Calibration Procedure

Quick baseline check before each survey:

1. Power on, wait 5 minutes (thermal stabilization)
2. Record 30 seconds static in survey area
3. Check gradient means <100 ADC counts
4. If >100, investigate:
   - System on level ground?
   - Metal objects nearby?
   - Sensor mount loosened during transport?

## Troubleshooting Calibration Issues

### Large Gradient Offsets (>200 counts)

**Possible Causes**:
1. Sensors at different heights
2. Metal contamination near one sensor
3. Sensor gain mismatch
4. Poor mounting (vibration during measurement)

**Solutions**:
- Verify mechanical alignment with level
- Measure sensor separation (should be 50 cm ±1 cm)
- Check for metal screws, bolts in mounting
- Rigidly secure sensors to prevent vibration

### High Noise (>50 counts RMS)

**Possible Causes**:
1. Power supply noise
2. Ground loops
3. Electromagnetic interference
4. Sensor cable issues

**Solutions**:
- Add capacitors (10µF, 0.1µF) at sensor power pins
- Ensure single-point ground (no loops)
- Shield sensor cables, ground at one end only
- Move away from power lines, WiFi, cell towers
- Lower ADC data rate (128 → 64 SPS)

### GPS Poor Fix Rate

**Possible Causes**:
1. Obstructed sky view
2. Metallic objects nearby
3. Antenna placement
4. Atmospheric conditions

**Solutions**:
- Move to open area
- Raise antenna higher
- Use external active antenna
- Wait longer for satellite acquisition (2+ minutes)

## Validation Targets

Use known targets to verify system performance:

### Buried Pipe Test

1. Bury steel pipe (10 cm diameter, 1m length) at 30 cm depth
2. Survey over pipe location
3. Verify clear gradient anomaly (>200 counts)
4. Compare to theoretical model

### Reference Anomaly

Create permanent calibration site:
- Bury ferrous object at known location
- Record GPS coordinates
- Use for periodic validation checks

## Advanced: Temperature Compensation

If operating in varying temperatures:

1. **Measure Temperature Effect**
   - Record data while temperature changes (morning to noon)
   - Plot gradient vs. temperature
   - Calculate drift coefficient (ADC counts / °C)

2. **Apply Compensation**
   - Add temperature sensor (DS18B20)
   - Correct readings in post-processing:
   ```python
   drift_coeff = 2.5  # ADC counts per °C
   temp_ref = 20.0    # Reference calibration temp
   df['g1_grad_temp_comp'] = df['g1_grad'] - drift_coeff * (temp - temp_ref)
   ```

## Support

For calibration questions:
- See `README.md` for hardware troubleshooting
- See `WIRING.md` for connection issues
- Project repository for community support

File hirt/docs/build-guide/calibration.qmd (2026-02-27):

---
title: "Calibration"
---

## Overview {#sec-calibration-overview}

This section provides detailed calibration procedures for HIRT probes before field deployment. Calibration ensures accurate and consistent measurements across all probes in the array. The dual-channel nature of HIRT (MIT and ERT) requires calibration of both subsystems, along with system-level verification to ensure the complete measurement chain performs within specification.

Proper calibration is essential for scientific data quality. Without it, probe-to-probe variations can introduce systematic errors that compromise tomographic reconstruction. The procedures outlined here establish traceability from individual components through to array-level cross-calibration.

## Calibration Principles {#sec-calibration-principles}

### Why Calibrate? {#sec-why-calibrate}

1. **Probe-to-probe consistency** - Ensure all probes give comparable readings under identical conditions
2. **Accuracy** - Relate measurements to physical units (mH, ohms, volts)
3. **Drift compensation** - Account for component aging and environmental effects
4. **Quality assurance** - Verify proper assembly and function before deployment

```{python}
#| label: fig-calibration-hierarchy
#| fig-cap: "Calibration hierarchy showing the progression from component-level measurements through array-level cross-calibration. Each level builds upon the previous, increasing overall system confidence."
#| fig-width: 9
#| fig-height: 5

import sys; sys.path.insert(0, '..') if '..' not in sys.path else None
from diagrams.calibration import create_calibration_hierarchy
import matplotlib.pyplot as plt
from PIL import Image

buf = create_calibration_hierarchy()
img = Image.open(buf)
plt.figure(figsize=(9, 5))
plt.imshow(img)
plt.axis('off')
plt.tight_layout()
plt.show()
```

### Key Parameters and Tolerances {#sec-key-parameters}

| Parameter | Target | Tolerance | Measurement Freq |
|---|---|---|---|
| Coil Inductance | 1.5 mH (Target) | +/-10% | 1 kHz |
| Coil Q Factor @ 2 kHz | >=25 (Target) | Minimum | 2 kHz |
| Coil Q Factor @ 10 kHz | >=30 (Target) | Minimum | 10 kHz |
| Coil Q Factor @ 50 kHz | >=20 (Target) | Minimum | 50 kHz |
| Coil DC Resistance | <8 ohm (Target) | Maximum | DC |
| Self-Resonant Freq | >200 kHz (Target) | Minimum | VNA sweep |
| TX-RX Coupling | <-40 dB (Target) | Maximum | 10 kHz |
| DDS Frequency | Commanded | +/-1% (Target) | All |
| TX Amplitude | Design spec | +/-10% (Target) | All |
| RX Gain | Design spec | +/-10% (Target) | All |
| ERT Current | Commanded | +/-5% (Target) | DC |
| Reciprocity | A->B = B->A | +/-5% (Target) | All |

: Calibration parameters and acceptance tolerances. All thresholds are (Target) unless otherwise noted. {#tbl-calibration-params}

### Expected Data Error Thresholds {#sec-error-thresholds}

Based on published practices in the geophysical literature (SimPEG, pyGIMLi), the following measurement repeatability thresholds establish pass/fail criteria for quality control:

| Measurement Type | Expected Error | QC Threshold | Notes |
|---|---|---|---|
| MIT amplitude | 3-5% (Target) | <5% (Target) | Relative measurement-to-measurement |
| MIT phase | 2-3 deg (Target) | <5 deg (Target) | Absolute phase accuracy |
| ERT resistance | 3-5% (Target) | <5% (Target) | Relative error typical for DC resistivity |
| Reciprocity | <3% (Target) | <5% (Target) | A->B vs B->A difference |

: Expected measurement error thresholds for QC pass/fail determination {#tbl-error-thresholds}

These thresholds are consistent with standard inversion software defaults (e.g., pyGIMLi uses 3% relative error for ERT (Manufacturer spec); SimPEG recommends 5-10% data uncertainty for DC resistivity (Manufacturer spec)). Measurements exceeding these thresholds should be flagged for review and potential re-acquisition.

## Calibration Workflow {#sec-calibration-workflow}

The calibration workflow proceeds through three main phases: MIT calibration (air baseline, known resistor test, frequency sweep), ERT calibration (ring isolation, contact resistance, current source verification), and target response characterization (metal target tests, distance sweeps, lookup table generation).

```{python}
#| label: fig-calibration-workflow
#| fig-cap: "Complete calibration workflow showing the three-phase approach: MIT calibration (blue), ERT calibration (green), and target response characterization (orange). Checkmarks indicate verification points where data is recorded."
#| fig-width: 10
#| fig-height: 7

import sys; sys.path.insert(0, '..') if '..' not in sys.path else None
from diagrams.flowcharts import create_calibration_workflow

buf = create_calibration_workflow()
img = Image.open(buf)
plt.figure(figsize=(10, 7))
plt.imshow(img)
plt.axis('off')
plt.tight_layout()
plt.show()
```

## Required Equipment {#sec-calibration-equipment}

| Equipment | Purpose | Notes |
|---|---|---|
| LCR Meter | Coil measurements | Set to 10 kHz |
| Oscilloscope | Signal verification | 50 MHz minimum (Target) |
| Multimeter | V/I/R measurements | 6-digit preferred |
| Function Generator | Signal injection | 1 Hz - 100 kHz |
| Known Test Targets | Coupling verification | Al plate, steel bar |
| Test Medium | ERT testing | Sand box, known resistivity |
| Reference Probe | Cross-calibration | If available |

: Required calibration equipment {#tbl-calibration-equipment}

### Environment Requirements {#sec-environment-requirements}

- Temperature: 20-25C (stable, within +/-2C during calibration) (Target)
- EMI: Minimize interference sources (turn off nearby equipment, use shielded area)
- Warm-up time: Allow 15-30 minutes for equipment stabilization (Target)
- Humidity: <80% RH to prevent condensation on probe surfaces (Target)

## Air Calibration Setup {#sec-air-calibration}

Air calibration establishes the baseline response of the probe when isolated from all external influences. The probe is suspended on a non-metallic stand (wood, PVC, or fiberglass) at least 1 meter (Target) from any metal objects. This measurement provides the 'zero' reference for subsequent target detection.

```{python}
#| label: fig-air-calibration-setup
#| fig-cap: "Air calibration test setup showing probe suspended on non-metallic stand with test equipment connections. The 1-meter exclusion zone ensures no spurious coupling from nearby metal objects."
#| fig-width: 10
#| fig-height: 5

import sys; sys.path.insert(0, '..') if '..' not in sys.path else None
from diagrams.calibration import create_air_calibration_setup

buf = create_air_calibration_setup()
img = Image.open(buf)
plt.figure(figsize=(10, 5))
plt.imshow(img)
plt.axis('off')
plt.tight_layout()
plt.show()
```

## Coil Calibration Procedures {#sec-coil-calibration}

### TX Coil Inductance {#sec-tx-inductance}

1. Connect LCR meter to TX coil leads (ensure proper polarity)
2. Set measurement frequency to 1 kHz (reference frequency)
3. Measure inductance (L) and record in mH
4. Compare to specification: target 1.5 mH (Target), tolerance +/-10% (1.35-1.65 mH)
5. Record Pass/Fail status on calibration sheet

### TX Coil Q Factor (Multi-Frequency) {#sec-tx-q-factor}

The Q factor must be measured across the full operating frequency range:

| Frequency | Minimum Q | Notes |
|---|---|---|
| 2 kHz | >=25 (Target) | Deep penetration mode |
| 10 kHz | >=30 (Target) | Primary operating frequency |
| 50 kHz | >=20 (Target) | High-resolution mode |

**Procedure:**

1. Using same LCR meter setup as inductance measurement
2. Measure Q factor at 2 kHz, 10 kHz, and 50 kHz
3. Alternatively, calculate: $Q = (2\pi fL) / R$ where R is the measured ESR
4. All three frequency points must pass minimum Q thresholds
5. Low Q indicates: winding issues, wrong core material, excessive self-capacitance, or core saturation

**Self-Resonant Frequency Check:**

If VNA available, sweep 100 kHz - 1 MHz to identify the self-resonant frequency (SRF). Target: SRF > 200 kHz (Target). If SRF falls within operating range (2-50 kHz), the coil must be rewound with single-layer technique to reduce parasitic capacitance.

### RX Coil Parameters {#sec-rx-coil-params}

Repeat the inductance and Q factor measurements for the RX coil. The RX coil specifications should match the TX coil within tolerance to ensure balanced coupling characteristics. Record all measurements on the calibration sheet.

## TX Chain Calibration {#sec-tx-calibration}

### DDS Frequency Accuracy {#sec-dds-frequency}

Verify the DDS (Direct Digital Synthesis) generates correct frequencies across the operating range. Test at: 2, 5, 10, 20, and 50 kHz. Measure each commanded frequency with an oscilloscope and calculate frequency error.

$$
\text{Error (\%)} = \frac{f_{\text{actual}} - f_{\text{commanded}}}{f_{\text{commanded}}} \times 100
$$

Expected accuracy: +/-1% or better (Target). Larger errors indicate DDS programming issues or clock reference problems.

### TX Output Amplitude {#sec-tx-amplitude}

- DDS output: ~0.6 V RMS typical (Modeled) (before driver stage)
- Driver output: 1-5 V RMS (design dependent) (Target)
- Gain should be 2-5x across frequency range (Target)
- Check for flat frequency response (+/-1 dB) (Target)

## RX Chain Calibration {#sec-rx-calibration}

### RX Chain Gain {#sec-rx-gain}

Verify RX amplification chain gain by injecting a known test signal at the RX input and measuring output at each stage. A typical test signal is 1 mV at 10 kHz (Target). Measure at preamp output, instrumentation amplifier output, and ADC input. Calculate gain at each stage and total system gain.

### RX Noise Floor {#sec-rx-noise-floor}

1. Place probe in quiet environment (away from metal objects)
2. Apply no input signal (or short input terminals)
3. Measure output noise amplitude over 10-second window
4. Record multiple measurements and calculate standard deviation
5. Target: Noise floor < 1% of full scale (Target)

## Known-Target Test Setup {#sec-known-target-setup}

The known-target test verifies that the complete MIT system detects conductive targets with the expected amplitude and phase response. Two probes are set up 1-3 meters apart (Target) with a known target (aluminum plate or steel bar) placed between them. This test validates both the detection sensitivity and the multi-frequency response characteristics.

```{python}
#| label: fig-known-target-setup
#| fig-cap: "Known-target test configuration with two probes and calibration target. The aluminum plate provides a non-magnetic conductive target, allowing verification of eddy current detection without ferrous interference."
#| fig-width: 10
#| fig-height: 5.5

import sys; sys.path.insert(0, '..') if '..' not in sys.path else None
from diagrams.calibration import create_known_target_setup

buf = create_known_target_setup()
img = Image.open(buf)
plt.figure(figsize=(10, 5.5))
plt.imshow(img)
plt.axis('off')
plt.tight_layout()
plt.show()
```

### Expected Results {#sec-expected-results}

- Amplitude reduction: 10-50% depending on target size and distance (Modeled)
- Phase lag: 5-30 degrees depending on frequency and target conductivity (Modeled)
- Lower frequencies show deeper sensitivity (skin depth effect)
- Response should scale predictably with target distance

### Reciprocity Verification {#sec-reciprocity-verification}

Reciprocity checks are essential for validating measurement quality. For both MIT and ERT, swapping transmitter and receiver should yield equivalent measurements within error bounds:

$$
\frac{|M_{A \rightarrow B} - M_{B \rightarrow A}|}{(M_{A \rightarrow B} + M_{B \rightarrow A})/2} \times 100\% < 5\% \text{ (Target)}
$$ {#eq-reciprocity}

where $M$ represents the measured quantity (voltage ratio for MIT, apparent resistivity for ERT).

::: {.callout-tip}
## Reciprocity Check Protocol

1. Measure forward path (A transmit -> B receive)
2. Measure reciprocal path (B transmit -> A receive)
3. Calculate percent difference using @eq-reciprocity
4. Flag measurements exceeding 5% (Target) for investigation
5. Common causes of poor reciprocity: loose connections, electrode corrosion, coupling variations
:::

Systematic reciprocity errors indicate calibration drift or hardware issues. Random reciprocity failures suggest environmental noise or poor electrode contact. The pyGIMLi crosshole ERT examples recommend filtering data points with reciprocal error exceeding 5% (Manufacturer spec) before inversion.

## Calibration Data Analysis {#sec-data-analysis}

Calibration data should be plotted to verify system behavior matches expected models. The amplitude response shows the normalized signal strength versus frequency for both baseline (air) and with-target conditions. The phase response shows the phase angle change introduced by the target. Both measurements should fall within specified tolerances.

```{python}
#| label: fig-calibration-data-chart
#| fig-cap: "Representative calibration data showing (a) amplitude response and (b) phase response across the MIT operating frequency range. Error bars indicate measurement uncertainty. The phase shift between baseline and with-target conditions provides target characterization information."
#| fig-width: 10
#| fig-height: 4.5

import sys; sys.path.insert(0, '..') if '..' not in sys.path else None
from diagrams.calibration import create_calibration_data_chart

buf = create_calibration_data_chart()
img = Image.open(buf)
plt.figure(figsize=(10, 4.5))
plt.imshow(img)
plt.axis('off')
plt.tight_layout()
plt.show()
```

## ERT Calibration {#sec-ert-calibration}

### Ring Isolation Verification {#sec-ring-isolation}

Verify electrical isolation between ERT rings to ensure independent measurements. Measure resistance between all ring pairs, between rings and ground, and between rings and the probe rod. All measurements should exceed 1 M-ohm (Target). Lower values indicate contamination or insulation failure.

### Current Source Calibration {#sec-current-source-calibration}

1. Connect current source to test load (1 k-ohm precision resistor) (Target)
2. Set commanded current level (start at 1 mA)
3. Measure actual current with calibrated multimeter
4. Calculate calibration factor: Cal = I_actual / I_commanded
5. Test across full range: 0.5, 1.0, 1.5, 2.0 mA (Target)
6. Record all values and average calibration factor

## Error Analysis and Uncertainty Budget {#sec-error-analysis}

Scientific data reporting requires characterizing not just the measured value, but its uncertainty. The HIRT system has both systematic errors (consistent offsets that can be removed via calibration) and random errors (unpredictable fluctuations reduced by averaging).

| Source | Type | Magnitude | Distribution |
|---|---|---|---|
| Reference Resistor | Systematic | 0.1% (Manufacturer spec) | Rectangular |
| ADC Quantization | Random | < 1 uV (Modeled) | Uniform |
| Thermal Drift | Systematic | 50 ppm/C (Modeled) | Linear |
| Probe Geometry | Random | +/- 1 cm (Target) | Normal |
| Combined Uncertainty | Mixed | ~1-2% (Modeled) | (k=2) |

: Typical uncertainty budget for HIRT measurements {#tbl-uncertainty-budget}

All final data products should be reported with 95% confidence intervals (k=2):

$$
\text{Measurement} = X \pm 2\sigma
$$

## Field Quick-Check Procedure {#sec-field-quick-check}

Before each field deployment, perform these abbreviated checks to verify system readiness. This procedure takes approximately 15-30 minutes (Target) and can identify common issues before they affect data collection.

::: {.callout-note}
## Pre-Deployment Quick Check

- Visual inspection: No visible damage, all connections secure
- Power check: System powers on, LEDs functioning, communication established
- Coil quick test: TX/RX connected (~1-2 mH) (Target), Q factor reasonable (>20) (Target)
- ERT quick test: Rings isolated (>1 M-ohm) (Target), no shorts to ground
- Coupling verification: Wave hand near coil and observe response
:::

## Recalibration Schedule {#sec-recalibration-schedule}

| Trigger | Action |
|---|---|
| Before each field deployment | Quick check |
| After repairs or modifications | Full calibration |
| If measurements become inconsistent | Full calibration |
| Every 6 months minimum | Full calibration |
| After environmental exposure | Full calibration |

: Recalibration schedule triggers and actions {#tbl-recalibration-schedule}

Calibration is considered valid if: all measurements are within specifications, no repairs or modifications have been made since calibration, system performance remains consistent, and the calibration validity period has not expired (typically 6 months) (Target).

## Documentation Requirements {#sec-calibration-documentation}

Maintain complete calibration records for all probes in the system. Records should include probe identification, calibration date, calibrator name, all measured values with units, pass/fail status for each parameter, and recalibration due date. Store records in both digital and printed formats.

::: {.callout-warning}
## Calibration Record Retention

- All probes must have current calibration records
- Records must be available during field operations
- Out-of-tolerance conditions must be documented
- Probes failing calibration must not be deployed
:::

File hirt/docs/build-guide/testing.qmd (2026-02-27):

---
title: "Testing and Verification"
---

## Overview {#sec-testing-overview}

This section provides comprehensive testing procedures and quality control checklists for HIRT probes before field deployment. All probes must pass these tests to ensure reliable field operation. The testing framework covers mechanical integrity, electrical functionality, subsystem performance, and system integration.

::: {.callout-note}
## Testing Philosophy

- All tests must PASS for field deployment approval
- CONDITIONAL status requires documented workarounds and supervisor approval
- FAIL status requires repair, component replacement, and complete re-test
- Quantitative measurements recorded for traceability and trend analysis
:::

## Testing Workflow {#sec-testing-workflow}

The HIRT testing workflow follows a systematic progression from basic mechanical verification through complete system integration testing. Each stage must be completed successfully before proceeding to the next, ensuring that fundamental issues are identified and resolved before more complex testing begins.

### Test Sequence {#sec-test-sequence}

1. **Mechanical Testing** - Verify physical integrity of rod, probe head, ERT rings, and cables
2. **Electrical Testing** - Verify power supply, continuity, and communication interfaces
3. **MIT Subsystem Testing** - Verify coils, DDS, TX driver, RX chain, and coupling response
4. **ERT Subsystem Testing** - Verify ring isolation, contact resistance, and measurement chain
5. **System Integration Testing** - Verify complete system operation and data collection
6. **Environmental Testing** - Verify temperature stability and waterproofing (as applicable)
7. **QC Sign-off** - Final documentation review and deployment approval

```{python}
#| label: fig-verification-workflow
#| fig-cap: "Complete testing and verification workflow showing test categories, individual tests within each category, and the sequential progression from mechanical testing through QC sign-off. Each decision point requires all tests within the category to pass before proceeding."
#| fig-width: 11
#| fig-height: 8

import sys; sys.path.insert(0, '..') if '..' not in sys.path else None
from diagrams.testing import create_verification_workflow
import matplotlib.pyplot as plt
from PIL import Image

buf = create_verification_workflow()
img = Image.open(buf)
plt.figure(figsize=(11, 8))
plt.imshow(img)
plt.axis('off')
plt.tight_layout()
plt.show()
```

## Pre-Testing Setup {#sec-pre-testing}

### Test Equipment Required {#sec-test-equipment}

| Equipment | Purpose | Minimum Specification |
|---|---|---|
| Power Supply | Probe power delivery | 5V or 12V, current-limited to 2A **(Target)** |
| Digital Multimeter | Resistance, voltage, current | 0.1% accuracy **(Target)**, 4.5 digit |
| LCR Meter | Coil inductance and Q factor | 10 kHz test frequency, 0.1% accuracy **(Target)** |
| Oscilloscope | Signal verification | 50 MHz bandwidth **(Target)**, 2-channel minimum |
| Function Generator | Signal injection testing | 1 Hz - 100 kHz **(Target)**, sine/square |
| Base Hub | System-level testing | Complete calibrated unit |

: Test equipment requirements for HIRT probe verification {#tbl-test-equipment}

```{python}
#| label: fig-test-setup
#| fig-cap: "Test bench setup diagram showing the probe under test (center) connected to various test instruments. Power supply provides regulated DC power, DMM measures ERT parameters, LCR meter characterizes coils, oscilloscope monitors signals, function generator injects test waveforms, and base hub enables full system testing."
#| fig-width: 11
#| fig-height: 7

import sys; sys.path.insert(0, '..') if '..' not in sys.path else None
from diagrams.testing import create_test_setup_diagram

buf = create_test_setup_diagram()
img = Image.open(buf)
plt.figure(figsize=(11, 7))
plt.imshow(img)
plt.axis('off')
plt.tight_layout()
plt.show()
```

### Test Environment Requirements {#sec-test-environment}

- Clean, well-lit workbench with adequate space for equipment and probe
- Temperature: 20-25 degrees C **(Target)** (controlled room temperature)
- Minimize EMI sources: move phones, radios, and switching power supplies away
- Follow electrical safety procedures: use current-limited supplies, proper grounding
- Prepare test log template, probe registry entry, and calibration sheet before starting

## Mechanical Tests {#sec-mechanical-tests}

### Test M1: Rod Integrity {#sec-test-m1}

**Purpose:** Verify the probe rod is straight, undamaged, and properly assembled.

**Procedure:**

1. Inspect rod visually for cracks, bends, scratches, or other damage
2. Measure rod length using tape measure (should match specification +/-5 mm **(Target)**)
3. Roll rod on flat surface to check straightness - observe for wobble
4. Verify thread engagement on all joints (multi-section probes)
5. Perform gentle pull test on joints - no movement should occur

**Pass Criteria:** No visible damage, length within specification, rod straight, threads engaged properly, joints secure with no movement.

### Test M2: Probe Head Integrity {#sec-test-m2}

**Purpose:** Verify the probe head (junction box) is properly sealed and assembled.

1. Inspect capsule for cracks, damage, or discoloration
2. Verify cap seal is properly seated with no gaps
3. Check cable gland seal - should be tight with no cable movement
4. Test attachment to rod - should be secure with no rotation
5. Shake gently to check for loose internal components

### Test M3: ERT Ring Mounting {#sec-test-m3}

**Purpose:** Verify ERT electrode rings are properly mounted and positioned.

| Ring | Position from Tip | Tolerance |
|---|---|---|
| Ring 1 | 0.5 m **(Target)** | +/- 2 cm **(Target)** |
| Ring 2 | 1.5 m **(Target)** | +/- 2 cm **(Target)** |
| Ring 3 | 2.5 m **(Target)** | +/- 2 cm **(Target)** |

: ERT ring position specifications {#tbl-ert-positions}

### Test M4: Cable Integrity {#sec-test-m4}

Visual inspection of cable for damage, kinks, or abrasion. Test continuity of all conductors end-to-end. Verify cable routing has no sharp bends that could damage insulation. Check strain relief at both ends. Gentle pull test to verify secure termination.

## Electrical Tests {#sec-electrical-tests}

### Test E1: Power Supply Verification {#sec-test-e1}

**Purpose:** Verify power input and regulation circuits function correctly.

| Parameter | Target | Tolerance | Status |
|---|---|---|---|
| 3.3V Rail | 3.3V **(Target)** | +/- 0.1V **(Target)** | [ ] Pass [ ] Fail |
| 5V Rail | 5.0V **(Target)** | +/- 0.1V **(Target)** | [ ] Pass [ ] Fail |
| Current Draw | < spec | See datasheet | [ ] Pass [ ] Fail |
| Voltage Stability | Stable | No fluctuations | [ ] Pass [ ] Fail |
| Temperature | < 50C **(Target)** | No excessive heat | [ ] Pass [ ] Fail |

: Power supply test criteria {#tbl-power-test}

### Test E2: Continuity and Shorts {#sec-test-e2}

With power off, measure resistance between power and ground (should be >100 ohm **(Target)**). Check for shorts between all signal lines. Verify all connections are continuous end-to-end. Confirm shield connections are proper.

### Test E3: Communication Interface {#sec-test-e3}

Connect probe to base hub. Send test command and verify response. Test data transfer with multiple packets. Check reliability over 100 transactions (must be >95% success rate **(Target)**).

## MIT Subsystem Tests {#sec-mit-tests}

### Test MIT1: Coil Parameters {#sec-test-mit1}

| Parameter | TX Coil | RX Coil | Pass Criteria |
|---|---|---|---|
| Inductance | Measured: ___ | Measured: ___ | 1-2 mH **(Target)** |
| Q Factor @ 10 kHz | Measured: ___ | Measured: ___ | $\geq$ 30 **(Target)** |
| DC Resistance | Measured: ___ | Measured: ___ | < 8 ohm **(Target)** |
| Coil Isolation | N/A | N/A | > 1 M ohm **(Target)** |

: MIT coil parameter measurements. Q factor specification references calibration section (@sec-calibration-overview) for frequency-dependent targets. {#tbl-coil-params}

### Test MIT2: DDS Output {#sec-test-mit2}

Configure DDS for 10 kHz test frequency. Measure output with oscilloscope. Verify frequency accuracy is within +/-1% **(Target)**. Check output amplitude stability. Measure THD (target: <1% **(Target)**). Test at 2, 5, 10, 20, and 50 kHz.

### Test MIT3: TX Driver Output {#sec-test-mit3}

Measure DDS output before driver. Measure driver output after amplification. Calculate gain and compare to design specification (+/-10% **(Target)**). Verify no clipping or distortion. Test across frequency range.

### Test MIT4: RX Chain Response {#sec-test-mit4}

Inject known test signal into RX input. Measure signal at each amplification stage. Calculate gain at each stage. Verify total system gain matches design (+/-10% **(Target)**). Measure noise floor (target: <1% of full scale **(Target)**).

### Test MIT5: Coupling Test {#sec-test-mit5}

Set up two probes 1-3 m apart. Place aluminum calibration target between probes. Configure TX on one probe, RX on other. Measure amplitude and phase response. Remove target and establish baseline. Expected response with target: 10-50% amplitude drop **(Target)**, 5-30 degree phase lag **(Target)**.

## ERT Subsystem Tests {#sec-ert-tests}

### Test ERT1: Ring Isolation {#sec-test-ert1}

Measure resistance between adjacent rings (should be >1 M ohm **(Target)**). Measure each ring to ground and to probe rod body (all should be >1 M ohm **(Target)**). Repeat measurements after water exposure to verify sealing integrity.

### Test ERT2: Contact Resistance {#sec-test-ert2}

Insert probe into test medium (sand box with known resistivity). Inject test current (0.5-1 mA **(Target)**). Measure voltage between adjacent rings. Calculate contact resistance (target: <1000 ohm **(Target)**). Verify readings are stable with no drift.

### Test ERT3: Measurement Chain {#sec-test-ert3}

Apply known voltage to ERT input. Select each ring via multiplexer. Verify correct ring selection. Measure at amplifier output. Read ADC value and compare to expected (should be within +/-5% **(Target)**). Test all rings sequentially.

### Test ERT4: Current Source {#sec-test-ert4}

Connect to known test load resistance. Configure current levels: 0.5, 1.0, 1.5, 2.0 mA **(Target)**. Measure actual current at each setting. Verify accuracy is within +/-5% **(Target)**. Test stability over 1 minute at each level.

```{python}
#| label: fig-pass-fail-criteria
#| fig-cap: "Visual representation of pass/fail criteria for key test parameters: (a) Power supply voltage tolerance bands showing the +/-0.1V acceptable range for 3.3V and 5V rails; (b) MIT coil specification ranges for inductance, Q factor, and DC resistance; (c) ERT ring isolation requirements showing minimum 1 M ohm between rings and to ground; (d) DDS frequency accuracy tolerance of +/-1% across all test frequencies."
#| fig-width: 10
#| fig-height: 7

import sys; sys.path.insert(0, '..') if '..' not in sys.path else None
from diagrams.testing import create_pass_fail_criteria

buf = create_pass_fail_criteria()
img = Image.open(buf)
plt.figure(figsize=(10, 7))
plt.imshow(img)
plt.axis('off')
plt.tight_layout()
plt.show()
```

## System Integration Tests {#sec-integration-tests}

### Test INT1: Full System Test {#sec-test-int1}

Power on complete probe system. Verify communication with base hub. Test MIT measurement acquisition. Test ERT measurement acquisition. Verify data collection and storage. Test probe synchronization with other units.

### Test INT2: Reciprocity Test {#sec-test-int2}

Set up two probes (A and B) at fixed separation. Measure A transmitting to B. Measure B transmitting to A. Compare results - should match within 5% **(Target)**. Repeat for multiple probe pairs to verify consistency.
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

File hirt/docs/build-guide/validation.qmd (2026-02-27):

---
title: "Validation"
---

## Overview

This section documents validation protocols for verifying HIRT system performance against design specifications. Validation ensures that a newly constructed system meets the requirements for field deployment and provides traceable evidence for HardwareX journal compliance.

::: {.callout-note}
## Documentation Status

This section contains **Target specifications** that define expected performance. Measured validation data will be added as bench testing is completed. Specifications marked **(Target)** have not yet been validated against physical hardware.
:::
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

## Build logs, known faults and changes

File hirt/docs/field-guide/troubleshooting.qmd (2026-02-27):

---
title: "Troubleshooting"
---

## Overview {#sec-troubleshooting-overview}

This section provides diagnostic approaches and solutions for common issues encountered during HIRT field operations. Systematic troubleshooting ensures minimal downtime and maximum data quality during surveys.

::: {.callout-tip}
## How to Use This Section

**In the field:** Use the quick reference tables and diagnostic flowcharts for rapid problem identification. The tables are designed for scanning under time pressure.

**For deeper understanding:** Read the "Understanding..." narrative sections to learn why issues occur and how to prevent them in future surveys.
:::

## Diagnostic Approach {#sec-diagnostic-approach}

### System Check Procedure {#sec-system-check}

When issues arise, follow this systematic check procedure:

1. **Hub Power:** Verify the Central Hub power LED is green.
2. **Zone Continuity:** Check continuity between Hub Trunk port and Probe tip (using DMM).
3. **Trunk Seating:** Ensure all DB25/Trunk connectors are fully seated and screwed in.
4. **MIT Baseline:** Verify TX to RX coupling on two probes in air before insertion.

### Quick Reference Table {#sec-ts-quick-reference}

| Symptom | Likely Cause | Fix |
|---|---|-----|
| RX saturation on nearby probes | TX too strong | Lower TX level; rotate coils to orthogonal |
| Noisy MIT data | Trunk shielding issue | Check trunk cable ground; verify star ground |
| Unstable ERT voltages | Poor soil contact | Pre-moisten hole; apply saline gel |
| Zone Hub not detected | Trunk disconnected | Inspect DB25 pins; reseat Trunk Cable |
| Inconsistent repeats | Thermal drift | Allow 15 min warmup; check Hub fans |

: Common symptoms, causes, and solutions {#tbl-quick-reference}

### Diagnostic Decision Tree {#sec-decision-tree}

The following decision tree provides a systematic approach to diagnosing HIRT system issues, from initial symptom identification through resolution.

```{python}
#| label: fig-diagnostic-decision-tree
#| fig-cap: "Comprehensive diagnostic decision tree for HIRT troubleshooting. Follow the flowchart from the top to systematically identify and resolve issues."
#| fig-width: 14
#| fig-height: 10

import matplotlib
matplotlib.use('Agg')
import matplotlib.pyplot as plt
from matplotlib.patches import FancyBboxPatch, Polygon

COLORS = {
    'primary': '#1a365d',
    'secondary': '#2c5282',
    'accent': '#3182ce',
    'success': '#38a169',
    'warning': '#c53030',
    'orange': '#ed8936',
    'purple': '#805ad5',
    'gray_dark': '#4a5568',
    'gray_med': '#718096',
    'gray_light': '#a0aec0',
    'light_green': '#c6f6d5',
    'light_blue': '#ebf8ff',
    'light_orange': '#feebc8',
    'light_red': '#fed7d7',
    'light_purple': '#e9d8fd',
}

def draw_process_box(ax, x, y, width, height, text, color='white', fontsize=8):
    patch = FancyBboxPatch((x - width/2, y - height/2), width, height,
                           boxstyle="round,pad=0.02",
                           facecolor=color, edgecolor='black', linewidth=1)
    ax.add_patch(patch)
    ax.text(x, y, text, ha='center', va='center', fontsize=fontsize, wrap=True)

def draw_decision_diamond(ax, x, y, size, text, color='white'):
    half = size / 2
    points = [(x, y + half), (x + half, y), (x, y - half), (x - half, y)]
    patch = Polygon(points, facecolor=color, edgecolor='black', linewidth=1)
    ax.add_patch(patch)
    ax.text(x, y, text, ha='center', va='center', fontsize=7)

def draw_terminal(ax, x, y, width, height, text, color='white'):
    patch = FancyBboxPatch((x - width/2, y - height/2), width, height,
                           boxstyle="round,pad=0.3",
                           facecolor=color, edgecolor='black', linewidth=1.5)
    ax.add_patch(patch)
    ax.text(x, y, text, ha='center', va='center', fontsize=9, fontweight='bold')

def draw_flow_arrow(ax, start, end, label=None, color='black', label_offset=(0.1, 0)):
    ax.annotate('', xy=end, xytext=start,
                arrowprops=dict(arrowstyle='->', color=color, lw=1.5))
    if label:
        mid_x = (start[0] + end[0]) / 2 + label_offset[0]
        mid_y = (start[1] + end[1]) / 2 + label_offset[1]
        ax.text(mid_x, mid_y, label, fontsize=7, color=color)

fig, ax = plt.subplots(figsize=(14, 10))
ax.set_xlim(0, 14)
ax.set_ylim(0, 10)
ax.set_aspect('equal')
ax.axis('off')

ax.text(7, 9.7, 'HIRT Diagnostic Decision Tree', ha='center',
        fontsize=12, fontweight='bold', color=COLORS['primary'])

# Start terminal
draw_terminal(ax, 7, 9, 2.5, 0.5, 'ISSUE DETECTED', COLORS['light_red'])

# Level 1: Initial Assessment
draw_decision_diamond(ax, 7, 7.8, 1.4, 'Power\nLED On?', COLORS['light_blue'])
draw_flow_arrow(ax, (7, 8.75), (7, 8.5))

# Power OFF path
draw_flow_arrow(ax, (6.3, 7.8), (4, 7.8), 'No')
draw_process_box(ax, 2.5, 7.8, 2.2, 0.7, 'Check Battery\n>12.0V?', COLORS['light_orange'])
draw_flow_arrow(ax, (2.5, 7.45), (2.5, 6.8))
draw_decision_diamond(ax, 2.5, 6.3, 1.2, 'Battery\nOK?', COLORS['light_blue'])

draw_flow_arrow(ax, (1.9, 6.3), (0.8, 6.3), 'No')
draw_process_box(ax, 0.8, 5.5, 1.4, 0.6, 'Charge or\nReplace', COLORS['light_green'])

draw_flow_arrow(ax, (2.5, 5.7), (2.5, 5.0), 'Yes')
draw_process_box(ax, 2.5, 4.5, 2.0, 0.7, 'Check Fuse\n& Connectors', COLORS['light_orange'])
draw_flow_arrow(ax, (2.5, 4.15), (2.5, 3.5))
draw_terminal(ax, 2.5, 3.0, 2.0, 0.5, 'Replace\nFuse/Cable', COLORS['light_green'])

# Power ON path
draw_flow_arrow(ax, (7, 7.1), (7, 6.5), 'Yes')
draw_decision_diamond(ax, 7, 6, 1.4, 'Data\nOutput?', COLORS['light_blue'])

# No data path
draw_flow_arrow(ax, (7.7, 6), (9.5, 6), 'No')
draw_process_box(ax, 11, 6, 2.2, 0.7, 'Check USB/\nCommunication', COLORS['light_orange'])
draw_flow_arrow(ax, (11, 5.65), (11, 5.0))
draw_decision_diamond(ax, 11, 4.5, 1.2, 'Comms\nOK?', COLORS['light_blue'])

draw_flow_arrow(ax, (11.6, 4.5), (13, 4.5), 'No')
draw_process_box(ax, 13, 3.8, 1.6, 0.6, 'Replace\nCable', COLORS['light_green'])

draw_flow_arrow(ax, (11, 3.9), (11, 3.3), 'Yes')
draw_process_box(ax, 11, 2.8, 2.0, 0.7, 'Check Hub\nFirmware', COLORS['light_orange'])

# Data present path
draw_flow_arrow(ax, (7, 5.3), (7, 4.7), 'Yes')
draw_decision_diamond(ax, 7, 4.2, 1.4, 'Valid\nReadings?', COLORS['light_blue'])

# Invalid readings
draw_flow_arrow(ax, (6.3, 4.2), (5, 4.2), 'No')
draw_decision_diamond(ax, 4, 4.2, 1.2, 'MIT or\nERT?', COLORS['light_blue'])

# MIT branch
draw_flow_arrow(ax, (4, 3.6), (4, 2.8), 'MIT')
draw_process_box(ax, 4, 2.3, 2.2, 0.7, 'MIT Diagnostics', COLORS['light_purple'])

draw_flow_arrow(ax, (4, 1.95), (4, 1.4))
ax.add_patch(FancyBboxPatch((2.5, 0.3), 3.0, 1.0,
                            boxstyle="round,pad=0.02",
                            facecolor=COLORS['light_purple'], edgecolor=COLORS['purple'], lw=1))
ax.text(4, 0.8, 'MIT Checks:', ha='center', va='center', fontsize=8, fontweight='bold')
ax.text(4, 0.45, '* Coil connections\n* TX level (saturation?)\n* Frequency setting',
        ha='center', va='center', fontsize=6)

# ERT branch
draw_flow_arrow(ax, (4.6, 4.2), (5.5, 4.2))
draw_flow_arrow(ax, (5.5, 4.2), (5.5, 2.8), 'ERT')
draw_process_box(ax, 5.5, 2.3, 2.0, 0.7, 'ERT Diagnostics', COLORS['light_orange'])

draw_flow_arrow(ax, (6.5, 2.3), (8, 2.3))
ax.add_patch(FancyBboxPatch((7.5, 1.3), 3.0, 1.3,
                            boxstyle="round,pad=0.02",
                            facecolor=COLORS['light_orange'], edgecolor=COLORS['orange'], lw=1))
ax.text(9, 1.95, 'ERT Checks:', ha='center', va='center', fontsize=8, fontweight='bold')
ax.text(9, 1.4, '* Ring-soil contact\n* Pre-moisten hole\n* Current source\n* Saline gel application',
        ha='center', va='center', fontsize=6)

# Valid readings - SUCCESS
draw_flow_arrow(ax, (7, 3.5), (7, 2.8), 'Yes')
draw_terminal(ax, 7, 2.3, 2.5, 0.5, 'SYSTEM OK', COLORS['light_green'])

# Quick reference box
ax.add_patch(FancyBboxPatch((10.5, 7.5), 3.0, 1.8,
                            boxstyle="round,pad=0.02",
                            facecolor='white', edgecolor=COLORS['gray_med'], lw=1))
ax.text(12, 9.0, 'Quick Reference', ha='center', va='center', fontsize=9, fontweight='bold',
        color=COLORS['primary'])
ax.text(12, 8.4, '* Battery min: 12.0V\n* Warmup: 15 min\n* Ground: single-point\n* MIT freq: 2-20 kHz',
        ha='center', va='center', fontsize=7)

plt.tight_layout()
plt.show()
```

## MIT Troubleshooting {#sec-mit-troubleshooting}

### Understanding MIT Signal Path Issues

The MIT channel relies on detecting extremely weak secondary magnetic fields - typically in the nanovolt range at the receiver coil. This signal must survive a journey through 3-5 meters of probe cable and additional trunk cabling before reaching the preamplifier. Along this path, several factors conspire against signal integrity.

**The dynamic range challenge:** When the transmitter coil energizes, it creates a strong primary field that dominates the measurement environment. The receiver must detect tiny perturbations caused by eddy currents in buried conductors - a signal that may be 80-100 dB weaker than the primary field. This explains why proper coil orientation, careful gain staging, and adequate TX/RX separation are critical.

**Cable effects:** Every meter of cable adds capacitance that acts as a low-pass filter, attenuating high-frequency components. Longer cables also increase susceptibility to electromagnetic interference (EMI) pickup from power lines, vehicles, and radio transmitters. The twisted-pair and shielding specifications exist precisely to combat these effects.

**Ground loops:** Multiple ground connections create parasitic current paths that inject noise directly into the signal chain. The single-point grounding strategy at the Hub eliminates these loops, but field modifications or damaged cables can inadvertently create new ground paths.

### RX Saturation on Nearby Probes {#sec-rx-saturation}

**Symptoms:** Amplitude readings maxed out on nearby probes, phase readings erratic or stuck, effects only visible on probes close to TX.

**Causes:** TX output too high for close-range measurements, direct magnetic coupling between TX and RX coils, insufficient separation or poor coil orientation.

**Solutions:**

1. **Reduce TX level:** Lower DDS output or TX driver gain
2. **Increase separation:** Use wider probe spacing for close pairs
3. **Rotate coils:** Ensure TX and RX coils are orthogonal
4. **Add attenuation:** Use lower gain on RX for nearby probes
5. **Skip close pairs:** Do not measure TX to RX pairs less than 0.5 m apart

### Noisy MIT Data {#sec-noisy-mit}

**Symptoms:** High noise floor, erratic amplitude/phase readings, inconsistent measurements between sweeps.

**Causes:** Poor cable shielding, ground loops (multiple ground paths), electromagnetic interference from nearby sources, insufficient integration time.

**Solutions:**

1. **Check shielding:** Verify all cables are properly shielded
2. **Single-point ground:** Ensure only one ground connection at Hub
3. **Twist pairs:** Use twisted-pair cables for signal lines
4. **Increase integration:** Longer measurement time reduces noise
5. **Check for interference sources:** Move away from power lines, vehicles, radios
6. **Verify connections:** Check all connectors are tight and clean

### No Depth Sensitivity (MIT) {#sec-no-depth-mit}

**Symptoms:** Measurements do not change with depth, all readings similar regardless of target depth, no response to known deep targets.

**Solutions:**

1. **Lower frequencies:** Use 2-5 kHz for MIT (deeper penetration)
2. **Add longer offsets:** Include TX to RX pairs with >3 m spacing
3. **Deeper probes:** Insert probes deeper if possible
4. **Check targets:** Verify expected target depths are realistic for configuration

## ERT Troubleshooting {#sec-ert-troubleshooting}

### Understanding ERT Contact and Current Flow

Electrical resistivity measurements depend fundamentally on establishing reliable electrical contact between the metal electrode rings and the surrounding soil. Unlike MIT which uses inductive coupling through air, ERT requires actual galvanic contact - current must physically flow from the electrode into the soil matrix.

**The contact resistance problem:** When current flows from a metal electrode into soil, it encounters a transition zone where the current density is extremely high. This zone, typically only millimeters thick, often dominates the total resistance in the measurement circuit. Dry soil, air gaps, or organic debris around the electrode can increase contact resistance by orders of magnitude, making measurements unreliable or impossible.

**Polarization effects:** When DC current flows through an electrode-soil interface, electrochemical reactions occur. Ions accumulate at the electrode surface, creating a counter-voltage that opposes the applied current. This "polarization potential" builds up over time and can completely obscure the subsurface signal. The solution is to use alternating current (AC) or periodically reverse polarity, allowing the accumulated ions to disperse.

**Soil moisture dependence:** Soil conducts electricity primarily through the water filling its pore spaces. The dissolved ions in this pore water carry the current. Completely dry soil is essentially an insulator. This is why pre-moistening electrode holes and using conductive gels dramatically improves contact - you're providing the conductive medium the current needs.

**Current channeling:** In heterogeneous soils, current preferentially flows through the most conductive paths. A buried pipe, wet clay lens, or metal debris can "short circuit" your measurement, causing all current to flow through this preferential path rather than sampling the volume you intend to measure.

### Unstable ERT Voltages {#sec-unstable-ert}

**Symptoms:** Voltage readings drift or jump, inconsistent measurements, poor contact indicated in diagnostic output.

**Causes:** Dry soil preventing good electrical contact, poor ring-to-soil contact, loose connections, polarization effects at electrodes.

**Solutions:**

1. **Pre-moisten hole:** Add water to improve contact
2. **Use saline gel:** Apply conductive gel around rings
3. **Check ring contact:** Ensure rings are flush with soil
4. **Reverse polarity:** Use AC or periodic polarity reversal to reduce polarization
5. **Check connections:** Verify all wiring is secure
6. **Increase current:** Slightly higher current may improve SNR

### ERT Contact Problems {#sec-ert-contact}

**Symptoms:** High contact resistance, erratic voltage readings, some electrodes not responding.

**Solutions:**

1. Verify ring contact with soil
2. Add water around probe (improve contact)
3. Check ring-to-cable connection
4. Clean rings if accessible
5. Consider relocating probe if contact remains poor

### No Depth Sensitivity (ERT) {#sec-no-depth-ert}

**Symptoms:** All measurements show surface effects only, no response to known deep features, uniform readings across array.

**Solutions:**

1. **Longer ERT baselines:** Corner-to-corner, edge-to-edge injections
2. **Deeper probes:** Insert probes deeper if possible
3. **Wider spacing:** Increase array dimensions

```{python}
#| label: fig-troubleshooting-flowchart
#| fig-cap: "Quick troubleshooting flowchart for rapid issue identification. This simplified guide helps identify the most common failure modes."
#| fig-width: 10
#| fig-height: 8

import matplotlib.pyplot as plt
from matplotlib.patches import FancyBboxPatch, Polygon, Rectangle

COLORS = {
    'primary': '#1a365d',
    'secondary': '#2c5282',
    'accent': '#3182ce',
    'success': '#38a169',
    'warning': '#c53030',
    'orange': '#ed8936',
    'light_blue': '#ebf8ff',
    'light_green': '#c6f6d5',
    'light_orange': '#feebc8',
    'light_red': '#fed7d7',
    'gray_dark': '#4a5568',
}

fig, ax = plt.subplots(figsize=(10, 8))
ax.set_xlim(0, 10)
ax.set_ylim(0, 8)
ax.axis('off')

ax.text(5, 7.7, 'Quick Troubleshooting Guide', fontsize=12, fontweight='bold',
        ha='center', color=COLORS['primary'])

# Issue categories
categories = [
    ('No Power', COLORS['light_red'], ['Check battery voltage', 'Check fuse', 'Check power switch']),
    ('No Data', COLORS['light_orange'], ['Check USB connection', 'Check software', 'Restart system']),
    ('Bad MIT', COLORS['light_blue'], ['Check coil connections', 'Reduce TX level', 'Check grounding']),
    ('Bad ERT', COLORS['light_green'], ['Check soil contact', 'Add water/gel', 'Check electrodes']),
]

for i, (title, color, items) in enumerate(categories):
    x = 0.5 + (i % 2) * 5
    y = 5.5 - (i // 2) * 3.5

    # Category box
    ax.add_patch(FancyBboxPatch((x, y), 4, 2.8, boxstyle="round,pad=0.05",
                                facecolor=color, edgecolor='black', lw=1.5))
    ax.text(x + 2, y + 2.5, title, ha='center', va='center', fontsize=11,
            fontweight='bold', color=COLORS['gray_dark'])

    # Items
    for j, item in enumerate(items):
        ax.text(x + 0.3, y + 1.8 - j * 0.5, f'{j+1}. {item}', fontsize=9,
                va='center', color=COLORS['gray_dark'])

# Footer note
ax.add_patch(Rectangle((0.5, 0.3), 9, 0.8, facecolor=COLORS['light_blue'],
                       edgecolor=COLORS['accent'], lw=1.5))
ax.text(5, 0.7, 'If issue persists after basic checks, consult Section 13 detailed procedures',
        ha='center', va='center', fontsize=9, style='italic', color=COLORS['primary'])

plt.tight_layout()
plt.show()
```

## Power Issues {#sec-power-issues}

### Understanding the Power Distribution Architecture

The HIRT system distributes power from a central battery through the Hub to all connected probes via the trunk cable. This architecture creates both advantages (centralized power management, no individual probe batteries) and vulnerabilities (single-point failures can affect the entire system).

**Voltage requirements:** The system operates at 12V nominal, with probes designed to function across a 10.5-14.5V range. Below 10.5V, the analog front-end loses regulation and measurements become unreliable. The 12.0V threshold in the troubleshooting procedures provides margin before this occurs.

**Fuse protection:** A fuse in the power path protects against short circuits that could damage the Hub or create fire hazards. Fuses can also blow from cumulative stress - multiple small overcurrent events that don't individually trip but gradually weaken the fuse element. A marginal fuse may work intermittently, creating confusing symptoms.

**Cable resistance:** Long trunk cables accumulate resistance that causes voltage drop under load. A 20-meter trunk cable with marginal conductor size might deliver only 11V to distant probes when the full system is active, even though the Hub shows 12.5V. This explains why probes at the end of long runs may behave erratically while closer probes work fine.

### Probe Not Responding {#sec-probe-not-responding}

**Symptoms:** No LED indicator, no communication with base hub, probe not detected in diagnostic scan.

**Solutions:**

1. Check cable connections (both ends)
2. Test with multimeter (continuity)
3. Try different port on base hub
4. Swap to spare cable
5. Restart probe (disconnect/reconnect power)
6. Replace with spare probe if available

### Base Hub Not Powering On {#sec-hub-not-powering}

**Symptoms:** No power LED, no response to power switch, system completely dead.

**Causes:** Depleted battery, blown fuse, power switch failure.

**Solutions:**

1. Check battery voltage (should be >12.0 V)
2. Check fuse (replace if blown)
3. Verify power switch operation
4. Check internal connections if accessible
5. Use backup power supply if available

## Communication Issues {#sec-communication-issues}

### Lost Probe Communication {#sec-lost-communication}

**Symptoms:** Probe was working, now unresponsive; intermittent connection; partial data received.

**Solutions:**

1. Check cable connections (both ends)
2. Inspect cable for damage (kinks, cuts)
3. Clean connectors with contact cleaner
4. Swap to known-good cable
5. Check for interference sources nearby
6. Restart probe and base hub

### Sync Problems {#sec-sync-problems}

**Symptoms:** Timing errors in data, inconsistent measurements between probes, data corruption.

**Causes:** Timebase distribution failure, clock drift, cable issues on sync line.

**Solutions:**

1. Verify sync signal at each probe
2. Check sync cable for damage
3. Restart measurement system
4. Re-initialize sync before continuing

## Environmental Factors {#sec-environmental-factors}

### Understanding Environmental Influences

Field instruments operate in conditions far removed from the controlled laboratory environment where they were calibrated. Temperature swings, humidity, precipitation, and electromagnetic interference all affect measurement quality in ways that can be subtle or severe.

**Thermal drift:** Electronic components change their characteristics with temperature. Resistors drift, capacitors change value, and semiconductor junctions shift their operating points. Most critically, the analog signal chain - from coil inductance through amplifier gain to ADC reference voltage - experiences coordinated drift that can masquerade as real subsurface changes. The 15-minute warmup period allows thermal equilibrium to establish within the enclosure, after which drift rates become predictable and slow.

**Moisture ingress:** Water is the enemy of electronics. Even without visible flooding, humidity can condense inside enclosures as temperatures drop, depositing conductive films on circuit boards. The IP67 rating provides protection during normal operation, but repeated seal compression, UV degradation of gaskets, and mechanical damage from handling gradually compromise protection. Regular seal inspection and desiccant replacement prevent insidious moisture damage.

**EMI environment:** The electromagnetic environment varies dramatically between sites. Urban areas near power distribution, active construction sites, and locations near broadcast transmitters present challenges that remote field sites do not. The symptoms often appear as elevated noise floors or periodic interference patterns synchronized with power line frequencies (50/60 Hz and harmonics).

### Temperature Effects {#sec-temperature-effects}

**Symptoms:** Readings drift over time, morning vs. afternoon differences, inconsistent calibration.

**Solutions:**

1. Allow system to stabilize (10-15 min warmup)
2. Note temperature variations in field log
3. Apply temperature compensation if available
4. Take baseline measurements at current temperature
5. Shield equipment from direct sun if possible

### Weather Impacts {#sec-weather-impacts}

**Symptoms:** Data quality degradation, increased noise, contact problems.

**Solutions:**

1. Protect connections from moisture
2. Secure cables against wind movement
3. Use weather covers for sensitive equipment
4. Postpone measurements in severe conditions

## Field Repairs {#sec-field-repairs}

Field equipment inevitably suffers wear and damage. Cables are the most vulnerable component -- they flex during deployment, snag on probe hardware, and accumulate moisture at connector interfaces. Over multiple surveys, the repeated insertion and extraction of M12 connectors wears contact surfaces and compresses O-ring seals, gradually degrading both electrical continuity and environmental protection. A cable that passes bench testing may fail intermittently under the mechanical stress of field use.

Connector degradation follows a predictable pattern: initial performance is excellent, followed by a long period of slow decline, then rapid failure once corrosion or wear reaches a critical threshold. By the time a connector fails visibly, the degradation has been building for several surveys. This is why carrying spare cables and performing proactive connector inspection matters more than reactive repair -- catching a marginal connector before it causes data loss saves far more time than field-splicing a broken cable.

### Field Repair Kit {#sec-repair-kit}

Keep these items handy for field repairs:

- Spare cables (2-3)
- Spare probes (2-4 recommended)
- Electrical tape
- Multimeter
- Small screwdriver set
- Contact cleaner spray
- Zip ties
- Heat-shrink tubing
- Solder and iron (battery powered, optional)
- Notebook and pencil (for notes)
- Calibration sheet

### Emergency Cable Repair {#sec-emergency-cable-repair}

If a cable is damaged in the field:

1. **Locate the break** (continuity test)
2. **Cut out damaged section** if possible
3. **Strip and splice** wires
4. **Insulate with tape** or heat-shrink
5. **Test before use**

::: {.callout-note}
Field-repaired cables should be replaced at first opportunity.
:::

### Connector Cleaning {#sec-connector-cleaning}

1. Apply contact cleaner to connector
2. Wipe with clean cloth
3. Allow to dry before reconnecting
4. Apply thin layer of dielectric grease (optional, for moisture protection)

## When to Abort Survey {#sec-when-to-abort}

The decision to abort a survey is rarely binary. Problems typically escalate through stages, and recognizing the escalation trajectory early allows operators to make informed decisions about whether to continue, adapt, or withdraw. Three categories of trigger warrant different responses.

**Data quality degradation** is the most common escalation path. A single failed probe is routine; two or three warrant attention to whether a systemic cause exists; losing more than 25% of the array fundamentally compromises tomographic resolution and the survey should be paused for diagnosis. Similarly, noise levels that exceed acceptable thresholds on a few channels may indicate localized interference (relocate or shield), but system-wide noise elevation suggests a grounding fault, power issue, or environmental factor that will not resolve without intervention.

**Equipment damage indicators** require immediate assessment. Intermittent connections, unexplained resets, or erratic readings that resist standard troubleshooting may indicate water ingress, thermal damage, or mechanical failure inside sealed enclosures. Continuing to operate damaged equipment risks corrupting data that appears valid but contains systematic errors that are difficult to detect in post-processing.

**Safety triggers** demand immediate response with no deliberation. At UXO-contaminated sites, any conductivity reading exceeding the RED threshold (>5,500 uS/cm; see [Safety: Conductivity Thresholds](../getting-started/safety.qmd#tbl-conductivity-thresholds)) requires immediate cessation of all insertion activities and evacuation to the safe zone. Similarly, any unexpected magnetic anomaly detected during progressive deployment clearance sweeps (see [Safety: HERO Protocols](../getting-started/safety.qmd#sec-hero-analysis)) must be treated as a potential UXO encounter until assessed by EOD professionals.

::: {.callout-warning}
## Conditions Requiring Survey Abort

- **Safety Issues:** Severe weather (lightning, high winds), site hazards discovered, equipment malfunction creating hazard, UXO safety threshold exceeded
- **Data Quality:** >25% probes non-functional, persistent unusable noise, unable to achieve ground contact on majority of probes
- **Critical Failures:** Base hub failure, data logger failure, battery depletion with no backup
- **Practical Issues:** Time constraints preventing quality data, site access revoked
:::

### Before Aborting {#sec-before-aborting}

1. Document all issues in field log
2. Save all data collected (even partial)
3. Note probe positions for potential return
4. Photograph site conditions
5. Extract probes safely if time permits
6. Backup data immediately

### Partial Survey Options {#sec-partial-survey}

If full abort is not necessary, consider these alternatives:

- **Reduce survey area** to functional probes
- **Simplify measurement protocol** (fewer frequencies, fewer patterns)
- **Focus on priority targets** only
- **Document limitations** for data interpretation

## Prevention {#sec-prevention}

### Pre-Field Checks {#sec-pre-field-checks}

- All connectors tight and clean
- Cables tested for continuity
- Calibration up to date
- Spare parts available
- Field diagnostic kit packed
- Batteries charged
- Weather forecast reviewed

### During Survey {#sec-during-survey}

- Monitor data quality in real-time
- Check reciprocity periodically
- Note any anomalies immediately
- Keep spare probes ready
- Protect equipment from weather

### Post-Survey {#sec-ts-post-survey}

- Inspect all equipment
- Note any issues for repair
- Update calibration records
- Clean and store properly
- Recharge all batteries
- Restock field repair kit

::: {.callout-note}
## Related Sections

- For detailed operating procedures, see [Deployment](deployment.qmd)
- For data format specifications, see [Data Formats](../developer/data-formats.qmd)
- For calibration procedures, see [Calibration](../build-guide/calibration.qmd)
- For testing procedures, see [Testing](../build-guide/testing.qmd)
:::

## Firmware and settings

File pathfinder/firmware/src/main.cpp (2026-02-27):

/**
 * Pathfinder Gradiometer Firmware
 *
 * Modular fluxgate gradiometer with GPS logging for archaeological/forensic
 * reconnaissance. Supports 1-4 sensor pairs across handheld, backpack,
 * and drone platforms.
 *
 * Hardware:
 * - Arduino Nano
 * - 1-2x ADS1115 16-bit ADC (I2C addresses 0x48, 0x49)
 * - 2-8 Fluxgate sensors (1-4 pairs: top/bottom)
 * - NEO-6M or ZED-F9P GPS module
 * - SD card module (SPI)
 * - Piezo beeper for pace marking (handheld/backpack only)
 *
 * Data Format:
 * CSV with columns: timestamp,lat,lon,[fix_quality,hdop,altitude,]
 *                   g1_top,g1_bot,g1_grad,...(NUM_SENSOR_PAIRS pairs)
 *
 * Author: Pathfinder Project
 * License: MIT (see LICENSE in project root)
 */

#include <Arduino.h>
#include <Wire.h>
#include <Adafruit_ADS1X15.h>
#include <TinyGPSPlus.h>
#include <SdFat.h>
#include <SoftwareSerial.h>
#include "config.h"

#if ENABLE_WATCHDOG
#include <avr/wdt.h>
#endif

#if ENABLE_RTC
#include <RTClib.h>
#endif

// ============================================================================
// GLOBAL OBJECTS
// ============================================================================

// ADC objects
Adafruit_ADS1115 ads1;  // Address 0x48 - Pairs 1 and 2
#if NEEDS_ADC2
Adafruit_ADS1115 ads2;  // Address 0x49 - Pairs 3 and 4
#endif

// GPS objects
SoftwareSerial gpsSerial(GPS_RX_PIN, GPS_TX_PIN);
TinyGPSPlus gps;

// SD card objects
SdFat sd;
SdFile logFile;

#if ENABLE_RTC
// Real-time clock (DS3231)
RTC_DS3231 rtc;
bool rtcReady = false;
#endif

// ============================================================================
// GLOBAL STATE
// ============================================================================

struct GradiometerReading {
    uint32_t timestamp_ms;
#if ENABLE_RTC
    char timestamp_iso[24];  // "2026-02-18T14:23:45Z" format
#endif
    double latitude;
    double longitude;
    int16_t top[NUM_SENSOR_PAIRS];
    int16_t bot[NUM_SENSOR_PAIRS];
    int16_t grad[NUM_SENSOR_PAIRS];
};

// Timing state
unsigned long lastSampleTime = 0;
unsigned long lastBeepTime = 0;
unsigned long lastBlinkTime = 0;
unsigned long sampleCount = 0;

// Non-blocking beeper state
bool beeping = false;
unsigned long beepStartTime = 0;

// System state
bool sdCardReady = false;
bool gpsLocked = false;
bool ledState = false;
bool adc1Ready = false;
#if NEEDS_ADC2
bool adc2Ready = false;
#endif
char logFileName[16];

// Error tracking
uint16_t sdWriteErrors = 0;
uint16_t adcSaturationCount = 0;

// ============================================================================
// FUNCTION DECLARATIONS
// ============================================================================

void setupPins();
void setupADCs();
void setupGPS();
void setupSD();
#if ENABLE_RTC
void setupRTC();
#endif
void createLogFile();
void writeCSVHeader();
void readGradiometers(GradiometerReading &reading);
void logReading(const GradiometerReading &reading);
void updateBeeper();
void updateStatusLED();
void printDebugInfo(const GradiometerReading &reading);
void checkSaturation(int16_t value);
void reopenLogFile();
bool anyAdcReady();

// ============================================================================
// HELPER
// ============================================================================

bool anyAdcReady() {
    #if NEEDS_ADC2
    return adc1Ready || adc2Ready;
    #else
    return adc1Ready;
    #endif
}

// ============================================================================
// SETUP
// ============================================================================

void setup() {
    #if ENABLE_WATCHDOG
    wdt_disable();
    #endif

    #if SERIAL_DEBUG
    Serial.begin(SERIAL_BAUD);
    while (!Serial && millis() < 3000);
    Serial.println(F("Pathfinder Gradiometer v" FIRMWARE_VERSION " (" FIRMWARE_DATE ")"));
    #ifdef PLATFORM_DRONE
    Serial.println(F("Platform: DRONE"));
    #elif defined(PLATFORM_BACKPACK)
    Serial.println(F("Platform: BACKPACK"));
    #else
    Serial.println(F("Platform: HANDHELD"));
    #endif
    Serial.print(F("Sensor pairs: "));
    Serial.println(NUM_SENSOR_PAIRS);
    #if GPS_LOG_QUALITY
    Serial.println(F("GPS quality logging: ON"));
    #endif
    #endif

    setupPins();
    setupADCs();
    setupGPS();
    setupSD();
    #if ENABLE_RTC
    setupRTC();
    #endif
    createLogFile();

    #if SERIAL_DEBUG
    Serial.println(F("Initialization complete. Starting acquisition..."));
    Serial.print(F("Sample rate: "));
    Serial.print(SAMPLE_RATE_HZ);
    Serial.println(F(" Hz"));
    if (sdCardReady) {
        Serial.print(F("Log file: "));
        Serial.println(logFileName);
    }
    Serial.print(F("ADC1: "));
    Serial.println(adc1Ready ? F("OK") : F("FAILED"));
    #if NEEDS_ADC2
    Serial.print(F("ADC2: "));
    Serial.println(adc2Ready ? F("OK") : F("FAILED"));
    #endif
    #if ENABLE_RTC
    Serial.print(F("RTC: "));
    Serial.println(rtcReady ? F("OK") : F("FAILED"));
    #endif
    #endif

    #if ENABLE_BEEPER
    digitalWrite(BEEPER_PIN, HIGH);
    delay(200);
    digitalWrite(BEEPER_PIN, LOW);
    #endif

    #if ENABLE_WATCHDOG
    wdt_enable(WDTO_4S);
    #endif
}

// ============================================================================
// MAIN LOOP
// ============================================================================

void loop() {
    #if ENABLE_WATCHDOG
    wdt_reset();
    #endif

    unsigned long currentTime = millis();

    // Update GPS data (call frequently to process NMEA sentences)
    while (gpsSerial.available() > 0) {
        gps.encode(gpsSerial.read());
    }

    gpsLocked = gps.location.isValid() && gps.location.age() < 2000;

    // Acquire data at configured sample rate
    unsigned long sampleInterval = 1000 / SAMPLE_RATE_HZ;
    if (currentTime - lastSampleTime >= sampleInterval) {
        lastSampleTime = currentTime;

        GradiometerReading reading;
        readGradiometers(reading);

        if (gpsLocked) {
            reading.latitude = gps.location.lat();
            reading.longitude = gps.location.lng();
        } else {
            reading.latitude = 0.0;
            reading.longitude = 0.0;
        }

        if (sdCardReady) {
            logReading(reading);
            sampleCount++;

            if (sampleCount % SD_FLUSH_INTERVAL == 0) {
                logFile.flush();
            }
        }

        #if SERIAL_DEBUG
        if (sampleCount % DEBUG_PRINT_INTERVAL == 0) {
            printDebugInfo(reading);
        }
        #endif
    }

    #if ENABLE_BEEPER
    updateBeeper();
    #endif

    updateStatusLED();
}

// ============================================================================
// HARDWARE SETUP FUNCTIONS
// ============================================================================

void setupPins() {
    #if ENABLE_BEEPER
    pinMode(BEEPER_PIN, OUTPUT);
    digitalWrite(BEEPER_PIN, LOW);
    #endif
    pinMode(STATUS_LED_PIN, OUTPUT);
    digitalWrite(STATUS_LED_PIN, LOW);

    #if SERIAL_DEBUG
    Serial.println(F("Pins configured"));
    #endif
}

void setupADCs() {
    Wire.begin();

    // ADC1 serves pairs 1-2 (always needed)
    if (ads1.begin(ADS1115_ADDR_1)) {
        ads1.setGain(ADC_GAIN);
        ads1.setDataRate(ADC_DATA_RATE);
        adc1Ready = true;
        #if SERIAL_DEBUG
        Serial.println(F("ADS1115 #1 (0x48) OK"));
        #endif
    } else {
        adc1Ready = false;
        #if SERIAL_DEBUG
        Serial.println(F("WARNING: ADS1115 #1 (0x48) not found"));
        #endif
    }

    // ADC2 serves pairs 3-4 (only needed for 3+ pairs)
    #if NEEDS_ADC2
    if (ads2.begin(ADS1115_ADDR_2)) {
        ads2.setGain(ADC_GAIN);
        ads2.setDataRate(ADC_DATA_RATE);
        adc2Ready = true;
        #if SERIAL_DEBUG
        Serial.println(F("ADS1115 #2 (0x49) OK"));
        #endif
    } else {
        adc2Ready = false;
        #if SERIAL_DEBUG
        Serial.println(F("WARNING: ADS1115 #2 (0x49) not found"));
        #endif
    }
    #endif

    if (!anyAdcReady()) {
        #if SERIAL_DEBUG
        Serial.println(F("ERROR: No ADCs found! GPS/diagnostic mode only."));
        #endif
    }
}

void setupGPS() {
    gpsSerial.begin(GPS_BAUD);

    #if SERIAL_DEBUG
    Serial.print(F("GPS initialized at "));
    Serial.print(GPS_BAUD);
    Serial.println(F(" baud"));
    #endif
}

void setupSD() {
    pinMode(SD_CS_PIN, OUTPUT);

    if (!sd.begin(SD_CS_PIN, SD_SCK_MHZ(4))) {
        #if SERIAL_DEBUG
        Serial.println(F("ERROR: SD card initialization failed!"));
        #endif
        sdCardReady = false;
        return;
    }

    sdCardReady = true;
    #if SERIAL_DEBUG
    Serial.println(F("SD card ready"));
    #endif
}

#if ENABLE_RTC
void setupRTC() {
    if (rtc.begin()) {
        if (rtc.lostPower()) {
            #if SERIAL_DEBUG
            Serial.println(F("WARNING: RTC lost power, time may be invalid"));
            #endif
        }
        rtcReady = true;
        #if SERIAL_DEBUG
        DateTime now = rtc.now();
        Serial.print(F("RTC OK: "));
        char buf[24];
        snprintf(buf, sizeof(buf), "%04d-%02d-%02dT%02d:%02d:%02dZ",
                 now.year(), now.month(), now.day(),
                 now.hour(), now.minute(), now.second());
        Serial.println(buf);
        #endif
    } else {
        rtcReady = false;
        #if SERIAL_DEBUG
        Serial.println(F("WARNING: DS3231 RTC not found, falling back to millis()"));
        #endif
    }
}
#endif

void writeCSVHeader() {
    // Build header dynamically based on NUM_SENSOR_PAIRS and GPS_LOG_QUALITY
    #if ENABLE_RTC
    logFile.print(F("timestamp_utc,lat,lon"));
    #else
    logFile.print(F("timestamp,lat,lon"));
    #endif

    #if GPS_LOG_QUALITY
    logFile.print(F(",fix_quality,hdop,altitude"));
    #endif

    for (uint8_t i = 0; i < NUM_SENSOR_PAIRS; i++) {
        logFile.print(F(",g"));
        logFile.print(i + 1);
        logFile.print(F("_top,g"));
        logFile.print(i + 1);
        logFile.print(F("_bot,g"));
        logFile.print(i + 1);
        logFile.print(F("_grad"));
    }
    logFile.println();
}

void createLogFile() {
    if (!sdCardReady) return;

    for (uint16_t i = 1; i < 10000; i++) {
        snprintf(logFileName, sizeof(logFileName), "%s%04d%s",
                 LOG_FILE_PREFIX, i, LOG_FILE_EXTENSION);

        if (!sd.exists(logFileName)) {
            if (logFile.open(logFileName, O_CREAT | O_WRITE | O_EXCL)) {
                // Firmware version comment
                logFile.print(F("# Pathfinder v" FIRMWARE_VERSION
                                " (" FIRMWARE_DATE ") pairs="));
                logFile.println(NUM_SENSOR_PAIRS);
                // Epoch offset metadata
                #if ENABLE_RTC
                logFile.println(F("# epoch_offset=absolute (ISO 8601 UTC timestamps)"));
                #else
                logFile.println(F("# epoch_offset=0 (relative ms, no RTC)"));
                #endif
                // CSV header
                writeCSVHeader();
                logFile.flush();

                #if SERIAL_DEBUG
                Serial.print(F("Created log file: "));
                Serial.println(logFileName);
                #endif
                return;
            }
        }
    }

    #if SERIAL_DEBUG
    Serial.println(F("ERROR: Could not create log file"));
    #endif
    sdCardReady = false;
}

// ============================================================================
// DATA ACQUISITION FUNCTIONS
// ============================================================================

void checkSaturation(int16_t value) {
    if (value > ADC_SATURATION_THRESHOLD || value < -ADC_SATURATION_THRESHOLD) {
        adcSaturationCount++;
        #if SERIAL_DEBUG
        if (adcSaturationCount % 10 == 1) {
            Serial.print(F("WARNING: ADC saturation (count="));
            Serial.print(adcSaturationCount);
            Serial.println(')');
        }
        #endif
    }
}

void readGradiometers(GradiometerReading &reading) {
    reading.timestamp_ms = millis();

    #if ENABLE_RTC
    if (rtcReady) {
        DateTime now = rtc.now();
        snprintf(reading.timestamp_iso, sizeof(reading.timestamp_iso),
                 "%04d-%02d-%02dT%02d:%02d:%02dZ",
                 now.year(), now.month(), now.day(),
                 now.hour(), now.minute(), now.second());
    } else {
        reading.timestamp_iso[0] = '\0';
    }
    #endif

    for (uint8_t i = 0; i < NUM_SENSOR_PAIRS; i++) {
        // Determine which ADC and whether it's ready
        bool adcOk;
        Adafruit_ADS1115 *adc;

        if (PAIR_ADC[i] == 1) {
            adc = &ads1;
            adcOk = adc1Ready;
        } else {
            #if NEEDS_ADC2
            adc = &ads2;
            adcOk = adc2Ready;
            #else
            adcOk = false;
            adc = &ads1; // unused, but avoids uninitialized warning
            #endif
        }

        if (adcOk) {
            reading.top[i]  = adc->readADC_SingleEnded(PAIR_TOP_CH[i]);
            reading.bot[i]  = adc->readADC_SingleEnded(PAIR_BOT_CH[i]);
            reading.grad[i] = reading.bot[i] - reading.top[i];
            checkSaturation(reading.top[i]);
            checkSaturation(reading.bot[i]);
        } else {
            reading.top[i] = 0;
            reading.bot[i] = 0;
            reading.grad[i] = 0;
        }
    }
}

void reopenLogFile() {
    logFile.close();
    if (logFile.open(logFileName, O_WRITE | O_AT_END)) {
        sdCardReady = true;
        sdWriteErrors = 0;
        #if SERIAL_DEBUG
        Serial.println(F("SD card: file re-opened"));
        #endif
    } else {
        sdCardReady = false;
        #if SERIAL_DEBUG
        Serial.println(F("SD card: re-open failed"));
        #endif
    }
}

void logReading(const GradiometerReading &reading) {
    if (!sdCardReady) return;

    #if ENABLE_RTC
    if (rtcReady && reading.timestamp_iso[0] != '\0') {
        logFile.print(reading.timestamp_iso);
    } else {
        logFile.print(reading.timestamp_ms);
    }
    #else
    logFile.print(reading.timestamp_ms);
    #endif
    logFile.print(',');
    logFile.print(reading.latitude, 7);
    logFile.print(',');
    logFile.print(reading.longitude, 7);

    #if GPS_LOG_QUALITY
    logFile.print(',');
    logFile.print(gps.location.isValid() ? 1 : 0);
    logFile.print(',');
    logFile.print(gps.hdop.isValid() ? gps.hdop.hdop() : 99.9, 1);
    logFile.print(',');
    logFile.print(gps.altitude.isValid() ? gps.altitude.meters() : 0.0, 1);
    #endif

    for (uint8_t i = 0; i < NUM_SENSOR_PAIRS; i++) {
        logFile.print(',');
        logFile.print(reading.top[i]);
        logFile.print(',');
        logFile.print(reading.bot[i]);
        logFile.print(',');
        logFile.print(reading.grad[i]);
    }

    if (!logFile.println()) {
        sdWriteErrors++;
        #if SERIAL_DEBUG
        Serial.print(F("SD write error #"));
        Serial.println(sdWriteErrors);
        #endif
        if (sdWriteErrors >= SD_RETRY_THRESHOLD) {
            reopenLogFile();
        }
    } else {
        if (sdWriteErrors > 0) sdWriteErrors = 0;
    }
}

// ============================================================================
// USER INTERFACE FUNCTIONS
// ============================================================================

void updateBeeper() {
    unsigned long currentTime = millis();

    if (beeping) {
        if (currentTime - beepStartTime >= BEEP_DURATION_MS) {
            digitalWrite(BEEPER_PIN, LOW);
            beeping = false;
        }
        return;
    }

    if (currentTime - lastBeepTime >= BEEP_INTERVAL_MS) {
        lastBeepTime = currentTime;
        beepStartTime = currentTime;
        digitalWrite(BEEPER_PIN, HIGH);
        beeping = true;
    }
}

void updateStatusLED() {
    unsigned long currentTime = millis();
    unsigned long blinkInterval;

    if (!anyAdcReady()) {
        blinkInterval = BLINK_ERROR / 2;
    } else if (!sdCardReady) {
        blinkInterval = BLINK_ERROR;
    } else if (!gpsLocked) {
        blinkInterval = BLINK_NO_GPS;
    } else {
        blinkInterval = BLINK_LOGGING;
    }

    if (currentTime - lastBlinkTime >= blinkInterval) {
        lastBlinkTime = currentTime;
        ledState = !ledState;
        digitalWrite(STATUS_LED_PIN, ledState);
    }
}

void printDebugInfo(const GradiometerReading &reading) {
    #if SERIAL_DEBUG
    Serial.print(F("S:"));
    Serial.print(sampleCount);
    Serial.print(F(" GPS:"));
    if (gpsLocked) {
        Serial.print(reading.latitude, 6);
        Serial.print(',');
        Serial.print(reading.longitude, 6);
    } else {
        Serial.print(F("--"));
    }

    for (uint8_t i = 0; i < NUM_SENSOR_PAIRS; i++) {
        Serial.print(F(" G"));
        Serial.print(i + 1);
        Serial.print(':');
        Serial.print(reading.grad[i]);
    }

    if (sdWriteErrors > 0) {
        Serial.print(F(" SD_ERR:"));
        Serial.print(sdWriteErrors);
    }
    if (adcSaturationCount > 0) {
        Serial.print(F(" SAT:"));
        Serial.print(adcSaturationCount);
    }
    Serial.println();
    #endif
}

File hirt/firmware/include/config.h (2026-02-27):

/**
 * HIRT Firmware - Configuration Header
 *
 * User-configurable parameters for the Hybrid Inductive-Resistivity
 * Tomography system. Modify these values to customize behavior without
 * editing main code.
 *
 * Target MCU: ESP32-WROOM-32
 * Hardware Rev: 2.3
 */

#ifndef CONFIG_H
#define CONFIG_H

// ============================================================================
// FIRMWARE VERSION
// ============================================================================

#ifndef FIRMWARE_VERSION
#define FIRMWARE_VERSION    "0.1.0"
#endif
#ifndef FIRMWARE_DATE
#define FIRMWARE_DATE       "2026-02-18"
#endif

// ============================================================================
// SPI BUS CONFIGURATION (ESP32 default VSPI)
// ============================================================================

#define SPI_MOSI_PIN        23
#define SPI_MISO_PIN        19
#define SPI_SCLK_PIN        18

// ============================================================================
// I2C BUS CONFIGURATION (ESP32 default)
// ============================================================================

#define I2C_SDA_PIN         21
#define I2C_SCL_PIN         22

// ============================================================================
// AD9833 DDS SIGNAL GENERATOR
// ============================================================================
// 3-wire SPI interface. Shares SCLK and SDATA with main SPI bus;
// FSYNC acts as chip select.

#define DDS_FSYNC_PIN       5     // Frame sync (chip select)
#define DDS_SDATA_PIN       SPI_MOSI_PIN  // Serial data (shared MOSI)
#define DDS_SCLK_PIN        SPI_SCLK_PIN  // Serial clock (shared SCLK)
#define DDS_MCLK_HZ        25000000      // Master clock frequency (25 MHz crystal)

// ============================================================================
// AD7124-8 ADC (24-bit Sigma-Delta)
// ============================================================================
// SPI interface on the shared bus. CS is dedicated.

#define ADC_CS_PIN          15    // ADC chip select
#define ADC_DRDY_PIN        4     // Data ready interrupt (optional)
#define ADC_SPI_SPEED       4000000  // 4 MHz SPI clock

// AD7124-8 configuration
#define ADC_VREF_MV         2500.0f  // Internal reference voltage (mV)
#define ADC_RESOLUTION_BITS 24
#define ADC_GAIN            1        // PGA gain setting (1, 2, 4, 8, 16, 32, 64, 128)
#define ADC_DATA_RATE       19200    // Output data rate (Hz) for lock-in sampling

// ============================================================================
// CD4051 ANALOG MULTIPLEXER (TX and RX switching)
// ============================================================================
// Two CD4051s are used: one for TX probe selection, one for RX probe selection.
// Address lines A, B, C select one of 8 channels. INH disables output.
// For >8 probes, multiple mux stages are daisy-chained.

// TX multiplexer
#define MUX_TX_A_PIN        25
#define MUX_TX_B_PIN        26
#define MUX_TX_C_PIN        27
#define MUX_TX_INH_PIN      14    // Inhibit (active high = output disabled)

// RX multiplexer
#define MUX_RX_A_PIN        32
#define MUX_RX_B_PIN        33
#define MUX_RX_C_PIN        34
#define MUX_RX_INH_PIN      35    // Inhibit

// ============================================================================
// ERT RELAY / SWITCH PINS
// ============================================================================
// Controls current injection electrode switching for resistivity measurements.
// Active-low relay drivers.

#define ERT_RELAY_A_PIN     12    // Current injection positive electrode
#define ERT_RELAY_B_PIN     13    // Current injection negative electrode
#define ERT_POLARITY_PIN    2     // Polarity reversal relay

// ============================================================================
// PROBE CONFIGURATION
// ============================================================================

// Number of probes in the array (configurable at compile time)
#ifndef NUM_PROBES
#define NUM_PROBES          24
#endif

// Maximum supported probes (hardware limit of mux stages)
#define MAX_PROBES          32

// Validate at compile time
#if NUM_PROBES < 1 || NUM_PROBES > MAX_PROBES
  #error "NUM_PROBES must be 1-32"
#endif

// ============================================================================
// MIT (Magneto-Inductive Tomography) PARAMETERS
// ============================================================================

// Transmit frequencies (Hz) - swept during MIT acquisition
#define NUM_TX_FREQUENCIES  5
static const uint32_t TX_FREQUENCIES[NUM_TX_FREQUENCIES] = {
    2000, 5000, 10000, 20000, 50000
};

// TX coil current target (mA)
#define TX_CURRENT_MA       10.0f

// TX stabilization time after frequency change (ms)
#define MIT_TX_SETTLE_MS    10
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

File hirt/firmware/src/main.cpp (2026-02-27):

/**
 * HIRT Firmware - Hybrid Inductive-Resistivity Tomography
 *
 * ESP32-WROOM-32 based controller for dual-channel subsurface imaging.
 * Modules: DDS, ADC, Lock-in DSP, Multiplexer, ERT Sequencer
 *
 * Status: SCAFFOLD - Structure and interfaces defined, implementation TODO
 */

#include <Arduino.h>
#include <Wire.h>
#include <SPI.h>
#include <SD.h>
#include "config.h"

// ============================================================================
// MODULE: DDS Signal Generator (AD9833)
// ============================================================================

void dds_init();
void dds_set_frequency(uint32_t freq_hz);
void dds_enable();
void dds_disable();

// ============================================================================
// MODULE: ADC (AD7124-8)
// ============================================================================

void adc_init();
int32_t adc_read_channel(uint8_t channel);
float adc_to_voltage(int32_t raw);

// ============================================================================
// MODULE: Lock-in Amplifier (Digital Signal Processing)
// ============================================================================

struct LockInResult {
    float amplitude;
    float phase_deg;
};

void lockin_init(uint32_t reference_freq_hz);
LockInResult lockin_measure(uint8_t rx_channel, uint32_t num_cycles);

// ============================================================================
// MODULE: Multiplexer Control (CD4051)
// ============================================================================

void mux_init();
void mux_select_tx(uint8_t probe_index);
void mux_select_rx(uint8_t probe_index);

// ============================================================================
// MODULE: ERT Sequencer
// ============================================================================

struct ERTReading {
    uint8_t a, b, m, n;  // Electrode indices (current A-B, potential M-N)
    float voltage_mv;
    float current_ma;
    float apparent_resistivity;
};

void ert_init();
ERTReading ert_measure(uint8_t a, uint8_t b, uint8_t m, uint8_t n);
void ert_run_sequence(const uint8_t* sequence, uint16_t num_measurements);

// ============================================================================
// MODULE: Data Logger
// ============================================================================

void logger_init();
void logger_write_mit_header();
void logger_write_ert_header();
void logger_write_mit_reading(uint8_t tx, uint8_t rx, uint32_t freq_hz,
                               const LockInResult& result);
void logger_write_ert_reading(const ERTReading& reading);

// ============================================================================
// STATE MACHINE
// ============================================================================

enum SystemState {
    STATE_INIT,
    STATE_IDLE,
    STATE_MIT_ACQUIRE,
    STATE_ERT_ACQUIRE,
    STATE_ERROR
};

SystemState currentState = STATE_INIT;

// ============================================================================
// SETUP
// ============================================================================

void setup() {
    Serial.begin(115200);
    Serial.println("HIRT Firmware v" FIRMWARE_VERSION " (" FIRMWARE_DATE ")");
    Serial.println("Status: SCAFFOLD - Module interfaces defined");

    // Initialize all modules
    // TODO: Implement each module
    dds_init();
    adc_init();
    lockin_init(10000); // Default 10 kHz
    mux_init();
    ert_init();
    logger_init();

    currentState = STATE_IDLE;
    Serial.println("Initialization complete (scaffold mode)");
}

// ============================================================================
// MAIN LOOP
// ============================================================================

void loop() {
    switch (currentState) {
        case STATE_IDLE:
            // TODO: Check for commands (serial, MQTT)
            // TODO: Implement measurement trigger
            break;

        case STATE_MIT_ACQUIRE:
            // TODO: MIT measurement cycle
            // For each TX probe:
            //   mux_select_tx(tx_probe)
            //   dds_set_frequency(freq)
            //   dds_enable()
            //   For each RX probe:
            //     mux_select_rx(rx_probe)
            //     result = lockin_measure(rx_channel, num_cycles)
            //     logger_write_mit_reading(tx, rx, freq, result)
            //   dds_disable()
            break;

        case STATE_ERT_ACQUIRE:
            // TODO: ERT measurement sequence
            // For each quadrupole (A, B, M, N):
            //   reading = ert_measure(a, b, m, n)
            //   logger_write_ert_reading(reading)
            break;

        case STATE_ERROR:
            // TODO: Error recovery
            break;

        default:
            break;
    }
}

// ============================================================================
// MODULE IMPLEMENTATIONS (STUBS)
// ============================================================================

void dds_init() {
    // TODO: Initialize AD9833 via SPI
    // - Configure SPI bus (DDS_FSYNC_PIN as CS)
    // - Reset AD9833
    // - Set default frequency register
    // - Output disabled until dds_enable() called
    Serial.println("  DDS: stub initialized");
}

void dds_set_frequency(uint32_t freq_hz) {
    // TODO: Program AD9833 frequency register
    // freq_word = (freq_hz * 2^28) / DDS_MCLK_HZ
    // Write 14-bit MSB and LSB to FREQ0 register
}

void dds_enable() { /* TODO: Set AD9833 output enable */ }
void dds_disable() { /* TODO: Set AD9833 to reset/sleep */ }

void adc_init() {
    // TODO: Initialize AD7124-8 via SPI
    // - Configure SPI bus (ADC_CS_PIN as CS)
    // - Reset AD7124-8
    // - Set reference source (internal 2.5V)
    // - Configure gain (ADC_GAIN)
    // - Set data rate (ADC_DATA_RATE)
    // - Configure channel map for lock-in sampling
    Serial.println("  ADC: stub initialized");
}

int32_t adc_read_channel(uint8_t channel) {
    // TODO: Configure and read AD7124-8
    // - Select channel
    // - Start single conversion
    // - Wait for DRDY or poll status register
    // - Read 24-bit result
    return 0;
}

float adc_to_voltage(int32_t raw) {
    // TODO: Convert raw ADC to voltage
    // voltage = (raw / 2^23) * (ADC_VREF_MV / ADC_GAIN)
    return 0.0f;
}

void lockin_init(uint32_t reference_freq_hz) {
    // TODO: Configure lock-in amplifier DSP parameters
    // - Store reference frequency
    // - Pre-compute sin/cos lookup table for reference
    // - Configure integration window (LOCKIN_NUM_CYCLES)
    Serial.println("  Lock-in: stub initialized");
}
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

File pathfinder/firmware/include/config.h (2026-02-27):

/**
 * Pathfinder Gradiometer - Configuration Header
 *
 * User-configurable parameters for the fluxgate gradiometer.
 * Modify these values to customize system behavior without editing main code.
 *
 * License: MIT (see LICENSE in project root)
 */

#ifndef CONFIG_H
#define CONFIG_H

// ============================================================================
// FIRMWARE VERSION
// ============================================================================

#define FIRMWARE_VERSION    "1.4.0"
#define FIRMWARE_DATE       "2026-02-18"

// ============================================================================
// PLATFORM SELECTION
// ============================================================================
// Uncomment ONE platform define, or set via build_flags in platformio.ini.
// Defaults to handheld if none specified.

#ifndef PLATFORM_HANDHELD
#ifndef PLATFORM_BACKPACK
#ifndef PLATFORM_DRONE
#define PLATFORM_HANDHELD   1
#endif
#endif
#endif

// ============================================================================
// SENSOR PAIR COUNT
// ============================================================================
// Number of gradiometer pairs (1-4). Each pair = 2 sensors (top + bottom).
//   1 pair  = 2 sensors, 1x ADS1115 (channels 0-1)
//   2 pairs = 4 sensors, 1x ADS1115 (channels 0-3)
//   3 pairs = 6 sensors, 2x ADS1115
//   4 pairs = 8 sensors, 2x ADS1115 (full)
//
// Platform defaults:
//   Handheld: 4 pairs (1.5m swath)
//   Backpack: 4 pairs
//   Drone:    2 pairs (weight limited)
#ifndef NUM_SENSOR_PAIRS
  #ifdef PLATFORM_DRONE
    #define NUM_SENSOR_PAIRS  2
  #else
    #define NUM_SENSOR_PAIRS  4
  #endif
#endif

// Validate at compile time
#if NUM_SENSOR_PAIRS < 1 || NUM_SENSOR_PAIRS > 4
  #error "NUM_SENSOR_PAIRS must be 1-4"
#endif

// Derived: does this configuration need the second ADS1115?
#define NEEDS_ADC2  (NUM_SENSOR_PAIRS > 2)

// ============================================================================
// PLATFORM-DERIVED DEFAULTS
// ============================================================================

#ifdef PLATFORM_DRONE
  #ifndef ENABLE_BEEPER
  #define ENABLE_BEEPER       0
  #endif
  #ifndef SAMPLE_RATE_HZ
  #define SAMPLE_RATE_HZ      20
  #endif
  #ifndef GPS_LOG_QUALITY
  #define GPS_LOG_QUALITY     1
  #endif
#endif

// Beeper enabled by default on handheld/backpack
#ifndef ENABLE_BEEPER
#define ENABLE_BEEPER         1
#endif

// Log GPS fix quality and HDOP (recommended for RTK, optional otherwise)
#ifndef GPS_LOG_QUALITY
#define GPS_LOG_QUALITY       0
#endif

// ============================================================================
// WATCHDOG TIMER (opt-in)
// ============================================================================
// Set to 1 to enable hardware watchdog (4-second timeout).
// WARNING: Some Arduino Nano bootloaders do not handle watchdog resets
// correctly, causing a boot loop. Test with your specific board first.
#ifndef ENABLE_WATCHDOG
#define ENABLE_WATCHDOG     0
#endif
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

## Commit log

2025-11-15 Implement initial project structure and setup
    [ert_ring_collar.scad, probe_head.scad, probe_head_dummy.scad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]
2025-11-19 Refactor: Modular 16mm Flush Connector System
    - Increased rod OD from 12mm to 16mm for robust threads
    - Switched to modular 'stacking' assembly (inserts epoxied into rod ends)
    - Replaced 12mm micro-probe SCAD files with parametric flush connector modules
    - Updated BOM and Assembly Guide
    - Cleaned up deprecated 12mm files
    - Added detailed ASCII stack diagram
    - Added base hub breakout and micro-probe design docs
    [modular_female_sensor.stl, modular_flush_connector.scad, modular_male_insert.stl]
2025-11-19 Cleanup: Remove deprecated 12mm micro-probe CAD files
    [base-hub-order-sheet.csv, ert_ring_collar.scad, probe-order-sheet.csv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]
2025-11-19 CAD: Update to 4x print arrays with breakaway tabs
    [modular_female_sensor.stl, modular_flush_connector.scad, modular_male_insert.stl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]
2025-11-19 CAD: Fix STL separation and add stability bridges for print arrays
    [modular_flush_connector.scad, modular_male_insert_4x.stl]
2025-11-19 CAD: Resize to M12 for robust thread cutting (Male 12.2mm, Female 10.5mm)
    [modular_female_sensor_4x.stl, modular_flush_connector.scad, modular_male_insert_4x.stl]
2025-11-19 CAD: Add mixed array (2x Male + 2x Female) for balanced printing
    [modular_flush_connector.scad, modular_mixed_array_4x.stl]
2025-11-19 CAD: Add 'Super Brim' and rigid scaffolding to prevent print failure
    [modular_flush_connector.scad, modular_mixed_array_4x.stl]
2025-11-19 Docs: Mandate 100% infill for structural connectors and add Threading Tools to BOM
2025-11-19 CAD: Deepen female thread to 25mm to prevent tap bottoming out
    [modular_flush_connector.scad, modular_mixed_array_4x.stl]
2025-11-19 CAD: Modify stability scaffolding to avoid intersecting center wire channel
    [modular_flush_connector.scad, modular_mixed_array_4x.stl]
2025-11-22 CAD: Switch to fully printed M12 ISO threads per user request
    [modular_flush_connector.scad, modular_mixed_array_4x.stl]
2025-11-22 CAD: Finalize M12 printed threads and fix scaffolding intersection with wire channel
    [modular_flush_connector.scad]
2025-11-22 CAD: Finalize thread profile with robust trapezoidal 'Chunky' threads for better printability
    [modular_flush_connector.scad]
2025-11-22 CAD: Lower male scaffolding to Z=21mm (flange) to avoid thread intersection
    [modular_flush_connector.scad]
2025-11-22 CAD: Implement robust polyhedron thread geometry compatible with Bambu Studio
    [modular_flush_connector.scad]
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2025-11-22 CAD: Balance thread profile to 50/50 ratio to ensure female threads have substantial thickness
    [modular_flush_connector.scad]
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2025-11-23 CAD: Add 'Blanks' printing mode (smooth cylinders) for Tap/Die threading to solve FDM resolution issues
    [modular_flush_connector.scad, modular_mixed_array_4x_BLANKS.stl]
2025-11-23 CAD: Update Blanks design for 'Easy-Tap' (11.8mm Male / 10.6mm Female) to prevent breakage during tapping
2026-01-19 Docs: Major whitepaper reorganization v2.0 + research consolidation
    Whitepaper Changes:
    - Reorganized 19 sections into 4 logical parts (Foundations, Building,
    Field Operations, Reference)
    - Added comprehensive index (00-index.md) with reader paths
    - Updated main.md to reference new section structure
    - Enhanced calibration and troubleshooting sections
    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
    [micro_ert_ring_collar.stl, micro_probe_head.3mf, micro_probe_head.stl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]
2026-01-26 Docs: Archive legacy documentation, adopt Quarto whitepaper as primary
    Major documentation reorganization:
    - Archive deprecated pdf-generator/ and whitepaper/ to docs/_archive/
    - Add new Quarto-based hirt-whitepaper/ as primary technical documentation
    - Update README.md and docs/README.md to reflect new structure
    - Clean up ~570MB of venvs and build outputs before archiving
    The Quarto whitepaper provides:
    - Single-source PDF and HTML generation
    - Embedded Python diagram generation
    - Native cross-references and navigation
    - 20 complete sections covering all aspects of HIRT
    Also includes:
    - Updated .gitignore (prevent .deb commits, allow root PDFs)
    - Base hub circuit schematic improvements
    -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
2026-01-30 Docs: Implement multi-model consensus review fixes for whitepaper
    Wave 1-2 (Critical + Buildability):
    - Fix Section 19 placement mismatch between _quarto.yml and 00-index.qmd
    - Resolve duplicate figure labels (probe-cross-section, system-block, assembly-sequence)
    - Standardize electronics: AD9833 DDS, ADS1256 ADC, CD74HC4067 MUX
    - Add ERT compliance voltage table with load specifications
    - Fix cost table typo (hub costs were reversed)
    - Reconcile soil disturbance claims with explicit math (6-7x reduction)
    - Add firmware status documentation and ESP32 platform details
    - Clarify ERT ring-pair sequential measurement approach
    - Add geometric factor K derivation for crosshole electrodes
    Wave 3-4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
    [male_rod_cap_4x.stl, male_rod_cap_threads_test.stl, modular_flush_connector.scad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]
2026-02-01 Docs: Major restructure from whitepaper to Technical Manual (v3.0)
    Complete documentation rewrite following onion model architecture:
    - Getting Started -> Field Guide -> Build Guide -> Theory -> Developer -> Appendices
    New content:
    - progressive-deployment.qmd: Four-phase deployment workflow with UXO protocols
    - sensor-modalities.qmd: Sensor maturity framework (Supported/Recommended/Future)
    - validation.qmd: HardwareX compliance validation procedures
    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
2026-02-01 Docs: Complete remaining plan tasks - diagrams, qualifications, hybrid troubleshooting
    Task 7 - Troubleshooting hybrid rewrite:
    - Added narrative context sections explaining "why" issues occur
    - Understanding MIT Signal Path Issues (dynamic range, cable effects, ground loops)
    - Understanding ERT Contact and Current Flow (contact resistance, polarization)
    - Understanding Power Distribution Architecture (voltage requirements, fuses)
    - Understanding Environmental Influences (thermal drift, moisture, EMI)
    - Updated cross-references to new documentation structure
    Task 8 - Performance claim qualifications:
    - Added (modeled) qualifier to 2-5x resolution claims
    - Added (estimated) to cost figures a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
2026-02-02 Add complete initial design: electronics, sensors, frame, firmware
    Electronics (hardware/schematics/main-board.md):
    - Arduino Nano + 2x ADS1115 ADC architecture
    - Pin mapping and I2C address assignments
    - Power budget calculation (~305mA typical)
    - Sensor cable pinout specification
    Sensor Selection (research/sensor-selection.md):
    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
    [example_data.csv]
2026-02-04 Make Pathfinder self-sufficient for independent Claude sessions
    - Replace CLAUDE.md with complete standalone version
    - Remove "Follow HIRT conventions" dependency
    - Add RIPER workflow and memory bank instructions
    - Add complete writing style guide with performance claims framework
    - Create .claude/project-info.md with full project information
    - Add technology stack, commands, and directory structure
2026-02-11 Repo cleanup: remove build artifacts from tracking, update project docs
    Remove ~103 build artifacts (HTML output, Jupyter caches, site libs) from
    git tracking via .gitignore updates. Rewrite README for current Technical
    Manual structure, update research backlog with accurate file references,
    and refresh STATUS.md and OUTLINE.md for Phase 2 readiness.
    [modular_flush_connector.scad]
2026-02-12 Docs: Phase B quality pass -- research integration, 564 qualification labels, bentonite fix
    - Integrated 7 research documents into manual sections (deployment methods,
    UXO safety, autonomous deployment roadmap)
    - Reviewed and closed 7 additional research documents as no-integration-needed
    - Added (Measured)/(Modeled)/(Target)/(Manufacturer spec) labels to ~564
    numeric claims across 19 .qmd files
    - Critical fix: replaced prohibited bentonite slurry with polymer drilling
    fluid (xanthan gum) in deployment.qmd
    - Added borehole creation methods table, push force data, UXO standoff
    distances, abort criteria, and pre-push assessment checklist
    - New diagrams: sensor maturity framework, tilt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
2026-02-12 Phases 1-6: docs fixes, firmware robustness, BOM, tooling, tests, modular platform support
    Phase 1 - Fix critical documentation bugs:
    - Correct pin mapping in main-board.md to match config.h (D2=LED, D9=beeper, D10=SD_CS, D11-13=hardware SPI)
    - Reconcile power consumption figures with (Modeled) qualifiers across all docs
    - Add dual LICENSE (CERN-OHL-S v2 hardware, MIT software)
    - Add root .gitignore
    Phase 2 - Firmware robustness:
    - Replace ADS1115 infinite error loops with graceful degradation flags
    - Replace blocking delay() beeper with non-blocking state machine
    - Add SD card write error checking with automatic file re-open
    - Add ADC saturation detection
    - Add opt-in watchdog timer
    - Add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
    [pathfinder-bom.csv, pathfinder_frame.scad]
2026-02-12 Docs: Phase C deep theory pass -- HERO physics, signal chain, 3 new diagrams
    - Added electromagnetic interaction with ordnance section to physics.qmd:
    eddy current induction in metallic shells, TX coil field strength decay,
    frequency-dependent ordnance coupling analysis
    - Modernized signal chain references in architecture.qmd: AD8421, OPA2186,
    AD7124-8, CD74HC4067 component callouts in hub and signal flow sections
    - Expanded illumination angle visual placeholder into working matplotlib
    diagram (surface vs crosshole ray paths with polar coverage plots)
    - Created uncertainty.py diagram module with two new visualizations:
    non-uniqueness problem (4 models, same tomogram) and resolution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
2026-02-12 Fix matplotlib backend override that prevented diagram rendering in Quarto
    All 15 diagram modules called matplotlib.use('Agg') unconditionally, which
    overrode Jupyter's inline backend during Quarto renders. This caused all
    97 figures to silently produce no output. The fix conditionally sets Agg
    only when not running inside IPython/Jupyter.
    Also fixes duplicate sec-probe-overview ID in assembly.qmd, updates
    .gitignore for intermediate Quarto files, and regenerates freeze cache
    with all figures now properly captured.
2026-02-12 Implement GeoSim Phase 1a+1b: physics engine + Pathfinder model
    Core physics engine with magnetic dipole forward model, Pathfinder
    gradiometer instrument simulation, and end-to-end survey pipeline
    that produces CSV output compatible with Pathfinder's visualize_data.py.
    - magnetics/dipole.py: Analytical dipole field B(r), superposition,
    gradient calculation, moment estimation, detection depth
    - scenarios/loader.py: JSON scenario loading with auto-induced moments
    - sensors/pathfinder.py: 4-pair gradiometer model, walk path generators
    (straight + zigzag), survey simulation, firmware-format CSV export
    - noise/models.py: Sensor noise (white+1/f), diurnal drift, heading error
    - server.py: Zer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
2026-02-13 Add Phase 2: HIRT EM/resistivity modules, test coverage, and Godot ZMQ connection
    Part 1 — Test coverage gaps filled:
    - test_noise_models.py: 40 tests for SensorNoise, DiurnalDrift, HeadingError, NoiseModel
    - test_scenario_survey.py: 38 tests for run_scenario_survey + all 5 scenarios
    - test_end_to_end.py: 8 tests for full pipeline (scenario → survey → CSV → anomaly detection)
    Part 2 — Godot real-physics connection:
    - Rewrote physics_client.gd with ZMQ support, is_busy() guard, mock fallback
    - Created main.gd for startup orchestration
    - Updated hud.gd with LIVE/OFFLINE connection status indicator
    - Created tools/test_godot_integration.sh
    Part 3 — Phase 2 HIRT EM + Resistivity:
    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
2026-02-13 Fix SimPEG/pyGIMLi backends and add pandas to dev deps
    - SimPEG: use sigmaMap=IdentityMap and pass thicknesses to
    Simulation1DLayered constructor (API requires explicit mapping)
    - pyGIMLi: enlarge mesh domain with electrode refinement to avoid
    boundary effects; use ert.simulate() and read rhoa from result
    - Add pandas to dev dependencies (10 tests were skipping)
    252 tests pass, 0 skipped, 0 failures.
2026-02-13 Add HIRT borehole survey pipeline (FDEM + ERT)
    Implement geosim/sensors/hirt.py with the full HIRT measurement chain:
    probe coordinate transforms, FDEM/ERT measurement generation,
    forward simulation with noise, CSV export, and run_hirt_survey()
    entry point. Adds hirt_fdem_noise_model() factory and 37 new tests
    covering all pipeline functions with zero regressions (289 total pass).
2026-02-13 Add Godot survey simulation platform (11-phase expansion)
    Transform proof-of-concept into full survey simulation with state machine,
    multi-instrument support, drone/borehole modes, training system, and data
    export. Adds 17 new GDScript files, expands 5 existing ones, and includes
    6 new educational notebooks.
    New systems: SurveyManager state machine (8 states), DataRecorder with
    CSV/XYZ export, CoordUtil transforms, scenario selection UI, survey
    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
2026-02-14 Fix drone mode: visibility, camera, audio, model, and HUD toggle legend
    Hide ground operator when drone is active, default drone to third-person
    chase camera with procedural quadcopter mesh and spinning rotors, guard
    AudioManager against missing walk_speed on drone, skip footsteps in drone
    mode, and replace individual VCO/Targets indicators with a unified toggle
    legend that live-updates per operator mode.
2026-02-14 Fix drone input: enable unhandled_input processing in _set_gameplay_active
    _set_gameplay_active() enabled process and physics_process for the drone
    but never called set_process_unhandled_input(), so the drone could not
    receive key presses (E=autopilot, C=camera, mouse yaw, etc.).
2026-02-14 Fix drone raycast self-hit and audio nil assignment
    Two bugs found via automated headless flight test:
    1. Drone altitude raycast was hitting its own CollisionShape3D
    (agl=0.02 instead of ~5.0), so altitude hold kept pushing
    upward thinking it was at ground level. Fixed by excluding
    self via ray_params.exclude = [get_rid()].
    2. AudioManager wind speed code assigned null to typed float
    variable when drone lacked walk_speed property — the typed
    assignment errored before the null check could run. Fixed
    by using untyped Variant intermediaries.
2026-02-14 Add remaining 11-phase expansion: physics, Godot scripts, shaders, tests
    Physics engine:
    - Remanent magnetization support in dipole model
    - Motion-dependent noise model (speed, vibration, heading)
    - Scenario loader auto-computes induced moments from susceptibility
    - Pathfinder sensor model enhancements
    - ZMQ server: EM response and scenario info commands
    Godot frontend:
    - godot-zmq addon binaries (Linux, macOS, Windows)
    - Full operator controller with line guidance, XTE, multi-instrument
    - Data recorder with CSV/XYZ export
    - Heatmap overlay with real-time shader grid
    - Terrain generator with heightmap noise and ground shader
    - Vegetation placer (trees, bushes, rocks)
    - Grass system with win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
    [plugin.cfg]
2026-02-18 Add multi-sensor architecture research and update documentation
    Capture extensive research from Pathfinder redesign discussions:
    - 11 research files covering FG-3+ specs, LM2917 analysis, EMI coil design,
    interference matrix, sensor components, power supply, crossbar layout,
    TDM firmware, sensor pod, I2C address map, and updated BOM
    - Update CLAUDE.md, project-info.md, design-concept.md, noise-analysis.md
    with ESP32 migration, multi-sensor architecture, TDM concept, and
    updated cost estimates ($1,052-1,262)
2026-02-18 Add sensor pod integration research and update documentation
    - Add sensor-pod-integration.md: M8 connector interface, PCA9615 I2C buffer,
    probe GPS verification workflow, ADXL345 vs BNO055 role separation
    - Update CLAUDE.md and project-info.md with sensor pod integration details
    and Pathfinder surface data as inversion boundary condition concept
2026-02-18 Add joint inversion research, data rates analysis, and update docs
    - Add joint-inversion-concept.md: surface data as boundary conditions for
    HIRT 3D inversion, cross-gradient regularization, SimPEG implementation
    - Add data-rates-analysis.md: ~1.6 GB/hr, 180M+ data points, storage planning
    - Add fiber-vs-wifi-analysis.md: WiFi sufficient with TDM (<0.01 nT)
    - Update CLAUDE.md with EMI/FDEM modeling, joint inversion, fiber research
    - Update streaming-architecture.md with TDM timing, updated sensors/rates,
    fiber optic section, EMI conductivity data flow
2026-02-18 Add consensus-validated research and update docs with critical corrections
    15 consensus reports from multi-model validation (GPT-5.2, GPT-5.2-Pro, Grok 4.1 Fast):
    - R1-R6: fiber-vs-wifi, TDM firmware, EMI coil spec, sensor pod PCB, power supply, LiDAR/camera
    - I1-I10: ESP32 migration, TDM state machine, sensor pod firmware, MQTT, EMI signal chain,
    HIRT pod, sensor pod prototype, EMI coil prototype, PCB redesign, integration testing
    Key corrections applied to design-concept.md and noise-analysis.md:
    - LM78L05 replaced by AP2112K-5.0 (1.7V dropout incompatible with 5.5V rail)
    - ADS1115 timing corrected (ALERT/RDY interrupt mode, not "DMA over I2C")
    - WiFi interference revised to 0.01-0.1 nT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
2026-02-18 Add sensor pod consensus validation report (I6)
    Multi-model consensus on HIRT sensor pod integration: GPS probe position
    recording, M8 connector, PCA9615 bus buffer, firmware auto-detection.
2026-02-27 Add shared/ directory with cross-instrument components
    Extracts shared architecture into dedicated shared/ directory:
    - firmware/: Sensor pod driver stubs, MQTT config, SD logger
    - protocols/: MQTT topic hierarchy, CSV column schemas
    - hardware/: Sensor pod spec + BOM, M8 8-pin connector pinout
    - edge/: Docker Compose for Jetson, Mosquitto broker config
    - workflow/: Pathfinder → HIRT field handoff procedure
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2026-02-27 Add uncommitted content from all three original repositories
    Copies all modified and untracked files that were in the working trees
    of the original repos but not yet committed at the time of subtree merge.
    Pathfinder (13 files):
    - Modified: firmware config, platformio.ini, main.cpp, platform-variants.md
    - New: build-guide, field-guide, safety, contributing docs; 3 test suites; CI workflow
    HIRT (10 files):
    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
    [bomb-crater-heterogeneous.obj]
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2026-02-28 Fix branding: TERRASCRY is the product, geosim is an internal engine
    - Docstrings: "wraps GeoSim" → "TERRASCRY survey simulation"
    - Scenarios router: "GeoSim scenario files" → "TERRASCRY scenario files"
    - CI: "Install GeoSim" → "Install physics engine"
    - Issue templates: "GeoSim Integration" → "Physics Engine" in component dropdowns
    - Label renamed: component:geosim-integration → component:physics-engine
    - Milestones 2,3: descriptions updated to remove GeoSim branding
    - Issue #36 body updated
    Import paths (from geosim.*) and file paths (geosim/) unchanged — those
    reference the internal package name, not the product brand.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
2026-02-28 Add 2D heatmap view with deck.gl, survey track overlay, and color scale
    Installs deck.gl with OrthographicView for local-meter coordinate rendering.
    Creates BitmapLayer-based heatmap from grid data with CPU-side RGBA generation
    (consensus-validated: avoids HeatmapLayer KDE anti-pattern for pre-gridded data).
    Includes viridis/plasma/inferno colormaps, Y-axis flip handling, and auto-fit
    viewport. PathLayer renders survey track as white overlay. ColorScaleControl
    provides palette selector and min/max range inputs. Color scale state lives in
    dedicated Zustand store for cross-view sharing.
    Closes #26, closes #27, closes #28, closes #29.
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2026-02-28 Add Phase 2 Wave 2: dataset history, sim params, import, tooltips, and more
    Implements 14 issues across 4 epics (UI Completeness, Performance & Polish,
    Data Import, Advanced Viz):
    - DatasetHistory sidebar with virtual scrolling (#51, #70)
    - Simulation parameter sliders for line/sample spacing and resolution (#52)
    - Export download button with CSV/Grid CSV/ESRI ASC formats (#54)
    - Hover tooltips on 2D heatmap showing X/Y/nT values (#53)
    - ErrorBoundary + LoadingSkeleton with React.lazy for views (#68, #72)
    - Keyboard shortcuts for view modes and sidebar toggle (#55)
    - Production build vendor chunk splitting (#71)
    - ImportValidator service with CSV validation (#60, #64)
    - File upload endpoint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
    [invalid_bad_values.csv, invalid_missing_cols.csv, valid_grid.csv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]
2026-02-28 Switch frontend from dark zinc theme to light theme for better data visibility
    Convert all 19 frontend files from dark zinc backgrounds to light theme,
    update deck.gl clearColor and tooltip styles, fix stream scenario dropdown
    to use file_name slugs, and wire up useAnomalies hook in MapView/SceneView.
2026-03-01 Fix review findings: performance, dead code, and quality issues
    - Revert frameloop="always" to "demand" in SceneView (avoids continuous GPU rendering)
    - Remove AnimatePresence from SplitWorkspace (avoids destroying/remounting WebGL contexts)
    - Guard contour generation behind showContours flag in MapView (skip d3 computation when off)
    - Gate onHover setState behind csIsDrawing ref (avoid re-renders on every mouse move)
    - Lazy-mount CommandPalette internals (hooks only run when palette is open)
    - Fix CommandPalette import command: add data-import-trigger to ImportDialog button
    - Use COLORMAPS keys instead of hardcoded colormap list in CommandPalette
    - Hoist THREE.Vector3 constants in SceneAnno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
